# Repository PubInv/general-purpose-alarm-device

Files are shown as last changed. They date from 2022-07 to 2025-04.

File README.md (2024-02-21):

# General Purpose Alarm Device v2.0
We often acronymize this as  "GPAD" (prounced gee-pad).

DOI: [https://zenodo.org/records/10065096](https://zenodo.org/records/10065096)

## Abstract 
The General Purpose Alarm Device (GPAD) shines lights and makes loud noises to draw attention to a problem. It has a programmable 80 character display to provide textual info. A mute button toggles the sound on and off. Fundamentally, it is designed to act as a peripheral to a controlling computer or microcontroller. The controller may communicate over a USB (COM) connection or through a 5V SPI connection via an RJ12 cable. The GPAD is intended to be as general as possible, so that it can be used as an alarm for many engineering, scientific, and hobby machines or instruments. The device's original goal was to provide medical alarm capability to the PolyVent [5]open-source mechanical medical ventilator. The GPAD supports 5 alarm levels above “silent” of increasing urgency in terms of light, rhythm, and frequency. It is based on the Arduino Uno Atmega328 design and may similarly become extensible through headers and shields. It includes a printed wiring assembly, firmware for the GPAD peripheral, a simple documented API, and a 3D printable enclosure. The repo includes instructions for using a second GPAD as a controller.

The GPAD does not detect the conditions that need to be alarmed. It is a peripheral to a controlling host device, probably another microcontroller.
The controlling host will assert status through the GPAD to an end user.

## Demonstration Video
A demonstration of one use of the GPAD can be [seen here](https://youtu.be/F5cf5-Cmwu0).

# The Colaborative Open Development

Development of the GPAD is in collaboration with the [Sustainable Progress and Equality Collective
(SPEC)](https://www.specollective.org/#:~:text=The%20Sustainable%20Progress%20and%20Equality,be%20catalysts%20for%20positive%20change.) and other individual volunteers.

The GPAD is Certified Open Source Hardware by OSHWA. Our OSHWA UID is [US002352](https://certification.oshwa.org/us002352.html).

GPAD_OSHWA

GPAD in an Enclosure of Summer 2022
https://user-images.githubusercontent.com/5296671/203407648-e5b4894c-6909-4530-9af4-f5937bfeb0b8.JPG

KiCad Simulated GPAD Printed Circuit Assembly (Version 2)

**Top View**

**Bottom View.** 

The top view image shows some Artuino UNO connectors peeking out, but on the bottom view the connectors are not actually used.  The GPAD was designed so that it MIGHT become a shield to an UNO, but it can stand alone.

# Versions History
During the summer of 2022, Version 1 of the GPAD PCB was designed and several units were fabricated.
Some of these units were used as electrical engineering senior capstone projects of students at the
University of Oklahoma, located in Nornam Oklahoma, during the spring semester.
Two groups participated: one group developed a wireless interface and battery features, and
the other groups developed a voice playback feature.
These features are on the ESP32 branch, which as of August 2023, is not yet integrated.

## Version 2 PCB Features
As of March 2023, we have developed and built a version 2 PCB.  Fifteen printed wiring assemblies and five enclosures were fabricated largely by JLCPCB.
Some PCB components not available through JLCPCB were assembled by hand in Maryville, TN.
Details of the assembly and test procedure can be found through links in the README.md at:  [https://github.com/PubInv/general-purpose-alarm-device/tree/main/Hardware](https://github.com/PubInv/general-purpose-alarm-device/tree/main/Hardware)
**FIXES in Version 2**
Changes were made in version 2 to fix a few reworks to version 1 PCBs, which involved cutting traces and soldering wires.
The most noticable change was properly connecting the USB-UART chip to the micocontroller nRESET line
so that the devices can program themselves without the user having to press the reset button.
Another change was making the audio output a switch rather than a push-pull, which allows for an internally driven buzzer and greater volume.
We built buzzers with Digi-key part numbers 433-WST-1210T-ND and 102-CMI-1295-0585T-ND. Both are rated at 85 dB and 10cm.
The Rev2 can also drive the **VERY **loud Floyd Bell Inc buzzer 2339-TXC-86-515-Q-ND, rated at 103dB. However, we have not designed an enclosure for the "off board" mounting requirements of this device.
An additional Rev 2 feature is a silk screen on all of the "Arduino UNO" connectors, which look like pins for easy signal indentification.

## GPAD V2 Build Information
Below are files we used to build the V2 assemblies. The PCB with some SMT Assembly was from JCLPCB in China. Additional parts were ordered and hand soldered in the USA.

[Linkes to the schematic and PCB design found here](./Hardware/GeneralPurposeAlarmDevicePCB)
[Links to the exact Gerber files GerbersV120220804.zip](./Hardware/Manufacturing/GerbersV120220804.zip)
[Information on the V2 build of April 2023](/Hardware/Manufacturing)
[Manufacturing and Unit Test Documentation, PCB Version 2.0, 20230228](./Hardware/Documentation/ManufacturingUnitTestTroubleshootingRev2.md)
Details on how to assemble the Printed Wiring Assemblies as received from the JLCPCB version 2 PCBs of March 2023. Includes testing and troubleshooting notes.

## GPAD V1 Repository Tag
Tag to last commit before removing information of Version 1 PCB and PCBA
https://github.com/PubInv/general-purpose-alarm-device/releases/tag/BeforeRemovingV1Files

# Example Use Case, The Ventilator

The [Freespireco Project](https://github.com/PubInv/freespireco) is an attempt to build a
modular ecosystem of cooperating respiration devices.
Devices such as ventilators and oxygen concentrators need to have the ability to alert someone to dangerous conditions.
These alerts can be as simple and gentle as, "It is time for scheduled maintenance,"
to the far more agressive, "The hose connected to the patient is disconnected!"
The purpose of the alarm is to get the attention of nurses or doctors who can fix the problem.

See the PolyVent project on Gitlabs at: [https://gitlab.com/polyvent](https://gitlab.com/polyvent)
See the PolyVent controller at: [https://gitlab.com/polyvent/polyvent_control_module](https://gitlab.com/polyvent/polyvent_control_module)

# The Abstract Application Programmers Interface

GPAD offers a simple API for commanding the device to alarm.
We can imagine a system that supports five levels of alarm severity.
Additionally, an alarm condition normally has a short
message associated with it, such as "Hose disconnect", which
might be displayed on a small screen.

The initial version of this API is extraordinarily simple:
alarm at a level between zero and five, where zero means no alarm.
However, it is clear this API will have to evolve over time.
Issues such as when one alarm level supersedes another, when it is
acceptable to silence an alarm and for how long, etc., quickly complicate this function.

We hope that by clearly defining this version of API, we can make an evolving device of great
utility for a wide variety of purposes.

# Stand-alone or Sub-assembly

Our fully finished design includes a printed wiring assembly and an enclosure.
We freely provide all open source KiCad schematic printed circuit assembly files, so
that users can fabricate just the PCB while using an enclosure of their own design.
The enclosure is designed in the free open source program SCAD,
and we provide these files as well.
Users could fabricate this enclosure as is, or
develop a modified enclosure with their own features from the files provided.

# The Arduino UNO-Like Platform

The implementation is Arduino UNO-like.
We provide a USB interface to an ATmega328 controller for Arduino IDE compatibility, which supports a typical Arduino serial port interface for development and debugging.
Additionally, although the enclosure is not designed for them, we also provide an UNO footprint for shields. There are holes on the PCB where users can solder female Dupont headers and add UNO shields for feature enhancement and evaluation.
The enclosure design is open source so that interested persons
can add these applications according to their requirements.

# How is the alarm signal received?

The SPI Peripherial is a wired RJ12(6P6C) data connection from a host in an SPI controller, and the GPAD is an SPI Peripheral.  A data cable is wired pin 1 to pin 1 on the RJ12(6P6C) connectors. CAUTION: Telephone cables wire pin 1 to pin 6 and are not compatible.

# Summer 2023 Project Status

### Firmware
Demonstration of SPI controller and Peripheral for single byte transmission.

### Hardware
* PCB designed for a predominantly surface mount production. We used JLCPCB. Some had assembly parts not available through JLCPCB.
* An enclosure for the electronics which is designed for easy mounting (for example, with flanges for zip ties.)
* RJ12 Data Cable connection for signal (and optional power) between host and GPAD.
* Light alert by five, 5 mm white LEDs driven at about 20 mA.
* Acoustic alert by 5V buzzer, 85 dB at 10 cm. On board Piezo self-excited buzzer, or through a 0.1" two pin header for off board buzzer (103 dB).
* Text display with back lit, 20x4 character LCD.
* Single User Button labeled "MUTE" on enclosure.
* Recessed reset button.
* Power on status LED.
* USB port for Firmware development and low power operation.
* An I2C output for controller of devices TBD. Connection by locking JST connector: S04B-XASK-1(LF)(SN).
* Power from wall supply on barrel jack 2. 1mm at 9-12V <= 1000mA (or from host controlling device at 5V or 12V on the SPI interface).

### A Simulation with WokWi
Our project development benefited greatly from Wokwi.  Visit: [https://wokwi.com/](https://wokwi.com/)
In parallel with schematic capture, PCB design, and fabrication,
we have written both the diagram and two sketches that simulate our hardware in the "simulation" directory.
One of them,
which Rob wrote on Saturday, August 13th, implements [this rudimentary api](https://github.com/PubInv/general-alarm-device/tree/main/simulation/robSimulatinSat13), without supporting messages.
The other shows the use of the LCD.
These should be integrated together to create the initial firmware for the project.
Meanwhile, we can simulate the device successfully in WokWi.
While the Version 1 PCBs and PCAs were on order, Lee wrote and simulated factory test software on WokWi.
See project at: https://wokwi.com/projects/345960281987351124
Factory Test Simulation on Wokwi

Factory Test Simulation files can be found at: [./simulation/FactoryTest](./simulation/FactoryTest)
Although we eventually sent a Rev 1 GPAD to Oluseyi 'Seyi' Adeniyi (@NULLbodyHERE) made enhancements
to our factory test without even having hardware (we later sent him one), which he used to enhance
the sonic and light signalling.

# Possible Evolution Stages of the Project
Ideas from the cap stone projects:
1. Wifi interface and batter power
2. Audio voice playback for messages.

In each of these phases, we imagine extensions of the API.

# Volunteer Skills (and Skills Needed)

## Current Volunteers:

Project Lead, Product Definition:  Robert L. Read (@RobertLRead), founder of Public Invention.

Enclosure design, component procurement for rev1, project facilitator, initial board bring-up, board layout design contributor: Lawrence Kincheloe (@LokeMetaSmith) of Speccollective who is a computer scientist by training, and an electrical engineer as well as a hobby inventor by vocation.

Mentor and coach hardware, firmware: (Forrest) Lee Erickson @ForrestErickson, Physicist who pretends to be an electrical engineer, with experience in firmware development, Design for Manufacture, Design for Test and developer of Novel and Diverse Spelling.

Factory Test and API Firmware Contributor: Oluseyi 'Seyi' Adeniyi @NULLbodyHERE, Software Engineer, committed to pursuing diverse creative endeavors.

## Needed Volunteers

We need volunteer:
1. Arduino engineers who can both code and make very simple circuits.
2. Schematic capture and PCB layout designers.  We are using KICAD.
3. Mechanical engineers who can design sturdy enclosures that keep the system bright and loud.
4. Embedded firmware engineers who can design an effective, evolving API and the transport bindings that they require.
5. GUI experts who can address issues such as how to effectively alarm and silence device.
6. Marketers who can promote and evangelize the project.
7. A possible project manager who can organize volunteers and keep them enthused and motivated to move forward.

# The Potential for a Product

Like everything done by Public Invention, this is a fully open project that is
released under fully open hardware and software licenses.
However, unlike many of our projects, which are very "researchy", this project could
become a scalable product pretty easily.
One can imagine it being sold at Sparkfun, Adafruit, or DigiKey, if we do a good job.
Because it could be used for a wide variety of purposes by makers and could be sold with an enclosure at a price of perhaps <=$100USD
As an embedded sub assembly, the printed wiring assembly must be low cost with a material price of < $30USD

Potential uses as a product (by hobbyists) include:
1. Alarming a cat door, bird, or squirrel at feeder
2. Alarming when a visual signal, such as an animal moving in a game camera, is detected
3. Announcement of life-threatening conditions in medical devices
4. Overheating conditions in almost any device
...but the reader can probably imagine a great many more.

Public Invention does not wish to become a manufacturer; but we will impartially
support anyone who wants to take these designs and manufacture them, so long as they abide by the licenses.

# Modular Software Architecture

This is intended to be a long-term project that will evolve and potentially have many volunteers.
The basic software architecture is captured in this diagram:
GPAD Architecture (3)

# Our Simple API (Implemented!)

The simplest API is:
```
enum AlarmLevel { silent, informational, problem, warning, critical, panic };
int Alarm(AlarmLevel al);
```

The simplest binding for this, which could be used with SPI or a serial port, would simply be the character A followed by the character 0, 1, 2, 3, 4, or 5.
To test the alarm system of the serial port, you could simply type "A3" into the Arduino IDE serial monitor and send this to the GPAD, which you would expect to set off a moderate noise and flashing light.

A slight improvement on this is to specify a message. We have decided that messages should have 80 character, 32 character, and 16 character
versions, and the hardware device will do its best job rendering them in with available hardware:
```
enum AlarmLevel { silent, informational, problem, warning, critical, panic };
int Alarm(AlarmLevel al);
int Alarm80(AlarmLevel al,char* msg);
int Alarm32(AlarmLevel al,char* msg);
int Alarm16(AlarmLevel al,char* msg);
```
Additionally, it would be nice to have a way to interrogate the current alarm level:
```
AlarmLevel getAlarm(AlarmLevel al);
boolean isMuted();
```

## The Abstract API
The Abstract API is meant to work independent of specific hardware on
the GPAD. That is, it should be useful for hardware built by other teams
with significantly different decisions.

In this API, the message strings support only the most limited
sort of formatting: a linefeed character represents a line break.
Nonetheless, if linefeed characters are used, this will break lines
and of course limit the number of ACTUAL characters
that can be rendered, rather than the 60 that we can render if no
line breaks are used.

## The Hardware API

The Hardware API gives a caller complete access to all of the GPAD
hardware. For example, they could address each LED separately.
This is a lower priority. This API is not intended to be used by
medical devices because it is fragile with respect to improvements in
the hardware. Nonetheless, its availability makes the GPAD more useful
for a wider variety of purposes. For example, someone could program a
simple game with the GPAD.

## Separate transport protocols

In practice, the device needs three ways of invoking the API:
1. Through a human-typable string at the serial port,
1. Through a remote procedure call via the serial port, and
1. Through the SPI interface.

It is our intention to keep all of these mechanisms distinct from the
two APIs. There might even be additional transport protocols in the future,
such as a library that uses I2C ("I-squared C").

# Project Glossary
Some terms we use and how we have defined issues for Github.
[Glossary.md](Glossary.md)

# Building the Firmware

The firmware can be built with the standard Arduino IDE.  (Using 1.8.19 as of 20221208)
It requires libraries:
1. Wire.h
1. LiquidCrystal_I2C.h
1. DailyStruggleButton.h  (Installed with library manager and found at: https://github.com/cygig/DailyStruggleButton)

# Credits
The GPAD team was enabled by, and wishes to thank, the developers and maintainees of:
**GitHub** the project management features, issues, and project board were always useful when we used them.
**KiCAD** for the tools of schematic capture and PCB design
**OpenSCAD** for the tools in which the enclosure was designed.
**FreeCAD** for additional design of the hanging feature on the enclosure
**Wokwi** for the simulation tools for hardware and firmware.
Also, the inventors and developers of the **Arduino** ecology of tools and hardware, who have sparked so much good for so many.
**"The Ultimate Box Maker"** from http://heartygfx.blogspot.com/2016/01/the-ultimate-box-maker.html

# License

* [Firmware: Affero GPL 3.0](https://www.gnu.org/licenses/agpl-3.0.en.html#license-text)
* [CERN Open Hardware Licence Version 2 - Strongly Reciprocal](https://ohwr.org/cern_ohl_s_v2.txt)

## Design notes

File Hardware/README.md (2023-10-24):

# Hardware Folders
Folders for the hardware designed as GPAD (or related such as the PolyVent_SPI_Controler)

**Outline**
1. Documentation 
2. Enclosure
3. GeneralPurposeAlarmDevicePCB
4. Manufacturing
5. PolyVent_SPI_Controller

## Documentation

[Manufacturing Documentation for Version 2 PCB](./Documentation/ManufacturingUnitTestTroubleshootingRev2.md)
Details how to assemble the Printed Wiring Assemblies as received from JLCPCB version 2 PCBs of March 2023. Includes testing and troubleshooting notes.

## Enclosure
The Version 1 enclosure is mostly designed in OPEN SCAD  
Files to fabricate an enclosure are detailed in this document: [LINK](./Enclosure/README.md)

## GeneralPurposeAlarmDevicePCB
Kicanvas live view of current schematic and PCB is found at: [./GeneralPurposeAlarmDevicePCB](./GeneralPurposeAlarmDevicePCB)  

PDF, and therefore stale, schematic for Rev 2 PCB Assemblies is: [Schematic-GeneralPurposeAlarmDevicePCB-V2.2.pdf](/Hardware/GeneralPurposeAlarmDevicePCB/PDF/Schematic-GeneralPurposeAlarmDevicePCB-V2.2.pdf)

## Manufacturing
Includes the spread sheets for Bill of Materials (BOMs) to fabricate the GeneralPurposeAlarmDevicePCB.  
See the [Manufacturing README.md](./Manufacturing) for more information on the files there.

## PolyVent_SPI_Controller
Includes KiCad schematic and PCB files for an adapter PCB to fit into PolyVent Main Controller card cage and provide an SPI (and I2C) interface to other devices. The SPI interface is for the GPAD.
KiCad Schematic, PCB and bom documentation for ordering PCBs and PWAs in found in this folder.

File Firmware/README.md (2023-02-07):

# Firmware Folder

## These folders contain files as follows:

* __GPAD_API__ is the firmware which goes into the GPAD microcontroller.  The GPAD running this firmware is a Peripheral.  This firmware was developed in the Arduino IED.
* **GPAD_API_SPI_CONTROLLER** is the firmware which goes into an ESP32 or UNO to be a Controller to a GPAD. This firmware was developed in the Arduino IED.
* __GPAD_API_TEST__ is a test file and instructions for using RealTerm to be an endurance test of the GPAD serial port interface. It endlessly sends a simple set of commands to the GPAD which are in a simple text file.
* __GPAD_Factory_Test__ is .ino file to be loaded into the GPAD for factory testing and or troubleshooting. Was developed to test Version 1 PCBs and was developed on Wokwi. (Was fun to do!)
* __SPI_Controller_And_Peripherial__... is a ?link? to an external GitHub repository for some SPI communications proof of concept files 
* **Python_Serial**  is a program to facilitate testing from a command line.
* **pseudoSerialVent** is a simulated ventilator made in the Processing IDE with which to test the GPAD when loaded with firmware GPAD_API
* **toneSweep** a simple standalone program (Arduino sketch) developed for evaluation of piezo buzzers and speakers on the GPAD Peripherial. 

## Regression Test Documentation. 
* __GPAD_API_Regression_Test_Plan.md__ is an overall test plan, which describes how to use some of the folder and the files inside to regression test the GPAD_API https://github.com/PubInv/general-alarm-device/blob/main/Firmware/GPAD_API_Regression_Test_Plan.md
* The many test folder may contain specific instructions within their own README.md.

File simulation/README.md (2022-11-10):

# Simulation files for Wokwi simulations.

Folder FactoryTest has simulations approximating the factory test as of 20221019 but with added logic analyzer on the SPI bus and I2C bus.

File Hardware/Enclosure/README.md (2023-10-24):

# File Descriptions

## To build an enclosure print these six files.

1. [U_Box_V105_General_Alarm_Device_Backpanel.stl](U_Box_V105_General_Alarm_Device_Backpanel.stl)
2. [U_Box_V105_General_Alarm_Device_FrontPanel.stl](U_Box_V105_General_Alarm_Device_FrontPanel.stl)
3. [U_Box_V105_General_Alarm_Device_Top.stl](U_Box_V105_General_Alarm_Device_Top.stl)
4. [U_Box_V105_General_Alarm_Device_bottom.stl](U_Box_V105_General_Alarm_Device_bottom.stl)
5. [U_Box_V104_General_Alarm_Device_button.stl](U_Box_V104_General_Alarm_Device_button.stl)
6. [U_Box_V105_GPAD_LED_Standoff_single.stl](U_Box_V105_GPAD_LED_Standoff_single.stl)  Six of these for each assembly are required.
7. The file [BackPanel_Hanging-CompoundV2.stl](BackPanel_Hanging-CompoundV2.stl) is an alternate part with features to allow hanging the GPAD with tie wraps to a horizontal bar.

## Source files for generating STL files
[U_Box_V105_General_Alarm_Device.scad](U_Box_V105_General_Alarm_Device.scad)

To export the OpenSCAD, modify the scad file and toggle one of the STL elemnets on or off. 
```
/* [STL element to export] */
//Coque haut - Top shell
TShell          = 0;// [0:No, 1:Yes]
//Coque bas- Bottom shell
BShell          = 0;// [0:No, 1:Yes]
//Panneau avant - Front panel
FPanL           = 0;// [0:No, 1:Yes]
//Panneau arrière - Back panel  
BPanL           = 0;// [0:No, 1:Yes]
//Buttons
BButton         = 0;
//show pcb
PCB_View        = 0;
LED_Standoff    = 0;
LED_Standoff_Single    = 1; 
```

[BackPanel_Hanging.FCStd](Hardware/Enclosure/BackPanel_Hanging.FCStd)

### Folder(s)  
**Speaker2W**  
A tentative moving could speaker. About 1" diameter. This is a FreeCAD drawing made by measuring principle points of of a part with calipers.  Exported to PDF with mechanical dimensions. Exported to STEP and STL files.

### Credits
This OpenScad enclosure design based on "The Ultimate Box Maker" from http://heartygfx.blogspot.com/  
          -  FB Aka Heartman/Hearty 2016     -                   
          -   http://heartygfx.blogspot.com    -                  
          -       OpenScad Parametric Box      -                     
          -         CC BY-NC 3.0 License    
http://heartygfx.blogspot.com/2016/01/the-ultimate-box-maker.html
https://www.thingiverse.com/thing:1264391

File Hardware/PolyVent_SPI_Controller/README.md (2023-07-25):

# NOTES FOR THIS BRANCH ONLY

This is a branch with code changes useful for testing the with the PolyVent.

1. We discovered there is a BUILTIN LED load on the CLK line. This is a problem specific to the Arduino UNO
architecture which we (mostly) copied. It can be solved in rework be desoldering restor R103 on the GPAD (NOT the PolyVent SPI card.
2. The code TEST_POLYVENT_LINES is a very SIMPLE test script for transmitting a SINGLE BYTE. It can be loaded on to the PolyVent Architecture to remove all dependence on the (somewhat complicated) VentOS code and test the transmission of SPI through the PolyVent, back plane, PolyVent SPI card, and cable to the GPAD. It has a #define at line 41 for "USE_POLYVENT_ARCH". This code should be commented out if you are using the GPAD as the cotroller, and uncommented if you are using a PolyVent/ESP32 as a controller. 
3. I may have made other changes to the GPAD controller to send SPI bytes. This is messy and needs to be cleaned up and made selectable with a compile time switch or some other mechanism.
4. The GPAD_API code itself (the main code which drives the GPAD device) has been commented out so that it ONLY tests the SPI transmission.

# PolyVent SPI Controller Card
This project is a printed circuit assembly which fits in to the card rack of the Polyvent  
This assembly brings out an SPI (Serial Peripheral Interface) on an RJ12 connector compatible with the GPAD.  
This assembly brings also out an I2C (Inter Integrated Circuit interface) on a 4 pin JST connector similar to the GPAD.  

This is collaboration of Public Invention with the [Sustainable Progress and Equality Collective (SPEC)](https://www.specollective.org/#:~:text=The%20Sustainable%20Progress%20and%20Equality,be%20catalysts%20for%20positive%20change.)

## Schematic and PCB

<a href="SCH_PolyVent_SPI_Controller.pdf" >
Link to SCH
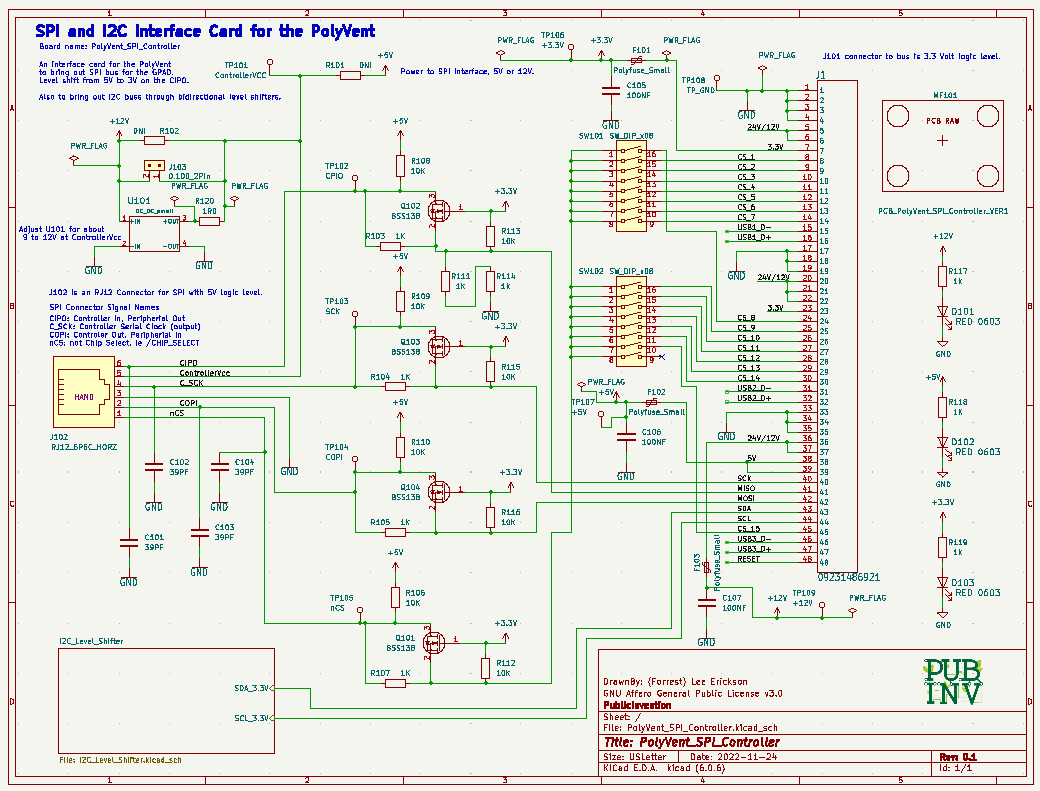
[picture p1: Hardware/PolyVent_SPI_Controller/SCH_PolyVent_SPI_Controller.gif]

</a>

<a href="PCB_PolyVent_SPI_Controller.pdf" >Link to PCB 
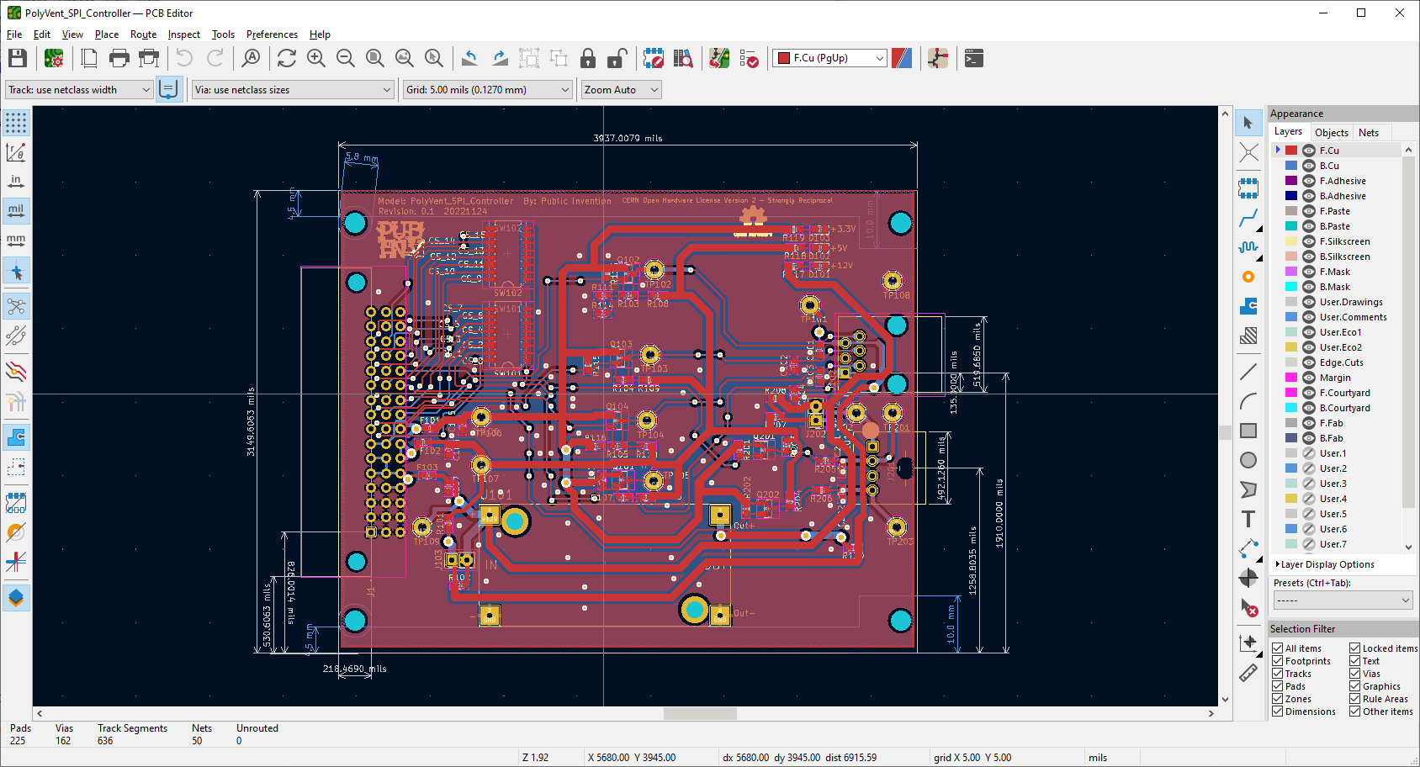
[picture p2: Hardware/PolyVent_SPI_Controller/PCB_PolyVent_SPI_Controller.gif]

</a>

<a href="PolyVent_SPI_Controller_PCBImage.png" >Link to 3D render screen capture  
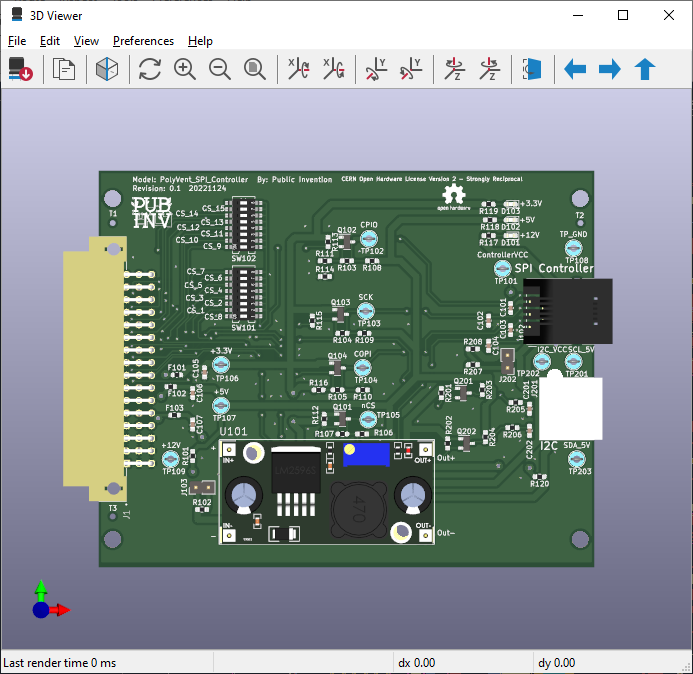
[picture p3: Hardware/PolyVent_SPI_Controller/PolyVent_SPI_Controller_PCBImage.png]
 </a>  

<a href="PolyVent_SPI_Controller.step" >Link to 3D step file.</a>

## Face Plate
The faceplate provides mechanical retention of the printed circuit assembly into the card cage and protection against ingress of dust and contaminations. 

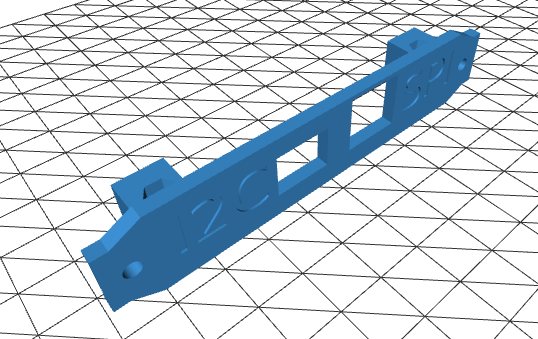
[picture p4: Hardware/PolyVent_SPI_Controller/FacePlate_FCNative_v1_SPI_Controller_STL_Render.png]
  
   
Render of the stl.  

<a href="FacePlate_FCNative_v1_SPI_Controller.pdf" >  

Link to Face Plate mechanical drawing PDF  
</a>  

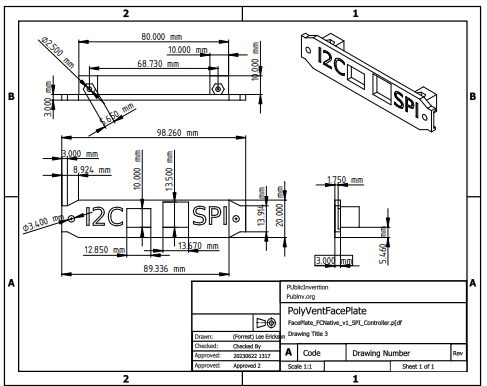
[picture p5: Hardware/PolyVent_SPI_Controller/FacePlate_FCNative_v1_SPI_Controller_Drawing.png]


## Theory of Operation
This PCB provides two interface methods for level shifting from the 3.3V ESP32 on the PolyVent to the 5V ATmega328 on the GPAD.
They are options achieved by populating different components in the schematic. As of 20221027 17:00 the schematic does not detail these stuffing options.

* One method of using FETs as described for example here: https://www.eeweb.com/level-shifting-techniques-in-i2c-bus-design/.  This may need some design work for selecting the pull up resistors as there are no pull ups on the GPAD interface.
* The second method is to simply connect the signals from the ESP32 output pins (SCL, COPI, nCS) directly to the ATmega328 inputs and rely on the 3.3 Volt logic high to be sufficient for the Atmega328 CMOS inputs. Full analyses is: The Atmega328 logic low input is specified at 0.3*Vcc and logic input hight is specified at 0.7*Vcc. So we have 1.5 and 3.5 per the specifications. 
  
So strictly by the specification the ESP output of even the full 3.3V does not guarentee logic high on the input of the ATmega328.  
The output from the ATmega328 is resistively divided through 1K into 2K to produce 5 * 2/3 = 3.3 Volts on the CIPO signal.

There are dip siwtches for choice of any of the nCS lines of the PolyVent brought out to become the nCS signal. **CAUTION:** Onle one switch should be in the closed position.

## Testing of Version 1 PWAs  
**Reference to Schematic here:**

 <a href = "SCH_PolyVent_SPI_Controller.pdf" >  Press to load PDF. </a>
 
**Reference the PCB layers here:**  

<a href = "PCB_PolyVent_SPI_Controller.pdf" >  Press to load PDF. </a>

1. Unboxing and Mechanical
First label each with a serial number.
The first test is mechanical fit. Even before solding any connector on, slide a board in to the card cage and look for problems. Make a photograph(s) please.
Then IIRC you have three connectors to solder on and test the fit again. Photo(s) again please.

2. Electrical test.
Prepare by identifying all of the currently used chip select lines in the PolyVent firmware or be refernce to the project documentation.
Identify an unused chip select line. Set the dip switches so that one and only one switch selecting chip select is closed. Confirm on and only one Chip Select is selected with a multi meter.

3. Light and play test.
Load some kind of file into the ESP which will use this chip select for an SPI interface.  Send out the SPI interface something that the GPAD is known to react to.

4. If you have the bandwidth to do so, put an oscilliscope on the SPI interface at the test points labled nCS, COPI, CIPO, SCK. Measure for signal high voltage, signal low voltage and time rise and time fall on each signal.  Trigger the oscilliscope on the falling edge of nCS. 

Report results here

## Volunteer Skills and Skills Needed
Project Lead, Product Definition, Robert L. Read, founder of Public Invention.  
Enclosure design, component procurement for rev1, project facilitator, initial board bring-up, board layout design contributor, Lawrence Kincheloe of Speccollective who is a computer scientist by training, and an electrical engineer as well as a hobby inventor by vocation. 
Mentor and coach hardware, firmware, (Forrest) Lee Erickson Physicist who pretends to be electrical engineer and firmware developer and provider of Novel and Diverse Spelling.
Volunteers needed and welcome for review of project documentation and project design.

# License

* Firmware: GLP 3
* Hardware CERN Open Hardware License Version 2 - Strongly Reciprocal

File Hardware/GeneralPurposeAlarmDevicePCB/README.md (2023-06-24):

#  View KiCad files with on line viewer 
View both cchematic and PCB files with Kicanvas
These are Rev 2 files.

##  View Schematics on Line

[Main Page GPAD Rev2](https://kicanvas.org/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)

[AlarmAudio.kicad_sch](https://kicanvas.org/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)  

[AlarmLights5.kicad_sch](https://kicanvas.org/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)  

[LCD And I2C Interface.kicad_sch](https://kicanvas.org/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)  

[SPI Peripherial.kicad_sch](https://kicanvas.org/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)  

[USB_UART.kicad_sch](https://kicanvas.org/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)  

##  View PCB on Line
[GPAD Rev 2 PCB](https://kicanvas.org/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)

##  SPI Peripherial Pins  
The connector is JR12 6P6C and pin 1 is on the left when the connector is held with the contact pins up and facing the observer.  
Note the GPAD is a 5V logic level peripheral device. Level shifters must be used when controlled by a 3.3V device.  
| **Pin#** 	| **Signal Name** 	| **Note** 	|
|---	|---	|---	|
| 1 	| nCS 	| Active low 	|
| 2 	| COPI 	| Input to GPAD 	|
| 3 	| GND 	| 	|
| 4 	| SCK 	| Input to GPAD 	|
| 5 	| ControllerVcc 	| 5 Volts, an optional way to put power into the GPAD 	|
| 6 	| CIPO 	| Output from GPAD, 5V. 	|

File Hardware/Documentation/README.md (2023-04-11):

[Manufacturing Documentation for Version 2 PCB](ManufacturingUnitTestTroubleshootingRev2.md)
Details how to assemble the Printed Wiring Assemblies as received from JLCPCB version 2 PCBs of March 2023. Includes testing and troubleshooting notes.

[Manufacturing Documentation for Version 1 PCB](ManufacturingUnitTestTroubleshooting.md)
Details how to assemble the Printed Wiring Assemblies as received from JLCPCB version 1 PCBs of August 2022. Includes details for PCB reworks to approximate Version 2 PCBs. Includes testing and troubleshooting notes.

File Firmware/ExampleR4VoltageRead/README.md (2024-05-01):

# Introduction: ExampleR4VoltageRead

This program exists to demonstrate using the GPAD from a simple
Arduino R4 via the SPI interface.

It reads a voltage from an analog input pin, and assumes that
as the voltage increases, the situation is becoming more dangerous
and requires more human attention. This is embodied by a simple
potentiometer, which can be turned by hand to demostrate the GPAD.

This code is very similar to the GPAD_API_SPI_CONTROLLER code.
That code, however, is used by this project to test a GPAD by
using a GPAD itself as a controller. Since most users are not
going to have two GPADs, showing how to use one from a simple,
cheap, widely avaialabe micrcontroller, such as an Arduino R4.

Note: This Arduion project copies some utility files into this
directory. These are:
1.   GPAD_ALARM_API_SPI.cpp
1.    GPAD_ALARM_API_SPI.h
1.    alarm_api.h
This is a code duplcation which is bad form; these should probably
be made into a separate repo so that these can included as a
separate libary. This is issue #263 in our repo,
[https://github.com/PubInv/general-purpose-alarm-device/issues/263](https://github.com/PubInv/general-purpose-alarm-device/issues/263)

# How it Works

This is roughly the simplest use of the GPAD that we can imagine.
This prgram is designed to work with a simple rotary potentiometer (10kohm)
(called a "pot").

Turning the pot with your hand changes the voltage.
The voltage is read on pin A0 of an Arduino R4.
We want to demonstrate running the GPAD through all of its alarm
levels, so we break the voltage range into levels.
We read the voltage level, and send an associated alarm level
to the GPAD. We add the voltage to the message sent as well,
to demonstrate the value of the built in LCD.

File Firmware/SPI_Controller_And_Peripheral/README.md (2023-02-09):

# SPI_Controller_And_Peripheral
A SPI Controller and Peripheral solution for Arduino UNO. Use two UNOs. One becomes the controller. One becomes the peripheral. 

SPI_CONTROLLER and SPI_PERIPHERAL
   From: https://circuitdigest.com/microcontroller-projects/arduino-spi-communication-tutorial
   Modified by Forrest Lee Erickson 20220523  
   Change to Controller/Peripheral terminology  
   Change variable names for start with lowercase. Constants to uper case.  
   Controller Arduino Code:     
   License: Dedicated to the Public Domain  
   Warranty: This program is designed to kill you and render the earth uninhabitable,
   however it is not guaranteed to do so.  
   20220524 Controller and Peripheral working.

## Hardware Notes, SPI Signal Names
>  SPI Line Pin in Arduino, IO type  
>  MOSI 11 or ICSP-4,  Output  
>  MISO 12 or ICSP-1, Input  
>  SCK 13 or ICSP-3, Output  
>  SS 10,  Output  

## Bus waveforms.  
### CH1 is SCK, CH2 is MISO, CH3 is MOSI, and CH4 is nCS
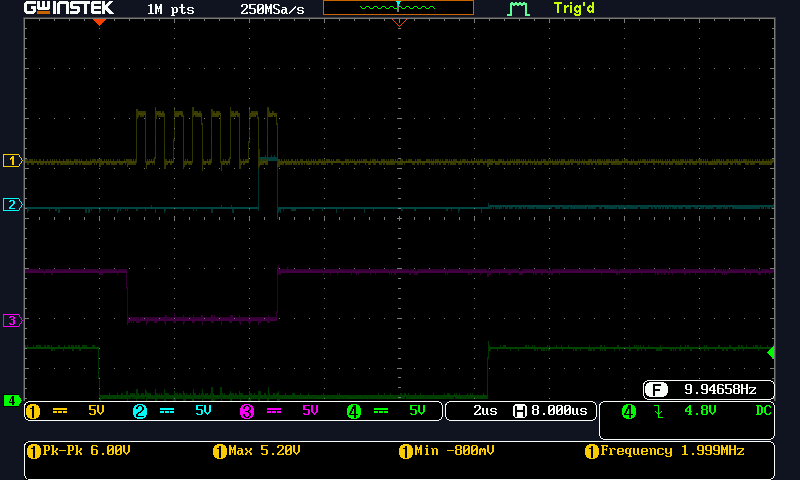
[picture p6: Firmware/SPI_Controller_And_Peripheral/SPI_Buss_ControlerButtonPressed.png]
SPI Bus ControlerButtonPressed
  
SPI Bus ControlerButtonPressed  
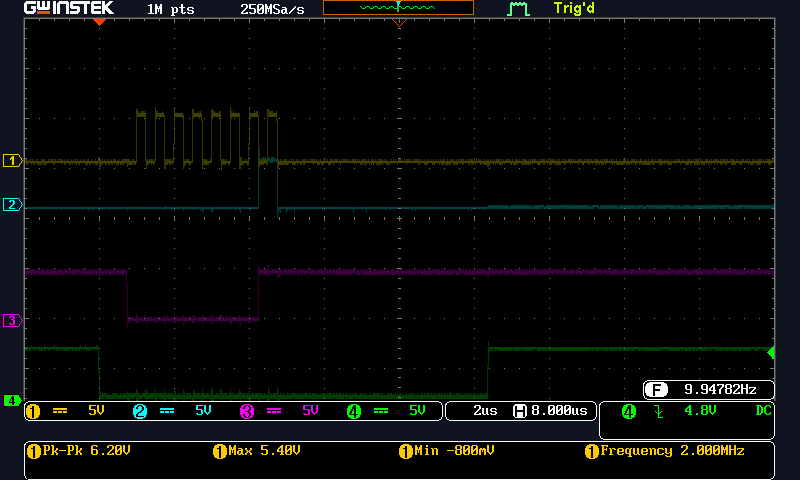
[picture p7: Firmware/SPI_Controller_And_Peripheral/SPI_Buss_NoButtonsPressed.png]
SPI_Buss_NoButtonsPressed
  
SPI_Bus_NoButtonsPressed  
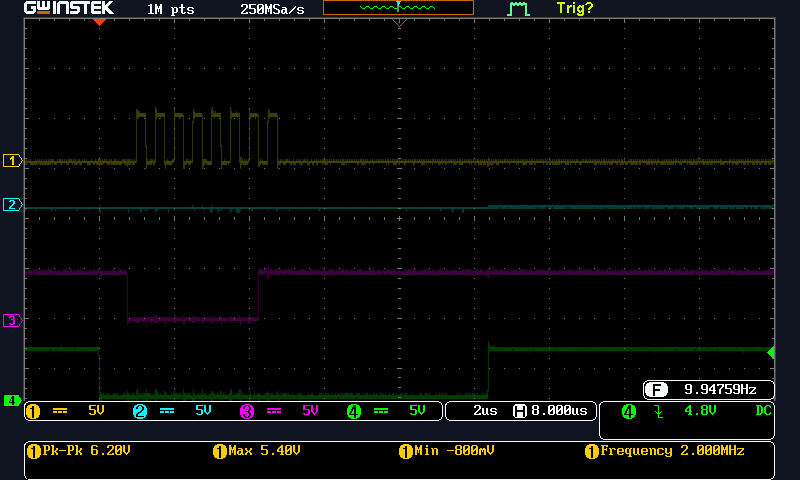
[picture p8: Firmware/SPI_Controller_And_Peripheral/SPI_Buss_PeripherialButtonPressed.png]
SPI_Buss_PeripherialButtonPressed
  
SPI_Bus_PeripherialButtonPressed

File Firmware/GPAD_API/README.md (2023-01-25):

# GPAD_API
Description of the GPAD API, the Application Programming Interface.
Version 0.07
Updated on Date: 20221104

This is the description of the API from the point of view of the firmware within the General Purpose Alarm Device, aka the GPAD.

As of Version 0.07, the interface is through the USB serial and SPI, both. 
The serial BAUD rate is fixed at 115200
Serial messages are terminated with a single **Line Feed**, here after LF character (aka '/n' or New Line, which is ASCII 0x0A or DEC 10).
The GPAD recognizes a limited set of commands.
Some commands are one character only.
Some commands are two characters followed by the LF.
Some commands take messages by concatenating a message of up to 80 additional ASCII characters.

## The SPI Interface

The SPI interface was added in version 0.07, and example code for it is available in the GPAD_API_SPI_CONTROLLER directory. Please see the [README](https://github.com/PubInv/general-alarm-device/tree/main/Firmware/GPAD_API_SPI_CONTROLLER) there for more information.

This SPI-implemented is implemented with two entrypoints, the single funcation ```alarm```, and the function ```alarm_vent``` which takes and event structure. These may contain a null-terminated message string of up to
80 characters.
```C++
enum AlarmLevel { silent, informational, problem, warning, critical, panic };
// const char *AlarmNames[] = { "OK   ","INFO.","PROB.","WARN ","CRIT.","PANIC" };
const int NUM_LEVELS = 6;

const int MAX_MSG_LEN = 80;
const int MAX_BUFFER_SIZE = MAX_MSG_LEN + 1;
typedef struct {
                uint8_t lvl;
                // we will use a null-terminated string!
                char msg[MAX_MSG_LEN+1];
               } AlarmEvent;

int alarm_event(AlarmEvent& event,Stream &serialport);
int alarm(AlarmLevel level,char *str,Stream &serialport);
```

It is our intention to create additional entry points in what we call the "robotic_api" which will eventually explose all of the GPAD hardware to control by SPI.

## Display Description
The LCD is organized as four rows of twenty characters.
The first row displays the alarm level by number and name { "OK   ","INFO.","PROB.","WARN ","CRIT.","PANIC" }
The remaining rows display the message sent by the controller with commands detailed below.

## Command List
Summary:
Commands fall into categories of **Alarm** and **Mute** and a **Help** message.
Optional arguments are in [].
Commands are case-insensitive. **A0** and **a0** are the same.

### Alarm Messages
These have the form of a letter "A" and a digit 0-5 inclusive followed optionally by text for the message.
* A0[message for alarm level 0]
* A1[message for alarm level 1]
* A2[message for alarm level 2]
* A3[message for alarm level 3]
* A4[message for alarm level 4]
* A5[message for alarm level 5]

In addition to Alarm messages writing text to the LCD, the illumination of the five LEDs is also managed.  A0 lights no LEDs, A1 through A5 light successively more LEDS vertically up the GPAD.
There are fixed buzzer tones associated with each alarm level, A0-A5
The "A0" alarm level turns off the LCD back light.  All other levels turn on the LCD back light.
Some example alarm messages:
> a0 pseudoSerialVent Testing.  All is OK.
> a0Uh, everything's under control. Situation normal.
> a5LUKE, WE'RE GONNA HAVE COMPANY!

### Mute Messages
The GPAD has a buzzer which can be silenced or Muted by the API. (The user can also press a button to manage the mute state).
Mute messages are single character messages terminated by LF.
* S
* U

The S command **Silences** or mutes the buzzer.
The U command **Unmutes** the buzzer.

### Help
* H

The **H** message is single character messages terminated by LF.
The device will return a message out the serial port with help instructions.
Screen shot of the help message.


## Command Response and Status
After the GPAD receives a command, it returns text string with a response indicating status.
Example of response to the command "a0 pseudoSerialVent Testing.  All is OK."


## GPAD MUTE BUTTON
The GPAD has a mute button. Pressing the button will toggle the buzzer on and off.
Text is returned out the serial port indicating the MUTE status as OFF or ON.


# Software Organization

The files in the directory are organized to create as much modularity as possible
to make future enhancement easy. At present these are:

> alarm_api.cpp
> alarm_api.h
> gpad_serial.cpp
> gpad_serial.h
> gpad_utility.cpp
> gpad_utility.h
> robot_api.cpp
> robot_api.h

The "alarm_api" module is main application programmers interface; it is a very
high-level abstract alarm module.
The "gpad_serial" module handles serial communication of the alarm commands.
The "gpad_utility" contains mostly debugging routines needed by all other modules.
The "robot_api" is a low-level api concerning the specific API. It is means to
change more rapidly as the hardware evolves than the "alarm_api".
At the time of this writing I will shortly add an "spi" module

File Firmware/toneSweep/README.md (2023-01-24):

# toneSweep  
An Arduino UNO sketch for GPAD to test the build in buzzer for response.
Measurements and Novel Spelling by Forrest Lee Erickson (Amused Scientist). 
Date: 20230110

**Analysis Summary**
The swept response of the piezo is easier to hear than the steady tones used in the GPAD API as of 202301 Version ?0.3?
The buzzer horn improves the response some what by perhaps 6 or more db when measuring SPL.
The buzzer horn may be improving Lee's hearing of the sweepTone by lowering the frequency of resonance some what and perhaps making more resonant.
The 4"x5.5" moving coil speaker is SIGNIFICANTLY LOUDER at over 80dB.  This is probably do to the significant response at lower frequency the speaker has.

## Setup and test description  
Firmware: toneSweep.ino 
Sweeps from a hard coded start frequency to a hard coded stop frequency in a set time.  
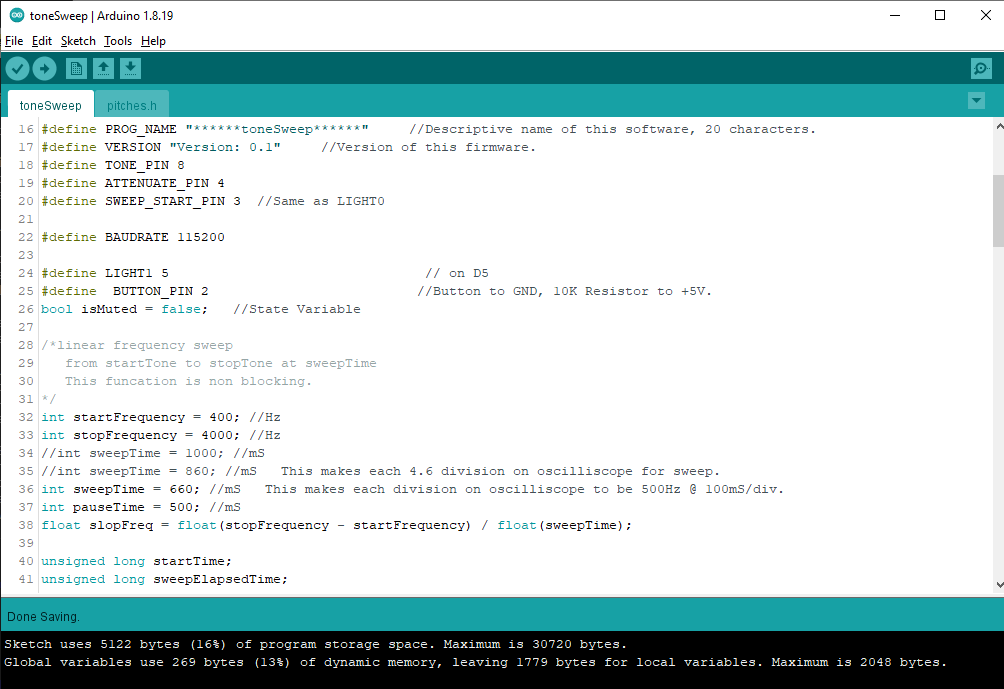
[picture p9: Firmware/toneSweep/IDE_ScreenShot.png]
 
The cell phone was hand held about one hand span (<9") above the piezo and about the same from the moving coil speaker. The moving coil speaker has no enclosure. It is a driver setting magnet down on the work bench.
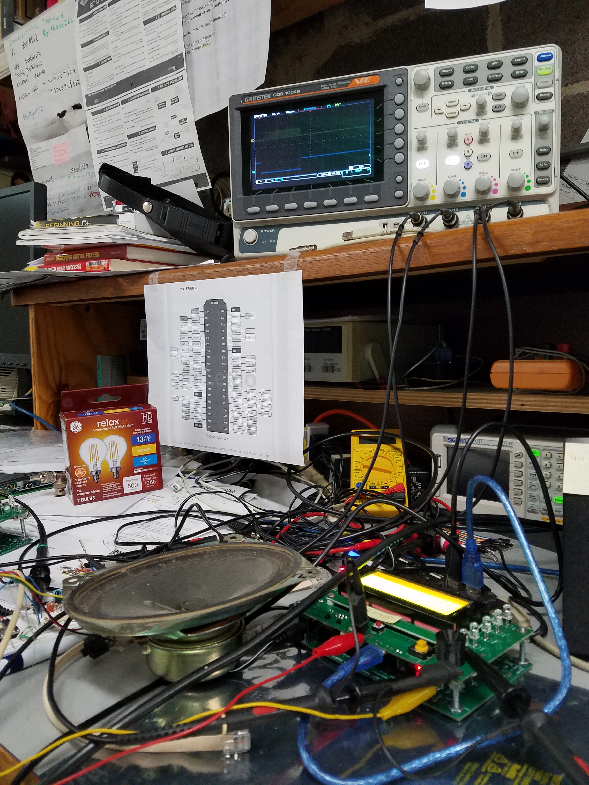
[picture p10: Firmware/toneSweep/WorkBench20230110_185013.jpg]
    
[Work bench big image LINK ](WorkBench20230110_185013.jpg)

## Oscilloscope Results 
Observe the response on an oscilloscope and notice there is a perturbation in the envelope of the drive voltage.
The blue signal goes low when sweep starts at 400 Hz and goes high at 4000Hz.
Test made without and with the buzzer horn.

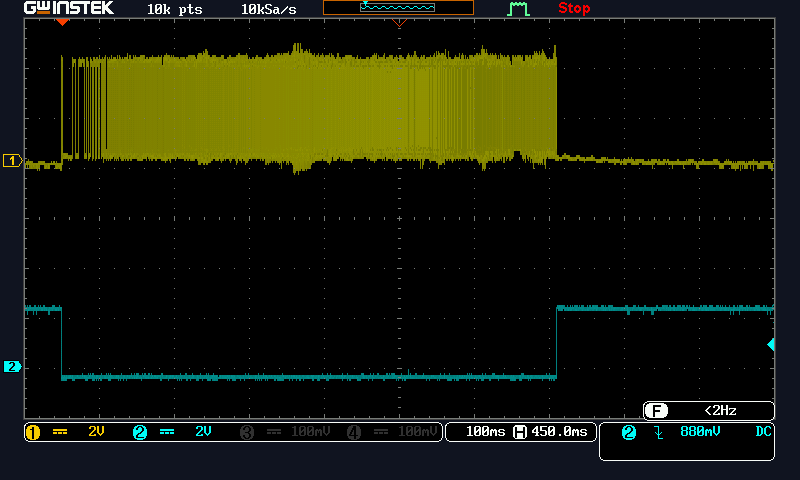
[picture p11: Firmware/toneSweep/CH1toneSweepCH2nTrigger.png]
    
  
*Without horn.*   

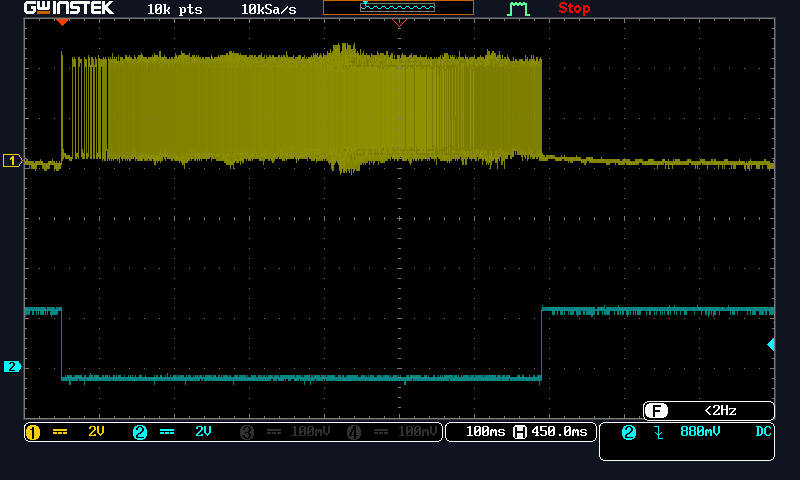
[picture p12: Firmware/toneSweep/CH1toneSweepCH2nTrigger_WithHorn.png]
     

*With horn.*  

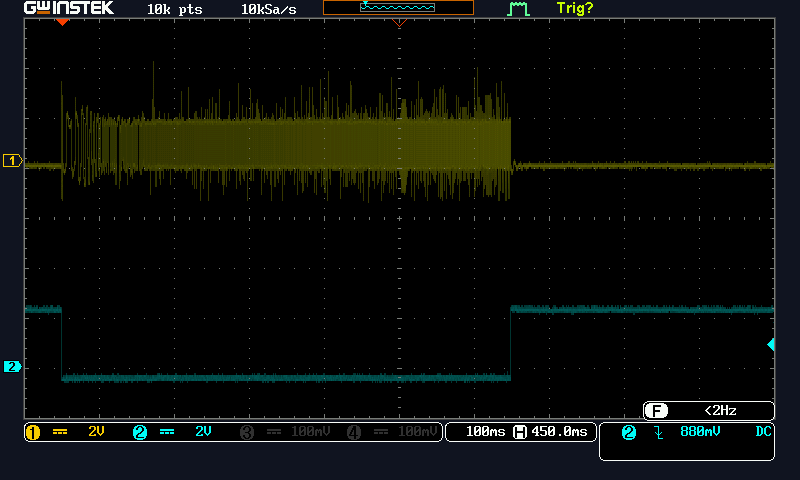
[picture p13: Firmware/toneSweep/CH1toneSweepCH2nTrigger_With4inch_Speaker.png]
     

*4x5.5 inch moving coil speaker.* 

**Speculative Analysis Oscilloscope Results** 
Resonance possible at about 2.6 to 2.75 KHz.  Another at 3.6 to 3.7 Hz.
This is just a guess at resonance. A better test might be to measure with a microphone but of course a microphone's response will then become a factor in the results.

## Cell Phone Sound Meter and Analyzer 
On each image the left "half" of the data is without buzzer horn and to the right is with buzzer horn. 
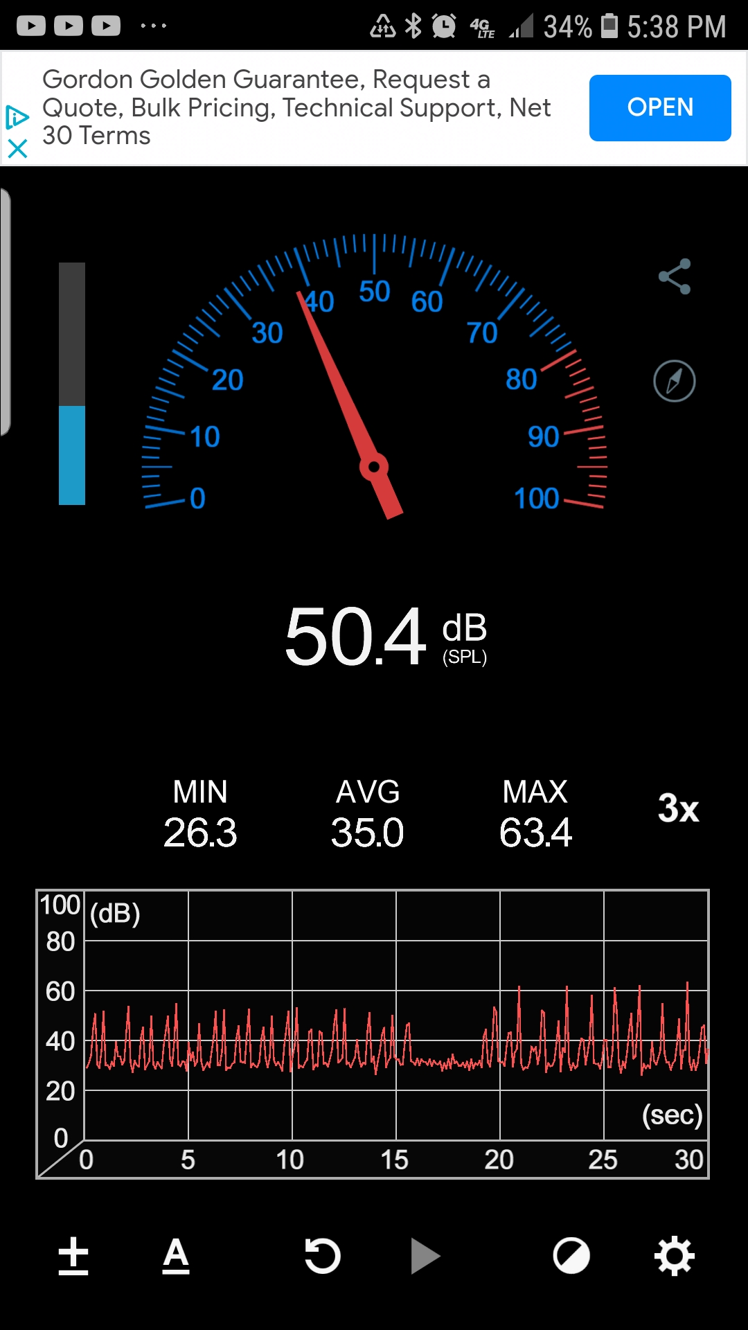
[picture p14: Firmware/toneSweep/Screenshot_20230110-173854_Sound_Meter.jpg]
 
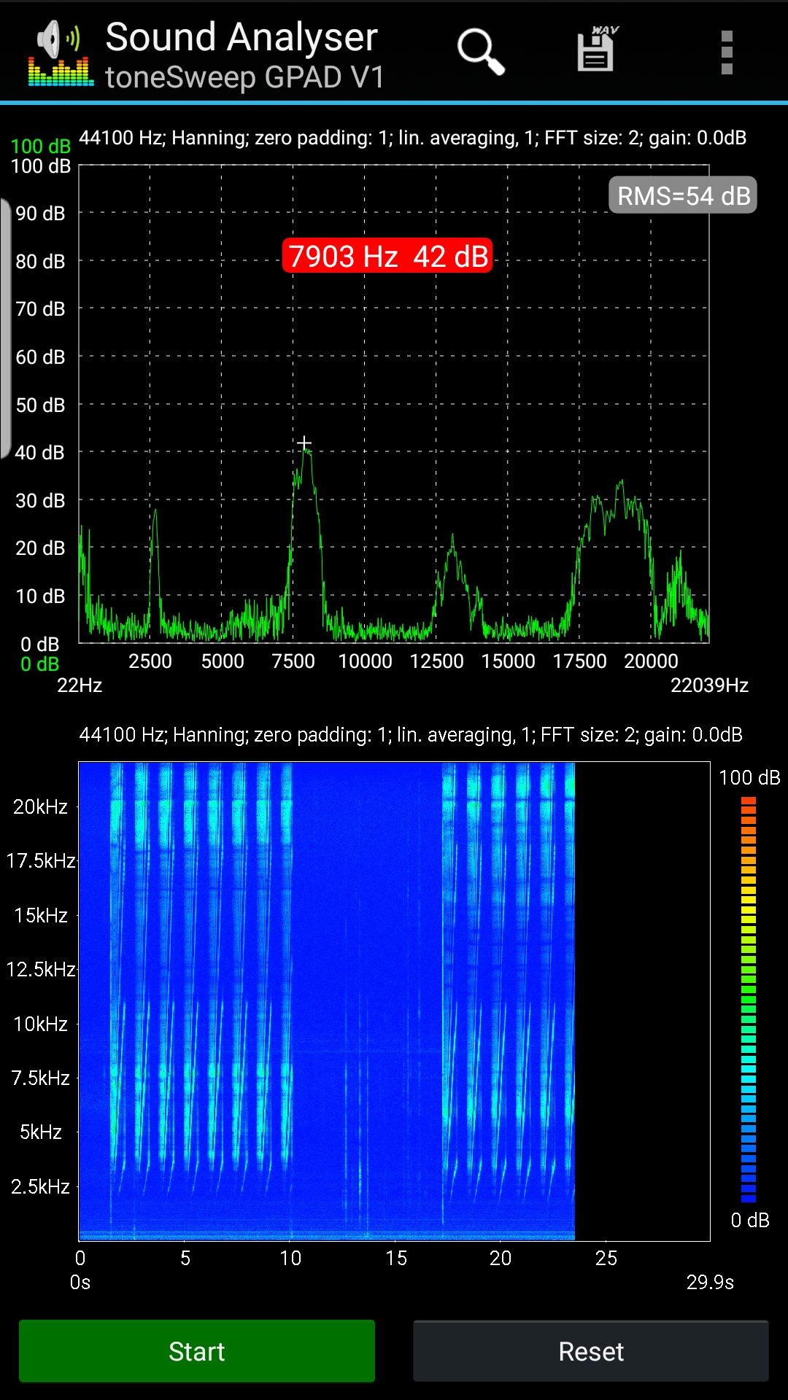
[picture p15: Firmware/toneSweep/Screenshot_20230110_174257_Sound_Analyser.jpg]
  

Additional and restarted tests with the 4x5.5 Inch moving coil speaker. 
The Sound Analyser right most ?25%? or so of the display is with the speaker.  

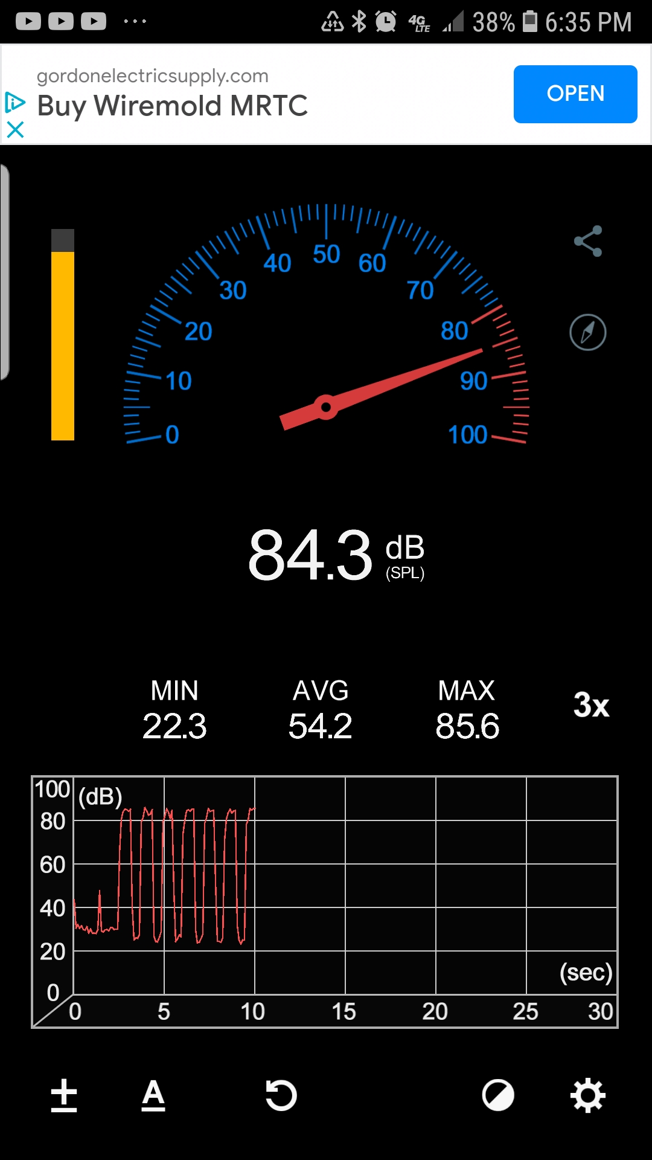
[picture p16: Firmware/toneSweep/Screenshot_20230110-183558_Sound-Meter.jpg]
  
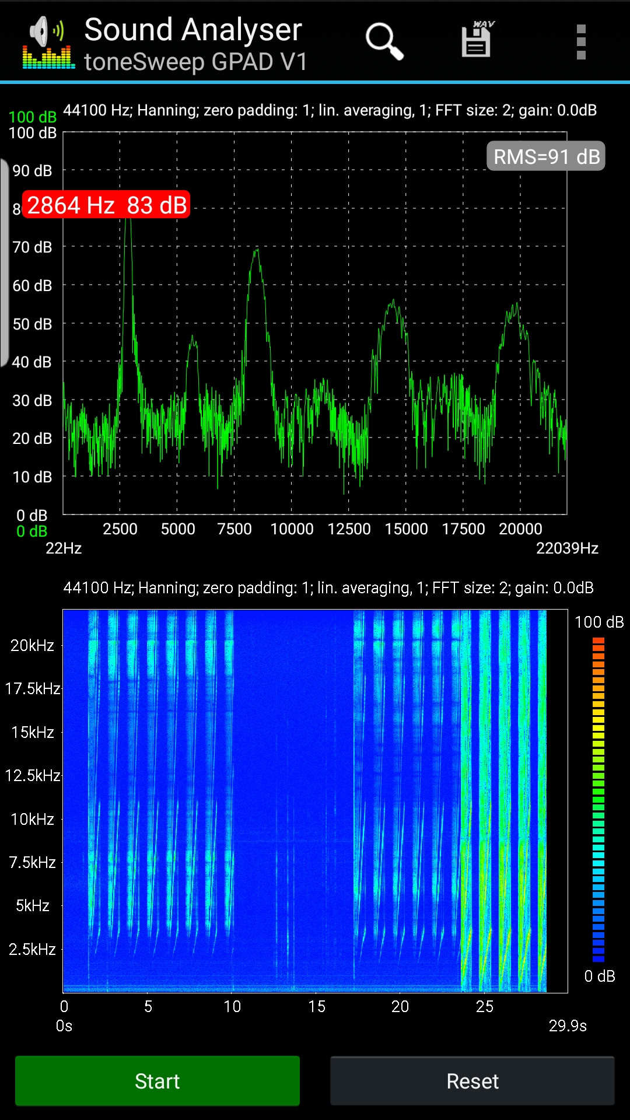
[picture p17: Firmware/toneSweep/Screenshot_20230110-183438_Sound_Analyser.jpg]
  

**Speculative Analysis Sound Meter & Analyser Results**  
There is somewhat higher peaks seen on the Sound Meter with the Horn.
The Sound Analyser shows the odd harmonics are present as to be expected with the square wave drive into the piezo transducer from the Arduino Tone function.

## Notes on Instruments.
1. Oscilloscope is GWInstek GDS-1054 using Open Wave software on Windows 10 PC for waveform capture.
2. Android application: SoundAnalyser V4.2 by Droid Dev February 2017
3. Android application: Sound Meter by Abc Apps.

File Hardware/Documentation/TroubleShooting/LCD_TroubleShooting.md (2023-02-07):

# LCD Troubleshooting
Ideas for troubleshooting the LCD on the GPAD. These notes were made when only version 1 PCB marked Prototype#1 20220726 existed.

## FIRST THING 
Maybe it is a user error. Check that the contrast potentiometer has not been changed. 
The "Vo" voltage at the LCD should be about 2.7 Volts with respect to ground.  

**Screen shot showing the net (PCB tracd) with the contrast voltage Vo.**
  
If that does not fix it, then it is time for more elaborate troubleshooting.

## Capture The Failure In An Issue
If you have a failed or suspected failed display of characters or back light on the GPAD LCD please make an issue describing the failure. See Issue #196 for an example of how to capture information about the LCD failure.

## Testing With **Factory Test** Firmware
Check for the factory test firmware (https://github.com/PubInv/general-alarm-device/blob/main/Firmware/GPAD_Factory_Test/GPAD_Factory_Test.ino

Load the firmware into the DUT (Device Under Test)
Open the Arduino IDE serial monitor at 115200 baud.

The factory test firmware should report success finding the LCD on the assigned address (For Version 1 assemblies that address is 0x38)
Screen show showing normal test for LCD on I2C address


Here is a screen show where the I2C communication was blocked by holding the SCL line to ground at J105 simulating a hardware failure on SCL.


Note the Factory test firmware (Version 1.30) does not return a message saying it found 0x38 and it does not go on to the rest of the test.
The same failure and behavior of the firmware occurs if SDA is shorted to ground.

If the short is cleared then the factory test firmware continues the normal bootup.

## Testing With Multimeter
The Version Prototype#1 20220726 PCB has an incorrect footprint on U301 making soldering difficult and perhaps prone to failure. 
Use a multimeter to test from the U301 pins right at the package out to traces so that you are measuring through the solder connections to each pin.
Note that many pins go to the 16 pins inline connecting to the LCD. Other pins go to the SCL and SDA lines which are easy to access on the Arduino UNO like shield connector at the pins near U301.  
Pins 1, 2 and 3 are set high or low with resistors and when power is applied these pins should still measure at ground or very close. This is for the GPAD set for LCD at address 0x38 all three should be low. 

**Schematic of the connections at U301.**


**Screen shot of U301 for traces for Version Prototype#1 20220726 PCB**


Version 2 PCB will fix the footprint to wider. Here are the traces on the proposed Version 2 PCB
**Screen shot of the U301 traces for Version 2 PCB.**


## Other Failures.
The back light should light by default. Remove all power (all connections) to the DUT.  Press and hold the reset button and apply power while continuing to hold the reset button.  The back light should come on.
If not trouble shoot the circuit around Q301.  If the uController is held in reset there is no command sent to U301 and so its pins are high impedance and R311 will pull the gate of Q301 high turnning it on. When on, Q301 drain will go to low voltage which will turn on the back light.



## Record Results
When you find and clear a problem make sure to document the problem found and the fix on the issue for the device serial number.

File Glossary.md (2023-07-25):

# Project Glossary and Organizational Overview

## Some Terms

API: Application Programing Interface. A programing library with a defined set of commands.  
Firmware: The code which is flashed into a microcontroller.  
GPAD: The General Purpouse Alarm Device  
SPI: Serial Peripherial Interface  
SPI Controller:  What was formerly called and SPI Master. A device to which the GPAD is a peripherial.  
SPI Peripherial: What was formerly called and SPI Slave. The GPAD device.  
Software:  Often, code running on a PC.  
Source Code: The files which when compilted become the Firmware for flahsing into a microcontroller.  
Version:  A configuration of the project, defined by a group of files for hardware and firmware.  

## Github Issue Labels used
| Label Name  | Short Description  | Detailed Description  |
|---|---|---|
| bug  | Something isn't working  | |
|  documentation | Improvements or additions to documentation | |
|  duplicate |  This issue or pull request already exists | |
|  enhancement |  New feature or request | |
| firmware  |  For issues related to software running on the microcontroller | |
| good first  | Good for newcomers | |
| Hardware | Schematic and PCB and Enclosure | |
| help wanted | Extra attention is needed | |
| question | Further information is requested | |
| research | Research products or ideas | |
| wontfix | This will not be worked on | |

# License

* [Firmware: Affero GPL 3.0](https://www.gnu.org/licenses/agpl-3.0.en.html#license-text)
* [CERN Open Hardware Licence Version 2 - Strongly Reciprocal](https://ohwr.org/cern_ohl_s_v2.txt)

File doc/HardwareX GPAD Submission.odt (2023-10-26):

Article title

A General Purpose Alarm Device (GPAD)

Authors

Robert L. Read*, Lawrence Kincheloe, Forrest Lee Erickson

Affiliations

Robert L. Read Lawrence R. Kincheloe III Forrest Lee Erickson

Public Invention SPEC & Public Invention Public Invention

1709 Norris Dr. 3217 Brush Creek Road 1709 Norris Dr.

Austin, TX, 78704 Oklahoma City, OK 73120 Austin, TX, 78704

Corresponding author’s email address and Twitter handle

read.robert@pubinv.org

twitter: @robertleeread

Abstract

The General Purpose Alarm Device (GPAD) shines lights and makes loud noises to draw the attention of a human being to a problem. It has a programmable 80 character display to provide textual info. A mute button toggles the sound on and off. Fundamentally it is designed to act as a peripheral to a controlling computer or microcontroller. The controller may communicate over a USB (COM) connection or through a 5V SPI connection via an RJ12 cable. The GPAD is intended to be as general as possible, so that it can be used to alarm many engineering, scientific, and hobby machines, instruments, and situations. The original driving use case is to provide medical alarm capability to the PolyVent [5]open-source mechanical medical ventilator. The GPAD supports 5 alarm levels above “silent” of increasing urgency in terms of light, rhythm, and frequency. It is based on the Arduino Uno Atmega328 design and potentially extensible the same way an Uno is, through headers and shields. It includes the printed wiring assembly, firmware for the GPAD peripheral, a simple documented API and a 3D printable enclosure. The repo includes instructions for using a second GPAD as a controller.

Keywords

alarms, arduino, UNO, SPI, medical alarms, monitoring

Specifications table

Hardware name | General Purpose Alarm Device (GPAD) v2.0
Subject area | General
Hardware type | Other: general alarms for digitally detectable alert conditions
Closest commercial analog | No known commercial analog is available.
Open source license | CERN Open Hardware Licence Version 2 - Strongly Reciprocal
Cost of hardware | $100.00
Source file repository | https://doi.org/10.5281/zenodo.10038777
OSHWA certification UID (OPTIONAL) | US002352

1. Hardware in context

We are not aware of any alarm device that has the programmable features of the GPAD. Electronic component firms such as Mouser and Digikey sell buzzers, sirens, and loudspeakers which can make noise; they sell lights that can represent an alarm condition; they sell proprietary alarm devices that are tired to special purposes (such as a smoke alarm), but we know of know digitally controllable system that combines these features. The Adafruit Towerlight [6], an example of a “stacklight”, but it does not seem to have a digital interface, and has no text output capability, and no abstract API. Mucco makes a complete line [5] of line of integrated warning horns and stack lights, but they appear to have no digital interface, no text, and no alarm levels; they are simply on or off. Although we believe a GPAD is a widely usable device, its use is of course confined to manufacturers, makers, or engineers who are capable of programming it, which may preclude the market volume associated with consumer devices.

The digital controllers for 3D printers can often make a beep, and have a digital display, which is sometimes backlit. This has some of the features of the GPAD, but is not as bright or as loud, nor programmed for this purpose as conveniently. A cheap example is the HiLetGo (https://www.amazon.com/HiLetgo-Printer-Controller-Display-Arduino/dp/B07X378P8X?hvadid=642177704150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)3-01-0889 (https://www.amazon.com/HiLetgo-Printer-Controller-Display-Arduino/dp/B07X378P8X?hvadid=642177704150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) [7].

2. Hardware description

We have designed a printed wiring assembly and an enclosure, derived from the parametric OpenSCAD project “The Ultimate box maker”[ 8]. The enclosure is approximately 160mm x 110mm x 50mm (6”x4.25”x1.75”) The assembly weighs 232 grams (exclusive of any power supply).

The device has a 20x4 character display (English characters), five bright white programmable LEDs, a programmable buzzer, a “Mute” button which silences the buzzer and a non programmable power indicator LED. The enclosure hangs by (for example) tie wraps from a rail for vertical display or can rest on a horizontal surface. Typical signal connection is by an RJ12 data cable. Power is by an external wall supply with a 2.1mm barrel jack power connector at 9-12V at <1000 mA.

The GPAD integrates several features hobbyists find useful in one device. Although you can purchase 20x4 displays with parallel or I2C interfaces it is the integration in one PCB and enclosure of all of the features which our device adds to make this tethered device integrate into a system easily.

The GPAD hardware features the following:

- Five bright LEDs to visually indicate alerts.
- A buzzer to indicate urgent attention is required.
- A button for minimum user feedback and to mute alerts.
- A 20x4 character display to provide detailed information to the user.
- An enclosure that can be vertically mounted by hanging, for example with wire ties.

Scientific experiments and laboratory equipment often monitor something over time whose condition can reach a state that requires human attention. The GPAD can thus be useful in the field or laboratory for:

- Alerting to conditions which may ruin the experiment if not corrected,
- Alerting to the very conditions sought by the experimenter and therefore demanding attention.
- Indicating potential failure of the equipment or the need for maintenance, such as low battery charge, over-temperature, over-pressure, etc.

The GPAD is designed to be loosely integrated with new devices. At the cost of modifying the enclosure, a researcher may integrate the GPAD into their own equipment.

3. Design files summary

Design file name | File type | Open source license | Location of the file
Firmware | A folder with source files. A README.md there describes the various source files | Firmware: Affero GPL 3.0 | https://github.com/PubInv/general-purpose-alarm-device/tree/main/Firmware
Simulation | Wokwi, simulations for Factory Test and other development efforts. | Firmware: Affero GPL 3.0 | https://github.com/PubInv/general-purpose-alarm-device/tree/main/simulation
Hardware | Folder holding a README describing the subfolders to follow. | CERN Open Hardware Licence Version 2 - Strongly Reciprocal | https://github.com/PubInv/general-purpose-alarm-device/tree/main/Hardware
GeneralPurposeAlarmDevicePCB | KiCad schematic and PCB files | CERN Open Hardware Licence Version 2 - Strongly Reciprocal | https://github.com/PubInv/general-purpose-alarm-device/tree/main/Hardware/GeneralPurposeAlarmDevicePCB
Enclosure | OpenSCAD and FreeCAD source files, STL and STEP files for the enclosure | CERN Open Hardware Licence Version 2 - Strongly Reciprocal | https://github.com/PubInv/general-purpose-alarm-device/tree/main/Hardware/Enclosure
Manufacturing | Bill of materials, Gerber files and description records of parts ordered for the builds. | CERN Open Hardware Licence Version 2 - Strongly Reciprocal | https://github.com/PubInv/general-purpose-alarm-device/tree/main/Hardware/Manufacturing
Manufacturing and Unit Test Documentation | Assembly instructions and notes | CERN Open Hardware Licence Version 2 - Strongly Reciprocal | https://github.com/PubInv/general-purpose-alarm-device/blob/main/Hardware/Documentation/ManufacturingUnitTestTroubleshootingRev2.md

4. Bill of materials summary

The spread sheet used to receive the KiCad generated BOM/PARTS LIST and to transform it into the files necessary for ordering PCB assemblies from JLCPCB is found at:

https://github.com/PubInv/general-purpose-alarm-device/blob/main/Hardware/GeneralPurposeAlarmDevicePCB/GPAD_V2_BOM.xls

Instructions are built into the spreadsheet for its use. JLCPCB built the raw PCB and did SMT assembly and some through hole assembly. The balance of the through hole assembly was done by Public Invention volunteers.

Designator | Component | Number | Cost per unit -currency | Total cost - currency | Source of materials | Material type
Enclosure LED Standoff | U_Box_V105_GPAD_LED_Standoff_single.stl | 6 | $1.01 | $1.01 | Fabricated by JLCPCB | 321PA-F NYLON
Enclosure Frontpanel | U_Box_V105_General_Alarm_Device_FrontPanel.stl | 1 | $3.05 | $3.05 | Fabricated by JLCPCB | 321PA-F NYLON
Enclosure Top | U_Box_V105_General_Alarm_Device_Top.stl | 1 | $12.4840 | $12.48 | Fabricated by JLCPCB | 321PA-F NYLON
Enclosure Bottom | U_Box_V105_General_Alarm_Device_bottom.stl | 1 | $13.00 | $13.00 | Fabricated by JLCPCB | 321PA-F NYLON
Enclosure Button | U_Box_V104_General_Alarm_Device_button.stl | 1 | $1.00 | $1.00 | Fabricated by JLCPCB | 321PA-F NYLON
Enclosure Backpanel | U_Box_V105_General_Alarm_Device_Backpanel.stl | 1 NOTE use of this is exclusive of the BackPanel Hanging Compound | $3.34 | $3.34 | Fabricated by JLCPCB | 321PA-F NYLON
Enclosure BackPanel_Hanging | BackPanel_Hanging-CompoundV2.stl | 1 NOTE use of this is exclusive of the BackPanel | $5.90 | $5.90 | Fabricated by JLCPCB | 321PA-F NYLON
Enclosure Screws PCB mounting | Choose to fit the enclosure as fabricated | 5 | $0.10 | $0.50 | Used #6 sheet metal screws 3/8” long | Steel
Enclosure Screws, | Choose to fit the enclosure as fabricated | 4 | $0.10 | $0.40 | | Steel
PCB Assembly exclusive of through hole components | BOM_JLCPCB_20230228Modified.xls | 1 | $13.86 | $13.86 | Fabricated by JLCPCB | GeneralPurposeAlarmDevicePCB-Placement20230228Modified.xls
U302 | LCD Display | 1 | $4.99 | $4.99 | https://www.aliexpress.com/item/3256803213374992.html | 3256 Display Assembly
Nylon spacers | Spacer_0.0182x0.125 inch | 4 | $0.13 | $0.52 | McMasterCarr | 94639a702
Screw | 4-40x 3/8” | 4 | $0.12 | $0.48 | Digikey | 36-9901-ND
Nut | Nut_4-40_3/16 | 4 | $0.10 | $0.40 | Digikey | 36-4694-ND
S101 | SWITCH_TACTILE_SPST-NO_0.05A_24V | 1 | $0.13 | $0.13 | Digikey | 450-1804-ND
S601 | SWITCH_TACTILE_12mmx12mm_SPST-NO_0.05A_24V | 1 | $0.55 | $0.55 | Digikey | SW414-ND
LED White | LED_T1.75_CLEAR_WHITE | 6 | $0.65 | $3.90 | Digikey | 160-1772-ND
LED Red | LED_T1.75_CLEAR_RED | 1 | $0.36 | $0.36 | Digikey | 160-1682-ND
RV301 | POT 0.375 10K | 1 | $1.61 | $1.61 | Digikey | 3386P-103LF-ND
9-12V wall power supply | Example Jameco.com 9V 200mA | 1 | $6.95 | $6.95 | Jameco.com | 100845

These parts sum to $74.43. The printed wiring assemblies were ordered from JLCPCB using two files:

- https://github.com/PubInv/general-purpose-alarm-device/blob/main/Hardware/Manufacturing/BOM_JLCPCB_20230228Modified.xls
- https://github.com/PubInv/general-purpose-alarm-device/blob/main/Hardware/Manufacturing/GeneralPurposeAlarmDevicePCB-Placement20230228Modified.xls
6. Build instructions

Detailed instructions for the balance of manufacturing on the assemblies received from JLCPCB is in a markdown document, “Manufacturing and Unit Test Documentation, PCB Version 2.0, 20230228” found at:

https://github.com/PubInv/general-purpose-alarm-device/blob/main/Hardware/Documentation/ManufacturingUnitTestTroubleshootingRev2.md

The time to build assemblies was capture in a Github Issue.

See Github Issue #229: The labor to assemble the printed circuit assembly is approximately 40 minutes per unit.

Manufacturing and Unit Test Documentation

PCB Version 2.0

February 28, 2023

This document provides instructions for manufacturing and unit testing of PCB Version 2.0.

1. Manufacturing Instructions

The following steps should be followed to manufacture PCB Version 2.0:

1. Order the required materials from a reputable supplier.
2. Prepare the PCB design for manufacturing.
3. Fabricate the PCB.
4. Assemble the components on the PCB.
5. Test the PCB.

2. Unit Test Instructions

The following steps should be followed to unit test PCB Version 2.0:

1. Connect the PCB to a power supply.
2. Verify that the power supply is providing the correct voltage and current.
3. Inspect the PCB for any visual defects.
4. Test each component on the PCB.
5. Verify that the PCB is functioning correctly.

3. References

1. PCB Design Specification
2. Component Datasheets
3. Test Plan

The following notes were made during the assembly of the JLCPCB order of approximately March 2023. These units will be assigned serial numbers 16 through 30.

Sections below

- Manufacturing test procedure for every unit -Assembly Notes and Tips - Unit (Design) verification tests on some units - Configuration Version 1 Assemblies
- Troubleshooting procedures

Manufacturing test procedure for every unit

Tools Required

- Solder station with appropriate ventilation
- 3/16 Nut Driver
- Number 1 philips screw driver
- Diagonal or other flush cutting hand tool for lead trimming.
- Assembly fixture, detailed below.

Procedure

1. Assemble the unit according to the assembly instructions.
2. Perform the manufacturing test procedure listed below.
3. If the unit passes all tests, it is ready to be shipped.

Manufacturing test procedure

1. Verify that all components are present and correct.
2. Verify that all connections are good.
3. Verify that the unit powers up and runs correctly.
4. Verify that the unit meets all specifications.

Assembly Notes and Tips

- Use a good quality solder and flux.
- Be careful not to overheat the components.
- Trim all leads flush after soldering.
- Use the assembly fixture to help keep the unit aligned during assembly.

Unit (Design) verification tests on some units

- Power-on test
- Functional test
- Performance test

Configuration Version 1 Assemblies

- Use the configuration file provided with the unit.
- Verify that the unit is configured correctly.

Troubleshooting procedures

- If the unit does not power up, check the power supply.
- If the unit does not run correctly, check the connections and the software.
- If the unit does not meet specifications, contact the manufacturer for assistance.

Reference Material

The most recent schematic is for Rev 2 PCB Assemblies is:

https://github.com/PubInv/general-purpose-alarm-device/Hardware/GeneralPurposeAlarmDevicePCB/PDF/Schematic-GeneralPurposeAlarmDevicePCB-V2.2.pdf (https://github.com/PubInv/general-purpose-alarm-device/blob/main/Hardware/Documentation/ManufacturingUnitTestTroubleshootingRev2.md)

Assembly Notes and Tips

- The board will be received from JLCPCB with SMT components placed and some but not all through-hole components.
- The serial number should be written on the PCB assembly at the location indicated. The management of serial numbers is beyond the scope of this document. Each manufacturer must figure something out.

An Assembly Fixture

- An assembly assistant/fixture can be made by using a raw PCB with some long #6 screws and nuts to hold at the PCB mounting points.

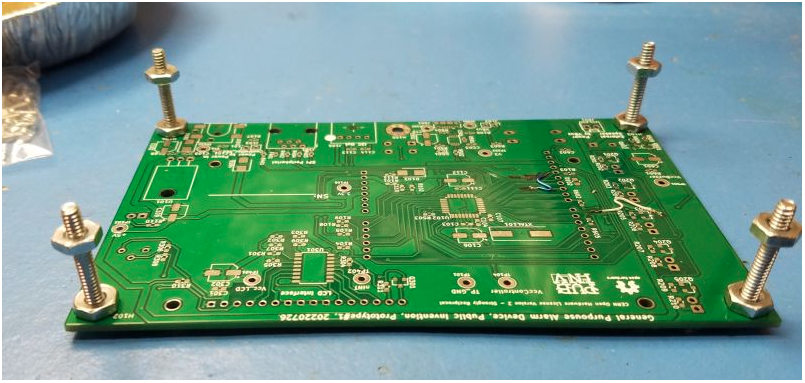
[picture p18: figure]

Please note that these are just some tips and suggestions. The specific assembly process may vary depending on the specific board and components.

In addition to the aforementioned items, four 4-40 screws with washers and 4-40 nuts are required to create a 1/8" spacer for holding the LCD and header for soldering.

Please note that the following changes have been made to the GPAD Rev 2.0 PCB per issue #213:

- Resistor R103 has been removed.
- Factory test for D601 has been updated.

The problem that was identified is that the assemblies built per the BOM_JLCPCB_20230228Modified.xls have R103 fitted with a 1K resistor. This resistor, together with LED D102, loads the SPI_CLK signal and is incompatible with proper operation of the GPAD as an SPI Peripheral from a 3.3V SPI Controller using the level shifting method using the common gate MOSFET.

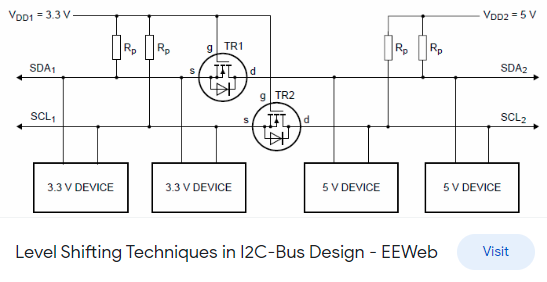
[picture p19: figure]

Please take these changes into account when assembling your GPAD Rev 2.0 PCB.

Solution:
The recommended solution is to remove R103.

Assembly Steps

1. LCD Bezel Grounding
  - Locate the J1 and J2 solder pads on the LCD module.
  - Solder them.
2. 16-pin Header
  - Fit the 16-pin header onto the LCD sub module.
  - Solder the header pins into the GPAD PCB.
  - Place four nylon 1/8" spacers at the four corners of the LCD sub module.
  - Place four 4-40 x 3/8" screws with 4-40 x 3/16" nuts through both boards and torque to 3.4 - 4.8 Inch-Pounds.
3. Buttons and Pot
  - Place the Reset button, S101, into the PCB from the display side.
  - Place the Mute button, S401, into the PCB from the display side.
  - Place the Buzzer, BZ601, into the PCB from the display side. Bending leads may help retain.
  - Place the Contrast pot, RV301, into the PCB from the display side. Bending leads may help retain.
4. LEDs
  - Thread the LED leads through the stand-offs.
  - The longer LED lead is the anode. The cathode has a flat side on the plastic case.
  - Place the LEDs in to the PCB so that the flat cathode side corresponds to the silk screen marking. Bend the leads to retain the LED into the PCB.
  - Placing the assembly on the fixture lets you have access to the top and the bottom of the assembly.
  - Life LED and reflow solder for a flush fit on the PCB.
  - For each LED, after soldering one lead, holding the LED from below up to the spacer and the PCB and reheat / reflow the solder for a flush fit.
  - Solder the second lead on the LED.
  - Trim the excess leads on RV301 and the LEDs.

Assembly Tip: Sharpie Oil-Based Paint Markers can be used to mark polarity on LED standoffs and mark PCB's version, serial number and programming status of the microprocessor.

Congratulations! Electrical assembly is complete.

LCD side components have been installed.

Electrical Tests

Electrical tests are divided into two parts:

1. Unprogrammed measurements made before flash programming the boot loader and other firmware.
2. Programmed measurements made after a boot loader and firmware have been placed into the microcontroller.

Electrical Measurements before programming bootloader and firmware

Measure and record the following electrical parameters by serial number.

Investigate and correct any abnormal measurements before applying power. Remove J102 and J103 and retain them if present. Note where they should be replaced. Start with no connections to the DUT (Device Under Test).

Power Jack Measure resistance to ground at J101 center pin as open or greater than 1Meg ohms.

SPI Interface Measure resistance to ground at J401 pin 5 as open or greater than 1Meg ohms..

Vin net Measure resistance to ground at TP102 as greater than 75K ohms. This net is capacitive and the resistance measured will climb as the multimeter charges the net.

+5V net Measure resistance to ground at TP103 +5 at 1K +/- 5% (950-1050 Ohms).

With a current limited supply set for 12V and maximum of 200 mA, apply power at J101 and note and record the unprogrammed current.

(FYI, when unprogrammed, the first time power up current is normally about 75-80 mA.)

Check that the power LED D105 is lit and is RED.

+5V net Measure the voltage of the +5V Net at TP103.

Please be advised that the current drawn by a programmed DUT that has been powered up and with display backlight on is approximately 61 mA when the reset switch is held down.

Vo Initial Set / LCD Contrast.

With a voltmeter, measure the voltage of the Vo pin of the LCD header to ground. Adjust RV103 for 1.3 V.

See records of measurements of some of the Rev 2 assemblies at this issue: https://github.com/PubInv/general-alarm-device/issues/217 #217

Electrical Test Results Table

- All resistance measured on 20Meg scale except R@5V net measured on 2K scale. Multimeter EMCO Model DMR-3800 unless noted.
- All current measured 200mA scale. Multimeter EMCO Model DMR-3800 unless noted.

Capture:

DUT Serial Number, R@PowerJack, R@SPI Interface, R@Vin net, R@5V net, UnProgramCurrent, Volt@+5 TP103, FullCurrent mA, Vo Volts, Notes

DUT Serial Number | R@PowerJack | R@SPI Interface | R@Vin net | R@5V net | UnProgramCurrent | Volt@+5 TP103 | FullCurrent mA | Vo Volts | Notes

Additional Measurements of current with in subcircuits Issue #230

See data from Rev2 build here: https://github.com/PubInv/general-alarm-device/issues/230

Load Firmware

Note: Loading firmware through the SPI interface is a manufacturing test of the SPI hardware components.

Load Bootloader

Use an Arduino UNO as an ISP (In Circuit Serial Programmer) which will load the boot loader into the DUT. Cable Connect the ISP UNO to the DUT as follows:

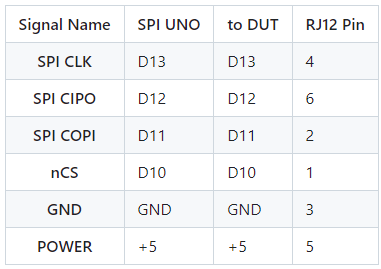
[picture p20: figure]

Wiring of the UNO to the DUT.

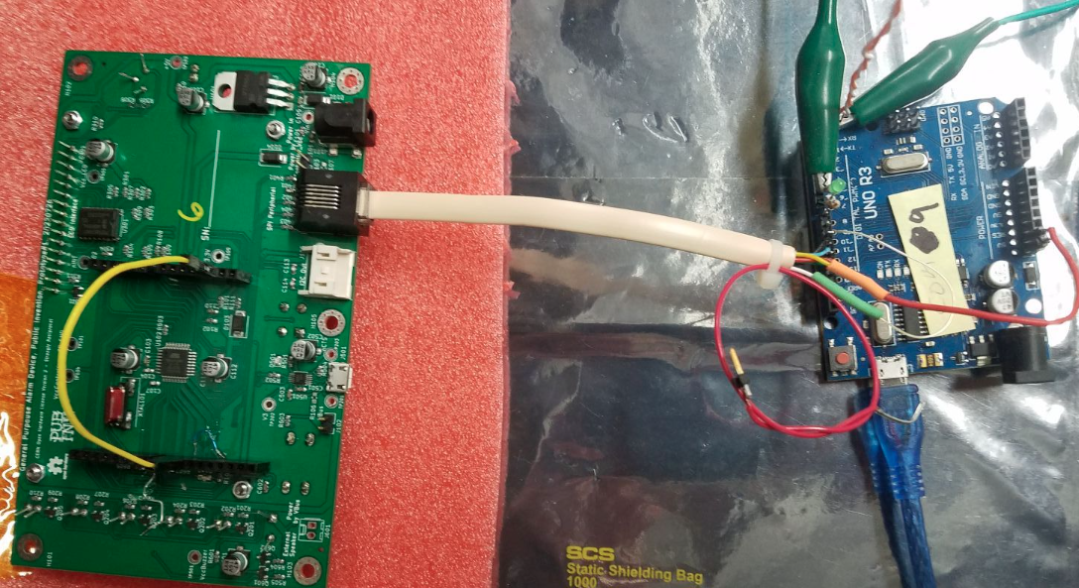
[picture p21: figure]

Place a Jumper on the DUT from D10 to Reset

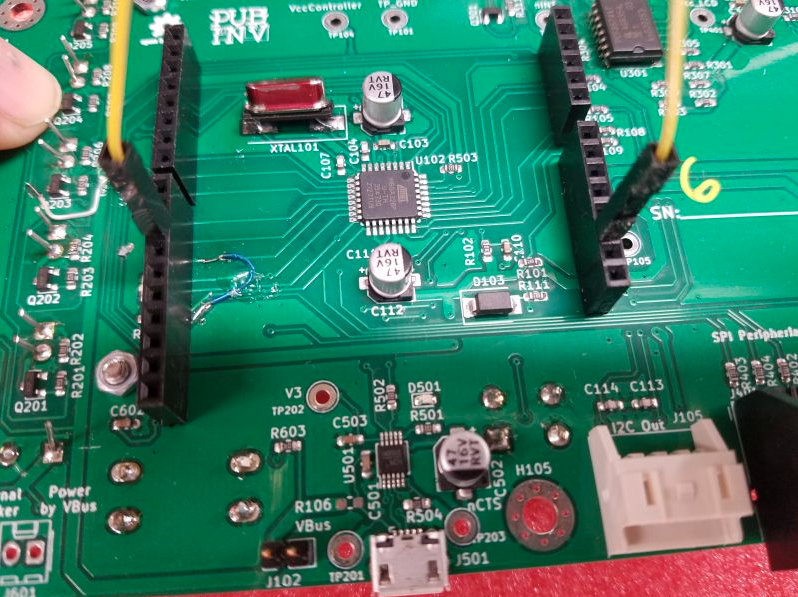
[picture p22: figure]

Missing Jumper to D10 When Load Bootloader

If you forget the above jumper the IDE will give an error something like this:

>Arduino: 1.8.19 (Windows 10), Board: "Arduino Duemilanove or Diecimila, ATmega328P"

>avrdude: Yikes! Invalid device signature.
> Double check connections and try again, or use -F to override
> this check.
>Error while attempting burning of bootloader with out the RJ12 connection.
>This report would have more information with "Show verbose output during compilation" option enabled in File -> Preferences.

Load into the IDE the sketch "ArduinoISP".

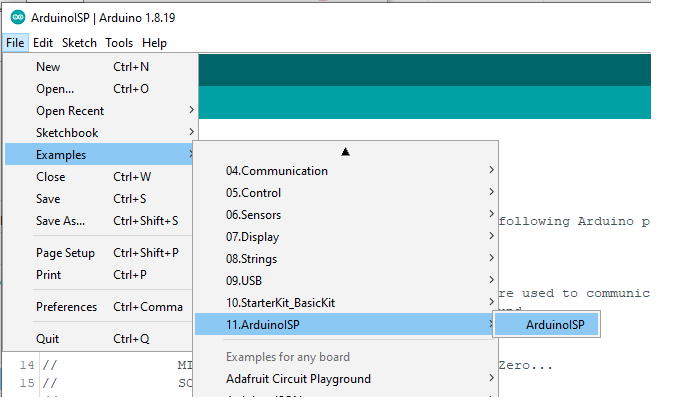
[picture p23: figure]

To load into the UNO, Select the serial port for the UNO and compile and upload with the "ArduinoISP" by pressing **<Ctrl>U**.

Setup the UNO to burn the boot loader into the GPAD target.

Select the board type (Boot loader type) to "Arduino Duemilanove..." .

Select the Processor type to "ATmega328P" .

Select the programmer type.

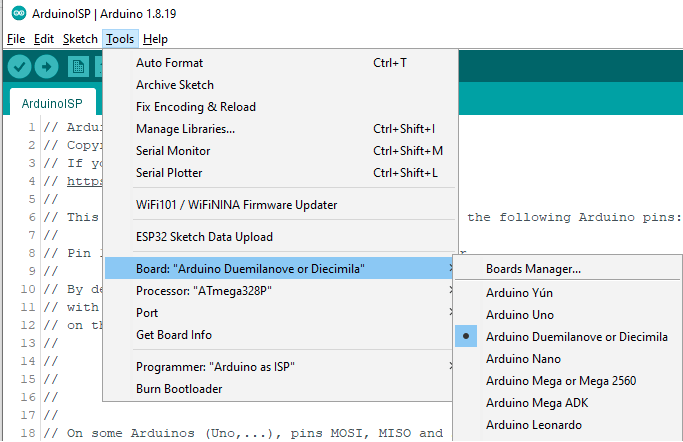
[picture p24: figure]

In the Arduino IDE, select TOOLS > Burn Bootloader .


Watch the progress bar in the IDE and look for success with the message "Done burning bootloader." in the blue status bar.


IF R103 has not been removed, check that LED D102 is winking with a short on time and longer off time indicating that the boot loader has been loaded. Until any other sketch is loaded this is the expected behaviour of the unit under test.

Load Factory Test Firmware.

Connect a USB cable to the DUT. Note the COM port enumerated in Device Manager Ports(COM&LPT) drop down


In the Arduino IDE, open the new file "GPAD_Factory_Test.ino".

Set the IDE for the COM port of the DUT.

Using the Arduino IDE, compile and upload to the DUT the "GPAD_Factory_Test.ino"


Watch the progress bar in the IDE and look for success with the message "Done uploading" in the blue status bar.

Open a terminal to the COM port of the DUT and set for appropriate BAUD rate.

Press the reset switch on the DUT and the LCD should display a message. The terminal should display a boot message too. This example is of a RealTerminal connected to the DUT.


Electrical Measurements After Programming Bootloader and Firmware

Measure and record the following electrical parameters by serial number:

- Observe the current on the DUT. Press the Mute Switch S601 and the white LEDs D201-D205 should light. The Buzzer will make a sound. Record this full current in the table above.

End of Rev2 Tests as of March 2023

7. Operation instructions

A video demonstrating (https://youtu.be/F5cf5-Cmwu0) [3] of one use of the GPAD (via the serial port) shows not only the usage but also shows the flashing lights and allows you to listen to the audio of escalating urgency.

The GPAD is activated by sending it digital commands over a cable from a different microcontroller. The basic use case is that a condition which needs human attention is detected in whatever manner possible by a sensing microcontroller or computer, called the controller. For example, the sensing device might detect that a temperature is too high, or that a the total flow through an airway in one minute is too low. It than calculates which of five alert levels (not counting the “no alert” condition, which could be considered a sixth) represents the severity of the condition, and a message of up to 80 characters that will inform a person how to remedy the problem. This message is displayed on the back-lit LCD on the GPAD itself. The LCD is dark when the alarm level is silent and back-lit in the other alarm levels.


Conceptually, the sensing device treats the GPAD as an API—an Application Programmers Interface. The six alarm levels are conceptually named:

1. Silent,
2. Informational,
3. Problem,
4. Warning,
5. Critical,
6. Panic.

The exact meaning of the six levels can be defined by the user for the application. Of course, not all six have to be used. However, the effect of the device should be clear: increasing severity leads to increasing sound and light levels produced by the device to obtain the attention of a human being. The GPAD has 5 LEDs, which are normally unlit in the Silent mode. Each increase in alarm level increases the number of LEDs lit. Our intention is that even from across a room a user may comprehend the alarm level at a glance.

Similarly, at increasing urgency levels, the GPAD plays a different rhythmic pattern of high-pitched sirens, which could be described as a “squeal” or a “scream”. This sound currently gets more urgent-sounding in terms of speed, rhythm, and frequency alternation as alarm level increases. Of course, the user is free to change or improve the coding of the GPAD itself, and a programmer will easily see where we implement the “songs''”.

In order to actually send the message, the programmer of the sensing device will likely use our software library. A C/C++ programmer will likely immediately understand the API from its actual declaration in the file alarm_api.h:

#ifndef ALARM_API

#define ALARM_API

#include <Stream.h>

enum AlarmLevel { silent, informational, problem, warning, critical, panic };

// const char *AlarmNames[] = { "OK ","INFO.","PROB.","WARN ","CRIT.","PANIC" };

const int NUM_LEVELS = 6;

const int MAX_MSG_LEN = 80;

const int MAX_BUFFER_SIZE = MAX_MSG_LEN + 1;

typedef struct {

uint8_t lvl;

// we will use a null-terminated string!

char msg[MAX_MSG_LEN+1];

} AlarmEvent;

int alarm_event(AlarmEvent& event,Stream &serialport);

int alarm(AlarmLevel level,char *str,Stream &serialport);

#endif

The API has two entry points: alarm and alarm_event. The function alarm is simply a convenience function for calling AlarmEvent which constructs an AlarmEvent for the programmer. An AlarmEvent, as stated above, consists of an AlarmLevel and an 80-character (null-terminated) character array holding the message to be displayed on the LCD.

    - Hardware Connection

Schematics in PDF form can be found in the folder at:

https://github.com/PubInv/general-purpose-alarm-device/tree/main/Hardware/GeneralPurposeAlarmDevicePCB/PDF

You can View Schematics on Line with the links at: https://github.com/PubInv/general-purpose-alarm-device/tree/main/Hardware/GeneralPurposeAlarmDevicePCB

The GPAD requires a 12V power supply via a standard 5.5mm OD 2.1mm pin. It draws less that 1000 mA, even at the highest alarm level.

The GPAD exposes an SPI interface through an RJ12 jack. The SPI pins are mapped the the RJ12 jack as:

SPI Peripheral Pins

The connector is JR12 6P6C and pin 1 is on the left then the connector is held with the contact pins up and facing the observer.

Note the GPAD is a 5V logic level peripheral device. Level shifters must be used when controlled by a 3.3V device.

Pin# | Signal Name | Note
1 | nCS | Active low
2 | COPI | Input to GPAD
3 | GND
4 | SCK | Input to GPAD
5 | ControllerVcc | 5 Volts, an optional way to put power into the GPAD
6 | CIPO | Output from GPAD, 5V.

Muting

The GPAD has a mute button. The button silences the sound but does not change the LED lighting. The GPAD stores an internal state as muted or not.

    - Example Controller Devices
      - General-purpose Computers

In order to develop and test the GPAD the functioning of the GPAD, it can be driven easily by a serial interface from a laptop computer by simply using a serial monitor. We have designed a trivial interface of commands that the GPAD listens for on the serial interface. Each command begins with one of 4 characters and is terminated by a newline. These are:

1. “a” is the most important command, and is used to set the alarm level. The “a” command is of the “aN”, where N is one of {0,1,2,3,4,5}, specifying increasing alarm levels respectively. These two characters are followed by up to 80 characters defining a message, terminated by an end-of-line (eoln) character.
2. “h” prints a helpful message.
3. “s” means “silence” – mute the GPAD.
4. “u” means “unsilence” or “unmute” – the GPAD is allowed to make noise.

The easiest way to send these serial commands is with a terminal program, or the “serial monitor” feature of the Arduino IDE, which is useful for testing. However, to actually program the GPAD to alert to a recondition, a library such as PySerial that allows a message to be transmitted over the serial port from general purpose programming language.

      - Microcontrollers

However, an important use case for the GPAD to be programmed by another microcontroller. The SPI interface is particularly useful for controlling a GPAD from another Arduino-class microcontroller. In fact, to make testing as easy as possible, we have software that allows a GPAD peripheral to be programmed by another GPAD acting as a controller. This can be found in the directory GPAD_API_SPI_CONTROLLER (https://github.com/PubInv/general-purpose-alarm-device/tree/main/Firmware/GPAD_API_SPI_CONTROLLER). This code is a useful starting point for anyone programming a GPAD for any given use case, because it exercises the SPI interface and in particular the GPAD Application Programmers Interface.

8. Validation and characterization

The GPAD is designed to be a part of the Freepsireco ecosystem (https://github.com/PubInv/freespireco) [2] and serve as the medical alarm in an ICU ward for the PolyVent open-source ventilator. Specifically, it is designed to alert clinicians to conditions which can be electronically computed by the PolyVent microccontroller. These include (but have not yet been coded):

1. A hose disconnect to the patient
2. A loss of pressure
3. Patient-ventilator asynchrony
4. In ability to achieve programmed Peak Inspiratory Pressure, etc.

The GPAD has been demoed in public quite a bit.

After some experimentation to obtain loudness, we built Revision 2 with two different buzzers (Digi-key part numbers 433-WST-1210T-ND and 102-CMI-1295-0585T-ND) which are both rated at 85 dB at 10cm. The LEDs are fairly bright. The basic electrical performance of this simple device seems clear.

However, the true value of an alarm device can only be measured its ability to draw human attention, and then to inform a human being how to take action, and then not to distract them further. There are both simple and complex human/machine interaction performance metrics which we have not begun to measure for the GPAD. A good introduction to the complexity of this field can found in Konkani, Oakley and Bauld (2012).[1]

In the language of the field, the GPAD is not yet a “smart alarm” or an “alarm management system”. It is rather, an annunciation device. (If we called it that, however, non-experts would not understand its intended use.) We hope researchers in this area will find the GPAD a useful programmable component for such such systems and tool for such investigations.

CRediT author statement

Robert L. Read: Conceptualization, Software, Funding Acquisition, Writing – Original Draft.

Lawrence Kincheloe: Supervision, Methodology, Hardware.

(Forrest) Lee Erickson: Software, Validation, Hardware.

Oluseyi 'Seyi' Adeniyi: Software

Lawrence Kincheloe designed the enclosure and mentored the OU capstone projects.

Lee Erickson performed schematic capture, designed the PCBs, wrote the assembly instructions and captured measurements on units during assembly and during some troubleshooting. Lee wrote initial factory test firmware and the factory test procedure which applies the firmware.

Oluseyi 'Seyi' Adeniyi expanded the factory test firmware to include “walking one” like tests for more thorough tests against shorts and bad LCD displays. Seyi also designed the alarm sounds.

Acknowledgments

We would like to thank two senior capstone engineering classes at the University of Oklahoma who made potential extensions to the GPAD. Although they have not yet been used in this project, they have clarified our thinking for future enhancements.

Funding: This work was supported by Public Invention, Austin, TX, a US 501c3 public charity.

References

[1] A. Konkani, B. Oakley, T. J. Bauld, Reducing hospital noise: a review of medical device alarm management. Biomedical Instrumentation & Technology, 46(6) (2012), 478-487. https://array.aami.org/doi/full/10.2345/0899-8205-46.6.478

[2] R. Read, The Freespireco Project: A complete, free-libre open-source, easily repairable, widely usable, safe and effective respiratory support medical device ecosystem. (2023) https://github.com/PubInv/freespireco.

[3] R. Read, Demo of GPAD Light and Sound. https://youtu.be/F5cf5-Cmwu0. Accessed July 10th, 2023.

[4] Mucco Test Horn literature. https://muccosignal.com/product/warning-horns-with-16-tons/ (accessed 12.08.23)

[5] S.Z. Abidi, V. Suturin, R.L. Read, N. Bechard, 2023, June. A democratized open-source platform for medical device troubleshooting. In 2023 ASEE Annual Conference & Exposition. https://peer.asee.org/a-democratized-open-source-platform-for-medical-device-troubleshooting.

[6] Adafruit Tower Light - Red Yellow Green Alert Light with Buzzer – 12VDC. https://www.adafruit.com/product/2993 (accessed 12.08.2023)

[7] HiLetgo 3D Printer Reprap Smart Controller (Model # 3-01-0889). https://www.amazon.com/HiLetgo-Printer-Controller-Display-Arduino/dp/B07X378P8X. (accessed 12.08.2023).

[8] The Ultimate box maker. https://www.thingiverse.com/thing:1264391. (accessed 24.10.2023).

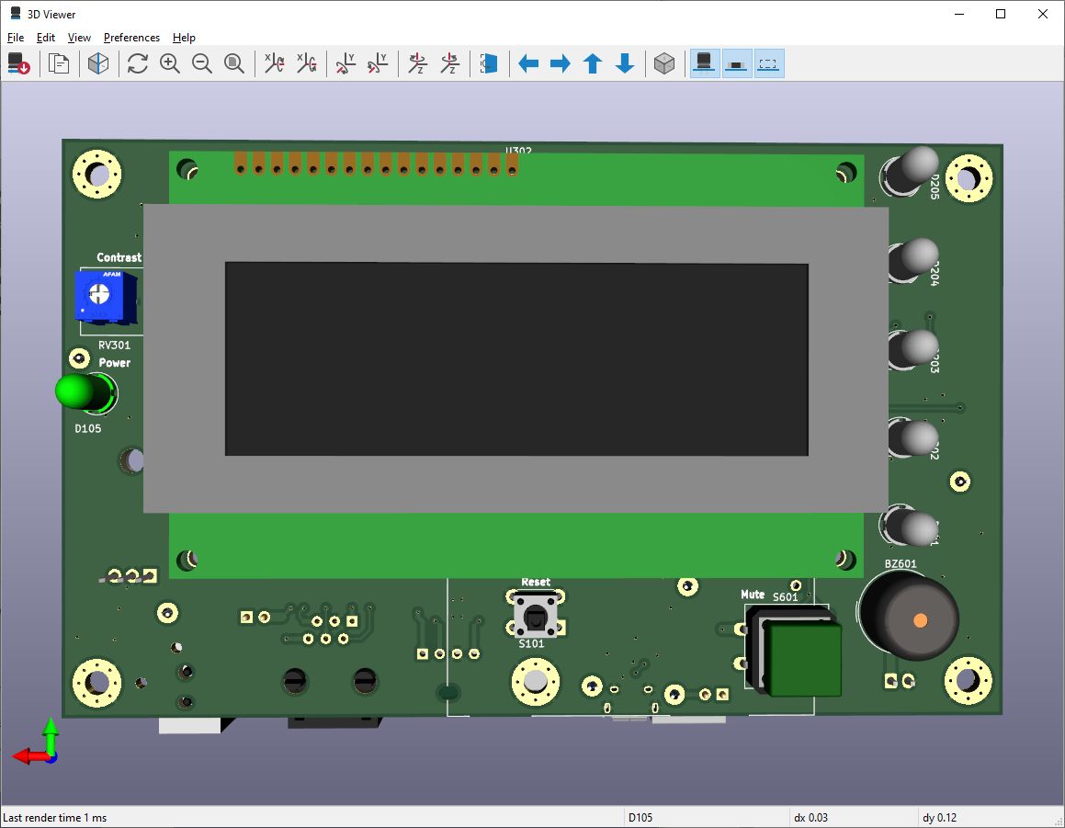
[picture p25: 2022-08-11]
Hardware/Documentation/PICS/PCB_Display_Side.jpg

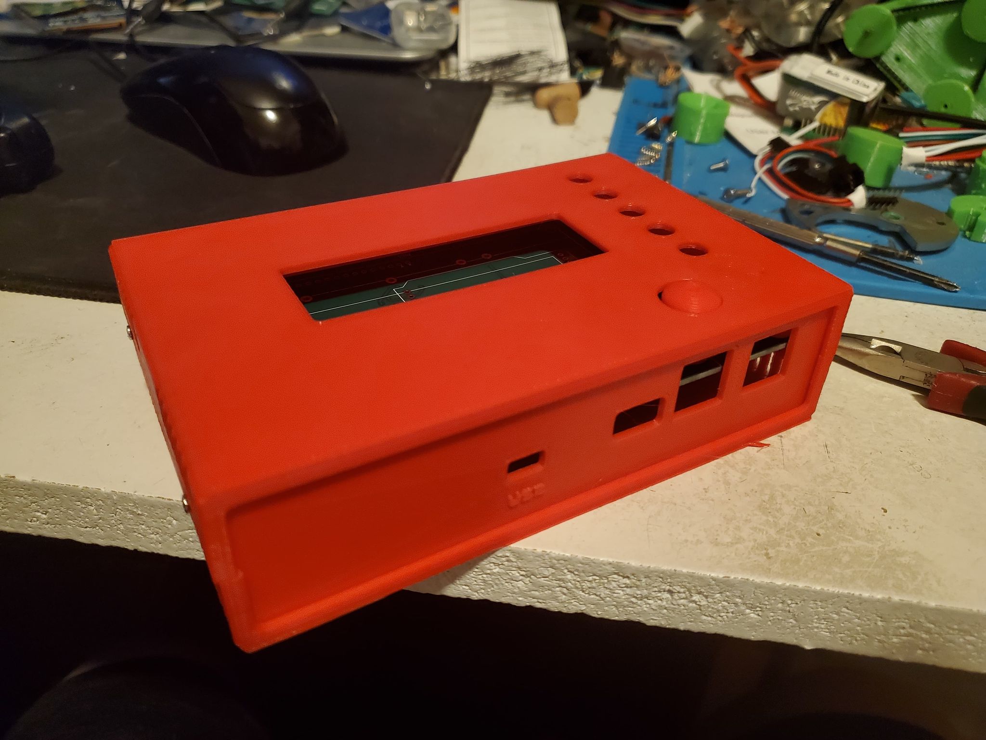
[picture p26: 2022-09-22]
Hardware/Documentation/PICS/302425135_647240966665689_7092729030162653141_n.jpg

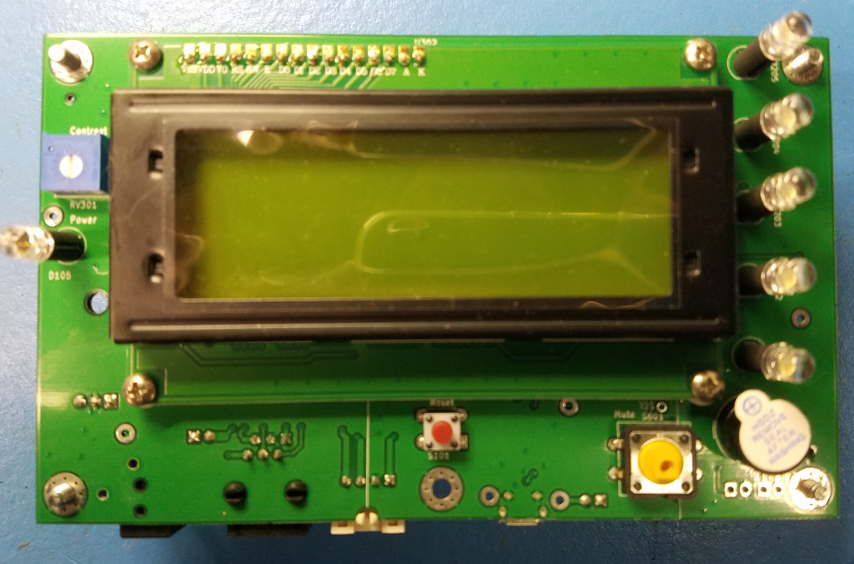
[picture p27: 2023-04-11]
Hardware/Documentation/PICS/Rev2/PWA_FrontView.png

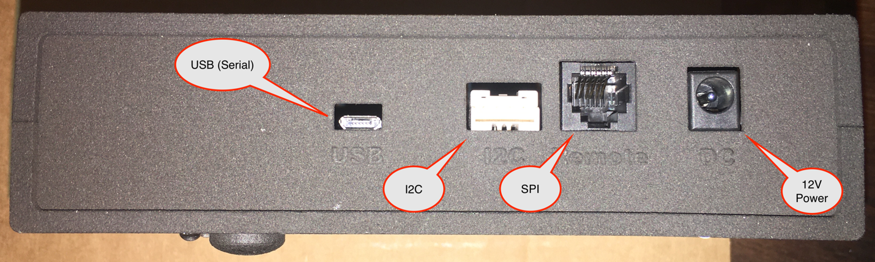
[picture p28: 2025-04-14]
images/Hardware.png

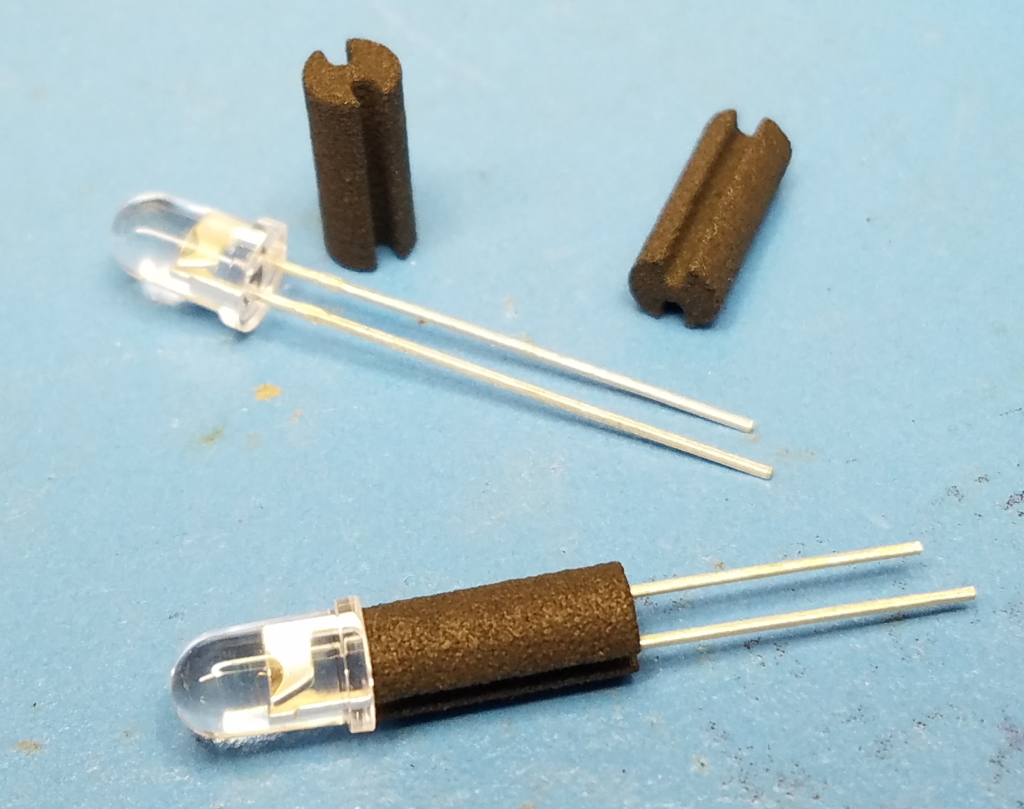
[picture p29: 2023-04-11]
Hardware/Documentation/PICS/Rev2/LED_and_Spacers.png

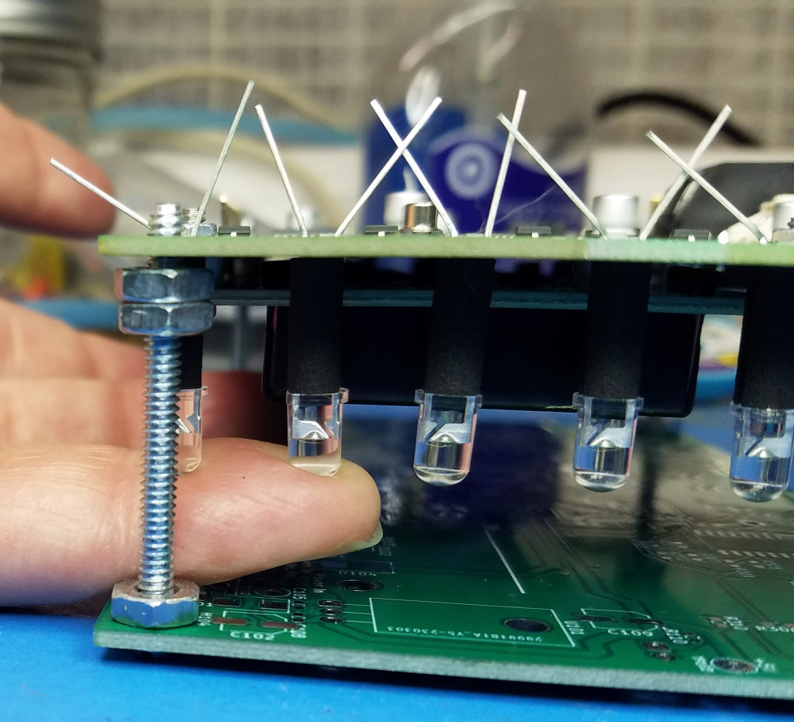
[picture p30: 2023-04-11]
Hardware/Documentation/PICS/Rev2/fingerlift_led.png

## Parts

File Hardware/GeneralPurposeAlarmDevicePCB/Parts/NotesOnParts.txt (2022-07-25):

Tactile button at: https://grabcad.com/library/tactile-switches-6mm-sq-knob-1/details?folder_id=8603698

Display: https://grabcad.com/library/lcd-2004a-1

LED: https://grabcad.com/library/led-t1-3-4

RJ12 3d Model from: https://grabcad.com/library/rj11-connectors-6p-1
Converted STP to STEP in KiCAD.

Arduino UNO from Grabcad at:
https://grabcad.com/library/arduino-uno-r3-1

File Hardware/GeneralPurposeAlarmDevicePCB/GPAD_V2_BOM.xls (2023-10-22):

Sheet: RAW
Source: | C:\Users\Public\Downloads\Arduino\PubInv\general-alarm-device\Hardware\GeneralPurposeAlarmDevicePCB\GeneralPurposeAlarmDevicePCB.kicad_sch
Date: | 3/1/2023 2:14:34 PM
Tool: | Eeschema (6.0.6)
Generator: | C:\Program Files\KiCad\6.0\bin\scripting\plugins/bom_csv_grouped_by_value.py
Component Count: | 143
Individual Components:
Item | Qty | Reference(s) | Value | LibPart | Footprint | Datasheet | Assembly Type | AssemblyType | Category | Cost | DK_Datasheet_Link | DK_Detail_Page | Description | Digi-Key_PN | Distributor 1 | Distributor 1 PN | Distributor 2 | Distributor 2 PN | Family | MPN | Manufacturer | Status
 |  | A101 | Arduino_UNO_R3_Shield | GPAD_SCH_LIB:Arduino_UNO_R3_Shield | GeneralPurposeAlarmDevicePCB:Arduino_UNO_R3_NoMountingHoles3D | https://www.arduino.cc/en/Main/arduinoBoardUno |  | HAND |  | 1000000
 |  | BZ601 | Buzzer_Adafruit_P1536A | GPAD_SCH_LIB:Buzzer_Adafruit_P1536A | GeneralPurposeAlarmDevicePCB:Buzzer_12.2mm_9.7mm_7.62mm | https://www.adafruit.com/product/1536 |  | HAND |  | 0.98 |  |  |  |  | Adafruit | P1536A |  |  |  | PS1240P02BT
 |  | C101 | 39pF | Device:C | Capacitor_SMD:C_0603_1608Metric_Pad1.08x0.95mm_HandSolder | ~ |  | SMT |  | 0.003 |  |  |  |  | JLCPCB | C107049 |  |  |  | CC0603JRNPO9BN390 | YAGEO
 |  | C102 | 47uF 16V | Device:C_Polarized | Capacitor_SMD:CP_Elec_5x5.4 | ~ |  | SMT |  | 0.038 |  |  |  |  | JLCPCB | C2895272 |  |  |  | RVT47UF16V67RV0019 | KNSCHA
 |  | C103 | 100nF | Device:C | Capacitor_SMD:C_0603_1608Metric_Pad1.08x0.95mm_HandSolder | ~ |  | SMT |  | 0.0021 |  |  | 50V 100nF X7R Â±10% 0603 Multilayer Ceramic Capacitors MLCC - SMD/SMT ROHS |  | JLCPCB | C14663 |  |  |  | CC0603KRX7R9BB104 | YAGEO
 |  | C104 | 39pF | Device:C | Capacitor_SMD:C_0603_1608Metric_Pad1.08x0.95mm_HandSolder | ~ |  | SMT |  | 0.003 |  |  |  |  | JLCPCB | C107049 |  |  |  | CC0603JRNPO9BN390 | YAGEO
 |  | C105 | 100nF | Device:C | Capacitor_SMD:C_0603_1608Metric_Pad1.08x0.95mm_HandSolder | ~ |  | SMT |  | 0.0021 |  |  | 50V 100nF X7R Â±10% 0603 Multilayer Ceramic Capacitors MLCC - SMD/SMT ROHS |  | JLCPCB | C14663 |  |  |  | CC0603KRX7R9BB104 | YAGEO
 |  | C106 | 47uF 16V | Device:C_Polarized | Capacitor_SMD:CP_Elec_5x5.4 | ~ |  | SMT |  | 0.038 |  |  |  |  | JLCPCB | C2895272 |  |  |  | RVT47UF16V67RV0019 | KNSCHA
 |  | C107 | 39pF | Device:C | Capacitor_SMD:C_0603_1608Metric_Pad1.08x0.95mm_HandSolder | ~ |  | SMT |  | 0.003 |  |  |  |  | JLCPCB | C107049 |  |  |  | CC0603JRNPO9BN390 | YAGEO
 |  | C108 | 100nF | Device:C | Capacitor_SMD:C_0603_1608Metric_Pad1.08x0.95mm_HandSolder | ~ |  | SMT |  | 0.0021 |  |  | 50V 100nF X7R Â±10% 0603 Multilayer Ceramic Capacitors MLCC - SMD/SMT ROHS |  | JLCPCB | C14663 |  |  |  | CC0603KRX7R9BB104 | YAGEO
 |  | C109 | 47uF 16V | Device:C_Polarized | Capacitor_SMD:CP_Elec_5x5.4 | ~ |  | SMT |  | 0.038 |  |  |  |  | JLCPCB | C2895272 |  |  |  | RVT47UF16V67RV0019 | KNSCHA
 |  | C110 | 100nF | Device:C | Capacitor_SMD:C_0603_1608Metric_Pad1.08x0.95mm_HandSolder | ~ |  | SMT |  | 0.0021 |  |  | 50V 100nF X7R Â±10% 0603 Multilayer Ceramic Capacitors MLCC - SMD/SMT ROHS |  | JLCPCB | C14663 |  |  |  | CC0603KRX7R9BB104 | YAGEO
 |  | C111 | 100nF | Device:C | Capacitor_SMD:C_0603_1608Metric_Pad1.08x0.95mm_HandSolder | ~ |  | SMT |  | 0.0021 |  |  | 50V 100nF X7R Â±10% 0603 Multilayer Ceramic Capacitors MLCC - SMD/SMT ROHS |  | JLCPCB | C14663 |  |  |  | CC0603KRX7R9BB104 | YAGEO
 |  | C112 | 47uF 16V | Device:C_Polarized | Capacitor_SMD:CP_Elec_5x5.4 | ~ |  | SMT |  | 0.038 |  |  |  |  | JLCPCB | C2895272 |  |  |  | RVT47UF16V67RV0019 | KNSCHA
 |  | C113 | 39pF | Device:C | Capacitor_SMD:C_0603_1608Metric_Pad1.08x0.95mm_HandSolder | ~ |  | SMT |  | 0.003 |  |  |  |  | JLCPCB | C107049 |  |  |  | CC0603JRNPO9BN390 | YAGEO
 |  | C114 | 39pF | Device:C | Capacitor_SMD:C_0603_1608Metric_Pad1.08x0.95mm_HandSolder | ~ |  | SMT |  | 0.003 |  |  |  |  | JLCPCB | C107049 |  |  |  | CC0603JRNPO9BN390 | YAGEO
 |  | C301 | 100nF | Device:C | Capacitor_SMD:C_0603_1608Metric_Pad1.08x0.95mm_HandSolder | ~ |  | SMT |  | 0.0021 |  |  | 50V 100nF X7R Â±10% 0603 Multilayer Ceramic Capacitors MLCC - SMD/SMT ROHS |  | JLCPCB | C14663 |  |  |  | CC0603KRX7R9BB104 | YAGEO
 |  | C302 | 47uF 16V | Device:C_Polarized | Capacitor_SMD:CP_Elec_5x5.4 | ~ |  | SMT |  | 0.038 |  |  |  |  | JLCPCB | C2895272 |  |  |  | RVT47UF16V67RV0019 | KNSCHA
 |  | C501 | 100nF | Device:C | Capacitor_SMD:C_0603_1608Metric_Pad1.08x0.95mm_HandSolder | ~ |  | SMT |  | 0.0021 |  |  | 50V 100nF X7R Â±10% 0603 Multilayer Ceramic Capacitors MLCC - SMD/SMT ROHS |  | JLCPCB | C14663 |  |  |  | CC0603KRX7R9BB104 | YAGEO
 |  | C502 | 47uF 16V | Device:C_Polarized | Capacitor_SMD:CP_Elec_5x5.4 | ~ |  | SMT |  | 0.038 |  |  |  |  | JLCPCB | C2895272 |  |  |  | RVT47UF16V67RV0019 | KNSCHA
 |  | C503 | 100nF | Device:C | Capacitor_SMD:C_0603_1608Metric_Pad1.08x0.95mm_HandSolder | ~ |  | SMT |  | 0.0021 |  |  | 50V 100nF X7R Â±10% 0603 Multilayer Ceramic Capacitors MLCC - SMD/SMT ROHS |  | JLCPCB | C14663 |  |  |  | CC0603KRX7R9BB104 | YAGEO
 |  | C601 | 47uF 16V | Device:C_Polarized | Capacitor_SMD:CP_Elec_5x5.4 | ~ |  | SMT |  | 0.038 |  |  | 16V 47uF SMD,5x5.4mm Aluminum Electrolytic Capacitors - SMD ROHS |  | JLCPCB | C2895272 |  |  |  | RVT47UF16V67RV0019 | KNSCHA
 |  | C602 | 100nF | Device:C | Capacitor_SMD:C_0603_1608Metric_Pad1.08x0.95mm_HandSolder | ~ |  | SMT |  | 0.0021 |  |  | 50V 100nF X7R Â±10% 0603 Multilayer Ceramic Capacitors MLCC - SMD/SMT ROHS |  | JLCPCB | C14663 |  |  |  | CC0603KRX7R9BB104 | YAGEO
 |  | D101 | Schottky 2A | Device:D_Schottky | Diode_SMD:D_SMB | ~ |  | SMT |  | 0.0343 |  |  |  |  | JLCPCB | C14996 |  |  |  | SS210 | MDDï¼ˆMicrodiode Electronicsï¼‰
 |  | D102 | RED 0603 | Device:LED | LED_SMD:LED_0603_1608Metric_Pad1.05x0.95mm_HandSolder | ~ |  | HAND | Optoelectronics | 0.0054 | http://optoelectronics.liteon.com/upload/download/DS22-2000-109/LTST-C171KRKT.pdf | /product-detail/en/lite-on-inc/LTST-C171KRKT/160-1427-1-ND/386800 | LED RED CLEAR SMD | 160-1427-1-ND | JLCPCB | C2286 |  |  | LED Indication - Discrete | LTST-C171KRKT | Lite-On Inc. | Active
 |  | D103 | Schottky 2A | Device:D_Schottky | Diode_SMD:D_SMB | ~ |  | SMT |  | 0.0343 |  |  |  |  | JLCPCB | C14996 |  |  |  | SS210 | MDDï¼ˆMicrodiode Electronicsï¼‰
 |  | D104 | Schottky 2A | Device:D_Schottky | Diode_SMD:D_SMB | ~ |  | SMT |  | 0.0343 |  |  |  |  | JLCPCB | C14996 |  |  |  | SS210 | MDDï¼ˆMicrodiode Electronicsï¼‰
 |  | D105 | LED_T1.75_CLEAR_RED | GPAD_SCH_LIB:LED_T1.75_CLEAR_WHITE | GeneralPurposeAlarmDevicePCB:LED_5mm_Radial | http://optoelectronics.liteon.com/upload/download/DS20-2005-253/LTW-2R3D7.pdf |  | HAND | Optoelectronics | 0.36 | http://optoelectronics.liteon.com/upload/download/DS20-2005-253/LTW-2R3D7.pdf | /product-detail/en/lite-on-inc/LTL2R3KEK/160-1682-ND/573572 | LED RED CLEAR T-1 3/4 T/H | 160-1682-ND | DigiKey | 160-1682-ND |  |  | LED Indication - Discrete | LTW-2R3D7 | Lite-On Inc. | Active
 |  | D106 | RED 0603 | Device:LED | LED_SMD:LED_0603_1608Metric_Pad1.05x0.95mm_HandSolder | ~ |  | HAND | Optoelectronics | 0.0054 | http://optoelectronics.liteon.com/upload/download/DS22-2000-109/LTST-C171KRKT.pdf | /product-detail/en/lite-on-inc/LTST-C171KRKT/160-1427-1-ND/386800 | LED RED CLEAR SMD | 160-1427-1-ND | JLCPCB | C2286 |  |  | LED Indication - Discrete | LTST-C171KRKT | Lite-On Inc. | Active
 |  | D201 | LED_T1.75_CLEAR_WHITE | GPAD_SCH_LIB:LED_T1.75_CLEAR_WHITE | GeneralPurposeAlarmDevicePCB:LED_5mm_Radial | http://optoelectronics.liteon.com/upload/download/DS20-2005-253/LTW-2R3D7.pdf |  | HAND | Optoelectronics | 0.65 | http://optoelectronics.liteon.com/upload/download/DS20-2005-253/LTW-2R3D7.pdf | /product-detail/en/lite-on-inc/LTW-2R3D7/160-1772-ND/1277121 | LED WHITE CLEAR T-1 3/4 T/H | 160-1772-ND | DigiKey | 160-1772-ND |  |  | LED Indication - Discrete | LTW-2R3D7 | Lite-On Inc. | Active
 |  | D202 | LED_T1.75_CLEAR_WHITE | GPAD_SCH_LIB:LED_T1.75_CLEAR_WHITE | GeneralPurposeAlarmDevicePCB:LED_5mm_Radial | http://optoelectronics.liteon.com/upload/download/DS20-2005-253/LTW-2R3D7.pdf |  | HAND | Optoelectronics | 0.65 | http://optoelectronics.liteon.com/upload/download/DS20-2005-253/LTW-2R3D7.pdf | /product-detail/en/lite-on-inc/LTW-2R3D7/160-1772-ND/1277121 | LED WHITE CLEAR T-1 3/4 T/H | 160-1772-ND | DigiKey | 160-1772-ND |  |  | LED Indication - Discrete | LTW-2R3D7 | Lite-On Inc. | Active
 |  | D203 | LED_T1.75_CLEAR_WHITE | GPAD_SCH_LIB:LED_T1.75_CLEAR_WHITE | GeneralPurposeAlarmDevicePCB:LED_5mm_Radial | http://optoelectronics.liteon.com/upload/download/DS20-2005-253/LTW-2R3D7.pdf |  | HAND | Optoelectronics | 0.65 | http://optoelectronics.liteon.com/upload/download/DS20-2005-253/LTW-2R3D7.pdf | /product-detail/en/lite-on-inc/LTW-2R3D7/160-1772-ND/1277121 | LED WHITE CLEAR T-1 3/4 T/H | 160-1772-ND | DigiKey | 160-1772-ND |  |  | LED Indication - Discrete | LTW-2R3D7 | Lite-On Inc. | Active
 |  | D204 | LED_T1.75_CLEAR_WHITE | GPAD_SCH_LIB:LED_T1.75_CLEAR_WHITE | GeneralPurposeAlarmDevicePCB:LED_5mm_Radial | http://optoelectronics.liteon.com/upload/download/DS20-2005-253/LTW-2R3D7.pdf |  | HAND | Optoelectronics | 0.65 | http://optoelectronics.liteon.com/upload/download/DS20-2005-253/LTW-2R3D7.pdf | /product-detail/en/lite-on-inc/LTW-2R3D7/160-1772-ND/1277121 | LED WHITE CLEAR T-1 3/4 T/H | 160-1772-ND | DigiKey | 160-1772-ND |  |  | LED Indication - Discrete | LTW-2R3D7 | Lite-On Inc. | Active
 |  | D205 | LED_T1.75_CLEAR_WHITE | GPAD_SCH_LIB:LED_T1.75_CLEAR_WHITE | GeneralPurposeAlarmDevicePCB:LED_5mm_Radial | http://optoelectronics.liteon.com/upload/download/DS20-2005-253/LTW-2R3D7.pdf |  | HAND | Optoelectronics | 0.65 | http://optoelectronics.liteon.com/upload/download/DS20-2005-253/LTW-2R3D7.pdf | /product-detail/en/lite-on-inc/LTW-2R3D7/160-1772-ND/1277121 | LED WHITE CLEAR T-1 3/4 T/H | 160-1772-ND | DigiKey | 160-1772-ND |  |  | LED Indication - Discrete | LTW-2R3D7 | Lite-On Inc. | Active
 |  | D501 | RED 0603 | Device:LED | LED_SMD:LED_0603_1608Metric | ~ |  | SMT | Optoelectronics | 0.0054 |  |  | LED RED CLEAR SMD |  | JLCPCB | C2286 |  |  | LED Indication - Discrete | KT-0603R | Hubei KENTO Elec | Active
 |  | F101 | Polyfuse_Small | Device:Polyfuse_Small | Fuse:Fuse_0603_1608Metric | ~ |  | SMT |  | 0.2448 |  |  | 6V 1A 50A -40â„ƒ~+85â„ƒ 1.8A 40mÎ© 300ms 120mÎ© 0603 Resettable Fuses ROHS |  | JLCPCB | C207017 |  |  |  | 0603L100SLYR | Littelfuse
 |  | F401 | Polyfuse_Small | Device:Polyfuse_Small | Fuse:Fuse_0603_1608Metric | ~ |  | SMT |  | 0.2448 |  |  | 6V 1A 50A -40â„ƒ~+85â„ƒ 1.8A 40mÎ© 300ms 120mÎ© 0603 Resettable Fuses ROHS |  | JLCPCB | C207017 |  |  |  | 0603L100SLYR | Littelfuse
 |  | H101 | MountingHole_Pad_3.5mm | GPAD_SCH_LIB:MountingHole_Pad_3.5mm | GeneralPurposeAlarmDevicePCB:MountingHole_3.5mm_Pad_Via | ~ |  | NA |  | 0 |  |  | MountingHole_Pad_3.5mm |  | NA | NA
 |  | H102 | MountingHole_Pad_3.5mm | GPAD_SCH_LIB:MountingHole_Pad_3.5mm | GeneralPurposeAlarmDevicePCB:MountingHole_3.5mm_Pad_Via | ~ |  | NA |  | 0 |  |  | MountingHole_Pad_3.5mm |  | NA | NA
 |  | H103 | MountingHole_Pad_3.5mm | GPAD_SCH_LIB:MountingHole_Pad_3.5mm | GeneralPurposeAlarmDevicePCB:MountingHole_3.5mm_Pad_Via | ~ |  | NA |  | 0 |  |  | MountingHole_Pad_3.5mm |  | NA | NA
 |  | H104 | MountingHole_Pad_3.5mm | GPAD_SCH_LIB:MountingHole_Pad_3.5mm | GeneralPurposeAlarmDevicePCB:MountingHole_3.5mm_Pad_Via | ~ |  | NA |  | 0 |  |  | MountingHole_Pad_3.5mm |  | NA | NA
 |  | H105 | MountingHole_Pad_3.5mm | GPAD_SCH_LIB:MountingHole_Pad_3.5mm | GeneralPurposeAlarmDevicePCB:MountingHole_3.5mm_Pad_Via | ~ |  | NA |  | 0 |  |  | MountingHole_Pad_3.5mm |  | NA | NA
 |  | J101 | Barrel_Jack_Switch_SMT | GPAD_SCH_LIB:Barrel_Jack_Switch_SMT | GeneralPurposeAlarmDevicePCB:BarrelJack_CLIFF_FC681465S_SMT_Horizontal | https://tensility.s3.amazonaws.com/uploads/pdffiles/54-00164.pdf |  | HAND |  | 0.205 |  |  | Power Barrel Connector Jack 2.10mm ID (0.083"), 5.50mm OD (0.217") Surface Mount, Right Angle |  | JLCPCB | C319134 | Digikey | 839-54-00164CT-ND |  | DC-005-5A-2.0-SMT / 54-00164 | XKB Connectivity / Tensility International Corp
 |  | J102 | 0.100_2Pin | GPAD_SCH_LIB:22-23-2021 | Connector_PinHeader_2.54mm:PinHeader_1x02_P2.54mm_Vertical | https://datasheet.lcsc.com/lcsc/1811011511_Amphenol-ICC-68000-102HLF_C168673.pdf | HAND | HAND | Connectors, Interconnects | 0.1458 | https://media.digikey.com/pdf/Data%20Sheets/Molex%20PDFs/A-6373-N_Series_Dwg_2010-12-03.pdf | /product-detail/en/molex/22-23-2021/WM4200-ND/26667 | HEADER VERT 2POS 2.54MM | WM4200-ND | JLCPCB | C168673 |  |  | Rectangular Connectors - Headers, Male Pins | 68000-102HLF | Amphenol ICC | Active
 |  | J103 | 0.100_2Pin | GPAD_SCH_LIB:22-23-2021 | Connector_PinHeader_2.54mm:PinHeader_1x02_P2.54mm_Vertical | https://datasheet.lcsc.com/lcsc/1811011511_Amphenol-ICC-68000-102HLF_C168673.pdf | HAND | HAND | Connectors, Interconnects | 0.1458 | https://media.digikey.com/pdf/Data%20Sheets/Molex%20PDFs/A-6373-N_Series_Dwg_2010-12-03.pdf | /product-detail/en/molex/22-23-2021/WM4200-ND/26667 | HEADER VERT 2POS 2.54MM | WM4200-ND | JLCPCB | C168673 |  |  | Rectangular Connectors - Headers, Male Pins | 68000-102HLF | Amphenol ICC | Active
 |  | J105 | S04B-XASK-1(LF)(SN)Rev2 | GPAD_SCH_LIB:S04B-XASK-1(LF)(SN)Rev2 | GeneralPurposeAlarmDevicePCB:S04B-XASK-1(LF)(SN)Rev2 | https://www.jst-mfg.com/product/pdf/eng/eXA1.pdf | HAND |  | Connectors, Interconnects | 0.15 |  |  | CONN HEADER R/A 4POS 2.5MM | 455-4090-ND | JLCPCB | C265097 | DigiKey | 455-4090-ND | Rectangular Connectors - Headers, Male Pins, Side Entery | S04B-XASK-1(LF)(SN) | JST | Active
 |  | J401 | RJ12_6P6C_HORZ | GPAD_SCH_LIB:RJ12_6P6C_HORZ | GeneralPurposeAlarmDevicePCB:RJ12_Amphenol_54601 | https://datasheet.lcsc.com/lcsc/1811141146_TE-Connectivity-5555165-1_C305981.pdf |  | HAND |  | 0.8901 |  |  | Jack Modular Connector 6p6c (RJ11, RJ12, RJ14, RJ25) 90Â° Angle (Right) Unshielded Cat3 |  | JLCPCB | C305981 | Digikey | A31422-ND |  | 5555165-1 | TE Connectivity
 |  | J501 | USB_B_Micro_Local | GPAD_SCH_LIB:USB_B_Micro_Local | GeneralPurposeAlarmDevicePCB:USB_Micro-B_Amphenol_10118194_Horizontal |  |  | HAND |  | 0.2042 |  |  | USB 2.0 1 5 Female Micro-B SMD USB Connectors ROHS |  | JLCPCB | C132563 |  |  |  | 10118194-0001LF ???Wuerth_629105150521 ??? Molex 1050170001 | Amphenol ICC ??? Wuerth ???Molex
 |  | J601 | 22-23-2021 | GPAD_SCH_LIB:22-23-2021 | Connector_Molex:Molex_KK-254_AE-6410-02A_1x02_P2.54mm_Vertical | https://media.digikey.com/pdf/Data%20Sheets/Molex%20PDFs/A-6373-N_Series_Dwg_2010-12-03.pdf | HAND | HAND | Connectors, Interconnects | 0.22 | https://media.digikey.com/pdf/Data%20Sheets/Molex%20PDFs/A-6373-N_Series_Dwg_2010-12-03.pdf | /product-detail/en/molex/22-23-2021/WM4200-ND/26667 | CONN HEADER VERT 2POS 2.54MM | WM4200-ND | DigiKey | 900-0022232021-ND |  |  | Rectangular Connectors - Headers, Male Pins | 22-23-2021 | Molex | Active
 |  | J602 | 22-23-2021 | GPAD_SCH_LIB:22-23-2021 | Connector_Molex:Molex_KK-254_AE-6410-02A_1x02_P2.54mm_Vertical | https://media.digikey.com/pdf/Data%20Sheets/Molex%20PDFs/A-6373-N_Series_Dwg_2010-12-03.pdf | HAND | HAND | Connectors, Interconnects | 0.22 | https://media.digikey.com/pdf/Data%20Sheets/Molex%20PDFs/A-6373-N_Series_Dwg_2010-12-03.pdf | /product-detail/en/molex/22-23-2021/WM4200-ND/26667 | CONN HEADER VERT 2POS 2.54MM | WM4200-ND | DigiKey | 900-0022232021-ND |  |  | Rectangular Connectors - Headers, Male Pins | 22-23-2021 | Molex | Active
 |  | MF101 | PCB_GPAD_VER2 | GPAD_SCH_LIB:PCB_GPAD_VER1 | NA | https://www.mcmaster.com/catalog/128/3306 |  | HAND |  | 1000000 |  |  | PCB for GPAD Version 1 |  | PublicInvention | PCB_GPAD_V1 |  |  |  | PCB_GPAD_V1
 |  | MF102 | ENCLOSURE_GPAD_VER1 | GPAD_SCH_LIB:ENCLOSURE_GPAD_VER1 |  | https://www.mcmaster.com/catalog/128/3306 |  |  |  | 1000000 |  |  |  |  | PublicInvention | ENCLOSURE_GPAD_VER1
 |  | MF401 | Screw_4-40_0.375_Phillips | GPAD_SCH_LIB:Screw_4-40_0.375_Phillips | NA | https://www.mcmaster.com/catalog/128/3306 |  | HAND |  | 0.0182 |  |  |  |  | McMaster-Carr | 90272A108
 |  | MF402 | Spacer_0.0182x0.125 inch | GPAD_SCH_LIB:Spacer_0.0182x0.125 inch | NA | https://www.mcmaster.com/catalog/128/3306 |  | HAND |  | 0.1145 |  |  |  |  | McMaster-Carr | 94639A702
 |  | MF403 | Nut_4-40_Lock,_External-Tooth | GPAD_SCH_LIB:Nut_4-40_Lock,_External-Tooth | NA | https://www.mcmaster.com/catalog/128/3306 |  | HAND |  | 0.0392 |  |  |  |  | McMaster-Carr | 93590A107
 |  | MF404 | Screw_4-40_0.375_Phillips | GPAD_SCH_LIB:Screw_4-40_0.375_Phillips | NA | https://www.mcmaster.com/catalog/128/3306 |  | HAND |  | 0.0182 |  |  |  |  | McMaster-Carr | 90272A108
 |  | MF405 | Spacer_0.0182x0.125 inch | GPAD_SCH_LIB:Spacer_0.0182x0.125 inch | NA | https://www.mcmaster.com/catalog/128/3306 |  | HAND |  | 0.1145 |  |  |  |  | McMaster-Carr | 94639A702
 |  | MF406 | Nut_4-40_Lock,_External-Tooth | GPAD_SCH_LIB:Nut_4-40_Lock,_External-Tooth | NA | https://www.mcmaster.com/catalog/128/3306 |  | HAND |  | 0.0392 |  |  |  |  | McMaster-Carr | 93590A107
 |  | MF407 | Screw_4-40_0.375_Phillips | GPAD_SCH_LIB:Screw_4-40_0.375_Phillips | NA | https://www.mcmaster.com/catalog/128/3306 |  | HAND |  | 0.0182 |  |  |  |  | McMaster-Carr | 90272A108
 |  | MF408 | Spacer_0.0182x0.125 inch | GPAD_SCH_LIB:Spacer_0.0182x0.125 inch | NA | https://www.mcmaster.com/catalog/128/3306 |  | HAND |  | 0.1145 |  |  |  |  | McMaster-Carr | 94639A702
 |  | MF409 | Nut_4-40_Lock,_External-Tooth | GPAD_SCH_LIB:Nut_4-40_Lock,_External-Tooth | NA | https://www.mcmaster.com/catalog/128/3306 |  | HAND |  | 0.0392 |  |  |  |  | McMaster-Carr | 93590A107
 |  | MF410 | Screw_4-40_0.375_Phillips | GPAD_SCH_LIB:Screw_4-40_0.375_Phillips | NA | https://www.mcmaster.com/catalog/128/3306 |  | HAND |  | 0.0182 |  |  |  |  | McMaster-Carr | 90272A108
 |  | MF411 | Spacer_0.0182x0.125 inch | GPAD_SCH_LIB:Spacer_0.0182x0.125 inch | NA | https://www.mcmaster.com/catalog/128/3306 |  | HAND |  | 0.1145 |  |  |  |  | McMaster-Carr | 94639A702
 |  | MF412 | Nut_4-40_Lock,_External-Tooth | GPAD_SCH_LIB:Nut_4-40_Lock,_External-Tooth | NA | https://www.mcmaster.com/catalog/128/3306 |  | HAND |  | 0.0392 |  |  |  |  | McMaster-Carr | 93590A107
 |  | Q201 | MMBT2222A-7-F | GPAD_SCH_LIB:MMBT2222A-7-F | Package_TO_SOT_SMD:SOT-23 | https://www.diodes.com/assets/Datasheets/ds30041.pdf |  | SMT | Discrete Semiconductor Products | 0.0475 | https://www.diodes.com/assets/Datasheets/ds30041.pdf | /product-detail/en/diodes-incorporated/MMBT2222A-7-F/MMBT2222A-FDICT-ND/815723 | TRANS NPN 40V 0.6A SMD SOT23-3 | MMBT2222A-FDICT-ND | JLCPCB | C94515 |  |  | Transistors - Bipolar (BJT) - Single | MMBT2222A-7-F | Diodes Incorporated | Active
 |  | Q202 | MMBT2222A-7-F | GPAD_SCH_LIB:MMBT2222A-7-F | Package_TO_SOT_SMD:SOT-23 | https://www.diodes.com/assets/Datasheets/ds30041.pdf |  | SMT | Discrete Semiconductor Products | 0.0475 | https://www.diodes.com/assets/Datasheets/ds30041.pdf | /product-detail/en/diodes-incorporated/MMBT2222A-7-F/MMBT2222A-FDICT-ND/815723 | TRANS NPN 40V 0.6A SMD SOT23-3 | MMBT2222A-FDICT-ND | JLCPCB | C94515 |  |  | Transistors - Bipolar (BJT) - Single | MMBT2222A-7-F | Diodes Incorporated | Active
 |  | Q203 | MMBT2222A-7-F | GPAD_SCH_LIB:MMBT2222A-7-F | Package_TO_SOT_SMD:SOT-23 | https://www.diodes.com/assets/Datasheets/ds30041.pdf |  | SMT | Discrete Semiconductor Products | 0.0475 | https://www.diodes.com/assets/Datasheets/ds30041.pdf | /product-detail/en/diodes-incorporated/MMBT2222A-7-F/MMBT2222A-FDICT-ND/815723 | TRANS NPN 40V 0.6A SMD SOT23-3 | MMBT2222A-FDICT-ND | JLCPCB | C94515 |  |  | Transistors - Bipolar (BJT) - Single | MMBT2222A-7-F | Diodes Incorporated | Active
 |  | Q204 | MMBT2222A-7-F | GPAD_SCH_LIB:MMBT2222A-7-F | Package_TO_SOT_SMD:SOT-23 | https://www.diodes.com/assets/Datasheets/ds30041.pdf |  | SMT | Discrete Semiconductor Products | 0.0475 | https://www.diodes.com/assets/Datasheets/ds30041.pdf | /product-detail/en/diodes-incorporated/MMBT2222A-7-F/MMBT2222A-FDICT-ND/815723 | TRANS NPN 40V 0.6A SMD SOT23-3 | MMBT2222A-FDICT-ND | JLCPCB | C94515 |  |  | Transistors - Bipolar (BJT) - Single | MMBT2222A-7-F | Diodes Incorporated | Active
 |  | Q205 | MMBT2222A-7-F | GPAD_SCH_LIB:MMBT2222A-7-F | Package_TO_SOT_SMD:SOT-23 | https://www.diodes.com/assets/Datasheets/ds30041.pdf |  | SMT | Discrete Semiconductor Products | 0.0475 | https://www.diodes.com/assets/Datasheets/ds30041.pdf | /product-detail/en/diodes-incorporated/MMBT2222A-7-F/MMBT2222A-FDICT-ND/815723 | TRANS NPN 40V 0.6A SMD SOT23-3 | MMBT2222A-FDICT-ND | JLCPCB | C94515 |  |  | Transistors - Bipolar (BJT) - Single | MMBT2222A-7-F | Diodes Incorporated | Active
 |  | Q301 | BSS138 | Transistor_FET:BSS138 | Package_TO_SOT_SMD:SOT-23 | https://www.onsemi.com/pub/Collateral/BSS138-D.PDF |  | SMT |  | 0.0196 |  |  | N-Channel Enhancement Mode Field Effect Transistor |  | JLCPCB | C400505 |  |  |  | BSS138 | Yangzhou Yangjie Electronic Technology Co., Ltd
 |  | Q601 | BSS138 | Transistor_FET:BSS138 | Package_TO_SOT_SMD:SOT-23 | https://www.onsemi.com/pub/Collateral/BSS138-D.PDF |  | SMT |  | 0.0196 |  |  | N-Channel Enhancement Mode Field Effect Transistor |  | JLCPCB | C400505 |  |  |  | BSS138 | Yangzhou Yangjie Electronic Technology Co., Ltd
 |  | Q602 | DNI | Device:Q_PNP_BEC | digikey-footprints:SOT-23-3 | ~ |  | SMT | Discrete Semiconductor Products | 0.0374 | http://www.onsemi.com/pub/Collateral/MMBT2907ALT1-D.PDF | /product-detail/en/on-semiconductor/MMBT2907ALT1G/MMBT2907ALT1GOSCT-ND/1139812 | TRANS PNP 60V 0.6A SOT23 | MMBT2907ALT1GOSCT-ND | DNI | DNI | JCLPCB | C40752 | Transistors - Bipolar (BJT) - Single | MMBT2907ALT1G | ON Semiconductor | Active
 |  | R101 | 1R0 | Device:R | Resistor_SMD:R_0603_1608Metric_Pad0.98x0.95mm_HandSolder | ~ |  | SMT |  | 0.0015 |  |  | 0.1W Â±5% 1Î© 0603 Chip Resistor - Surface Mount ROHS |  | JLCPCB | C269434 |  |  |  | RMC060315%N | TyoHM
 |  | R102 | 10K | Device:R | Resistor_SMD:R_0603_1608Metric_Pad0.98x0.95mm_HandSolder | ~ |  | SMT |  | 0.0015 |  |  | 0.1W Â±1% 10kÎ© 0603 Chip Resistor - Surface Mount ROHS |  | JLCPCB | C269701 |  |  |  | RMC 0603 10K F N | TyoHM
 |  | R103 | 1K | Device:R | Resistor_SMD:R_0603_1608Metric_Pad0.98x0.95mm_HandSolder | ~ |  | SMT |  | 0.0015 |  |  | 0.1W Â±1% 1kÎ© 0603 Chip Resistor - Surface Mount ROHS |  | JLCPCB | C269704 |  |  |  | RMC06031K1%N | TyoHM
 |  | R104 | 39R | Device:R | Resistor_SMD:R_0603_1608Metric_Pad0.98x0.95mm_HandSolder | ~ |  | SMT |  | 0.0015 |  |  | 0.1W Â±1% 39Î© 0603 Chip Resistor - Surface Mount ROHS |  | JLCPCB | C325713 |  |  |  | RMC0603391%N | TyoHM
 |  | R105 | 39R | Device:R | Resistor_SMD:R_0603_1608Metric_Pad0.98x0.95mm_HandSolder | ~ |  | SMT |  | 0.0015 |  |  | 0.1W Â±1% 39Î© 0603 Chip Resistor - Surface Mount ROHS |  | JLCPCB | C325713 |  |  |  | RMC0603391%N | TyoHM
 |  | R106 | DNI | Device:R | Resistor_SMD:R_0603_1608Metric_Pad0.98x0.95mm_HandSolder | ~ |  | SMT |  | 0.0015 |  |  | DNI |  | DNI | DNI |  |  |  | DNI | TyoHM
 |  | R107 | DNI | Device:R | Resistor_SMD:R_0603_1608Metric_Pad0.98x0.95mm_HandSolder | ~ |  | SMT |  | 0.0015 |  |  | DNI |  | DNI | DNI |  |  |  | DNI | TyoHM
 |  | R108 | 1K | Device:R | Resistor_SMD:R_0603_1608Metric_Pad0.98x0.95mm_HandSolder | ~ |  | SMT |  | 0.0015 |  |  | 0.1W Â±1% 1kÎ© 0603 Chip Resistor - Surface Mount ROHS |  | JLCPCB | C269704 |  |  |  | RMC06031K1%N | TyoHM
 |  | R109 | 1K | Device:R | Resistor_SMD:R_0603_1608Metric_Pad0.98x0.95mm_HandSolder | ~ |  | SMT |  | 0.0015 |  |  | 0.1W Â±1% 1kÎ© 0603 Chip Resistor - Surface Mount ROHS |  | JLCPCB | C269704 |  |  |  | RMC06031K1%N | TyoHM
 |  | R110 | 330R | Device:R | Resistor_SMD:R_0603_1608Metric_Pad0.98x0.95mm_HandSolder | ~ |  | SMT |  | 0.0015 |  |  | 0.1W Â±1% 330Î© 0603 Chip Resistor - Surface Mount ROHS |  | JLCPCB | C269711 |  |  |  | RMC06033301%N | TyoHM
 |  | R111 | 330R | Device:R | Resistor_SMD:R_0603_1608Metric_Pad0.98x0.95mm_HandSolder | ~ |  | SMT |  | 0.0015 |  |  | 0.1W Â±1% 330Î© 0603 Chip Resistor - Surface Mount ROHS |  | JLCPCB | C269711 |  |  |  | RMC06033301%N | TyoHM
 |  | R112 | 330R | Device:R | Resistor_SMD:R_0603_1608Metric_Pad0.98x0.95mm_HandSolder | ~ |  | SMT |  | 0.0015 |  |  | 0.1W Â±1% 330Î© 0603 Chip Resistor - Surface Mount ROHS |  | JLCPCB | C269711 |  |  |  | RMC06033301%N | TyoHM
 |  | R201 | 4K7 | Device:R | Resistor_SMD:R_0603_1608Metric_Pad0.98x0.95mm_HandSolder | ~ |  | SMT |  | 0.0015 |  |  | 1W Â±1% 4.7kÎ© 0603 Chip Resistor - Surface Mount ROHS |  | JLCPCB | C269713 |  |  |  | RMC 0603 4K7 F N | TyoHM
 |  | R202 | 330R | Device:R | Resistor_SMD:R_0603_1608Metric_Pad0.98x0.95mm_HandSolder | ~ |  | SMT |  | 0.0015 |  |  | 0.1W Â±1% 330Î© 0603 Chip Resistor - Surface Mount ROHS |  | JLCPCB | C269711 |  |  |  | RMC06033301%N | TyoHM
 |  | R203 | 4K7 | Device:R | Resistor_SMD:R_0603_1608Metric_Pad0.98x0.95mm_HandSolder | ~ |  | SMT |  | 0.0015 |  |  | 1W Â±1% 4.7kÎ© 0603 Chip Resistor - Surface Mount ROHS |  | JLCPCB | C269713 |  |  |  | RMC 0603 4K7 F N | TyoHM
 |  | R204 | 330R | Device:R | Resistor_SMD:R_0603_1608Metric_Pad0.98x0.95mm_HandSolder | ~ |  | SMT |  | 0.0015 |  |  | 0.1W Â±1% 330Î© 0603 Chip Resistor - Surface Mount ROHS |  | JLCPCB | C269711 |  |  |  | RMC06033301%N | TyoHM
 |  | R205 | 4K7 | Device:R | Resistor_SMD:R_0603_1608Metric_Pad0.98x0.95mm_HandSolder | ~ |  | SMT |  | 0.0015 |  |  | 1W Â±1% 4.7kÎ© 0603 Chip Resistor - Surface Mount ROHS |  | JLCPCB | C269713 |  |  |  | RMC 0603 4K7 F N | TyoHM
 |  | R206 | 330R | Device:R | Resistor_SMD:R_0603_1608Metric_Pad0.98x0.95mm_HandSolder | ~ |  | SMT |  | 0.0015 |  |  | 0.1W Â±1% 330Î© 0603 Chip Resistor - Surface Mount ROHS |  | JLCPCB | C269711 |  |  |  | RMC06033301%N | TyoHM
 |  | R207 | 4K7 | Device:R | Resistor_SMD:R_0603_1608Metric_Pad0.98x0.95mm_HandSolder | ~ |  | SMT |  | 0.0015 |  |  | 1W Â±1% 4.7kÎ© 0603 Chip Resistor - Surface Mount ROHS |  | JLCPCB | C269713 |  |  |  | RMC 0603 4K7 F N | TyoHM
 |  | R208 | 330R | Device:R | Resistor_SMD:R_0603_1608Metric_Pad0.98x0.95mm_HandSolder | ~ |  | SMT |  | 0.0015 |  |  | 0.1W Â±1% 330Î© 0603 Chip Resistor - Surface Mount ROHS |  | JLCPCB | C269711 |  |  |  | RMC06033301%N | TyoHM
 |  | R209 | 4K7 | Device:R | Resistor_SMD:R_0603_1608Metric_Pad0.98x0.95mm_HandSolder | ~ |  | SMT |  | 0.0015 |  |  | 1W Â±1% 4.7kÎ© 0603 Chip Resistor - Surface Mount ROHS |  | JLCPCB | C269713 |  |  |  | RMC 0603 4K7 F N | TyoHM
 |  | R210 | 330R | Device:R | Resistor_SMD:R_0603_1608Metric_Pad0.98x0.95mm_HandSolder | ~ |  | SMT |  | 0.0015 |  |  | 0.1W Â±1% 330Î© 0603 Chip Resistor - Surface Mount ROHS |  | JLCPCB | C269711 |  |  |  | RMC06033301%N | TyoHM
 |  | R301 | 4K7 | Device:R | Resistor_SMD:R_0603_1608Metric_Pad0.98x0.95mm_HandSolder | ~ |  | SMT |  | 0.0015 |  |  | 1W Â±1% 4.7kÎ© 0603 Chip Resistor - Surface Mount ROHS |  | JLCPCB | C269713 |  |  |  | RMC 0603 4K7 F N | TyoHM
 |  | R302 | 4K7 | Device:R | Resistor_SMD:R_0603_1608Metric_Pad0.98x0.95mm_HandSolder | ~ |  | SMT |  | 0.0015 |  |  | 1W Â±1% 4.7kÎ© 0603 Chip Resistor - Surface Mount ROHS |  | JLCPCB | C269713 |  |  |  | RMC 0603 4K7 F N | TyoHM
 |  | R303 | 4K7 | Device:R | Resistor_SMD:R_0603_1608Metric_Pad0.98x0.95mm_HandSolder | ~ |  | SMT |  | 0.0015 |  |  | 1W Â±1% 4.7kÎ© 0603 Chip Resistor - Surface Mount ROHS |  | JLCPCB | C269713 |  |  |  | RMC 0603 4K7 F N | TyoHM
 |  | R304 | 1K | Device:R | Resistor_SMD:R_0603_1608Metric_Pad0.98x0.95mm_HandSolder | ~ |  | SMT |  | 0.0015 |  |  | 0.1W Â±1% 1kÎ© 0603 Chip Resistor - Surface Mount ROHS |  | JLCPCB | C269704 |  |  |  | RMC06031K1%N | TyoHM
 |  | R305 | 1R0 | Device:R | Resistor_SMD:R_0603_1608Metric_Pad0.98x0.95mm_HandSolder | ~ |  | SMT |  | 0.0015 |  |  | 0.1W Â±5% 1Î© 0603 Chip Resistor - Surface Mount ROHS |  | JLCPCB | C269434 |  |  |  | RMC060315%N | TyoHM
 |  | R306 | DNI | Device:R | Resistor_SMD:R_0603_1608Metric_Pad0.98x0.95mm_HandSolder | ~ |  | SMT |  | 0.0015 |  |  | DNI |  | DNI | DNI |  |  |  | DNI | TyoHM
 |  | R307 | 1R0 | Device:R | Resistor_SMD:R_0603_1608Metric_Pad0.98x0.95mm_HandSolder | ~ |  | SMT |  | 0.0015 |  |  | 0.1W Â±5% 1Î© 0603 Chip Resistor - Surface Mount ROHS |  | JLCPCB | C269434 |  |  |  | RMC060315%N | TyoHM
 |  | R308 | DNI | Device:R | Resistor_SMD:R_0603_1608Metric_Pad0.98x0.95mm_HandSolder | ~ |  | SMT |  | 0.0015 |  |  | DNI |  | DNI | DNI |  |  |  | DNI | TyoHM
 |  | R309 | 1R0 | Device:R | Resistor_SMD:R_0603_1608Metric_Pad0.98x0.95mm_HandSolder | ~ |  | SMT |  | 0.0015 |  |  | 0.1W Â±5% 1Î© 0603 Chip Resistor - Surface Mount ROHS |  | JLCPCB | C269434 |  |  |  | RMC060315%N | TyoHM
 |  | R310 | 1R0 | Device:R | Resistor_SMD:R_0603_1608Metric_Pad0.98x0.95mm_HandSolder | ~ |  | SMT |  | 0.0015 |  |  | 0.1W Â±5% 1Î© 0603 Chip Resistor - Surface Mount ROHS |  | JLCPCB | C269434 |  |  |  | RMC060315%N | TyoHM
 |  | R311 | 4K7 | Device:R | Resistor_SMD:R_0603_1608Metric_Pad0.98x0.95mm_HandSolder | ~ |  | SMT |  | 0.0015 |  |  | 1W Â±1% 4.7kÎ© 0603 Chip Resistor - Surface Mount ROHS |  | JLCPCB | C269713 |  |  |  | RMC 0603 4K7 F N | TyoHM
 |  | R312 | 4K7 | Device:R | Resistor_SMD:R_0603_1608Metric_Pad0.98x0.95mm_HandSolder | ~ |  | SMT |  | 0.0015 |  |  | 1W Â±1% 4.7kÎ© 0603 Chip Resistor - Surface Mount ROHS |  | JLCPCB | C269713 |  |  |  | RMC 0603 4K7 F N | TyoHM
 |  | R401 | 330R | Device:R | Resistor_SMD:R_0603_1608Metric_Pad0.98x0.95mm_HandSolder | ~ |  | SMT |  | 0.0015 |  |  | 0.1W Â±1% 330Î© 0603 Chip Resistor - Surface Mount ROHS |  | JLCPCB | C269711 |  |  |  | RMC06033301%N | TyoHM
 |  | R402 | 330R | Device:R | Resistor_SMD:R_0603_1608Metric_Pad0.98x0.95mm_HandSolder | ~ |  | SMT |  | 0.0015 |  |  | 0.1W Â±1% 330Î© 0603 Chip Resistor - Surface Mount ROHS |  | JLCPCB | C269711 |  |  |  | RMC06033301%N | TyoHM
 |  | R403 | 330R | Device:R | Resistor_SMD:R_0603_1608Metric_Pad0.98x0.95mm_HandSolder | ~ |  | SMT |  | 0.0015 |  |  | 0.1W Â±1% 330Î© 0603 Chip Resistor - Surface Mount ROHS |  | JLCPCB | C269711 |  |  |  | RMC06033301%N | TyoHM
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

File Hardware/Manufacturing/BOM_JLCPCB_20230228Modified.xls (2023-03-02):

Comment | Designator | Footprint | JLCPCB Part #
39pF | C101, C104, C107, C113, C114 | Capacitor_SMD:C_0603_1608Metric_Pad1.08x0.95mm_HandSolder | C107049
47uF 16V | C102, C106, C109, C112, C302, C502, C601 | Capacitor_SMD:CP_Elec_5x5.4 | C2895272
100nF | C103, C105, C108, C110, C111, C301, C501, C503, C602 | Capacitor_SMD:C_0603_1608Metric_Pad1.08x0.95mm_HandSolder | C14663
Schottky 2A | D101, D103, D104 | Diode_SMD:D_SMB | C14996
RED 0603 | D102, D106 | LED_SMD:LED_0603_1608Metric_Pad1.05x0.95mm_HandSolder | C2286
RED 0603 | D501 | LED_SMD:LED_0603_1608Metric | C2286
Polyfuse_Small | F101, F401 | Fuse:Fuse_0603_1608Metric | C207017
Barrel_Jack_Switch_SMT | J101 | GeneralPurposeAlarmDevicePCB:BarrelJack_CLIFF_FC681465S_SMT_Horizontal | C319134
0.100_2Pin | J102, J103 | Connector_PinHeader_2.54mm:PinHeader_1x02_P2.54mm_Vertical | C168673
S04B-XASK-1(LF)(SN)Rev2 | J105 | GeneralPurposeAlarmDevicePCB:S04B-XASK-1(LF)(SN)Rev2 | C265097
RJ12_6P6C_HORZ | J401 | GeneralPurposeAlarmDevicePCB:RJ12_Amphenol_54601 | C305981
USB_B_Micro_Local | J501 | GeneralPurposeAlarmDevicePCB:USB_Micro-B_Amphenol_10118194_Horizontal | C132563
MMBT2222A-7-F | Q201, Q202, Q203, Q204, Q205 | Package_TO_SOT_SMD:SOT-23 | C94515
BSS138 | Q301, Q601 | Package_TO_SOT_SMD:SOT-23 | C400505
1R0 | R101, R305, R307, R309, R310 | Resistor_SMD:R_0603_1608Metric_Pad0.98x0.95mm_HandSolder | C269434
10K | R102, R505, R603 | Resistor_SMD:R_0603_1608Metric_Pad0.98x0.95mm_HandSolder | C269701
1K | R103, R108, R109, R304, R602 | Resistor_SMD:R_0603_1608Metric_Pad0.98x0.95mm_HandSolder | C269704
39R | R104, R105 | Resistor_SMD:R_0603_1608Metric_Pad0.98x0.95mm_HandSolder | C325713
330R | R110, R111, R112, R202, R204, R206, R208, R210, R401, R402, R403, R404, R501, R502, R503, R605 | Resistor_SMD:R_0603_1608Metric_Pad0.98x0.95mm_HandSolder | C269711
4K7 | R201, R203, R205, R207, R209, R301, R302, R303, R311, R312, R504 | Resistor_SMD:R_0603_1608Metric_Pad0.98x0.95mm_HandSolder | C269713
1R | R507, R508, R601 | Resistor_SMD:R_0603_1608Metric_Pad0.98x0.95mm_HandSolder | C269434
POT 0.375 10K | RV301 | GeneralPurposeAlarmDevicePCB:Potentiometer_Bourns_3386P_Vertical | C116281
SWITCH_TACTILE_SPST-NO_0.05A_24V | S101 | GeneralPurposeAlarmDevicePCB:Switch_Tactile_THT_6x6mm | C13828
SWITCH_TACTILE_12mmx12mm_SPST-NO_0.05A_24V | S601 | GeneralPurposeAlarmDevicePCB:SW_PUSH-12mm_WithCap_Green | C84931
LM7805_TO220 | U101 | Package_TO_SOT_THT:TO-220-3_Horizontal_TabDown | C2977083
PI_ATMEGA328P-AU-InOrder | U102 | Package_QFP:TQFP-32_7x7mm_P0.8mm | C14877
PCF8574AT_3_518 | U301 | Package_SO:SOIC-16W_7.5x10.3mm_P1.27mm | C86832
CH340E | U501 | Package_SO:MSOP-10_3x3mm_P0.5mm | C99652
16MHZ 20PF HC-49S/SMD | XTAL101 | Crystal:Crystal_SMD_HC49-SD | C111377

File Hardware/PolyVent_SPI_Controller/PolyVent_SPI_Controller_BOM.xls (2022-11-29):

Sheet: RAW
Source: | C:\Users\Public\Downloads\Arduino\PubInv\general-alarm-device\Hardware\PolyVent_SPI_Controller\PolyVent_SPI_Controller.kicad_sch
Date: | 11/29/2022 10:47:45 AM
Tool: | Eeschema (6.0.6)
Generator: | C:\Program Files\KiCad\6.0\bin\scripting\plugins/bom_csv_grouped_by_value.py
Component Count: | 70
Individual Components:
Item | Qty | Reference(s) | Value | LibPart | Footprint | Datasheet | Assembly Type | AssemblyType | Category | Cost | DK_Datasheet_Link | DK_Detail_Page | Description | Digi-Key_PN | Distributor 1 | Distributor 1 PN | Distributor 2 | Distributor 2 PN | Family | LongLead | MPN | Manufacturer | Status
 |  | C101 | 39PF | Device:C | Capacitor_SMD:C_0603_1608Metric_Pad1.08x0.95mm_HandSolder | https://datasheet.lcsc.com/lcsc/1811082118_YAGEO-CC0603JRNPO9BN390_C107049.pdf |  | SMT |  | 0.0025 |  |  | 50V 39pF NP0 Â±5% 0603 Multilayer Ceramic Ca |  | JLCPCB | C107049 |  |  |  | NO | CC0603JRNPO9BN390 | YAGEO
 |  | C102 | 39PF | Device:C | Capacitor_SMD:C_0603_1608Metric_Pad1.08x0.95mm_HandSolder | https://datasheet.lcsc.com/lcsc/1811082118_YAGEO-CC0603JRNPO9BN390_C107049.pdf |  | SMT |  | 0.0025 |  |  | 50V 39pF NP0 Â±5% 0603 Multilayer Ceramic Ca |  | JLCPCB | C107049 |  |  |  | NO | CC0603JRNPO9BN390 | YAGEO
 |  | C103 | 39PF | Device:C | Capacitor_SMD:C_0603_1608Metric_Pad1.08x0.95mm_HandSolder | https://datasheet.lcsc.com/lcsc/1811082118_YAGEO-CC0603JRNPO9BN390_C107049.pdf |  | SMT |  | 0.0025 |  |  | 50V 39pF NP0 Â±5% 0603 Multilayer Ceramic Ca |  | JLCPCB | C107049 |  |  |  | NO | CC0603JRNPO9BN390 | YAGEO
 |  | C104 | 39PF | Device:C | Capacitor_SMD:C_0603_1608Metric_Pad1.08x0.95mm_HandSolder | https://datasheet.lcsc.com/lcsc/1811082118_YAGEO-CC0603JRNPO9BN390_C107049.pdf |  | SMT |  | 0.0025 |  |  | 50V 39pF NP0 Â±5% 0603 Multilayer Ceramic Ca |  | JLCPCB | C107049 |  |  |  | NO | CC0603JRNPO9BN390 | YAGEO
 |  | C105 | 100NF | Device:C | Capacitor_SMD:C_0603_1608Metric_Pad1.08x0.95mm_HandSolder | https://datasheet.lcsc.com/lcsc/1809301912_YAGEO-CC0603KRX7R9BB104_C14663.pdf |  | SMT |  | 0.0021 |  |  | 50V 100nF X7R Â±10% 0603 Multilayer Ceramic C |  | JLCPCB | C14663 |  |  |  | NO | CC0603KRX7R9BB104 | YAGEO
 |  | C106 | 100NF | Device:C | Capacitor_SMD:C_0603_1608Metric_Pad1.08x0.95mm_HandSolder | https://datasheet.lcsc.com/lcsc/1809301912_YAGEO-CC0603KRX7R9BB104_C14663.pdf |  | SMT |  | 0.0021 |  |  | 50V 100nF X7R Â±10% 0603 Multilayer Ceramic C |  | JLCPCB | C14663 |  |  |  | NO | CC0603KRX7R9BB104 | YAGEO
 |  | C107 | 100NF | Device:C | Capacitor_SMD:C_0603_1608Metric_Pad1.08x0.95mm_HandSolder | https://datasheet.lcsc.com/lcsc/1809301912_YAGEO-CC0603KRX7R9BB104_C14663.pdf |  | SMT |  | 0.0021 |  |  | 50V 100nF X7R Â±10% 0603 Multilayer Ceramic C |  | JLCPCB | C14663 |  |  |  | NO | CC0603KRX7R9BB104 | YAGEO
 |  | C201 | 39PF | Device:C | Capacitor_SMD:C_0603_1608Metric_Pad1.08x0.95mm_HandSolder | https://datasheet.lcsc.com/lcsc/1811082118_YAGEO-CC0603JRNPO9BN390_C107049.pdf |  | SMT |  | 0.0025 |  |  | 50V 39pF NP0 Â±5% 0603 Multilayer Ceramic Ca |  | JLCPCB | C107049 |  |  |  | NO | CC0603JRNPO9BN390 | YAGEO
 |  | C202 | 39PF | Device:C | Capacitor_SMD:C_0603_1608Metric_Pad1.08x0.95mm_HandSolder | https://datasheet.lcsc.com/lcsc/1811082118_YAGEO-CC0603JRNPO9BN390_C107049.pdf |  | SMT |  | 0.0025 |  |  | 50V 39pF NP0 Â±5% 0603 Multilayer Ceramic Ca |  | JLCPCB | C107049 |  |  |  | NO | CC0603JRNPO9BN390 | YAGEO
 |  | D101 | RED 0603 | Device:LED | LED_SMD:LED_0603_1608Metric_Pad1.05x0.95mm_HandSolder | http://optoelectronics.liteon.com/upload/download/DS22-2000-109/LTST-C171KRKT.pdf |  | HAND | Optoelectronics | 0.0054 |  | /product-detail/en/lite-on-inc/LTST-C171KRKT/160-1427-1-ND/386800 | LED RED CLEAR SMD | 160-1427-1-ND | JLCPCB | C2286 |  |  | LED Indication - Discrete | NO | LTST-C171KRKT | Lite-On Inc. | Active
 |  | D102 | RED 0603 | Device:LED | LED_SMD:LED_0603_1608Metric_Pad1.05x0.95mm_HandSolder | http://optoelectronics.liteon.com/upload/download/DS22-2000-109/LTST-C171KRKT.pdf |  | HAND | Optoelectronics | 0.0054 |  | /product-detail/en/lite-on-inc/LTST-C171KRKT/160-1427-1-ND/386800 | LED RED CLEAR SMD | 160-1427-1-ND | JLCPCB | C2286 |  |  | LED Indication - Discrete | NO | LTST-C171KRKT | Lite-On Inc. | Active
 |  | D103 | RED 0603 | Device:LED | LED_SMD:LED_0603_1608Metric_Pad1.05x0.95mm_HandSolder | http://optoelectronics.liteon.com/upload/download/DS22-2000-109/LTST-C171KRKT.pdf |  | HAND | Optoelectronics | 0.0054 |  | /product-detail/en/lite-on-inc/LTST-C171KRKT/160-1427-1-ND/386800 | LED RED CLEAR SMD | 160-1427-1-ND | JLCPCB | C2286 |  |  | LED Indication - Discrete | NO | LTST-C171KRKT | Lite-On Inc. | Active
 |  | F101 | Polyfuse_Small | Device:Polyfuse_Small | Fuse:Fuse_0603_1608Metric | https://datasheet.lcsc.com/lcsc/1808072326_Littelfuse-0603L100SLYR_C207017.pdf |  | SMT |  | 0.2448 |  |  | 6V 1A 50A -40â„ƒ~+85â„ƒ 1.8A 40mÎ© 300ms 120mÎ© 0603 Resettable Fuses ROHS |  | JLCPCB | C207017 |  |  |  | NO | 0603L100SLYR | Littelfuse
 |  | F102 | Polyfuse_Small | Device:Polyfuse_Small | Fuse:Fuse_0603_1608Metric | https://datasheet.lcsc.com/lcsc/1808072326_Littelfuse-0603L100SLYR_C207017.pdf |  | SMT |  | 0.2448 |  |  | 6V 1A 50A -40â„ƒ~+85â„ƒ 1.8A 40mÎ© 300ms 120mÎ© 0603 Resettable Fuses ROHS |  | JLCPCB | C207017 |  |  |  | NO | 0603L100SLYR | Littelfuse
 |  | F103 | Polyfuse_Small | Device:Polyfuse_Small | Fuse:Fuse_0603_1608Metric | https://datasheet.lcsc.com/lcsc/1808072326_Littelfuse-0603L100SLYR_C207017.pdf |  | SMT |  | 0.2448 |  |  | 6V 1A 50A -40â„ƒ~+85â„ƒ 1.8A 40mÎ© 300ms 120mÎ© 0603 Resettable Fuses ROHS |  | JLCPCB | C207017 |  |  |  | NO | 0603L100SLYR | Littelfuse
 |  | J1 | Plug 48 Way | blank_card-eagle-import:09231486921 | PubInv_PCB:HARTING_09231486921 | https://www.mouser.com/datasheet/2/179/PDF_DS_09031200201_-2475060.pdf |  | HAND |  | 4.05 |  |  | Din 41612 PCB Connector, Plug, 48 Way |  | MOUSER | 617-09-23-148-6921 |  |  |  | YES | 9231486921 | HARTING
 |  | J102 | RJ12_6P6C_HORZ | GPAD_SCH_LIB:RJ12_6P6C_HORZ | PubInv_PCB:RJ12_Amphenol_54601 | https://datasheet.lcsc.com/lcsc/1811141146_TE-Connectivity-5555165-1_C305981.pdf |  | HAND |  | 0.8901 |  |  | Jack Modular Connector 6p6c (RJ11, RJ12, RJ14, RJ25) 90Â° Angle (Right) Unshielded Cat3 |  | JLCPCB | C305981 | Digikey | A31422-ND |  | YES | 5555165-1 | TE Connectivity
 |  | J103 | 0.100_2Pin | GPAD_SCH_LIB:22-23-2021 | Connector_PinHeader_2.54mm:PinHeader_1x02_P2.54mm_Vertical | https://datasheet.lcsc.com/lcsc/1811011511_Amphenol-ICC-68000-102HLF_C168673.pdf | HAND | HAND | Connectors, Interconnects | 0.1458 | https://media.digikey.com/pdf/Data%20Sheets/Molex%20PDFs/A-6373-N_Series_Dwg_2010-12-03.pdf | /product-detail/en/molex/22-23-2021/WM4200-ND/26667 | HEADER VERT 2POS 2.54MM | WM4200-ND | JLCPCB | C168673 |  |  | Rectangular Connectors - Headers, Male Pins | YES | 68000-102HLF | Amphenol ICC | Active
 |  | J201 | S04B-XASK-1(LF)(SN) | GPAD_SCH_LIB:S04B-XASK-1(LF)(SN) | PubInv_PCB:S04B-XASK-1(LF)(SN) | https://www.jst-mfg.com/product/pdf/eng/eXA1.pdf | HAND | HAND | Connectors, Interconnects | 0.1517 |  |  | CONN HEADER R/A 4POS 2.5MM | 455-4090-ND | JLCPCB | C265097 | DigiKey | 455-4090-ND | Rectangular Connectors - Headers, Male Pins, Side Entery | YES | S04B-XASK-1(LF)(SN) | JST Sales America | Active
 |  | J202 | 0.100_2Pin | GPAD_SCH_LIB:22-23-2021 | Connector_PinHeader_2.54mm:PinHeader_1x02_P2.54mm_Vertical | https://datasheet.lcsc.com/lcsc/1811011511_Amphenol-ICC-68000-102HLF_C168673.pdf | HAND | HAND | Connectors, Interconnects | 0.1458 | https://media.digikey.com/pdf/Data%20Sheets/Molex%20PDFs/A-6373-N_Series_Dwg_2010-12-03.pdf | /product-detail/en/molex/22-23-2021/WM4200-ND/26667 | HEADER VERT 2POS 2.54MM | WM4200-ND | JLCPCB | C168673 |  |  | Rectangular Connectors - Headers, Male Pins | YES | 68000-102HLF | Amphenol ICC | Active
 |  | MF101 | PCB_PolyVent_SPI_Controller_VER1 | GPAD_SCH_LIB:PCB_GPAD_VER1 | NA | https://github.com/PubInv/general-alarm-device/tree/main/Hardware/PolyVent_SPI_Controller |  | HAND |  | 1000000 |  |  | PCB for PolyVent_SPI_Controller Version 1 |  | JLCPCB | PCB_PolyVent_SPI_Controller_VER1 |  |  |  | YES | PCB_PolyVent_SPI_Controller_VER1 | PublicInvention
 |  | Q101 | BSS138 | :BSS138_1 | Package_TO_SOT_SMD:SOT-23 | https://www.onsemi.com/pub/Collateral/BSS138-D.PDF |  | SMT |  | 0.0196 |  |  | 50V 220mA 3.5Î©@10V,220mA 360mW 1.5V@1mA N Channel SOT-23 MOSFETs ROHS |  | JLCPCB | C400505 |  |  |  | NO | BSS138 | Yangzhou Yangjie Elec Tech
 |  | Q102 | BSS138 | :BSS138_1 | Package_TO_SOT_SMD:SOT-23 | https://www.onsemi.com/pub/Collateral/BSS138-D.PDF |  | SMT |  | 0.0196 |  |  | 50V 220mA 3.5Î©@10V,220mA 360mW 1.5V@1mA N Channel SOT-23 MOSFETs ROHS |  | JLCPCB | C400505 |  |  |  | NO | BSS138 | Yangzhou Yangjie Elec Tech
 |  | Q103 | BSS138 | :BSS138_1 | Package_TO_SOT_SMD:SOT-23 | https://www.onsemi.com/pub/Collateral/BSS138-D.PDF |  | SMT |  | 0.0196 |  |  | 50V 220mA 3.5Î©@10V,220mA 360mW 1.5V@1mA N Channel SOT-23 MOSFETs ROHS |  | JLCPCB | C400505 |  |  |  | NO | BSS138 | Yangzhou Yangjie Elec Tech
 |  | Q104 | BSS138 | :BSS138_1 | Package_TO_SOT_SMD:SOT-23 | https://www.onsemi.com/pub/Collateral/BSS138-D.PDF |  | SMT |  | 0.0196 |  |  | 50V 220mA 3.5Î©@10V,220mA 360mW 1.5V@1mA N Channel SOT-23 MOSFETs ROHS |  | JLCPCB | C400505 |  |  |  | NO | BSS138 | Yangzhou Yangjie Elec Tech
 |  | Q201 | BSS138 | :BSS138_1 | Package_TO_SOT_SMD:SOT-23 | https://www.onsemi.com/pub/Collateral/BSS138-D.PDF |  | SMT |  | 0.0196 |  |  | 50V 220mA 3.5Î©@10V,220mA 360mW 1.5V@1mA N Channel SOT-23 MOSFETs ROHS |  | JLCPCB | C400505 |  |  |  | NO | BSS138 | Yangzhou Yangjie Elec Tech
 |  | Q202 | BSS138 | :BSS138_1 | Package_TO_SOT_SMD:SOT-23 | https://www.onsemi.com/pub/Collateral/BSS138-D.PDF |  | SMT |  | 0.0196 |  |  | 50V 220mA 3.5Î©@10V,220mA 360mW 1.5V@1mA N Channel SOT-23 MOSFETs ROHS |  | JLCPCB | C400505 |  |  |  | NO | BSS138 | Yangzhou Yangjie Elec Tech
 |  | R101 | DNI | Device:R | Resistor_SMD:R_0603_1608Metric_Pad0.98x0.95mm_HandSolder | ~ |  | SMT |  | 0.0015 |  |  | Do Not Insert |  | NA | NA |  |  |  | NO
 |  | R102 | DNI | Device:R | Resistor_SMD:R_0603_1608Metric_Pad0.98x0.95mm_HandSolder | ~ |  | SMT |  | 0.0015 |  |  | Do Not Insert |  | NA | NA |  |  |  | NO
 |  | R103 | DNI | Device:R | Resistor_SMD:R_0603_1608Metric_Pad0.98x0.95mm_HandSolder | https://datasheet.lcsc.com/lcsc/1811101310_TyoHM-RMC06031K1-N_C269704.pdf |  | SMT |  | 0.0015 |  |  | 100mW Â±1% 1kÎ© 0603 Chip Resistor |  | JLCPCB | C269704 |  |  |  | NO | RMC06031K1%N | TyoHM
 |  | R104 | DNI | Device:R | Resistor_SMD:R_0603_1608Metric_Pad0.98x0.95mm_HandSolder | https://datasheet.lcsc.com/lcsc/1811101310_TyoHM-RMC06031K1-N_C269704.pdf |  | SMT |  | 0.0015 |  |  | 100mW Â±1% 1kÎ© 0603 Chip Resistor |  | JLCPCB | C269704 |  |  |  | NO | RMC06031K1%N | TyoHM
 |  | R105 | DNI | Device:R | Resistor_SMD:R_0603_1608Metric_Pad0.98x0.95mm_HandSolder | https://datasheet.lcsc.com/lcsc/1811101310_TyoHM-RMC06031K1-N_C269704.pdf |  | SMT |  | 0.0015 |  |  | 100mW Â±1% 1kÎ© 0603 Chip Resistor |  | JLCPCB | C269704 |  |  |  | NO | RMC06031K1%N | TyoHM
 |  | R106 | 1K | Device:R | Resistor_SMD:R_0603_1608Metric_Pad0.98x0.95mm_HandSolder | https://datasheet.lcsc.com/lcsc/1811101310_TyoHM-RMC06031K1-N_C269704.pdf |  | SMT |  | 0.0015 |  |  | 100mW Â±1% 1kÎ© 0603 Chip Resistor |  | JLCPCB | C269704 |  |  |  | NO | RMC06031K1%N | TyoHM
 |  | R107 | DNI | Device:R | Resistor_SMD:R_0603_1608Metric_Pad0.98x0.95mm_HandSolder | https://datasheet.lcsc.com/lcsc/1811101310_TyoHM-RMC06031K1-N_C269704.pdf |  | SMT |  | 0.0015 |  |  | 100mW Â±1% 1kÎ© 0603 Chip Resistor |  | JLCPCB | C269704 |  |  |  | NO | RMC06031K1%N | TyoHM
 |  | R108 | 10K | Device:R | Resistor_SMD:R_0603_1608Metric_Pad0.98x0.95mm_HandSolder | ~ |  | SMT |  | 0.0015 |  |  | 100mW Â±1% 10kÎ© 0603 Chip Resistor - Surface Mount ROHS |  | JLCPCB | C269701 |  |  |  | NO | RMC 0603 10K F N | TyoHM
 |  | R109 | 1K | Device:R | Resistor_SMD:R_0603_1608Metric_Pad0.98x0.95mm_HandSolder | https://datasheet.lcsc.com/lcsc/1811101310_TyoHM-RMC06031K1-N_C269704.pdf |  | SMT |  | 0.0015 |  |  | 100mW Â±1% 1kÎ© 0603 Chip Resistor |  | JLCPCB | C269704 |  |  |  | NO | RMC06031K1%N | TyoHM
 |  | R110 | 1K | Device:R | Resistor_SMD:R_0603_1608Metric_Pad0.98x0.95mm_HandSolder | https://datasheet.lcsc.com/lcsc/1811101310_TyoHM-RMC06031K1-N_C269704.pdf |  | SMT |  | 0.0015 |  |  | 100mW Â±1% 1kÎ© 0603 Chip Resistor |  | JLCPCB | C269704 |  |  |  | NO | RMC06031K1%N | TyoHM
 |  | R111 | DNI | Device:R | Resistor_SMD:R_0603_1608Metric_Pad0.98x0.95mm_HandSolder | https://datasheet.lcsc.com/lcsc/1811101310_TyoHM-RMC06031K1-N_C269704.pdf |  | SMT |  | 0.0015 |  |  | 100mW Â±1% 1kÎ© 0603 Chip Resistor |  | JLCPCB | C269704 |  |  |  | NO | RMC06031K1%N | TyoHM
 |  | R112 | 10K | Device:R | Resistor_SMD:R_0603_1608Metric_Pad0.98x0.95mm_HandSolder | ~ |  | SMT |  | 0.0015 |  |  | 100mW Â±1% 10kÎ© 0603 Chip Resistor - Surface Mount ROHS |  | JLCPCB | C269701 |  |  |  | NO | RMC 0603 10K F N | TyoHM
 |  | R113 | 1K | Device:R | Resistor_SMD:R_0603_1608Metric_Pad0.98x0.95mm_HandSolder | https://datasheet.lcsc.com/lcsc/1811101310_TyoHM-RMC06031K1-N_C269704.pdf |  | SMT |  | 0.0015 |  |  | 100mW Â±1% 1kÎ© 0603 Chip Resistor |  | JLCPCB | C269704 |  |  |  | NO | RMC06031K1%N | TyoHM
 |  | R114 | DNI | Device:R | Resistor_SMD:R_0603_1608Metric_Pad0.98x0.95mm_HandSolder | https://datasheet.lcsc.com/lcsc/1811101310_TyoHM-RMC06031K1-N_C269704.pdf |  | SMT |  | 0.0015 |  |  | 100mW Â±1% 1kÎ© 0603 Chip Resistor |  | JLCPCB | C269704 |  |  |  | NO | RMC06031K1%N | TyoHM
 |  | R115 | 10K | Device:R | Resistor_SMD:R_0603_1608Metric_Pad0.98x0.95mm_HandSolder | ~ |  | SMT |  | 0.0015 |  |  | 100mW Â±1% 10kÎ© 0603 Chip Resistor - Surface Mount ROHS |  | JLCPCB | C269701 |  |  |  | NO | RMC 0603 10K F N | TyoHM
 |  | R116 | 10K | Device:R | Resistor_SMD:R_0603_1608Metric_Pad0.98x0.95mm_HandSolder | ~ |  | SMT |  | 0.0015 |  |  | 100mW Â±1% 10kÎ© 0603 Chip Resistor - Surface Mount ROHS |  | JLCPCB | C269701 |  |  |  | NO | RMC 0603 10K F N | TyoHM
 |  | R117 | 1K | Device:R | Resistor_SMD:R_0603_1608Metric_Pad0.98x0.95mm_HandSolder | https://datasheet.lcsc.com/lcsc/1811101310_TyoHM-RMC06031K1-N_C269704.pdf |  | SMT |  | 0.0015 |  |  | 100mW Â±1% 1kÎ© 0603 Chip Resistor |  | JLCPCB | C269704 |  |  |  | NO | RMC06031K1%N | TyoHM
 |  | R118 | 1K | Device:R | Resistor_SMD:R_0603_1608Metric_Pad0.98x0.95mm_HandSolder | https://datasheet.lcsc.com/lcsc/1811101310_TyoHM-RMC06031K1-N_C269704.pdf |  | SMT |  | 0.0015 |  |  | 100mW Â±1% 1kÎ© 0603 Chip Resistor |  | JLCPCB | C269704 |  |  |  | NO | RMC06031K1%N | TyoHM
 |  | R119 | 1K | Device:R | Resistor_SMD:R_0603_1608Metric_Pad0.98x0.95mm_HandSolder | https://datasheet.lcsc.com/lcsc/1811101310_TyoHM-RMC06031K1-N_C269704.pdf |  | SMT |  | 0.0015 |  |  | 100mW Â±1% 1kÎ© 0603 Chip Resistor |  | JLCPCB | C269704 |  |  |  | NO | RMC06031K1%N | TyoHM
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

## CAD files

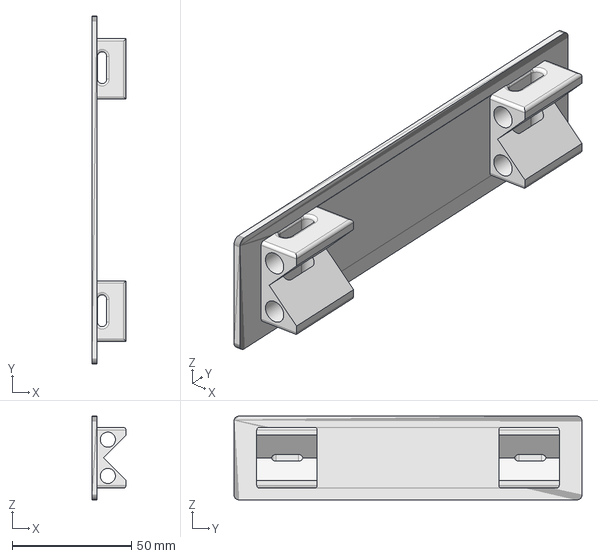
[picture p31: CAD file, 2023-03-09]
Hardware/Enclosure/BackPanel_Hanging.FCStd
14.3 x 146.1 x 35.1 mm

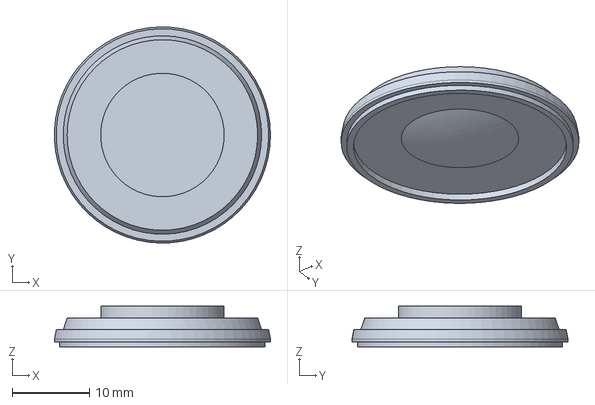
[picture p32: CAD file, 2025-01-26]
Hardware/Enclosure/Speaker2W/Speaker2W.FCStd
28.0 x 28.0 x 5.25 mm

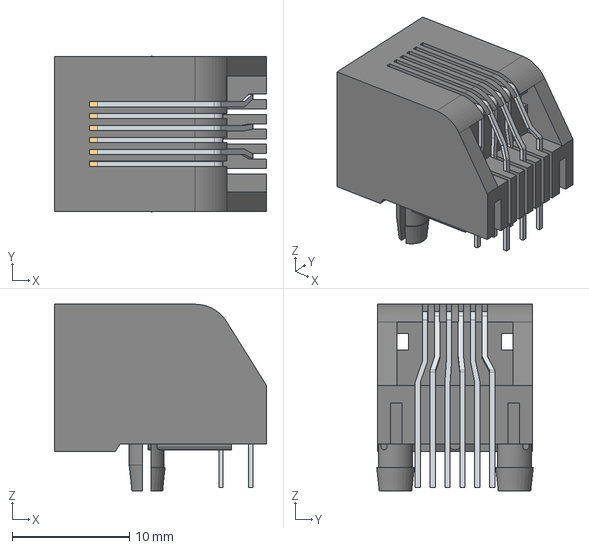
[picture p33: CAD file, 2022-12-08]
Hardware/GeneralPurposeAlarmDevicePCB/Parts/rj11-connectors-6p-1.snapshot.1/rj-6--horiz-tabdown-615006143621 (rev1).stp
18.1 x 13.4 x 15.9 mm

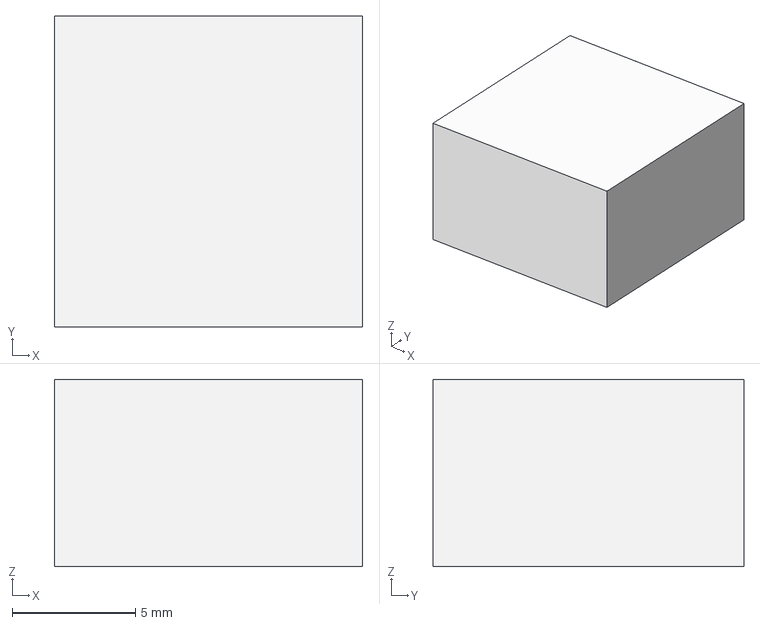
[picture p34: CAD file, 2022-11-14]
Hardware/GeneralPurposeAlarmDevicePCB/Parts/S04B-XASK-1/first/Cube.step
12.5 x 12.6 x 7.59 mm

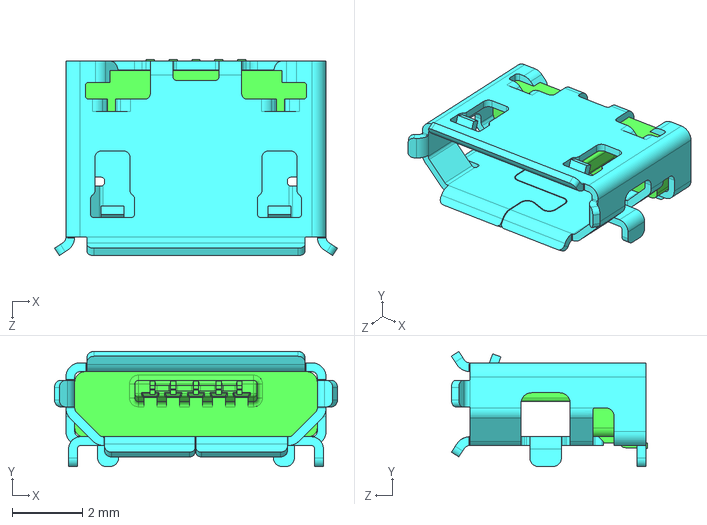
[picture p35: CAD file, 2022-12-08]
Hardware/GeneralPurposeAlarmDevicePCB/Parts/USB User Library-10118194.STEP
8.05 x 3.28 x 5.58 mm

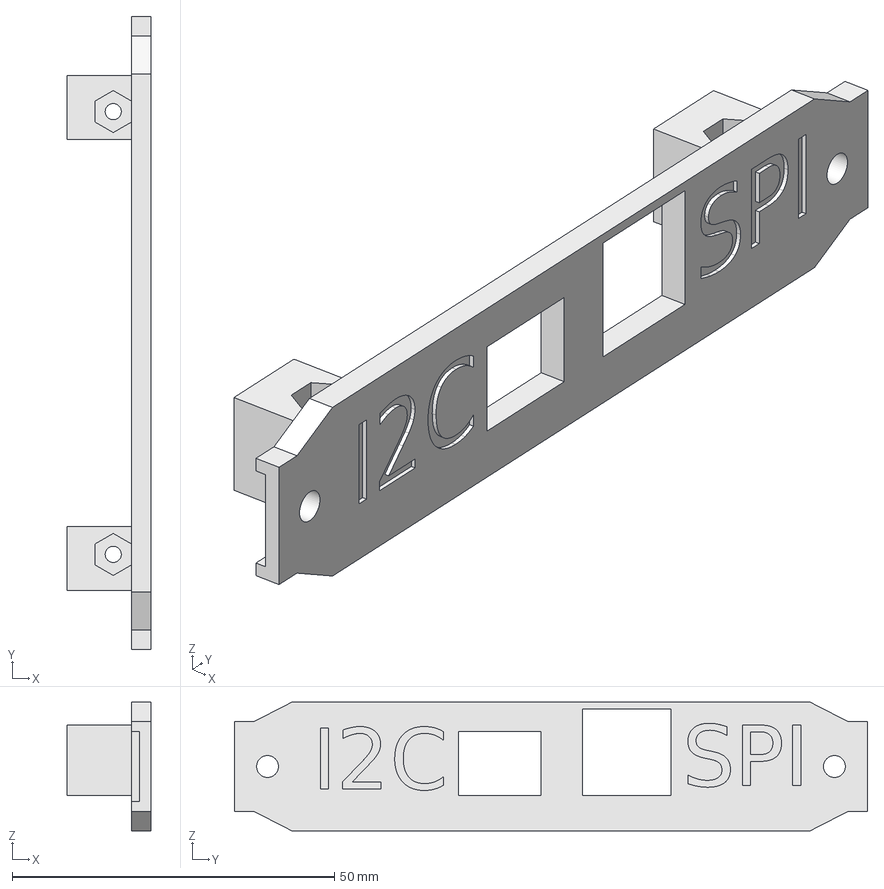
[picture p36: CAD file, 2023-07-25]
Hardware/PolyVent_SPI_Controller/CAD_model/FacePlate_FCNative_v1.FCStd
13.0 x 98.3 x 20.0 mm

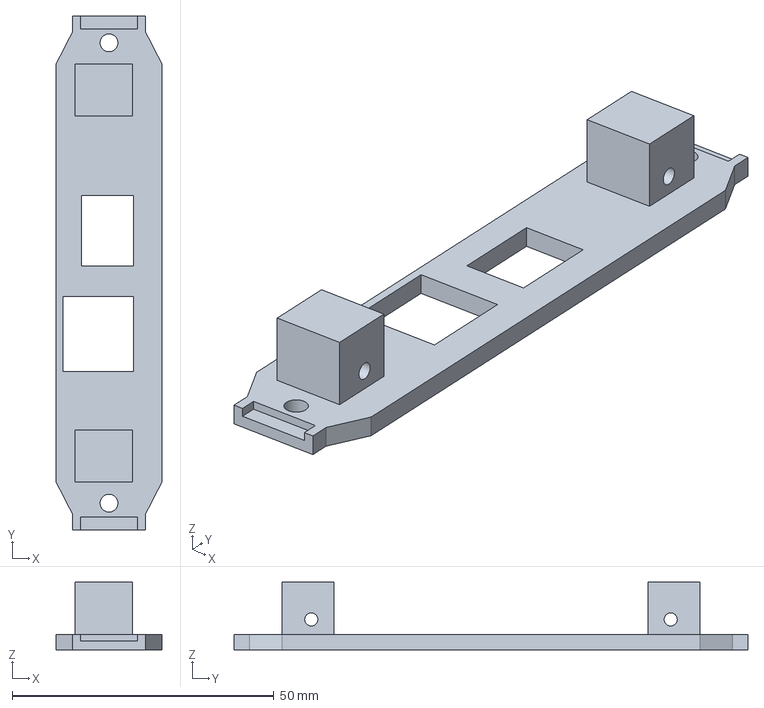
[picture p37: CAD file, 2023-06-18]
Hardware/PolyVent_SPI_Controller/CAD_model/Prusaslicer/DefaultSlicing.3mf
20.2 x 98.3 x 13.0 mm

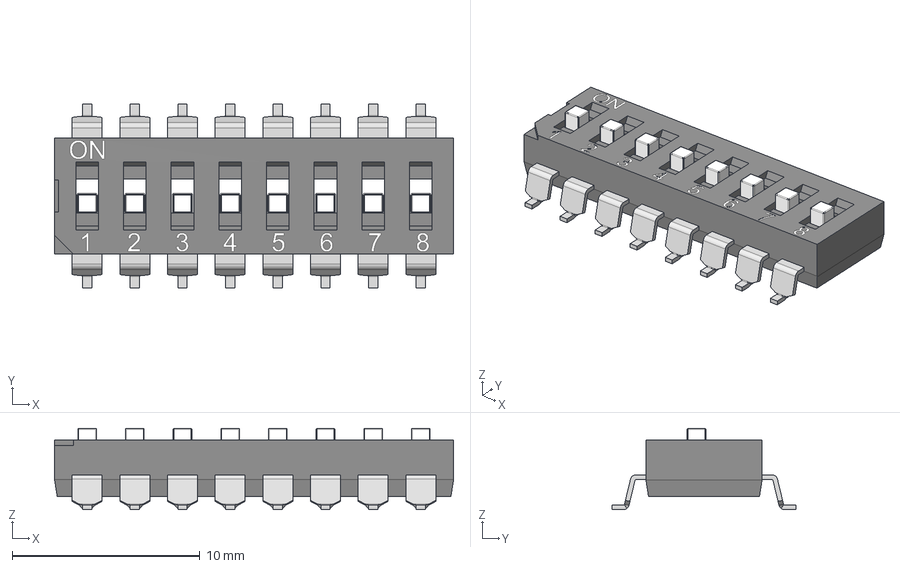
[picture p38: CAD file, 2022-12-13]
Hardware/PolyVent_SPI_Controller/Parts/3DModels/SMD DIP SWITCH 8P.step
21.3 x 9.80 x 4.32 mm

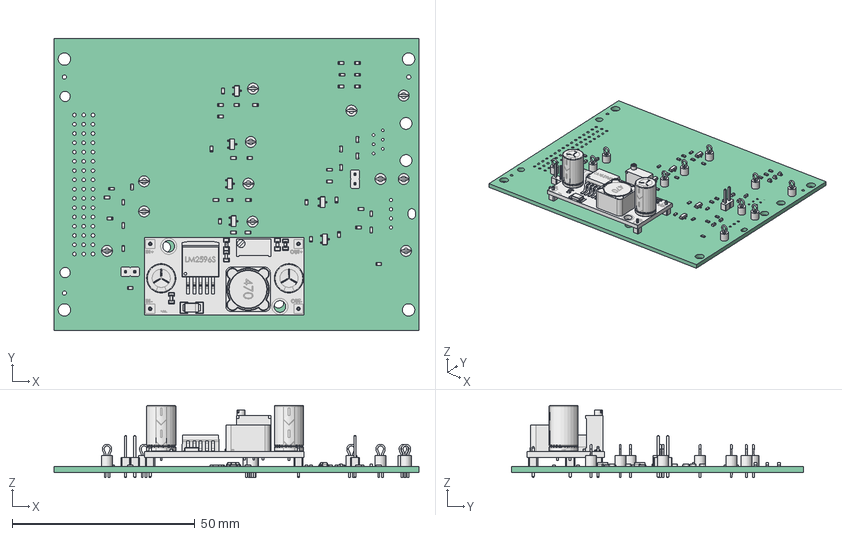
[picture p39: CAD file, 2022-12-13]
Hardware/PolyVent_SPI_Controller/PolyVent_SPI_Controller_FreeCAD.FCStd
100.0 x 80.0 x 19.8 mm
Pcb_b92b
R113_R_0603_1608Metric_375481a100d2 x 28
F103_Fuse_0603_1608Metric_acc948c9a6c3 x 3
TestPoint_Loop_D2_54mm_Drill1_5mm_Beaded_cp x 12
TestPoint_Loop_D2_54mm_Drill1_5mm_Beaded_cp001 x 12
D101_LED_0603_1608Metric_bc9d04248380 x 3
C202_C_0603_1608Metric_93a6a18d32bc x 9
Q102_SOT_23_961175d790bb x 6
J103_PinHeader_1x02_P254mm_Vertical_fd8e6863d4cd x 2
YAAJ_DCDC_StepDown_LM2596_PinHeaders_cp
YAAJ_DCDC_StepDown_LM2596_PinHeaders_cp001
YAAJ_DCDC_StepDown_LM2596_PinHeaders_cp002
YAAJ_DCDC_StepDown_LM2596_PinHeaders_cp003
YAAJ_DCDC_StepDown_LM2596_PinHeaders_cp004
YAAJ_DCDC_StepDown_LM2596_PinHeaders_cp005
YAAJ_DCDC_StepDown_LM2596_PinHeaders_cp006
YAAJ_DCDC_StepDown_LM2596_PinHeaders_cp007
YAAJ_DCDC_StepDown_LM2596_PinHeaders_cp008
YAAJ_DCDC_StepDown_LM2596_PinHeaders_cp009
YAAJ_DCDC_StepDown_LM2596_PinHeaders_cp010
YAAJ_DCDC_StepDown_LM2596_PinHeaders_cp011
YAAJ_DCDC_StepDown_LM2596_PinHeaders_cp012
YAAJ_DCDC_StepDown_LM2596_PinHeaders_cp013
YAAJ_DCDC_StepDown_LM2596_PinHeaders_cp014
YAAJ_DCDC_StepDown_LM2596_PinHeaders_cp015
YAAJ_DCDC_StepDown_LM2596_PinHeaders_cp016
YAAJ_DCDC_StepDown_LM2596_PinHeaders_cp017
YAAJ_DCDC_StepDown_LM2596_PinHeaders_cp018
YAAJ_DCDC_StepDown_LM2596_PinHeaders_cp019
YAAJ_DCDC_StepDown_LM2596_PinHeaders_cp020
YAAJ_DCDC_StepDown_LM2596_PinHeaders_cp021
YAAJ_DCDC_StepDown_LM2596_PinHeaders_cp022
YAAJ_DCDC_StepDown_LM2596_PinHeaders_cp023
YAAJ_DCDC_StepDown_LM2596_PinHeaders_cp024
YAAJ_DCDC_StepDown_LM2596_PinHeaders_cp025
YAAJ_DCDC_StepDown_LM2596_PinHeaders_cp026
YAAJ_DCDC_StepDown_LM2596_PinHeaders_cp027
YAAJ_DCDC_StepDown_LM2596_PinHeaders_cp028
YAAJ_DCDC_StepDown_LM2596_PinHeaders_cp029
YAAJ_DCDC_StepDown_LM2596_PinHeaders_cp030
YAAJ_DCDC_StepDown_LM2596_PinHeaders_cp031
YAAJ_DCDC_StepDown_LM2596_PinHeaders_cp032
YAAJ_DCDC_StepDown_LM2596_PinHeaders_cp033
YAAJ_DCDC_StepDown_LM2596_PinHeaders_cp034
YAAJ_DCDC_StepDown_LM2596_PinHeaders_cp035
YAAJ_DCDC_StepDown_LM2596_PinHeaders_cp036
YAAJ_DCDC_StepDown_LM2596_PinHeaders_cp037
YAAJ_DCDC_StepDown_LM2596_PinHeaders_cp038
YAAJ_DCDC_StepDown_LM2596_PinHeaders_cp039
YAAJ_DCDC_StepDown_LM2596_PinHeaders_cp040
YAAJ_DCDC_StepDown_LM2596_PinHeaders_cp041
YAAJ_DCDC_StepDown_LM2596_PinHeaders_cp042
YAAJ_DCDC_StepDown_LM2596_PinHeaders_cp043
YAAJ_DCDC_StepDown_LM2596_PinHeaders_cp044
YAAJ_DCDC_StepDown_LM2596_PinHeaders_cp045
YAAJ_DCDC_StepDown_LM2596_PinHeaders_cp046
YAAJ_DCDC_StepDown_LM2596_PinHeaders_cp047
YAAJ_DCDC_StepDown_LM2596_PinHeaders_cp048
YAAJ_DCDC_StepDown_LM2596_PinHeaders_cp049
YAAJ_DCDC_StepDown_LM2596_PinHeaders_cp050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

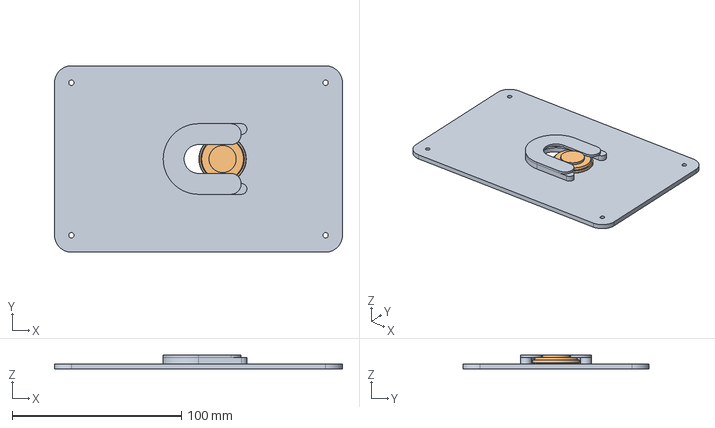
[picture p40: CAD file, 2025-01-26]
Hardware/Enclosure/Speaker2W/SpeakerBaffel150x90.FCStd
170.0 x 110.0 x 8.43 mm
BodySpeakerBaffel150x90
SpeakerOutline

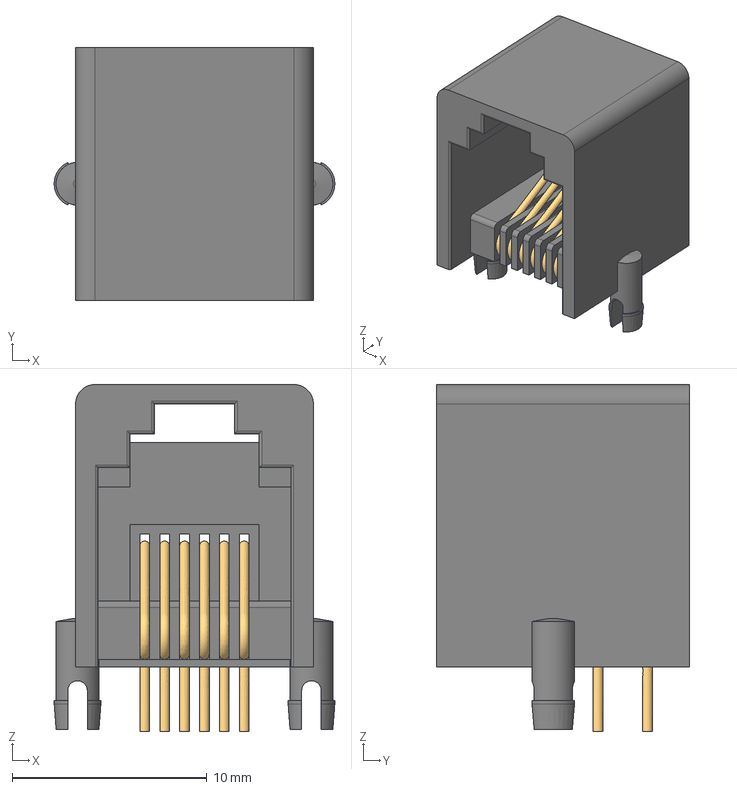
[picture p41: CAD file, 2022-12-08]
Hardware/GeneralPurposeAlarmDevicePCB/Parts/rj11-connectors-6p-1.snapshot.1/rj-69-horiz-615006138421 (rev1).stp
14.4 x 13.0 x 17.8 mm
615006138421_PIN x 3
615006138421_PIN_LONGUE x 3
6150xx138421

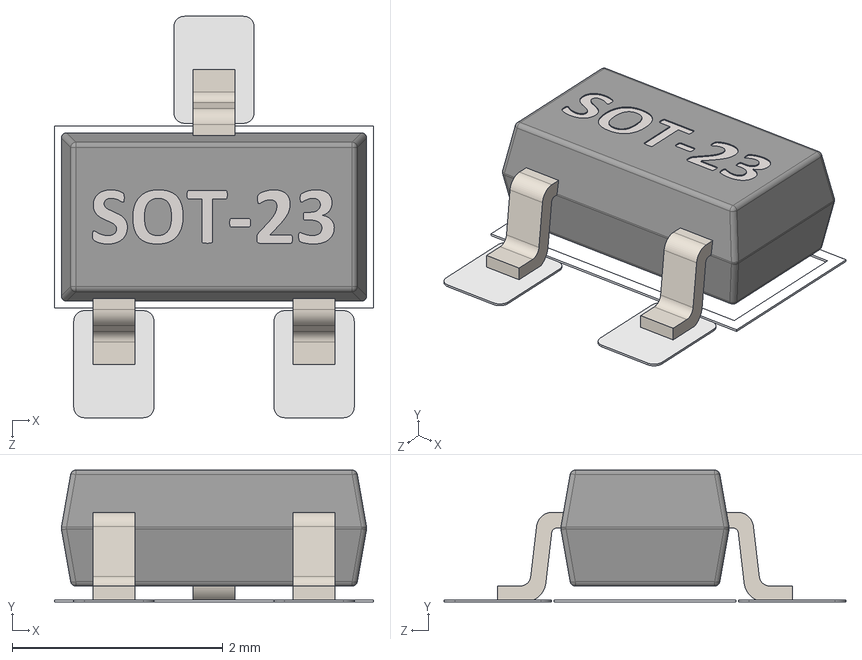
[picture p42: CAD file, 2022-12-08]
Hardware/GeneralPurposeAlarmDevicePCB/Parts/SOT23.STEP
3.03 x 1.25 x 3.81 mm

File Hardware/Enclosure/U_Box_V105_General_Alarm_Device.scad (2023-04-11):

/*//////////////////////////////////////////////////////////////////
              -    FB Aka Heartman/Hearty 2016     -                   
              -   http://heartygfx.blogspot.com    -                  
              -       OpenScad Parametric Box      -                     
              -         CC BY-NC 3.0 License       -                      
////////////////////////////////////////////////////////////////////                                                                                                             
12/02/2016 - Fixed minor bug 
28/02/2016 - Added holes ventilation option                    
09/03/2016 - Added PCB feet support, fixed the shell artefact on export mode. 

*/////////////////////////// - Info - //////////////////////////////

// All coordinates are starting as integrated circuit pins.
// From the top view :

//   CoordD           <---       CoordC
//                                 ^
//                                 ^
//                                 ^
//   CoordA           --->       CoordB


////////////////////////////////////////////////////////////////////


////////// - Paramètres de la boite - Box parameters - /////////////

/* [Box dimensions] */
// - Longueur - Length  
  Length        = 83.82+13;       
// - Largeur - Width
  Width         = 138+13;                     
// - Hauteur - Height  
  Height        = 40;  
// - Epaisseur - Wall thickness  
  Thick         = 2;//[2:5]  
  
/* [Box options] */
// - Diamètre Coin arrondi - Filet diameter  
  Filet         = 2;//[0.1:12] 
// - lissage de l'arrondi - Filet smoothness  
  Resolution    = 50;//[1:100] 
// - Tolérance - Tolerance (Panel/rails gap)
  m             = 0.9;
// Pieds PCB - PCB feet (x4) 
  PCBFeet       = 1;// [0:No, 1:Yes]
// - Decorations to ventilation holes
  Vent          = 1;// [0:No, 1:Yes]
// - Decoration-Holes width (in mm)
  Vent_width    = 1.5;   


  
/* [PCB_Feet] */
//All dimensions are from the center foot axis

// - Coin bas gauche - Low left corner X position
PCBPosX         = 0;
// - Coin bas gauche - Low left corner Y position
PCBPosY         = 0;
// - Longueur PCB - PCB Length
PCBLength       = 83.82;
// - Largeur PCB - PCB Width
PCBWidth        = 137.16;
// - Heuteur pied - Feet height
PCBThick        = 1.6;
// - Heuteur pied - Feet height
FootHeight      = 15;
// - Diamètre pied - Foot diameter
FootDia         = 7;
// - Diamètre trou - Hole diameter
FootHole        = 3.0;  
// - Coin bas gauche - Low left corner X position
FootPosX         = 5.08;
// - Coin bas gauche - Low left corner Y position
FootPosY         = 5.08;
  

/* [STL element to export] */
//Coque haut - Top shell
TShell          = 0;// [0:No, 1:Yes]
//Coque bas- Bottom shell
BShell          = 0;// [0:No, 1:Yes]
//Panneau avant - Front panel
FPanL           = 0;// [0:No, 1:Yes]
//Panneau arrière - Back panel  
BPanL           = 0;// [0:No, 1:Yes]
//Buttons
BButton         = 0;
//show pcb
PCB_View        = 0;
LED_Standoff    = 0;
LED_Standoff_Single    = 1; 
/* [Hidden] */
// - Couleur coque - Shell color  
Couleur1        = "Orange";       
// - Couleur panneaux - Panels color    
Couleur2        = "OrangeRed";    
// Thick X 2 - making decorations thicker if it is a vent to make sure they go through shell
Dec_Thick       = Vent ? Thick*2 : Thick; 
// - Depth decoration
Dec_size        = Vent ? Thick*2 : 0.8;





/////////// - Boitier générique bord arrondis - Generic rounded box - //////////

module RoundBox($a=Length, $b=Width, $c=Height){// Cube bords arrondis
                    $fn=Resolution;            
                    translate([0,Filet,Filet]){  
                    minkowski (){                                              
                        cube ([$a-(Length/2),$b-(2*Filet),$c-(2*Filet)], center = false);
                        rotate([0,90,0]){    
                        cylinder(r=Filet,h=Length/2, center = false);
                            } 
                        }
                    }
                }// End of RoundBox Module

      
////////////////////////////////// - Module Coque/Shell - //////////////////////////////////         

module Coque(){//Coque - Shell  
    Thick = Thick*2;  
    difference(){    
        difference(){//sides decoration
            union(){    
                     difference() {//soustraction de la forme centrale - Substraction Fileted box
                      
                        difference(){//soustraction cube median - Median cube slicer
                            union() {//union               
                            difference(){//Coque    
                                RoundBox();
                                translate([Thick/2,Thick/2,Thick/2]){     
                                        RoundBox($a=Length-Thick, $b=Width-Thick, $c=Height-Thick);
                                        }
                                        }//Fin diff Coque                            
                                difference(){//largeur Rails        
                                     translate([Thick+m,Thick/2,Thick/2]){// Rails
                                          RoundBox($a=Length-((2*Thick)+(2*m)), $b=Width-Thick, $c=Height-(Thick*2));
                                                          }//fin Rails
                                     translate([((Thick+m/2)*1.55),Thick/2,Thick/2+0.1]){ // +0.1 added to avoid the artefact
                                          RoundBox($a=Length-((Thick*3)+2*m), $b=Width-Thick, $c=Height-Thick);
                                                    }           
                                                }//Fin largeur Rails
                                    }//Fin union                                   
                               translate([-Thick,-Thick,Height/2]){// Cube à soustraire
                                    cube ([Length+100, Width+100, Height], center=false);
                                            }                                            
                                      }//fin soustraction cube median - End Median cube slicer
                               translate([-Thick/2,Thick,Thick]){// Forme de soustraction centrale 
                                    RoundBox($a=Length+Thick, $b=Width-Thick*2, $c=Height-Thick);       
                                    }                          
                                }                                          


                difference(){// wall fixation box legs
                    union(){
                        translate([3*Thick +5,Thick,Height/2]){
                            rotate([90,0,0]){
                                    $fn=6;
                                    cylinder(d=16,Thick/2);
                                    }   
                            }
                            
                       translate([Length-((3*Thick)+5),Thick,Height/2]){
                            rotate([90,0,0]){
                                    $fn=6;
                                    cylinder(d=16,Thick/2);
                                    }   
                            }

                        }
                            translate([4,Thick+Filet,Height/2-57]){   
                             rotate([45,0,0]){
                                   cube([Length,40,40]);    
                                  }
                           }
                           translate([0,-(Thick*1.46),Height/2]){
                                cube([Length,Thick*2,10]);
                           }
                    } //Fin fixation box legs
            }

        union(){// outbox sides decorations
            
            for(i=[0:Thick:Length/4]){

                // Ventilation holes part code submitted by Ettie - Thanks ;) 
                    translate([10+i,-Dec_Thick+Dec_size,1]){
                    cube([Vent_width,Dec_Thick,Height/4]);
                    }
                    translate([(Length-10) - i,-Dec_Thick+Dec_size,1]){
                    cube([Vent_width,Dec_Thick,Height/4]);
                    }
                    translate([(Length-10) - i,Width-Dec_size,1]){
                    cube([Vent_width,Dec_Thick,Height/4]);
                    }
                    translate([10+i,Width-Dec_size,1]){
                    cube([Vent_width,Dec_Thick,Height/4]);
                    }
  
                
                    }// fin de for
               // }
                }//fin union decoration
            }//fin difference decoration
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

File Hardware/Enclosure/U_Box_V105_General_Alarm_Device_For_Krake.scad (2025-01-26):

/*//////////////////////////////////////////////////////////////////
              -    FB Aka Heartman/Hearty 2016     -                   
              -   http://heartygfx.blogspot.com    -                  
              -       OpenScad Parametric Box      -                     
              -         CC BY-NC 3.0 License       -                      
////////////////////////////////////////////////////////////////////                                                                                                             
12/02/2016 - Fixed minor bug 
28/02/2016 - Added holes ventilation option                    
09/03/2016 - Added PCB feet support, fixed the shell artefact on export mode. 

*/////////////////////////// - Info - //////////////////////////////

// All coordinates are starting as integrated circuit pins.
// From the top view :

//   CoordD           <---       CoordC
//                                 ^
//                                 ^
//                                 ^
//   CoordA           --->       CoordB


////////////////////////////////////////////////////////////////////


////////// - Paramètres de la boite - Box parameters - /////////////

/* [Box dimensions] */
// - Longueur - Length  
  Length        = 83.82+13;       
// - Largeur - Width
  Width         = 138+13;                     
// - Hauteur - Height  
  Height        = 40;  
// - Epaisseur - Wall thickness  
  Thick         = 2;//[2:5]  
  
/* [Box options] */
// - Diamètre Coin arrondi - Filet diameter  
  Filet         = 2;//[0.1:12] 
// - lissage de l'arrondi - Filet smoothness  
  Resolution    = 50;//[1:100] 
// - Tolérance - Tolerance (Panel/rails gap)
  m             = 0.9;
// Pieds PCB - PCB feet (x4) 
  PCBFeet       = 1;// [0:No, 1:Yes]
// - Decorations to ventilation holes
  Vent          = 1;// [0:No, 1:Yes]
// - Decoration-Holes width (in mm)
  Vent_width    = 1.5;   


  
/* [PCB_Feet] */
//All dimensions are from the center foot axis

// - Coin bas gauche - Low left corner X position
PCBPosX         = 0;
// - Coin bas gauche - Low left corner Y position
PCBPosY         = 0;
// - Longueur PCB - PCB Length
PCBLength       = 83.82;
// - Largeur PCB - PCB Width
PCBWidth        = 137.16;
// - Heuteur pied - Feet height
PCBThick        = 1.6;
// - Heuteur pied - Feet height
FootHeight      = 15;
// - Diamètre pied - Foot diameter
FootDia         = 7;
// - Diamètre trou - Hole diameter
FootHole        = 3.0;  
// - Coin bas gauche - Low left corner X position
FootPosX         = 5.08;
// - Coin bas gauche - Low left corner Y position
FootPosY         = 5.08;
  

/* [STL element to export] */
//Coque haut - Top shell
TShell          = 0;// [0:No, 1:Yes]
//Coque bas- Bottom shell
BShell          = 0;// [0:No, 1:Yes]
//Panneau avant - Front panel
FPanL           = 0;// [0:No, 1:Yes]
//Panneau arrière - Back panel  
BPanL           = 0;// [0:No, 1:Yes]
//Buttons
BButton         = 0;
//show pcb
PCB_View        = 0;
LED_Standoff    = 0;
LED_Standoff_Single    = 1; 
/* [Hidden] */
// - Couleur coque - Shell color  
Couleur1        = "Orange";       
// - Couleur panneaux - Panels color    
Couleur2        = "OrangeRed";    
// Thick X 2 - making decorations thicker if it is a vent to make sure they go through shell
Dec_Thick       = Vent ? Thick*2 : Thick; 
// - Depth decoration
Dec_size        = Vent ? Thick*2 : 0.8;





/////////// - Boitier générique bord arrondis - Generic rounded box - //////////

module RoundBox($a=Length, $b=Width, $c=Height){// Cube bords arrondis
                    $fn=Resolution;            
                    translate([0,Filet,Filet]){  
                    minkowski (){                                              
                        cube ([$a-(Length/2),$b-(2*Filet),$c-(2*Filet)], center = false);
                        rotate([0,90,0]){    
                        cylinder(r=Filet,h=Length/2, center = false);
                            } 
                        }
                    }
                }// End of RoundBox Module

      
////////////////////////////////// - Module Coque/Shell - //////////////////////////////////         

module Coque(){//Coque - Shell  
    Thick = Thick*2;  
    difference(){    
        difference(){//sides decoration
            union(){    
                     difference() {//soustraction de la forme centrale - Substraction Fileted box
                      
                        difference(){//soustraction cube median - Median cube slicer
                            union() {//union               
                            difference(){//Coque    
                                RoundBox();
                                translate([Thick/2,Thick/2,Thick/2]){     
                                        RoundBox($a=Length-Thick, $b=Width-Thick, $c=Height-Thick);
                                        }
                                        }//Fin diff Coque                            
                                difference(){//largeur Rails        
                                     translate([Thick+m,Thick/2,Thick/2]){// Rails
                                          RoundBox($a=Length-((2*Thick)+(2*m)), $b=Width-Thick, $c=Height-(Thick*2));
                                                          }//fin Rails
                                     translate([((Thick+m/2)*1.55),Thick/2,Thick/2+0.1]){ // +0.1 added to avoid the artefact
                                          RoundBox($a=Length-((Thick*3)+2*m), $b=Width-Thick, $c=Height-Thick);
                                                    }           
                                                }//Fin largeur Rails
                                    }//Fin union                                   
                               translate([-Thick,-Thick,Height/2]){// Cube à soustraire
                                    cube ([Length+100, Width+100, Height], center=false);
                                            }                                            
                                      }//fin soustraction cube median - End Median cube slicer
                               translate([-Thick/2,Thick,Thick]){// Forme de soustraction centrale 
                                    RoundBox($a=Length+Thick, $b=Width-Thick*2, $c=Height-Thick);       
                                    }                          
                                }                                          


                difference(){// wall fixation box legs
                    union(){
                        translate([3*Thick +5,Thick,Height/2]){
                            rotate([90,0,0]){
                                    $fn=6;
                                    cylinder(d=16,Thick/2);
                                    }   
                            }
                            
                       translate([Length-((3*Thick)+5),Thick,Height/2]){
                            rotate([90,0,0]){
                                    $fn=6;
                                    cylinder(d=16,Thick/2);
                                    }   
                            }

                        }
                            translate([4,Thick+Filet,Height/2-57]){   
                             rotate([45,0,0]){
                                   cube([Length,40,40]);    
                                  }
                           }
                           translate([0,-(Thick*1.46),Height/2]){
                                cube([Length,Thick*2,10]);
                           }
                    } //Fin fixation box legs
            }

        union(){// outbox sides decorations
            
            for(i=[0:Thick:Length/4]){

                // Ventilation holes part code submitted by Ettie - Thanks ;) 
                    translate([10+i,-Dec_Thick+Dec_size,1]){
                    cube([Vent_width,Dec_Thick,Height/4]);
                    }
                    translate([(Length-10) - i,-Dec_Thick+Dec_size,1]){
                    cube([Vent_width,Dec_Thick,Height/4]);
                    }
                    translate([(Length-10) - i,Width-Dec_size,1]){
                    cube([Vent_width,Dec_Thick,Height/4]);
                    }
                    translate([10+i,Width-Dec_size,1]){
                    cube([Vent_width,Dec_Thick,Height/4]);
                    }
  
                
                    }// fin de for
               // }
                }//fin union decoration
            }//fin difference decoration
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

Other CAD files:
Hardware/GeneralPurposeAlarmDevicePCB/Parts/LogoPI/LogoFreeCAD.FCStd
Hardware/GeneralPurposeAlarmDevicePCB/Parts/S04B-XASK-1/S04B-XASK-1.FCStd
Hardware/Enclosure/BackPanel_Hanging-CompoundV2.stl
Hardware/GeneralPurposeAlarmDevicePCB/Parts/S04B-XASK-1/Cube.step
Hardware/PolyVent_SPI_Controller/CAD_model/PolyVent_SPI_Controller-blank faceplate v9.step
Hardware/Enclosure/BackPanel_Hanging-Compound.step
Hardware/Enclosure/BackPanel_Hanging-Compound.stl
Hardware/Enclosure/BackPanel_Hanging-U_Box_V104_General_Alarm_Device_Backpanel.stl
Hardware/Enclosure/General Alarm Device Enclosure-U_Box_V104_General_Alarm_Device001.stl
Hardware/Enclosure/General Alarm Device Enclosure.FCStd
Hardware/Enclosure/GeneralPurposeAlarmDevicePCB.step
Hardware/Enclosure/LED_Standoff_V104.FCStd
Hardware/Enclosure/Speaker2W/Speaker2W-SpeakerOutline.step
Hardware/Enclosure/Speaker2W/Speaker2W-SpeakerOutline.stl
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

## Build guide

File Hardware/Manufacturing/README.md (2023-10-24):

## File descriprions  
These files used for the GPAD Version 2 PCB and PCBA build in spring of 2023.
They were derived from the KiCad BOM report in the schematic.
The file GPAD_V2_BOM.xls at ..\GeneralPurposeAlarmDevicePCB is the root from which the BOMs were made.

### Files used for the JLCPCB Assembly Order 
Files generate from KiCAD wre modified by JLCPCB to fit their formating requirements.
BOM_JLCPCB_20230228Modified.xls
GeneralPurposeAlarmDevicePCB-Placement20230228Modified.xls

### Files Used For The Order of Additional Parts  
Some LCDs were left over from the V1 build and were ordered from Amazon and from Digikey.  

### Other
See ..\Enclosure for information the enclosure files.

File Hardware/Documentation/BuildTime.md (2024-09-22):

 As Built in Maryville TN by Lee

Unless noted, this time does not include setup

## Soldering LCD Display Headers
**Nine displays took 26 minuets** 

Assemble LCD to PCBs.
**Nine units took 65 minuets.**

## Assemble Components to PCB
Put Reset button, S101 into PCB from display side.
Put Mute button, S401 into PCB from display side.
Put Contrast pot, RV301 into PCB from display side. Bending leads may help retain.
**Nine units took 33 minuets.**

Put Buzzer, BZ601 into PCB from display side. Bending leads may help retain.
Solder on Assembly test fixture. Solder one lead and hole buzzer to the PCB while solder cools. Solder second lead.
**Nine units took 23 minuets.**

Put Red and white LEDs with spacers. 
**Nine units took 66 minuets.**

## Electrical Test, Bootloader and Firmware loading

Partional progress
All electrical tests and bootloader burn.  Haveing to stop to reboot computer to try to regain control of COM port.
**Nine units took 100 minuets.**  

Finish electrical test and firmware loading except for failure on DUT SN24.
**Nine units took 41 minuets.**

## Total Built time:
**Nine units took 354 minuets.**
This is just about 40 minuets per device.

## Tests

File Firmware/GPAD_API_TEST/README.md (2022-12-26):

# GPAD API TEST 1

## Summary
This is folder contains files to test the GPAD_API through the serial port using a terminal program.
Example, the text file, GPAD_API_TEST_1.txt is sent by RealTerm to the device under test, DUT.

## Test Files
File names and descriptions.
* GPAD_API_TEST_1.CRLF.txt  This file has CR and LF end terminations.
* GPAD_API_TEST_2.CRLF.txt Similar to GPAD_API_TEST_1 but with messages added. This file has CR and LF end terminations.
* GPAD_API_TEST_2LFOnly.LF.txt Similar to GPAD_API_TEST_1 but with messages added. This file has LF end terminations.
* GPAD_API_TEST_3LF_Only.LF.txt This file has help command and only Alarms with messages and only LF end terminations.
* GPAD_API_TEST_ALPHANUM1.LF.txt This file has upper case, lower case and numeric test characters `~!@#$%^&*()-_=+.[]{}\|;:'",<.>/?
* GPAD_API_TEST_LONGLINE.LF.txt This file has very long line of alphanumeric text.

## Cases of Using RealTerm and XVII32
RealTerm is set up for a 4000 mSecond end of line delay.
RealTerm is set up for to repeat endlessly by setting the number of repeats to zero.  

**Note:** in the RealTerm, Port setup tab you must select with the Open button and press Change button after changes. Using RealTerm on a DUT will conflict with the Arduino IDE on the same DUT. To program with the Arduino IDE, you must un Open the port and press Change to release the port for the Arduino IDE.

Screen shot showing the RealTerm setup and typical serial traffic.
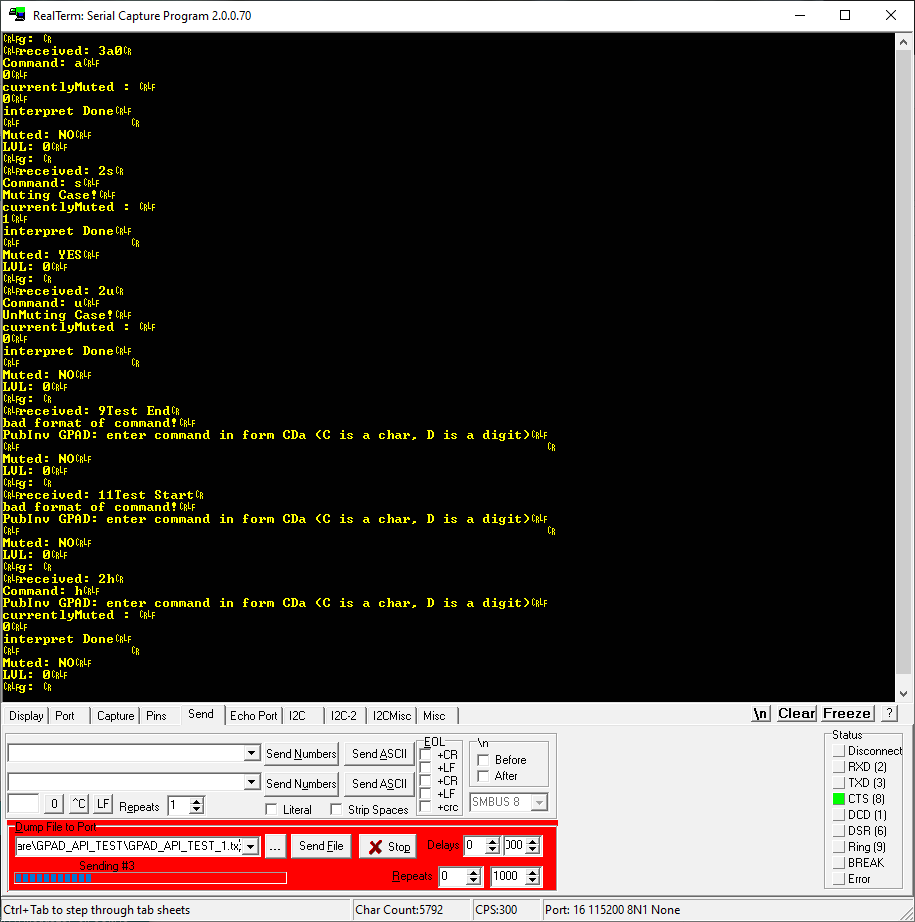
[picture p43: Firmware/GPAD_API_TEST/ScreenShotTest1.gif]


Lee used the very helpful program **XVI32** to review and edit the files with the desired line terminations.  
Example of file in **XVI32** in action.
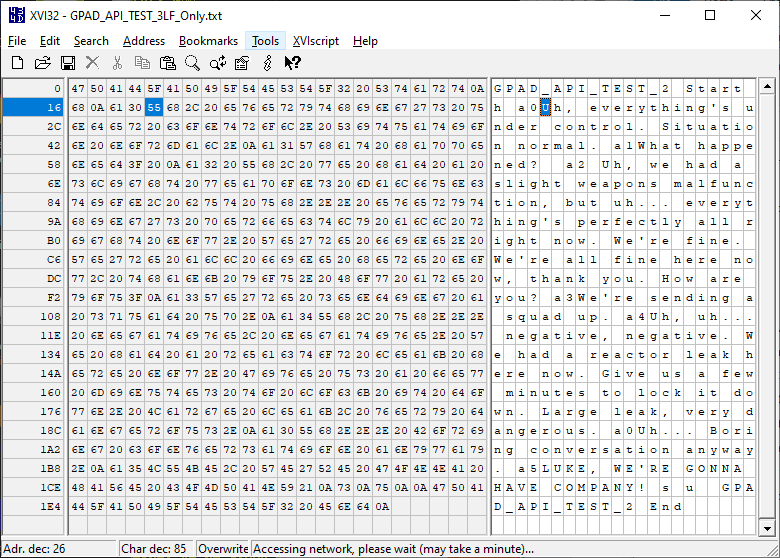
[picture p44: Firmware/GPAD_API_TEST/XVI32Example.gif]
  
Screen shot showing the XVI32 find and replace to replace CRLF with LF only.  
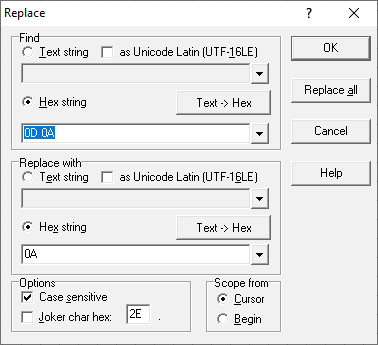
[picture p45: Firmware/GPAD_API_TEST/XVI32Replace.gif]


## References

XVI32 can be downloaded from what appears to be the author here: http://www.chmaas.handshake.de/delphi/freeware/xvi32/xvi32.htm#download

The program **RealTerm** can be downloaded from: https://sourceforge.net/projects/realterm/

## License

* Firmware: GLP 3
* Hardware CERN Open Hardware License Version 2 - Strongly Reciprocal

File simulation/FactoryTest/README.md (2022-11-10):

# Files of Wokwi Simulations

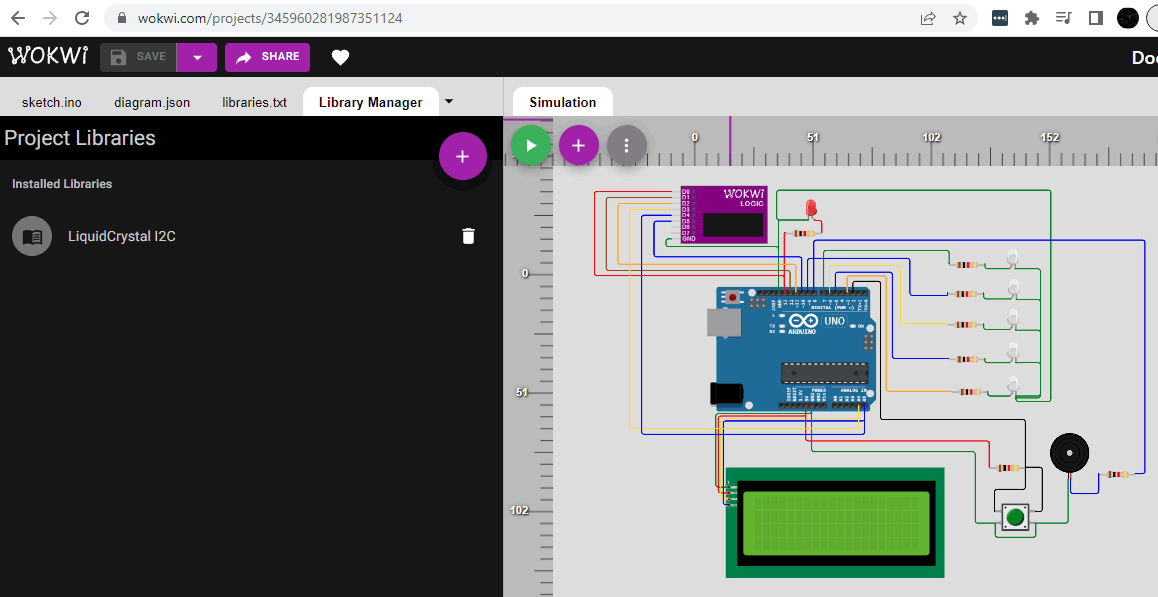
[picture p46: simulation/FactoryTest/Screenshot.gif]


## Wokwi Library List
## See https://docs.wokwi.com/guides/libraries
LiquidCrystal I2C

Note: logic analyzer added but not yet working.

Direct link to Lee's Wokwi for the simulation of 20221019
https://wokwi.com/projects/345960281987351124

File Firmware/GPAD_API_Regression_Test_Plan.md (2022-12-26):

# GPAD API Regression Test Plan

## Scope of this document:
Test plan for the GPAD_API.ino firmware used in the GPAD.
Testing input should be on both the serial interface, the SPI interface and the push button.
Confirmation of correct behavior may require a human to examine the DUT. Where tests can be automated even better.

## Black Box Testing
Design Black Box Testing use the product features documentation.
* Group 1, Display typical messages to the LCD
* Display all characters to the LCD
* Test all conditions of the Lights (LEDs) 
* Check speed of DUT reponse to input. Try to over run the capability both serial and SPI.
* Look for pathological situations like long strings or mal formed commands. Try every non printible character.
* Other, further test as...

Tests implimented as of 20221102
Tests using a terminal program on serial port input. Using RealTerminal both with direct user input and by sending files. RealTerm allows for setting intercharacter delay, end of line delay and repeate file delay. 
Endurance testing with RealTerminal. Capture of the bidirectiontal serial traffice may be possible, and if ont try TeraTerm.

### Black Box Test Results 
#### Group 1 with RealTerminal Testing  
Tests labeled "RT" are with RealTerminal.  
DUT Firmware Version: **0.1**
Version of test tools: NA
| Test ID | RT Test 1  | RT Test 2  | RT Test 3  |RT Test 4  | RT Test 5  |
| --- | --- | --- | --- |--- | --- |
| Test Name--> | **GPAD_API_TEST_1**  | **With LF_Only**  |  **Display all alarms** |**All alpha numeric** |**Long Line Test** |
| Test notes--> | Use file GPAD_API_TEST_1.CRLF.txt  | Use file GPAD_API_TEST_3LF_Only.LF.txt | Use file GPAD_API_TEST_3LF_Only.LF.txt |Use file GPAD_API_TEST_ALPHANUM1.LF.txt  | Use file GPAD_API_TEST_LONGLINE.LF.txt  |
| Description and Expected Results-->|This file has CR and LF end terminations. | Test file has help command and only Alarms with messages and only LF end terminations. | Display all alarm messages sequentially.  | All alphanumeric, most punctuation|Alarm message with greater than 60 characters|
| Actual Results LCD-->  | The CR character produced a goofy graphic symbol | This displays with no goffy characters. | A2, A4 message missing, DUT resets | As good as the LCD can do. | Improper display. No status. Text all over line 1, 3 and 4. Line 2 blank.|
| Actual Results LEDs-->  | The LEDs lite sequentially.  | The LEDs lite sequentially. | The LEDs lite sequentially. | The LEDs lite sequentially. | Light 1 lite. Pass|
| Actual Results Buzzer-->  | The buzzer sounded.  | The buzzer sounded. | The buzzer sounded. | The buzzer sounded. |No sound.|
| Pass/ Fail / Other | Fail. Goofy character should not display | Pass | Fail. DUT Reset |Pass  | Fail|
| Bug Report | GPAD With Bad Character #107 | Pass | GPAD_API ?Reset? During Endurance Testing With Messages #109 |  See video: https://www.youtube.com/watch?v=uIGDPubeWpw There are notes about a few character substitutions at this issue: https://github.com/PubInv/general-alarm-device/issues/120 | Issue at: https://github.com/PubInv/general-alarm-device/issues/125|  

<sub>(copy this table above in full for future versions and ammend as appropiate)</sub>

#### Proccessing Testing, pseduPolyVent
Tests labeled "sPV" are with the Processing program pseudoPolyVent.  
DUT Firmware Version: **0.1**
Version of test tools: TBD
| Test ID | sPV Test 1  | sPV Test 2  | sPV Test 3  |
| --- | --- | --- | --- |
| Test Name--> | **???**  | **???**  | foo |
| Test notes--> | **???**  | **???**  | bar |
| Expected Results-->|The DUT will... | The DUT will... | ??? |
| Actual Results-->  | The cow jumped over the moon. | The dish ran away with the spoon | ??? |
| Pass/ Fail / Other | Fail. Cows are not space rated | PASS they were a natural match | ??? |

<sub>(copy this table above in full for future versions and ammend as appropriate)</sub>

## White Box Testing
Design White Box Testing with the additional insight of the source code and help from the designer / coder (s).
* Exercises every state variable in every order
* With the Processing pseudoPolyVent control more representative of how a hardware device might work with capture and logging of device response on the serial and eventually SPI interface is possible.
* Other TBD

## Other
Reports from users.

## Version
This test plan is version 20221102

## License

* Firmware: GLP 3
* Hardware CERN Open Hardware License Version 2 - Strongly Reciprocal

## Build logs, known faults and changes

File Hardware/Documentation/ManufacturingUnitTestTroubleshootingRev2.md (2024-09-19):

# Manufacturing and Unit Test Documentation, PCB Version 2.0, 20230228
These notes were made during the assembly of the JLCPCB order of about March 2023.  
These units will be assigned serial numbers 16 through 30.  

#### Sections below
* Manufacturing test procedure for every unit 
**Assembly Notes and Tips 
* GPAD Theory of Operation 
* Troubleshooting procedures 

## Manufacturing test procedure for every unit

### Tools Required

Solder station with appropriate ventilation
3/16 Nut Driver 
Number 1 philips screw driver
Diagonal or other flush cutting hand tool for lead trimming.
Assembly fixture, detailed below.

### Reference Material

The most recent schematic is for Rev 2 PCB Assemblies is: [Schematic-GeneralPurposeAlarmDevicePCB-V2.2.pdf](/Hardware/GeneralPurposeAlarmDevicePCB/PDF/Schematic-GeneralPurposeAlarmDevicePCB-V2.2.pdf)

### Assembly Notes and Tips

As received from JLCPCB.
Note the assembly has the SMT components placed by the board manufacturer and some but not all through hole components. 

Write serial number on the PCB assembly at the location provided. 

Example of serial number written on number 26.  
_Further Management of serial numbers is beyond the scope of this document. Each manufacturer must figure something out._

### An Assembly Fixture
We made an assembly assistant / fixture by using a raw PCB with some long #6 screws and nuts to hold at the PCB mounting points. 
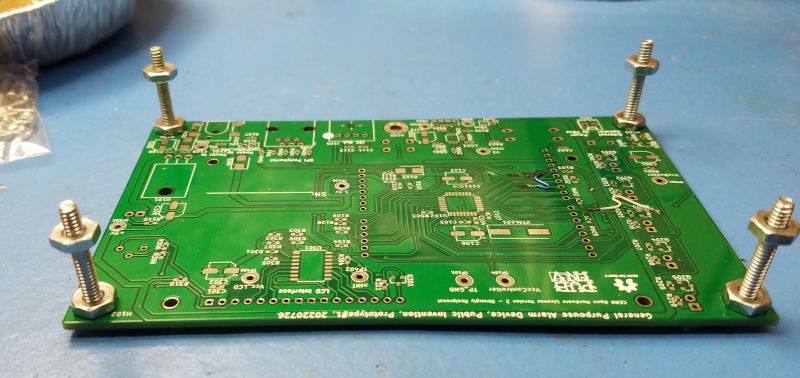
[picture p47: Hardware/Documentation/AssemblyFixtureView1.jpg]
Assembly Fixture View 1, no LCD
  

In addition four 4.40 screws with washers and 4-40 nuts to make a 1/8" spacer for holding the LCD and header for soldering.
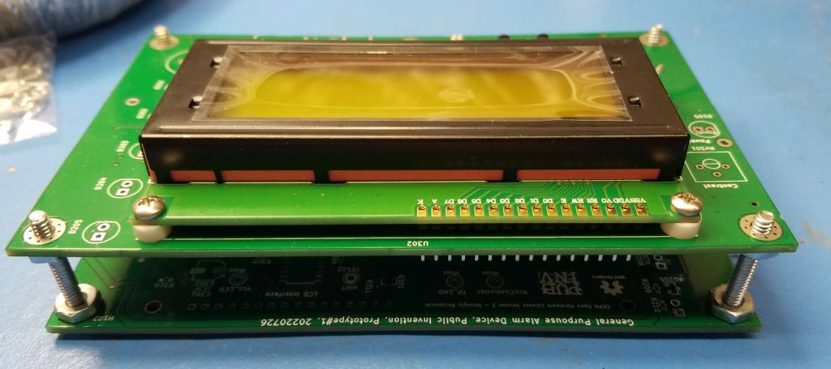
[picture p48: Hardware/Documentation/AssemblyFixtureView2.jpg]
Assembly Fixture View 2, With LCD
  

### Rework per issue #213, Remove R103
GPAD Rev 2.0 PCB, Remove the Resistor R103 (Loads the Peripheral Select), Update Factory Test for D601. #213 
**Problem:** 
The assemblies built per the BOM_JLCPCB_20230228Modified.xls have R103 fitted with a 1K resistor. This resistor with the LED D102 loads the SPI_CLK signal and is incompatible with proper operation of the GPAD as an SPI Peripheral from a 3.3V SPI Controller using the level shifting method using the common gate MOSFET.  
   
**Solution:** 
Remove R103.

### Assembly Steps 
 
1. LCD Bezel Grounding.
On the LCD module locate the J1 and J2 solder pads which if soldered ground the bezel.  
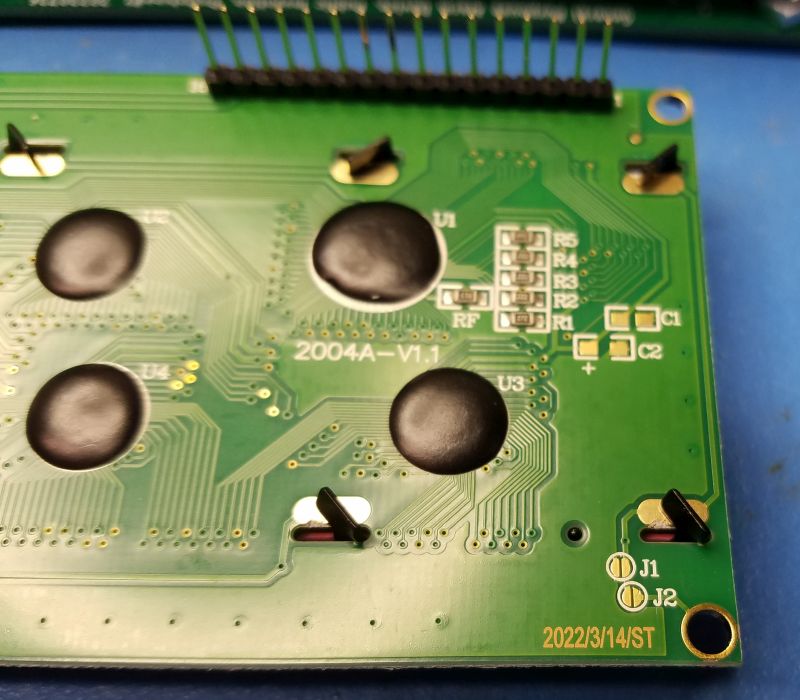
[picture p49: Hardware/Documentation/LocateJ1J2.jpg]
View of J1 and J2.
   
Solder them.  
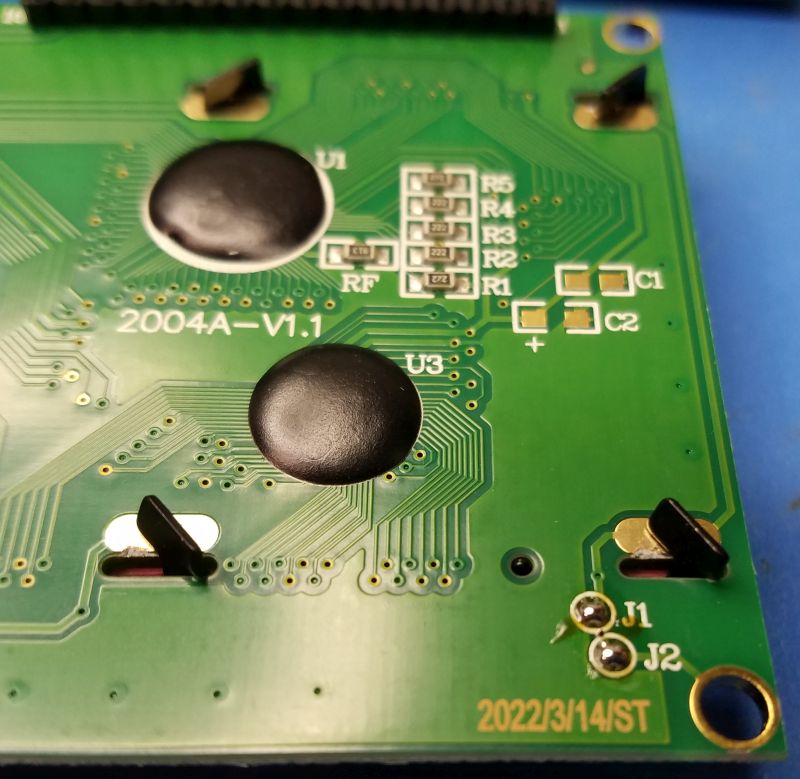
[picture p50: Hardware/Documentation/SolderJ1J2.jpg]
Solder on of J1 and J2.
   
As soldered.  
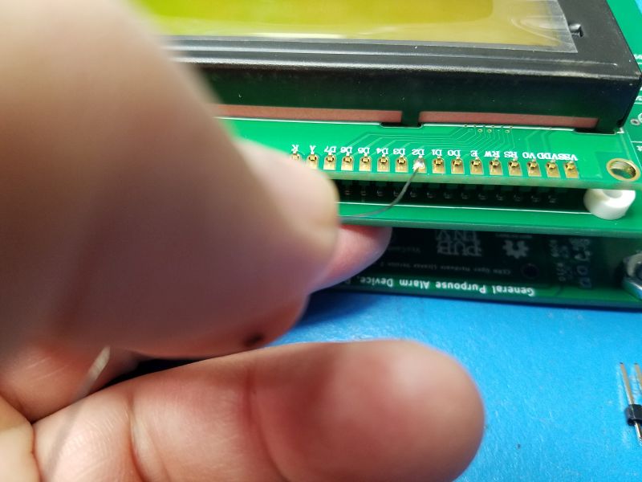
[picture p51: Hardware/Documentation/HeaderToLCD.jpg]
2. The 16 pin header is fit and soldered on to the LCD sub module. Then the pins are placed through the GPAD PCB. Four, nylon 1/8" spacers are placed at the four corners of the LCD sub module. Four 4-40 x 3/8" screws with 4-40 x 3/16" nuts go through both boards and are torqued to 3.4 - 4.8 Inch-Pounds. Solder the LCD header pins into the GPAD PCB.    
TIP: Using the assembly fixture the 16 pin header can be held flush to the LCD module to solder a center pin to start the process.  
 Assembly Fixture View 2 
 View of holding header to LCD.  
3. Put Reset button, S101 into PCB from display side.
4. Put Mute button, S401 into PCB from display side.
5. Put Buzzer, BZ601 into PCB from display side.  Bending leads may help retain.
6. Put Contrast pot, RV301 into PCB from display side.  Bending leads may help retain.   

 
7. Through hole LEDs at locations D201-D205 and D105 with a stand-off spacer.  
 LEDs with spacers.  
Thread the LED leads through the stand-offs.  The longer LED lead is the anode. The cathode has a flat side on the plastic case.  
Place the LEDs in to the PCB so that the flat cathode side corresponds to the silk screen marking. Bend the leads to retain the LED into the PCB.  Placing the assembly on the fixture lets you have access to the top and the bottom of the assembly.  
  
Assembly Fixture View with LEDs ready for soldering.
Lift LED and reflow solder for a flush fit on the PCB.  
For each LED, after soldering one lead, holding the LED from below up to the spacer and the PCB and reheat / reflow the solder for a flush fit.  
Solder the second lead on the LED.  
Trim the excess leads on RV301 and the LEDs.
> *Assembly Tip:* [Sharpie Oil-Based Paint Markers](https://www.sharpie.com/markers/chalk-paint-markers/sharpie-oil-based-paint-markers-fine-point/SAP_37371PP.html) can be used to mark polarity on LED standoffs and mark PCB's version, serial number and programming status of the microprocessor.
LCD side components installed.

**Rejoice! Electrical assembly is done.** 

### Electrical Tests
Electrical tests are in two parts. 
1. Unprogrammed measurements made before flash programming the boot loader and other firmware and...
2. Programmed measurements made after a boot loader and firmware have been placed into the microcontroler.

#### Electrical Measurements before programming boot loader and firmware
Measure and record by serial number the following electrical parameters.
Investigate and correct abnormal measurements before applying power.  Remove J102 and J103 and retain if present. Note where they should be replaced.
Start with no connections to the DUT (Device Under Test).

**Power Jack** Measure resistance to ground at J101 center pin as open or greater than 100K ohms.

**SPI Interface** Measure resistance to ground at J401 pin 5 as open or greater than 1Meg ohms.

**Vin net** Measure resistance to ground at TP102 as open or greater than 75K.  This net is capacitive and the resistance measured will climb as the meter charges the net.

**+5V net** Measure resistance to ground at 1K +/- 5% (950-1050 Ohms).

With a current limited supply set for 12V and maximum of 200 mA, apply power at J101 and note and record the unprogrammed current.
(FYI, when unprogrammed, the first time power up current is normally about 75-80 mA.)

Check that the power LED D105 is lit and is RED.

**+5V net** Measure the voltage of the +5V Net at TP103.

(FYI, a programmed DUT that has been powered up, and with display back light on, Hold the reset switch and measure current as about **61** mA)

**Vo Initial Set / LCD Contrast.** 
With a volt meter, measure the voltage of the Vo pin of the LCD header to ground. Adjust RV103 for 1.3 V.
This is an initial guess. Later in the process will be the actual setting of the contrast.
See records of measurements of some of the Rev 2 assemblies at this issue: https://github.com/PubInv/general-alarm-device/issues/217 #217

**Electrical Test Results Table**

In Tennessee:
* All resistance measured on 20Meg scale except R@5V net measured on 2K scale. Multi meter EMCO Model DMR-3800 unless noted.   
* All current measured 200mA scale. Multi meter EMCO Model DMR-3800 unless noted.  

Capture:
DUT Serial Number, R@PowerJack, R@SPI Interface, R@Vin net, R@5V net, UnProgramCurrent, Volt@+5 TP103, FullCurrent mA, Vo Volts, Notes

<table style="background-color:#DDDDEE">
  <tr><th>DUT Serial Number</th> <th>R@PowerJack</th> <th>R@SPI Interface</th> <th>R@Vin net</th> <th>R@5V net</th> <th>UnProgramCurrent</th> <th>Volt@+5 TP103</th><th>FullCurrent mA</th> <th>Vo Volts</th> <th>Notes</th></tr>
  <tr><td>01</td> <td>___</td> <td>___</td> <td>___</td> <td>___</td> <td>___</td> <td>___</td> <td>___</td> </tr>
  <tr><td>02</td> <td> >2Meg</td> <td>>2Meg</td> <td>>2Meg</td> <td>>2Meg</td> <td> 61 mA with LCD back light on</td> <td>5.04V</td> <td>119 mA</td> <td>1.29</td> <td>Not measure un programed.</td> </tr>
  <tr><td>03</td> <td>1.5Meg</td> <td>Open</td> <td>490K</td> <td>1.052K</td> <td>68.4 LCD ON</td> <td>5.03</td> <td>118</td> <td>1.29</td> <td> </td> </tr>
  <tr><td>04</td> <td>1.5Meg</td> <td>Open</td> <td>320K</td> <td>1.052K</td> <td>68.5 LCD ON</td> <td>5.02</td> <td>118</td> <td>1.30</td> <td> </td> </tr>
  <tr><td>05</td> <td>980K</td>   <td>Open</td> <td>500K</td> <td>1.052K</td> <td>68.8 LCD ON</td> <td>5.03</td> <td>118</td> <td>1.33</td> <td> </td> </tr>
  <tr><td>06</td> <td>1.3Meg</td> <td>Open</td> <td>250K</td> <td>1.052K</td> <td>68.7 LCD ON</td> <td>5.03</td> <td>118</td> <td>Vo=1.29</td> <td> </td> </tr>
  <tr><td>07</td> <td>___</td> <td>___</td> <td>___</td> <td>___</td> <td>___</td> <td>___</td> <td>___</td> <td>___</td> </tr>
  <tr><td>08</td> <td>___</td> <td>___</td> <td>___</td> <td>___</td> <td>___</td> <td>___</td> <td>___</td> <td>___</td> </tr>
  <tr><td>09</td> <td>___</td> <td>___</td> <td>___</td> <td>___</td> <td>___</td> <td>___</td> <td>___</td> <td>___</td> </tr>
  <tr><td>10</td> <td>___</td> <td>___</td> <td>___</td> <td>___</td> <td>___</td> <td>___</td> <td>___</td> <td>___</td> </tr>
  <tr><td>11</td> <td>___</td> <td>___</td> <td>___</td> <td>___</td> <td>___</td> <td>___</td> <td>___</td> <td>___</td> </tr>
  <tr><td>12</td> <td>___</td> <td>___</td> <td>___</td> <td>___</td> <td>___</td> <td>___</td> <td>___</td> <td>___</td> </tr>
  <tr><td>13</td> <td>___</td> <td>___</td> <td>___</td> <td>___</td> <td>___</td> <td>___</td> <td>___</td> <td>___</td> </tr>
  <tr><td>14</td> <td>___</td> <td>___</td> <td>___</td> <td>___</td> <td>___</td> <td>___</td> <td>___</td> <td>___</td> </tr>
  <tr><td>15</td> <td>___</td> <td>___</td> <td>___</td> <td>___</td> <td>___</td> <td>___</td> <td>___</td> <td>___</td> </tr>  
  <tr><td>16</td> <td>___</td> <td>___</td> <td>___</td> <td>___</td> <td>___</td> <td>___</td> <td>___</td> <td>Vo=1.??</td><td> </td>  </tr>  
  <tr><td>17</td> <td>0.47</td> <td>Open</td> <td>3.5 Meg</td> <td>1.059K</td> <td>68.5 mA LCD ON </td> <td>5.02</td> <td>136 mA</td> <td>Vo=1.35</td><td> </td> </tr>  
  <tr><td>18</td> <td>open</td> <td>Open</td> <td>Open</td> <td>1.059K</td> <td>62.6 mA LCD ON </td> <td>5.03</td> <td>134 mA</td> <td>Vo=1.34</td><td> </td> </tr>  
  <tr><td>19</td> <td>___</td> <td>___</td> <td>___</td> <td>___</td> <td>___</td> <td>___</td> <td>___</td> <td>Vo=1.??</td><td> </td>  </tr>  
  <tr><td>20</td> <td>___</td> <td>___</td> <td>___</td> <td>___</td> <td>___</td> <td>___</td> <td>___</td> <td>Vo=1.??</td><td> </td>  </tr>  
  <tr><td>21td> <td>___</td> <td>___</td> <td>___</td> <td>___</td> <td>___</td> <td>___</td> <td>___</td> <td>Vo=1.??</td><td> </td>  </tr>  
  <tr><td>22</td> <td>___</td> <td>___</td> <td>___</td> <td>___</td> <td>___</td> <td>___</td> <td>___</td> <td>Vo=1.??</td><td> </td>  </tr>  
  <tr><td>23</td> <td>___</td> <td>___</td> <td>___</td> <td>___</td> <td>___</td> <td>___</td> <td>___</td> <td>Vo=1.??</td><td> </td>  </tr>  
  <tr><td>24</td> <td>___</td> <td>___</td> <td>___</td> <td>___</td> <td>___</td> <td>___</td> <td>___</td> <td>Vo=1.??</td><td> </td>  </tr>  
  <tr><td>25</td> <td>___</td> <td>___</td> <td>___</td> <td>___</td> <td>___</td> <td>___</td> <td>___</td> <td>Vo=1.??</td><td> </td>  </tr>  
  <tr><td>26</td> <td>___</td> <td>___</td> <td>___</td> <td>___</td> <td>___</td> <td>___</td> <td>___</td> <td>Vo=1.??</td><td> </td>  </tr>  
  <tr><td>27</td> <td>___</td> <td>___</td> <td>___</td> <td>___</td> <td>___</td> <td>___</td> <td>___</td> <td>Vo=1.??</td><td> </td>  </tr>  
  <tr><td>28</td> <td>___</td> <td>___</td> <td>___</td> <td>___</td> <td>___</td> <td>___</td> <td>___</td> <td>Vo=1.??</td><td> </td>  </tr>  
  <tr><td>29</td> <td>___</td> <td>___</td> <td>___</td> <td>___</td> <td>___</td> <td>___</td> <td>___</td> <td>Vo=1.??</td><td> </td>  </tr>  
  <tr><td>30</td> <td>___</td> <td>___</td> <td>___</td> <td>___</td> <td>___</td> <td>___</td> <td>___</td> <td>Vo=1.??</td><td> </td>  </tr>  
  </table>

### Measurements of current with in subcircuits (Issue #230)
See data from Rev2 build here:  https://github.com/PubInv/general-alarm-device/issues/230
Test condition. Measure before firmware is loaded into device
Capture current on circuit blocks.
These measurements made before the DUT was programmed with any firmware. NO BOOTLOADER even.  Measure the current by measuring the voltage across the 1 Ohm decoupleing resistor from the raw power to the test points indicated. Raw power is at TP103 +5 test point. Volts in mV will be a measurement of mA.
|  			 DUT S# 		 	|  			 VR101 (Current U102) mA 		 	|  			 VR310 (Current LCD) mA 		 	|  			 VR601 (Current Buzzer) mA 		 	|  			 Notes 		 	|
|---	|---	|---	|---	|---	|
|  			 29 		 	|  			 2.1 		 	|  			 49.1 		 	|  			  			 		 	|  			  			 		 	|
|  			 30 		 	|  			 2.5 		 	|  			 48.8 		 	|  			  			 		 	|  			  			 		 	|

### Load Firmware
** Note: Loading firmware through the SPI interface is a manufacturing test of the SPI hardware components. **

#### Load Bootloader
Use an Arduino UNO as an ISP (Incircuit Serial Programmer) which will load the boot loader into the DUT.
Cable Connect the ISP UNO to the DUT as follows:
<table style="background-color:#DDDDEE">
  <tr>    <th>Signal Name </th> <th>SPI UNO</th> <th>to DUT</th> <th>RJ12 Pin</th>  </tr>
  <tr>    <th>SPI CLK  </th> <td>D13</td>    <td>D13</td>    <td>4</td> </tr>
  <tr>    <th>SPI CIPO </th> <td>D12</td>    <td>D12</td>    <td>6</td>  </tr>
  <tr>    <th>SPI COPI </th> <td>D11</td>    <td>D11</td>    <td>2</td>  </tr>
  <tr>    <th>nCS      </th> <td>D10</td>    <td>D10</td>    <td>1</td>  </tr>
  <tr>    <th>GND      </th> <td>GND</td>    <td>GND</td>    <td>3</td>  </tr>
  <tr>    <th>POWER    </th> <td>+5</td>     <td>+5</td>     <td>5</td>  </tr>
</table>

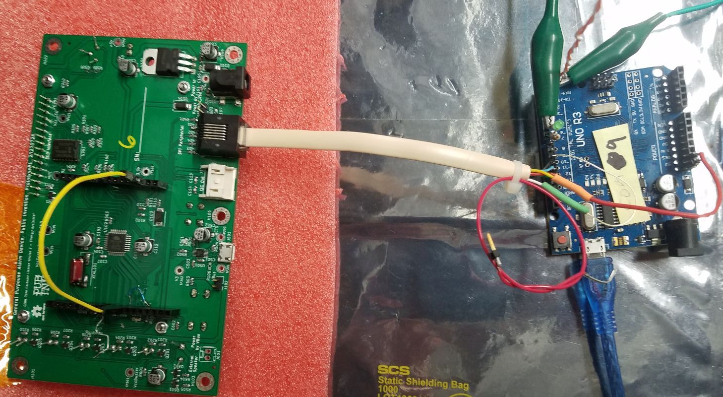
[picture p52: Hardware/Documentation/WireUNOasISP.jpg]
  Wiring of the UNO to the DUT.
Place a Jumper on the DUT from D10 to Reset
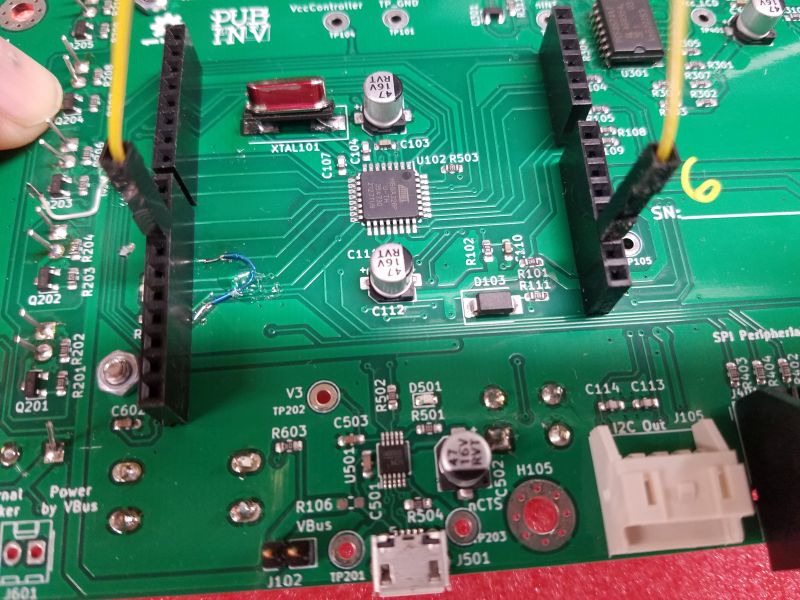
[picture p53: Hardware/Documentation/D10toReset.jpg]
  Jumper for D10 to Reset.

##### Missing Jumper to D10 When Load Bootloader
If you forget the above jumper the IDE will give an error something like this:  
>Arduino: 1.8.19 (Windows 10), Board: "Arduino Duemilanove or Diecimila, ATmega328P"
>avrdude: Yikes!  Invalid device signature.  
>         Double check connections and try again, or use -F to override  
>         this check.  
>Error while attempting burning of bootloader with out the RJ12 connection.  
>This report would have more information with "Show verbose output during compilation" option enabled in File -> Preferences.

#### Load into the IDE the sketch "ArduinoISP".  
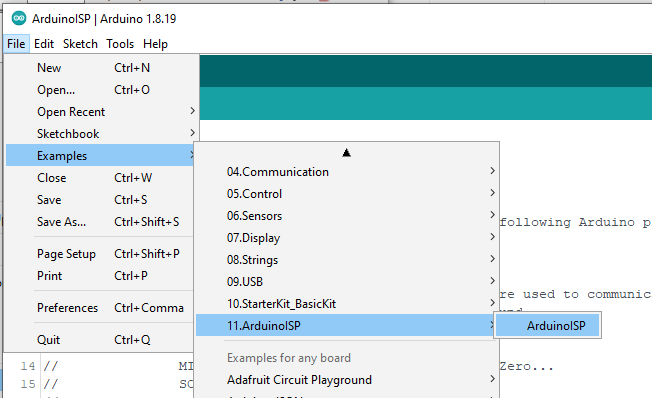
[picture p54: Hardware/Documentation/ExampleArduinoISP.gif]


To load into the UNO, Select the serial port for the UNO and compile and upload with the "ArduinoISP" by pressing **<Ctrl>U**. 

Setup the UNO to burn the boot loader into the GPAD target.
Select the board type (Boot loader type) to "Arduino Duemilanove..." .  
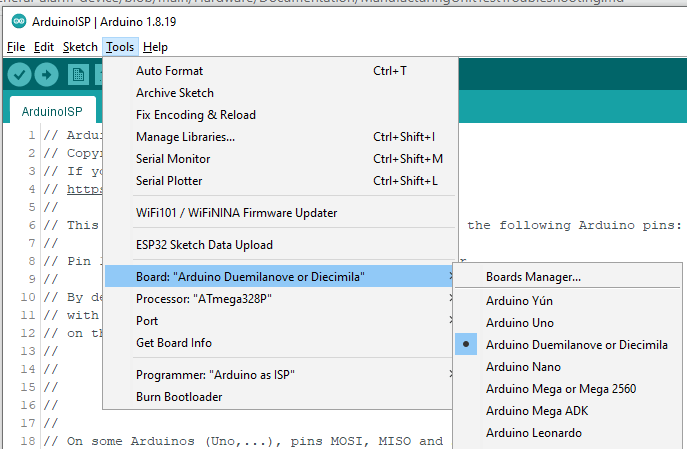
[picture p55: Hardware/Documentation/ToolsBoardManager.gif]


Select the Processor type to "ATmega328P" .  

Select the programmer type.  
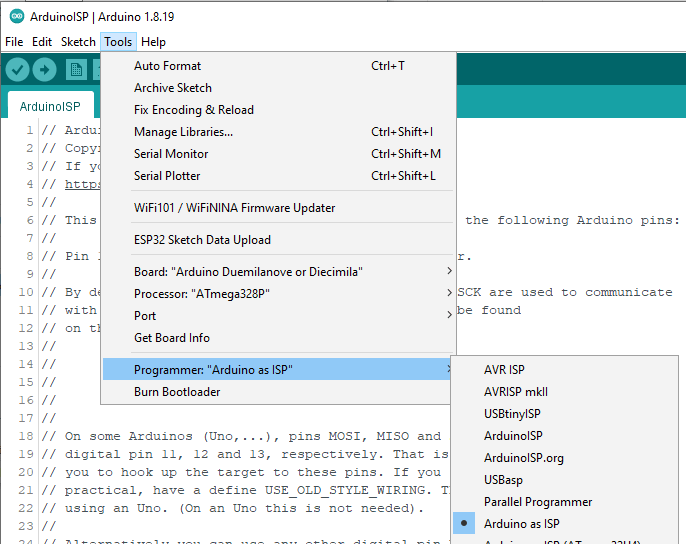
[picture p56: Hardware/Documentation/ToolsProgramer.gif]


In the Arduino IDE, select TOOLS > Burn Bootloader .  

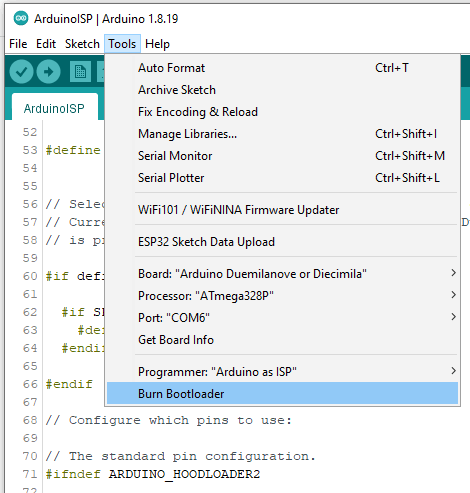
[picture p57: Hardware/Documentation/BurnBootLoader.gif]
  
Watch the progress bar in the IDE and look for success with the message "Done burning bootloader." in the blue status bar.
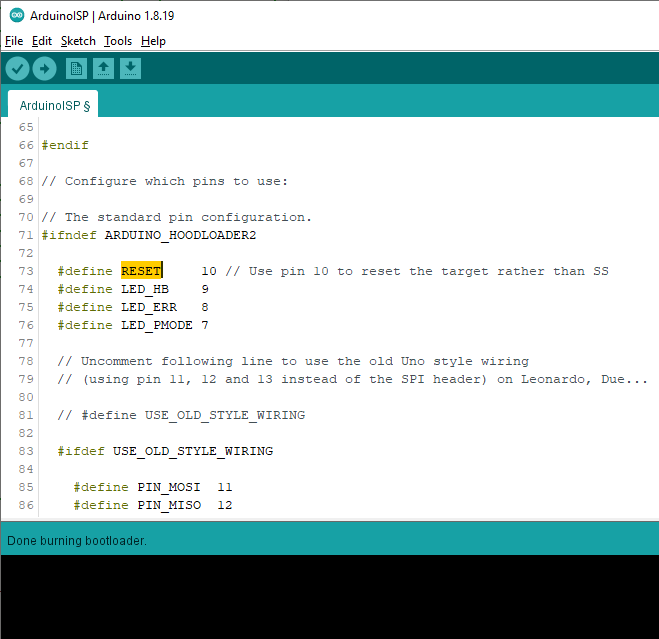
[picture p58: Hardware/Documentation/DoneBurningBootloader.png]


If R103 has not been removed, check that LED D102 is winking with a short on time and longer off time indicating that the boot loader has been loaded.  Until any other sketch is loaded, this is the expected behaviour of the unit under test.

#### Load Factory Test Firmware.
Connect a USB cable to the DUT. Note the COM port enumerated in Device Manager Ports(COM&LPT) drop down
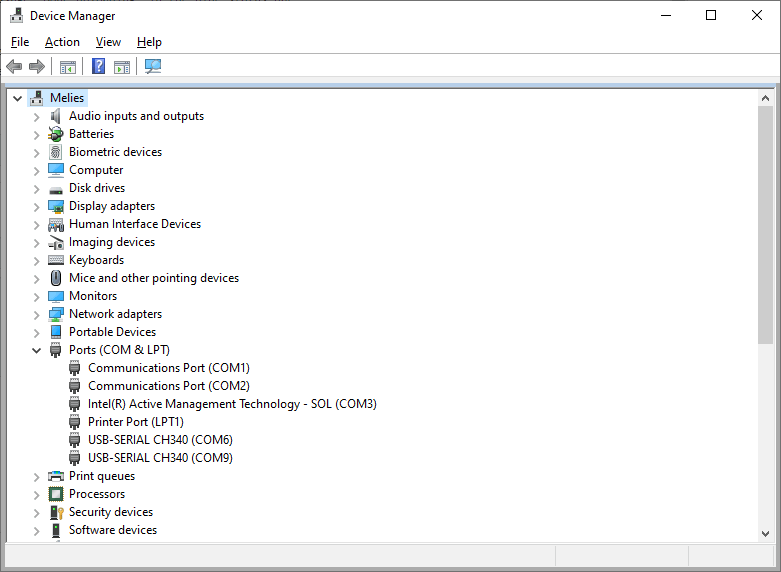
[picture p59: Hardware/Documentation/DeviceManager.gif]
  

In the Arduino IDE, open the new file "GPAD_Factory_Test.ino".  
Set the IDE for the COM port of the DUT.
  Using the Arduino IDE, compile and upload to the DUT the "GPAD_Factory_Test.ino"
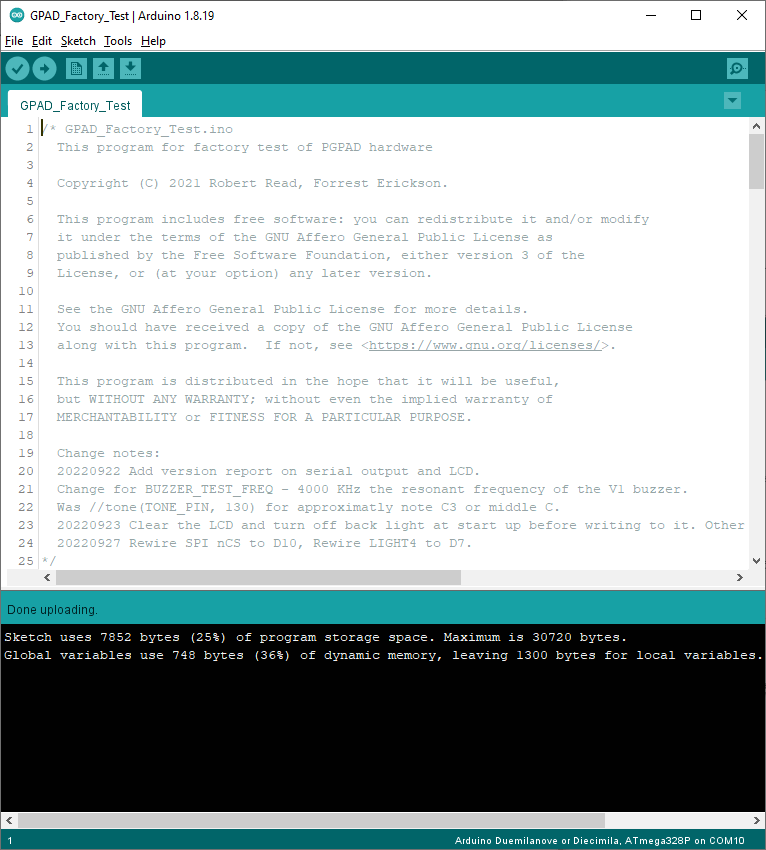
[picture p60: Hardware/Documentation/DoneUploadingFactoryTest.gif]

Watch the progress bar in the IDE and look for success with the message "Done uploading" in the blue status bar. 
  
Open a terminal to the COM port of the DUT and set for appropriate BAUD rate. 
Press the reset switch on the DUT and the LCD should display a message. The terminal should display a boot message too. This example is of a RealTerminal connected to the DUT.
  
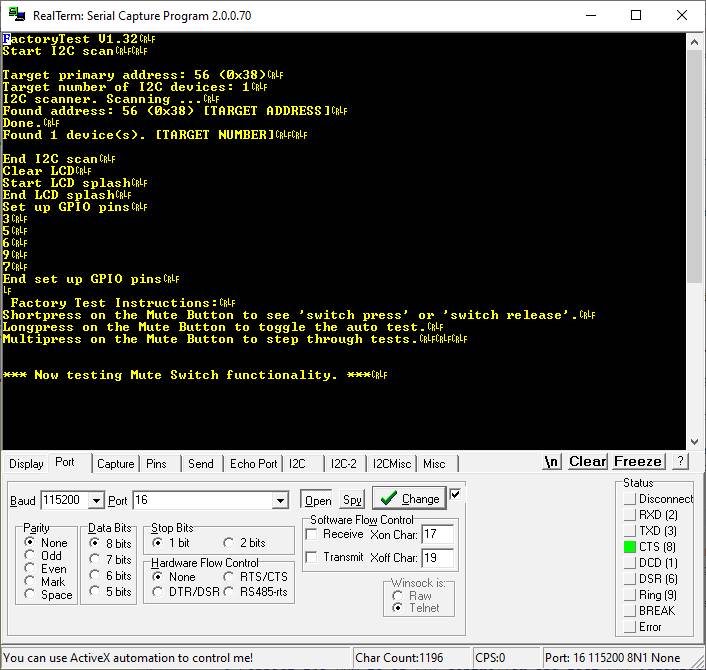
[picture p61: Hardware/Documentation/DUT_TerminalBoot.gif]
  
 
#### Electrical Measurements After programing bootloader and firmware
Measure and record by serial number the following electrical parameters.
 
  Observe the current on the DUT. Press the Mute Switch S601 and the white LEDs D201-D205 should light. The Buzzer will make a sound. Record this full current in the table above.
   
That's it. End of Rev2 Tests as of March 2023

## Enclosure Assembly



Use five screws to hold the printed wiring assembly (Green) to the yellow part.  
The screws must be selected to fit to the enclosure as 3D printed. The enclosures printed of nylon worked with a sheet metal screw of thread diameter 0.14” 

Use four screws to fix the tan part to the yellow part, two on each side. 
The screws must be selected to fit to the enclosure as 3D printed. The enclosures printed of nylon worked with a sheet metal screw of thread diameter 0.087” 
  
# TO DO Future Tests Enhancments:  
 * Connect the DUT to an SPI controller and test SPI interface.  
 * Connect the DUT to an I2C peripheral device and test the I2C daisy chain output.  
 * Walking One test of LEDs D201-D205.   
 * Test for Amplitude Modulation of Buzzer.  
  
## GPAD Theory of Operation  
The GPAD is based on an Arduino UNO design with a CH340 USB to Serial adapter which enumerates on a USB port as a CDC aka Windows COM port (In linux systems a port /dev/ttyUSBn where "n" is a number).
  
The GPAD is a SPI Peripheral device and will be controlled by another computer which will be a Controller.  

The GPAD Can be configured to get power from three ways. One is a barrel jack (2.1mm center positive) at 7-12Vdc, A second through the RJ12 connector from the Controller at 7-12Vdc is with a jumper on J103 or resistor at R107, and the third for low current applications only is the USB bus by adding Jumper J102 or zero ohm resistor at R106.  

The GPAD generally is controlled by an SPI Controller but through the USB port debug information can be watched and some TBD control is also possible.

## Troubleshooting procedures  
Compare and contrast operation with a normal device when ever possible.
Check the project issue list for history of other units with faults and their fixes.

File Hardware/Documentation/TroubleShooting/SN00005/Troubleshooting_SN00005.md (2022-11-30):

# Notes on Troubshooting SN00005 GPAD

* Board type is Prototype#1 
* DUT is powered by an external supply.

## Board SN5 gives error verifying upload, even though upload works.... #127
This issue is found at: #127

On Lee's Window's 10 machine to get avrdude to run I had to navigate to the folder path with the exicutible in it it:
C:\Program Files (x86)\Arduino\hardware\tools\avr\bin>
Then I could run "avrdude" and get help and begin to experiment.

The AVRdude command from the error report.
avrdude -CC:\Program Files (x86)\Arduino\hardware\tools\avr/etc/avrdude.conf -v -patmega328p -carduino -PCOM15 -b57600 -D -Uflash:w:C:\Users\Admin\AppData\Local\Temp\arduino_build_502233/GPAD_API.ino.hex:i

This command with the "-U" options of "w" means to write a file.

Lets try to change to verify only.
avrdude -CC:\Program Files (x86)\Arduino\hardware\tools\avr/etc/avrdude.conf -v -patmega328p -carduino -PCOM15 -b57600 -D -Uflash:v:C:\Users\Admin\AppData\Local\Temp\arduino_build_502233/GPAD_API.ino.hex:i
This syntax produced an error.

This syntax worked. 
"avrdude -C../etc/avrdude.conf -v -patmega328p -carduino -PCOM15 -b57600 -D -Uflash:v:C:\Users\Admin\AppData\Local\Temp\arduino_build_502233/GPAD_API.ino.hex:i"

"avrdude -C../etc/avrdude.conf -v -patmega328p -carduino -PCOM16 -b57600 -D -Uflash:v:C:\Users\Admin\AppData\Local\Temp\arduino_build_502233/GPAD_API.ino.hex:i"

This produced the following output:

> avrdude: Version 6.3-20190619
         Copyright (c) 2000-2005 Brian Dean, http://www.bdmicro.com/
         Copyright (c) 2007-2014 Joerg Wunsch

         System wide configuration file is "../etc/avrdude.conf"

         Using Port                    : COM16
         Using Programmer              : arduino
         Overriding Baud Rate          : 57600
         AVR Part                      : ATmega328P
         Chip Erase delay              : 9000 us
         PAGEL                         : PD7
         BS2                           : PC2
         RESET disposition             : dedicated
         RETRY pulse                   : SCK
         serial program mode           : yes
         parallel program mode         : yes
         Timeout                       : 200
         StabDelay                     : 100
         CmdexeDelay                   : 25
         SyncLoops                     : 32
         ByteDelay                     : 0
         PollIndex                     : 3
         PollValue                     : 0x53
         Memory Detail                 :

                                  Block Poll               Page                       Polled
           Memory Type Mode Delay Size  Indx Paged  Size   Size #Pages MinW  MaxW   ReadBack
           ----------- ---- ----- ----- ---- ------ ------ ---- ------ ----- ----- ---------
           eeprom        65    20     4    0 no       1024    4      0  3600  3600 0xff 0xff
           flash         65     6   128    0 yes     32768  128    256  4500  4500 0xff 0xff
           lfuse          0     0     0    0 no          1    0      0  4500  4500 0x00 0x00
           hfuse          0     0     0    0 no          1    0      0  4500  4500 0x00 0x00
           efuse          0     0     0    0 no          1    0      0  4500  4500 0x00 0x00
           lock           0     0     0    0 no          1    0      0  4500  4500 0x00 0x00
           calibration    0     0     0    0 no          1    0      0     0     0 0x00 0x00
           signature      0     0     0    0 no          3    0      0     0     0 0x00 0x00

         Programmer Type : Arduino
         Description     : Arduino
         Hardware Version: 2
         Firmware Version: 1.16
         Vtarget         : 0.0 V
         Varef           : 0.0 V
         Oscillator      : Off
         SCK period      : 0.1 us
         
         avrdude: AVR device initialized and ready to accept instructions
         Reading | ################################################## | 100% 0.01s
         avrdude: Device signature = 0x1e950f (probably m328p)
         avrdude: safemode: lfuse reads as 0
         avrdude: safemode: hfuse reads as 0
         avrdude: safemode: efuse reads as 0
         avrdude: verifying flash memory against C:\Users\Admin\AppData\Local\Temp\arduino_build_502233/GPAD_API.ino.hex:
         avrdude: load data flash data from input file C:\Users\Admin\AppData\Local\Temp\arduino_build_502233/GPAD_API.ino.hex:
         avrdude: input file C:\Users\Admin\AppData\Local\Temp\arduino_build_502233/GPAD_API.ino.hex contains 9500 bytes
         avrdude: reading on-chip flash data:
         
         Reading | ################################################## | 100% 2.49s
         
         avrdude: verifying ...
         avrdude: 9500 bytes of flash verified
         avrdude: safemode: lfuse reads as 0
         avrdude: safemode: hfuse reads as 0
         avrdude: safemode: efuse reads as 0
         avrdude: safemode: Fuses OK (E:00, H:00, L:00)
         
         avrdude done.  Thank you.
         
         C:\Program Files (x86)\Arduino\hardware\tools\avr\bin>

So testing SN5 with the command: avrdude -C../etc/avrdude.conf -v -patmega328p -carduino -PCOM15 -b57600 -D -Uflash:v:C:\Users\Admin\AppData\Local\Temp\arduino_build_502233/GPAD_API.ino.hex:i from the approprate folder might be of interest.

## Reference
https://www.ladyada.net/learn/avr/avrdude.html

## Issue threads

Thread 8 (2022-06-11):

Wired and Wireless Interface and Consequences.

ForrestErickson, 2022-06-11:
Many tangled issues In the section:

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

Regarding, "and SPI-based protocol is probably most valuable for integration with a medical devices, such as... " comes assumptions that in addition the the four SPI signal wires is power and ground and if there is a button on the **general-alarm-device** the question arises of signaling back to the medical device the user's interaction (the button was pressed).  With this set of assumptions comes mounting hole pattern, with safe space left around mounting holes for hardware and providing end users drawings for mounting hole location versus the opening for display , lights, audio, and perhaps a reference design for a bezel.

For a NON integrated application where the  **general-alarm-device** is tethered on a cable, This SPI interface path will require the identification of a connector and pinout of the same. I know of no commercial products which put an SPI interface, power and ground on a cable (with the sole exception of a point of sale display, now obsolete, by Verifone, on an JR45 connector).

With WiFi, and Bluetooth interface and the assumption of a complete enclosure comes the issue of identifying a power supply.  Is a WiFi / Bluetooth connection appropriate for a medical device (what happens with the RF connection is interrupted)?

If we really want a WiFi and Bluetooth interface the Arduino UNO is not the way to start development. The ARDUINO UNO WiFi REV2 may be the more appropriate device for proof of concept development (or an ESP32).  The use case for paring by Bluetooth will involve some button on the **general-alarm-device** .
The connection by WiFi probably involves a WiFi manager to be set up by for example a smart phone to get the **general-alarm-device** on the hospital network and then the respirator to find the particular **general-alarm-device** to which to send the data and network security to prevent all the bad things bad players try to do to networks.

I (Lee Erickson) believe the decision on the requirement or lack there of for wireless interface needs to be made very soon and should reflect the very first proof of concept developed.

ForrestErickson, 2022-06-11:
For I2C interface in the maker community  there is the STEMMA interface. See: https://www.adafruit.com/category/1005

RobertLRead, 2022-06-11:
Good questions.

I assume that the GPAD should have a 12V jack.

There is not standard way to do SPI cabling, but we have used a shielded USB 4-wire cable up to 30cm to do I2C cabling. That is an acceptable solution, but the GPAD probably should just have a female 4-wire connector. I would just choose a JST connector that has a nice "snap" fit; this is always involves some tradeoffs, and I don't know a cookie-cutter way to do it.

A WiFi or Bluetooth connection is good for hobbyist; bad for medical devices. Although there is some debate about wireless in ICUs, I want to avoid it; that is why I prefer SPI.  I would rather have an SPI connection on an UNO ahead of any other solution; however, if people want to start with a WiFi enabled microcontroller board I have no objection to that; but we need an SPI solution as a high priority.

The main need for a button on the alarm is to silence it. This is similar to the HUSH feature on kitchen smoke alarms; you push the button and the alarm is silenced for set time (let's say 2 minutes.) There is an academically recognized research area of Computer-Human Interaction as to how to do alarm management to prevent alarm fatigue for doctors. Basically, we can't solve this problem, but an MVP approach is just a button that silences for a fixed time. After the fixed time, if the alarm has not been sent to the lowest alarm level electronically, it starts to alarm again.  The beauty of this solution is that does NOT require anything to be communicated back to whatever device is generating the alarms; it does NOT need to know that the user silenced the alarm. However, adding that to the API could be a nice feature.

WRT to setting up WiFi, Public Invention makes the VentMon device which is WiFi enabled. We implement a serial port protcol that lets you specify the SSID and password, which is stored in the EEPROM. This is done with the Arduino IDE serial monitor, typically.  This is completely adequate for engineers. However, you are correct, non-engineers probably need a phone app-based solution. However, since the WiFi use case is for hobbyist, I think we can go a long way with a similar "set the SSID and password with the serial port solution."

RobertLRead, 2022-06-11:
In case that is not perfectly clear: Rob thinks the MVP should not have WiFi.

ForrestErickson, 2022-06-12:
Regarding, "I assume that the GPAD should have a 12V jack."  We should begin to collect these requirements in probably more specialized documents and folders.   For example a surface mount 2.1mm barrel jack is: https://www.digikey.com/en/products/detail/tensility-international-corp/54-00164/10459298

I have been reluctant to mess with or add to the structure for fear not knowing enough of assumptions of how things have been organized in the past. Other than looking at for example MoonRat, is their a standard or template for organizing the project information?

RobertLRead, 2022-06-12:
I'm not aware of any such standard; certainly Public Invention does not
have one.

I personally would make the barrel jack size a story added to the project.

I consider the evolution of these "requirements" something that will happen
as we go along; for example, I personally don't know what the best (most
standard) specific format for a 12V barrel jack is off the top of my head.

On Sat, Jun 11, 2022 at 7:26 PM Forrest Lee Erickson <
***@***.***> wrote:

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

--
Robert L. Read, PhD
Twitter: @RobertLeeRead @pubinvention
Public Invention: https://www.pubinv.org
Join Our Mailing list: ***@***.***
YouTube: https://www.youtube.com/channel/UCJQg_dkDY3KTP1ybugYwReg
Medium: ***@***.***

LokiMetaSmith, 2022-06-22:
For wireless, I would use a System on a Chip, such as the ESP32 series. It's got good compatibility with existing arduino libraries, so the WiFi/Bluetooth feature would be a processor swap. Most of the peripherals should be compatible, as long as they accept 3.3v logic levels.

LokiMetaSmith, 2022-06-28:
Left as an option for another revision

Closed 2022-06-28.

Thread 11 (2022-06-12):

Evaulate Serial Transfer library for unifying SPI and Serial

ForrestErickson, 2022-06-12:
**A very useful looking library for Serial Transfer.**

https://github.com/PowerBroker2/SerialTransfer

SerialTransfer is an easy to use Arduino library for transferring packetized data fast and reliably via Serial, I2C, and SPI interfaces. Interconnect your Arduinos today minus the headache with SerialTransfer!

LokiMetaSmith, 2022-06-28:
Closing for now, the library mentioned looks like it will work.

ForrestErickson, 2022-10-18:
Robert This is the  library I though might be worth looking at for sending serial data through the SPI interface.

ForrestErickson, 2022-11-22:
@RobertLRead
@LokiMetaSmith

Before closing I thought we should have some mutual review of the utility this library provides which I summarize in a quotation below.

Will the utility of this library be of use to PolyVent and GPAD?
What is the utility needed for our PolyVent and GPAD requirements?
Can the library help with the transfer of json files as I remember Robert was promoting?

> SerialTransfer is an easy to use Arduino library for transferring packetized data fast and reliably via Serial, I2C, and SPI interfaces. Interconnect your Arduinos today minus the headache with SerialTransfer!

[A mirror library is also available for Python!](https://github.com/PowerBroker2/pySerialTransfer)This library:
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

ForrestErickson, 2022-11-22:
This library could be evaluated by using two GPADs.
As a start
For a "Controller" load the file:
https://github.com/PowerBroker2/SerialTransfer/blob/master/examples/spi_tx_file/spi_tx_file.ino

For a "Peripheral" load the file:
https://github.com/PowerBroker2/SerialTransfer/blob/master/examples/spi_rx_file/spi_rx_file.ino

There are other examples that may be of value.

RobertLRead, 2022-11-23:
I have looked at this, and I realized, we really don't want to use this for the serial port. The whole point of the serial port is to use a "plain text" message (which may be parsable in some, such as JSON.)

However, I think all of the packet construction (which is really what this library does) is VERY useful of SPI and I2C. So I still intend to use this.

Note I have (in a branch), create a python program that allows you to post things from the command line. This is sort of a useful point for some people who want to use Python. It needs to be done.

ForrestErickson, 2022-11-23:
@RobertLRead
Regarding, "Note I have (in a branch), create a python program that allows you to post things from the command line. This is sort of a useful point for some people who want to use Python. It needs to be done."

It is possible from the Windows command window to send commands such as:
echo a4TEST > \\.\COM15

I have tried this and the GPAD is receiving something but not parcing it correctly. The COM terminal is sending a CR LF termination.

ForrestErickson, 2022-11-23:
This is closer. The GPAD_API V0.10 responded to this command.
I also displayed the COM port setup for a reference.

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

ForrestErickson, 2022-12-03:
@RobertLRead reports the following in an email of 20221202:

>I have used the "Serial Transfer" library to transfer strings via SPI over our cable between the two boards with good connectors; this is good progress.
Sadly, however, the owner of that repo communicated to me (via an issue) that he no longer supports SPI, and I had to modify the files by hand to make them work. This produces a strategic quandary: use a library that has to be modified by hand, or write our own, largely duplicating the functionality that is in that library?
I will think about this.

ForrestErickson, 2022-12-03:
@RobertLRead
Could you copy or link to the correspondence with the author of the library here in this issue please?

LokiMetaSmith, 2023-01-03:
Robert had issues compiling on the ESP32 with the library and so we will not be using this library.

Closed 2023-01-03.

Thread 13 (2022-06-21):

Cable Connection for I2C Device, COTS

ForrestErickson, 2022-06-21:
A commercial off the shelf cable for I2C is the one from Adafruit.

STEMMA QT / Qwiic JST SH 4-pin Cable - 100mm Long
Candidate cable: https://www.adafruit.com/product/4210

To Do for PCB:
Add a jack compatible with this on the GPAD PCB so that we can daisy chain to other devices.

RobertLRead, 2022-06-21:
This is good but that connector doesn't snap in as much as I would like it
to. It is quite small and can come out with pressure or vibration. However,
the same cable with a more solid connector should be acceptable.

On Tue, Jun 21, 2022 at 11:50 AM Forrest Lee Erickson <
***@***.***> wrote:

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

--
Robert L. Read, PhD
Twitter: @RobertLeeRead @pubinvention
Public Invention: https://www.pubinv.org
Join Our Mailing list: ***@***.***
YouTube: https://www.youtube.com/channel/UCJQg_dkDY3KTP1ybugYwReg
Medium: ***@***.***

ForrestErickson, 2022-06-22:
An RJ12 is 6P6C and would have conductors enough for signals and redundant power and ground.

We would need PROMINENT labeling for its purpose so that it would not be misused.
We would need to PROMINENT identify that a data cable (Wired pin 1 to pin 1) must be used and not a telephone cable (Wired pin 1 to pin 6).
Examples from amazon: https://www.amazon.com/s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

LokiMetaSmith, 2022-06-22:
RJ-12 have connector stability issues and drastically increase bulk.

JST-SM have options for arm locking mechanisms which would make them resistant to pulling out.

http://www.jst.co.uk/productSeries.php?pid=94&cat=117

LokiMetaSmith, 2022-06-28:
Decided to keep with a JST style connector, but the JST-SM is a wire to wire only connector

Alternatives are.
JST-VH
JST-XA
JST-PA

https://en.wikipedia.org/wiki/JST_connector

ForrestErickson, 2022-06-30:
The JST-PA series is 2mm which will be compact similar to the 2.54 (0.100 KK series)
at JLCPCB a for conductor part is quite expensive and not in stock..

For Vertical pins:
JLCPCB has B04B-XASK-1(LF)(SN) in stock. JLCPCB part number:  C264994  Price: $0.0735
At Digi-key is a 2.54mm part 455-1994-ND
In stock and price at QT 1 = $0.30
https://www.jst-mfg.com/product/pdf/eng/eXA1.pdf

Mating plug appears to be XARP-04V, Digi-Key Part Number: 455-4152-ND at $0.19000,
JLCPCB had no stock on the plug.

ForrestErickson, 2022-08-02:
Should we be identifying some cable assemblies with the mating connector to order or order the materials necessary to build same?

Having a cable would allow us to check mechanical fit with the enclosure.
Is their a clearance requirement impacting the enclosure?

Order cables in quantity of 15.
Ship to Lawrence.
Lee to identify something to order.

ForrestErickson, 2022-08-02:
For the header S04B-XASK-1(LF)(SN), the mating part shell is: https://www.digikey.com/en/products/detail/jst-sales-america-inc/XARP-04V/9951661  455-4152-ND

The 	Socket Contact Tin 22-26 AWG Crimp is: 455-2050-1-ND

LokiMetaSmith, 2022-08-04:
This looks resolved,

JST-XS and JST-XH share the same crimp shape and the crimp tools are interchangeable.

https://www.amazon.com/XH2-54mm-XH3-96mm-Terminals-SN-01BM-%EF%BC%880-08-0-5mm2%EF%BC%89/dp/B00YGLKBSK/

ForrestErickson, 2022-08-04:
I must admit to fatigue back on 20220802.  The part for which the board is designed is in stock.
IIRC, I am frustrated that I cannot find the mating connector parts or prebuild cables.
This feature (The I2C output) is a wish not a must for V1 and I think we should build V1 assemblies with the design as is and keep trying to find the mating part as time allows.

This issue is NOT ready to close.

LokiMetaSmith, 2022-08-09:
Agreed, we will leave this open until we've tested the connectors out on V1 when those are ordered.

LokiMetaSmith, 2022-08-16:
The digikey order will include compatible plug and male pin connectors to test this out. The purpose of this cable is to jumper between GPAD devices and to allow for cutting in half to provide pig tail connectors for future expansion.
plug shell, with crimpped pins will be ordered and applied to at minimum two cable assemblies.

LokiMetaSmith, 2022-10-04:
Plan on testing mechanical fit by October 5th

ForrestErickson, 2022-10-25:
We have built Version 1 with the JST-XS and JST-XH share the same crimp shape and the crimp tools are interchangeable.

Closed 2022-10-25.

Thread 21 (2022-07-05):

Add some example strings for alarms coming from the PolyVent Ventilator

RobertLRead, 2022-07-05:

RobertLRead, 2022-07-05:
Here are some example calls:

`
int Alarm80(PANIC,"Hose Disconnect. No pressure in the airway.");
int Alarm80(PROBLEM,"PVA: asynchrony at 50% for 5 minutes.");
int Alarm32(WARNING,"FiO2 levels out of spec.");
int Alarm80(WARNING,"FiO2 levels out of spec. FiO2 low by more than 5% for 37% of last 5 minutes.");
int Alarm32(CRITICAL,"Backup battery indicates low battery life.");
`

RobertLRead, 2022-07-05:
@ForrestErickson I did this is quickly, does this answer your question?

ForrestErickson, 2022-07-08:
Regarding, " I did this is quickly, does this answer your question?"
Not at all what I expected. Which is why we ask these questions.

I was expecting something documenting the data that when through the byte interface so more like

`LCD 0,0 Hello World<CR>`
Where "LCD" indicated the destination. "0x0" was the cursor location, "Hello World" was data and "<CR>" was a line termination such as a Carriage Return or a Line Feed for both.

Perhaps also some special functions such as:
`LCD RESET<CR>`
to clear the display.

`LCD CLEAR_ROW 1<CR>`
to clear the second line.

And
`LCD 1,0 Second Line Text `
to put text on the second line.

And
`LCD CLEAR_ROW 1<CR>`
`LCD 1,0 ## <CR>`
to put two hash marks in the center of the second line.

For lights 0 through 4 each of which can have 1-255 levels, something like
`LIGHT 255 255 128 0 0<CR>`
to have lights 0 and 1 fill lit and 2 half lit and 3 and 4 off.

For the audio alert something like
`TONE 440 <CR>`   for a steady tone at 440 Hz
`TONE 440 1000 200<CR>`   for a tone at 440 Hz on for one second and off for 200 mS.
`TONE 0<CR>`   for a tone off.

RobertLRead, 2022-07-08:
Well, the user of the C Library for the GPAD will not be making calls specifically to set TONE, LIGHT, and LCD as you have suggested. I believe the user will call

Alarm80(PANIC,"Hose Disconnect. No pressure in the airway.");

That will then get translated into some byte-level communication which will be sent by SPI. Then, on the GPAD side, there will be code very much as you have written. That is, it is the job of the GPAD's resident code to determine how the get the LCD to display "Hose Disconnect. No pressure in the airway.". Likewise, it will be that code's job to figure how how to turn on the light, and how brightly, or flashing at what rate, to represent PANIC. Similarly, it must determine what the sound for PANIC will be.

This allows different devices implmenting the GPAD interface, or evolving versions over time, to change how they treat the very abstract command: Alarm80(PANIC,"Hose Disconnect. No pressure in the airway."); in different way.

Is that clear?

ForrestErickson, 2022-08-14:
Regarding, "Well, the user of the C Library for the GPAD will not be making calls specifically to set TONE, LIGHT, and LCD as you have suggested. I believe the user will call"

I think this is hat I was calling the GPAD_LIB in the email I wrote  a bit after midnight, morning of 20220814 email.

I would think we instantiate a GPAD device with /CS pin as per the Controller wiring.
The device would get a name such as myGPAD or firstGPAD.
Their would be a method to set the /CS pin number.
Their might be a firstGPAD.begin() which is called in setup. It might return success or failure of the connection.
Their would be a method to ?print? to the GPAD such as firstGPAD.alarm(PANIC, "Hose Disconnect. No Pressure in the airway.");
Other commands
firstGPAD(NORMAL, "Normal.");
firstGPAD(WARNING, "Check battery life");

If a second GPAD is in the system it might be
secondGPAD(CRITICAL, ""FiO2 levels out of spec.");

RobertLRead, 2022-08-16:
I think this will be handled by creating two different objects.

For example, gpad1 and gapd2.
Then we just exeucte:
gpad1.alarm(NORMAL,"Normal").

So I suggest this issue can now be closed.

ForrestErickson, 2022-10-25:
This has served the purpose of promoting discussion and efforts are now around the actual GPAD_API code.

Closed 2022-10-25.

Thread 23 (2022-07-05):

Update schematic per Review of 20220705

ForrestErickson, 2022-07-05:
1. Limit current from / to VBus
2. Limit current from / to ControllerVcc
3. Limit current at barrel input
4. Move C101 to cathode D101 (Will not fix, C101 is to limit rise time on differential mode on power cable for EMC)
5. Add resistive divider to set a fixed contrast on LCD at U302 V0 pin.
6. Add fuse near J501 (USB connector) on power.  (Will not fix, current from USB supplies are limited already to 100mA)
7. Add schottky diode foot print across J102, J103.
8. Should ControllerVcc connect to Input pin 3 of U101?  This is the same as asking do we want the poly vent to supply 12V to the GPAD?
9. Add a full Arduino UNO footprint so that rather than populating U101 and U501 we use the GPAD as a bottom mounted shield for an UNO.  NOTE: Allow for holding on board U101 and U501 in separate reset? if using and UNO?
10. Move I2C pull up resistors to top schematic out of LCD sub page.
11. Add cap to "debounce" S601.
12. Add series resistor to BZ601 to limit current.
13. Add parallel connector to BQ601 for an off board transductor.
14. Check and change schematic symbol for D105, for schottky.

ForrestErickson, 2022-07-09:
20220709.  While adding the UNO schematic symbol and PCB footprint Lee realized that the 3.3V pin has nothing in our design with which to connect.

In the UNO Rev 3 schematic there is a 3.3 V LDO and an op amp circuit switching from Vin to USBVCC through a FET to generate this 3.3V supply.
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

I am going to leave these components out and make the 3.3V pin a No Connect in the GPAD unless someone wants to make a compelling use case.  Adding the UNO foot print is already mission creep.

A NANO foot print might actually be a better idea.

ForrestErickson, 2022-07-09:
20220709 11:50 or so. Lee has pushed the changes into the repository.

Several files in the local folders not yet under control. Many are just vendor diagrams for which Lee may want to add some sub folders and rename. However there are some such as, "GeneralPurposeAlarmDevicePCB.pretty/BarrelJack_CLIFF_FC681465S_SMT_Horizontal.kicad_mod"
that perhaps are needed but Lee does not fully understand.
See:
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

ForrestErickson, 2022-07-09:
Schematic main page screen shot showing with in the sheet the UNO symbol and to the right the NANO symbol:
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

PCB with foot prints pulled in:
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
And the 3D render such as it is:
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

ForrestErickson, 2022-07-09:
All schematic components have foot prints. It might be a good idea for a review of them with fresh eyes.
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

RobertLRead, 2022-07-09:
>

I think people do generally use the Nano if they are integrating it onto a board; but I don't have a lot of experience with this.

ForrestErickson, 2022-07-09:
End of day 20220709 and I still need to get a micro USB part for which I can find, stock, a schematic symbol, a PCB footprint and 3D model.
Currently working towards: https://jlcpcb.com/parts/componentSearch?isSearch=true&searchTxt=C14996 or https://jlcpcb.com/parts/componentSearch?isSearch=true&searchTxt=C132563 which are NOT foot print compatible (At least this late in the day I do not think they are.)

Same for a buzzer of some sort.  Currently working towards: https://jlcpcb.com/parts/componentSearch?isSearch=true&searchTxt=C96256

ForrestErickson, 2022-07-10:
From the KiCAD Facebook group, Lee learned about componentsearchengine.com
Found a schematic symbol and PCB symbol for QMB-09B-03.  https://componentsearchengine.com/part-preview/QMB-09B-03/Jiangsu%20Huaneng%20Elec?type=3d

However there was still no 3D model even though one was pictured.

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

My parts management and library management is become chaotic.

ForrestErickson, 2022-07-10:
Reading the license for the part I down loaded makes me not sure we can incorporate them and "redistribute" them.  NOT SURE.

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

LokiMetaSmith, 2022-07-11:
With regard to the part license, I would include it as we are not distributing it as part of a separate library component and it's tied directly to the General Alarm Device.

RobertLRead, 2022-07-12:
NOTE: We have decided to move all the cable connections to the "bottom edged" of the case. At present, Lee needs to move the USB connector there.

ForrestErickson, 2022-07-12:
After review of 20220712,
Lee removed the Nano foot print.  Fix resulting DRC errors.
Added Test point to UNO foot print for 3v3 pin.  With this change, the GPAD will not supply 3v3 to a shield but we could wire in a 3.3V supply if we really need to.
Changed Test Point names to reflect function two locations.
Minor schematic clean up for readability.

12:22 or so Lee pushed changes to github.

ForrestErickson, 2022-07-12:
While messing with a practice project migrating from KiCad 5 to 6 I added several of the USB parts from the KiCad 6 library to a schematic and a PCB. None of them had 3D models.  Four of them had through hole pins to give them mechanical strength against cable forces.  Two Amphenol, one Molex and One Wuerth

Also found a buzzer with schematic, PCB and 3D model.  TDK : PS1240P02BT and in stock at Digi-key
https://www.digikey.com/en/products/detail/tdk-corporation/PS1240P02BT/935924

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

Found 3D model for Worth: 629105150521
In stock at Digi-Key. https://www.digikey.com/en/products/detail/w%C3%BCrth-elektronik/629105150521/5047751

Here is the 3D view:
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

ForrestErickson, 2022-08-02:
We reviewed on 19 and 26 July and no further required changes identified.
The Version 1 PCB design proposed week ending 20220729 has footprints and 3D models for most parts except the JST connector which has it's own issue.

Let's close this today 20220802.

Closed 2022-08-02.

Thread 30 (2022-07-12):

"HandSoldered" SMT Footprints versus Standard SMT Footprings

ForrestErickson, 2022-07-12:
I left the following question at the KiCad Facebook group

_While learning my way into KiCad I found there are footprints for "HandSoldered" SMT parts like this 0603 resistor.
I assume the down side to using the "HandSoldered" footprint in an SMT production is greater chance of tombstoning.
I have often hand soldered first samples of an assembly and it is tough work and I seldom get the parts well centered.
So any experience out there?_
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

ForrestErickson, 2022-07-12:
Got some responses like this

- Hand solder footprints are great for production. They’re ideal and allow for substituting a 0805 part as needed.
- I used these for my first hand built SMD board. But on my second there was no room, so I used the standard ones. However, I had no issues hand soldering on any of them, so I don't use the hand solder ones any more.
- Same, I normally hand solder the first prototype. Using a standard footprint, it doesn't make it too difficult to solder as I use 0603 as my standard.
- Recommended use a standard footprint for space efficiently and maybe order the Stencil to make your hand solder easier.
- I usually use handsoldered size pads. They work great with hot air gun, oven, iron, whatever. The surface tension of the solder pulls the part to the center of the footprint with hot air and it doesn’t tombstone if you heat it correctly.

Finally this tip seams worth remembering:
Tombstoning typically occurs when one side is heated up quicker (or only) than the other, and if the component isn't secured down, so it just depends on your SMT soldering method.

Lee thinks he may use the "HandSoldered" SMT Footprints.

LokiMetaSmith, 2022-07-15:
This board isn't a tight design, and it's not a high volume production design, so hand placed resistors are fine.

ForrestErickson, 2022-07-29:
I have edited the foot prints for the resistors and capacitors for hand surface mount.
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

Closed 2022-07-29.

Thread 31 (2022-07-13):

Tact Switch Cap, Choice / Design

ForrestErickson, 2022-07-13:
For the GPAD there is a user button next to the buzzer.
Manufacturers with stock at Digi-Key  include TE Connectivity and Omeron
These switches are designed for a Cap or Button which snaps onto the moving part of the switch.
We must find a cap with a compatible height or design one.

For Omeron
For button see:  https://omronfs.omron.com/en_US/ecb/products/pdf/en-b32.pdf
Buttons up to 6x6mm. are available for 6x6 mm tact switches. (for larger button, use 12x12mm switch.)
https://www.digikey.com/en/products/detail/omron-electronics-inc-emc-div/B32-2010/1811718
Manufacturer Product Number: B32-2010
For switch see: https://www.digikey.com/en/products/detail/omron-electronics-inc-emc-div/B3F-1152/368364
Manufacturer Product Number: B3F-1152

For TE Connectivity
Example button will be a 6x6mm tactile switch (tact switch) such as  450-1655-ND
The drawing for which is: https://www.te.com/commerce/DocumentDelivery/DDEController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
I can not find a drawing for the key caps at this time.  I have sent an email to Digi-Key asking for help finding cap drawing and PN.

As of 20220713 the part in the Schematic does not have a cap retention geometry and has only short button:
- Distributor 1	JLCPCB	0	Center	Center	0	0	1.27 mm
- Distributor 1 PN	C13828	0	Center	Center	0	0	1.27 mm
- Distributor 2	Digikey	0	Center	Center	0	0	1.27 mm
- Distributor 2 PN	450-1804-ND	0	Left	Center	0	0	1.524 mm
- Manufacturer	TE Connectivity ALCOSWITCH Switches	0	Left	Center	0	0	1.524 mm
- MPN	TE Connectivity 1825910-7,   Dongguan Guangzhu Industrial C13828	0	Left	Center	0	0	1.524 mm

The length of the switch and the length and size of the cap will be required for design of the enclosure. Must be compatible with the height of the LCD module too.

LokiMetaSmith, 2022-07-19:
Migrate to 12x12mm for the mute switch

ForrestErickson, 2022-07-25:
The Enclosure Design issue:
https://github.com/PubInv/general-alarm-device/issues/29 [Hardware](https://github.com/PubInv/general-alarm-device/issues?q=is%3Aissue+is%3Aopen+label%3AHardware)
#29 should be made dependent on this.

ForrestErickson, 2022-07-25:
The switch in the schematic / PCB for the alarm mute is Omron Electronics B3F-4055.
https://www.digikey.com/en/products/detail/omron-electronics-inc-emc-div/B3F-4055/31799

This switch takes key caps such as:   B32-1310
https://omronfs.omron.com/en_US/ecb/products/pdf/en-b32.pdf
See drawing for full mechanical.
Example:
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

This detail shows a 10mm dimension from the PCB surface to the top of the button. and suggestes the enclosure be designed for 1-2 mm of key rise above the enclosure surface.  So that leaves 8mm for the GPAD pcb to outside surface of the enclosure.

The header which will connect the LCD to the GPAD PCB has a thickness of 0.1" so we will want a 0.125 ?nylon? spacer at the four mounting holes of the LCD to PCB.

Excluding the opening for the LCD the board that mounts the LCD will have a top surface high point of the header pins which measures 0.128 + the 0.125 spacer of about 0.25" or about 6.35mm.
This would allow for something like 8-6.35 = 1.65 mm (or about 0.065") enclosure thickness.

Added https://grabcad.com/library/tactile-switch-thru-12mmx12mm-with-cap-1  to Schematic symbol and PCB footprint .
Pushed to repository at about 13:00 EDT.

ForrestErickson, 2022-07-25:
I have inserted the switch with button model into the PCB.
Top view.
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

Bottom view.
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

**CAUTION the LCD needs yet to be spaced away from the PCB by 0.125.**

LokiMetaSmith, 2022-07-27:
This feature is acceptable, We may create an issue for the enclosure that references this issue for a custom key cap

Closed 2022-07-27.

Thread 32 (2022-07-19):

Board and Enclosure mockup for Prototype #1

LokiMetaSmith, 2022-07-19:

LokiMetaSmith, 2022-07-19:
Move the uno by rotating it 90 degrees such that the connectors come from the bottom.

Move the interfering LEDs vertically such that they are to the side of the LCD display.

Move the reset button and LCD contrast potentiometer to the side of the board with the LCD

ForrestErickson, 2022-07-24:
20220724 0724 push changes to main.
Note I am not sure of the centering on adjustment screw on the silk screen of the contrast control pot.
Should the POWER LED move up and perhaps the contrast control pot move down?
PCB screen shot:
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

3D render Front aka component side:
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

3D render Back aka Display side:
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

ForrestErickson, 2022-07-24:
Oops, J105 is not on grid. Will need to fix once the schematic loads again.
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

ForrestErickson, 2022-07-24:
Fixed the library and schematic error and tweeked the location of J105.

At 16:09 EDT I have pushed the change to github.
Ready for review.

ForrestErickson, 2022-07-24:
The centering on the contrast POT is hard to understand.
The relation between axis where the tool turns the pot and pins and the component outline is more than I can understand this late in my day.

Here is a drawing for the 3/8" part: https://www.bourns.com/docs/Product-Datasheets/3386.pdf

ForrestErickson, 2022-07-25:
20220725 Morning of, I found a 3D model for Arduino UNO on grabcad and made a footprint for it and pulled it in. Good thing too because it made me realized **I have to flip the UNO footprint** from PCB top to bottom to be correct.

Will need to allow for about 0.350 of female connector height and 0.100 of pin header height.
These settings get the PCB flush.
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

For an offset of -.575 which looks like this.
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

Here it is after putting the footprint on back.
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
and
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

I rotated the uController and near buy circuits too.
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

ForrestErickson, 2022-07-25:
New push as of 20220725 10:11 EDT.

ForrestErickson, 2022-07-25:
Possible Spacer for LCD from PCB
https://www.mcmaster.com/94639A702/
Shape	Round
Material	Nylon 6/6 Plastic
OD	3/16"
OD Tolerance	-0.015" to 0.015"
Length	1/8"
Length Tolerance	-0.015" to 0.015"
For Screw Size	No. 4

We will need a screw long enough to go through 2x 0.0625 + 0.125 + thread engagement of 0.125 = 0.375
This part looks good:
https://www.mcmaster.com/90272A108/
Zinc-Plated Steel Pan Head Phillips Screw
4-40 Thread, 3/8" Long
Threading	Fully Threaded
Head Diameter	0.219"
Head Height	0.080"
Drive Style	Phillips

We will need nuts.
Steel Locknuts with External-Tooth Lock Washer
https://www.mcmaster.com/90675A005/
Material	Zinc-Plated Steel
Thread Size
4-40
Thread Type	UNC
Thread Spacing
Thread Fit	Class 2B
Thread Direction	Right Hand
Width	1/4"
Height	7/64"

Shopping cart totals less than $18 exclusive of shipping.
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

ForrestErickson, 2022-07-25:
All parts affecting enclosure on PCB locked with commit pushed at 20220725 about 16:55 EDT.

LokiMetaSmith, 2022-10-04:
Closing this as the V1 boards have been built up.

Closed 2022-10-04.

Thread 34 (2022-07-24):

Schematic Load Error

ForrestErickson, 2022-07-24:
After the push of the schematic and PCB for issue 32, Board and Enclosure mockup for Prototype #1 when I went to reopen the schematic I got this error:

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

ForrestErickson, 2022-07-24:
I cleared the error dialogs and found the LCD... schematic is empty.
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

ForrestErickson, 2022-07-24:
I have two commits as part of my placement work. IIRC I made changes on the LCD page to fix a library error related to the LCD schematic symbol. I had to choose the footprint for the 2004A LCD.

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

ForrestErickson, 2022-07-24:
Here is the line with the error:
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

This is a symbol I was editing this morning.

ForrestErickson, 2022-07-24:
Error when trying to open symbol library:
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

I wonder if it could be the "/" I put in the symbol name?
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

ForrestErickson, 2022-07-24:
And now I am breaking things.
I am working on a branch. I used Notepad++ to find and replace "POT 3/8 10K" with "POT 0.375 10K" in both files.

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

Closed and reopened the schematic with same failure. However I can now open the schematic symbol editor with out the error.

It is at this point I noticed that the GPAD_SCH_LIB.kicad_sym file is not under version control. I assume it is new file type since the converstion to KiCad 6 and I did not add it.
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

So now I have made changes to this un tracked file which seams to have fixed it but I have fixed the schematic but appear to have moved the error.
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

ForrestErickson, 2022-07-24:
It also appears the LCD schematic file name is incompatible with git restore.

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

ForrestErickson, 2022-07-24:
After more scary changes I have success. I put the symbol library under version control. I used Notpade++ and removed the potentiometer from the schematic.
I then placed the renamed symbol into the schematic and updated the PCB. It all loads now.

At 16:09 EDT I have pushed the change to github.

Ready for review.

ForrestErickson, 2022-07-25:
It is a known bug.

See: https://forum.kicad.info/t/invalid-library-identifier-schematic-page-not-load-fixed/36824

Closed 2022-07-24.

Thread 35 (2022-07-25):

Identify and Order Long Lead Parts for Prototype #1 Build, Build Quantity = 15

ForrestErickson, 2022-07-25:
Soon we should identify and order parts for a Prototype#1 GPAD build.
I suggest we order for a quantity of 15 with intent to build 5 and have both spare parts and if all goes well we build up the additional units.  Some exceptions. Order so that we get 5 raw PCBs for mechanical or test and troubleshooting aids.

The orders should be driven by the KiCad BOM and Parts list and the same may need some "maturing" especially with respect to what might be assembled by JLCPCB versus what cannot.

We will need a Digi-key order for some parts we can not get from JLCPCB and the LCD modules from ?Amazon? or ???

Some Digi-key parts in a shopping cart.
https://www.digikey.com/short/wdb03rb9

RobertLRead, 2022-07-26:
Okay, this sounds good. I'm happy to do this with you "pull the trigger". I
leave for the Linux Expo on Wednesday, which may make me a little slower to
communicate.

On Mon, Jul 25, 2022 at 3:44 PM Forrest Lee Erickson <
***@***.***> wrote:

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

--
Robert L. Read, PhD
Twitter: @RobertLeeRead @pubinvention
Public Invention: https://www.pubinv.org
Join Our Mailing list: ***@***.***
YouTube: https://www.youtube.com/channel/UCJQg_dkDY3KTP1ybugYwReg
Medium: ***@***.***

RobertLRead, 2022-07-26:
The deliverable here is 15, and we will order some spares.

ForrestErickson, 2022-08-08:
Robert,
Lawrence,

In addition to the parts for the assemblies the RJ12 break out modules need to be ordered in sufficient quantities for all users. So all users need to be identified too.

RJ12 6 Ft (2M) Data cables:  https://www.amazon.com/NECABLES-Short-Cable-Straight-Wiring/dp/B08BHVF6XS?th=1
RJ12 break out module.   See: https://www.amazon.com/SchmalzTech-Screw-Terminal-Breakout-ST-RJ11-R-MIN/dp/B09KQZG58C
12V @ 1000mA power supply with 2.1mm barrel jack.  See: https://www.amazon.com/ZOSI-1000mA-Adapter-Security-Surveillance/dp/B072PZBT8G/ref=asc_df_B072PZBT8G

RobertLRead, 2022-08-08:
I can order from this, though I think on Tuesday (I know you will miss that
meeting Lee), we are going to do this.

In the future it might be useful to put URLs in a spreadsheet for ordering.

I'm a little unsure how to tell a "long lead" part from any other.

Do you mean that these parts are ready to be ordered right now?

On Fri, Jul 29, 2022 at 11:06 AM Forrest Lee Erickson <
***@***.***> wrote:

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

--
Robert L. Read, PhD
Twitter: @RobertLeeRead @pubinvention
Public Invention: https://www.pubinv.org
Join Our Mailing list: ***@***.***
YouTube: https://www.youtube.com/channel/UCJQg_dkDY3KTP1ybugYwReg
Medium: ***@***.***

ForrestErickson, 2022-08-08:
RE: a long lead is often synonymous with principle components and that is often found by sorting by price.At this point all parts should be ordered and try to capture expected delivery dates becomes the useful way to project when assembly steps can happen.The wrinkle you have is that most parts, but not all, JLCPCB can assemble and that must be tracked so you do not double order or fail to order parts.There is some  stress in managing it.Forrest Lee EricksonCell: 865-518-1040Sent from cell.
-------- Original message --------From: "Robert L. Read" ***@***.***> Date: 8/8/22  10:36 AM  (GMT-05:00) To: PubInv/general-alarm-device ***@***.***> Cc: Forrest Lee Erickson ***@***.***>, Assign ***@***.***> Subject: Re: [PubInv/general-alarm-device] Identify and Order Long Lead Parts
  for Prototype #1 Build, Build Quantity = 15 (Issue #35)

I can order from this, though I think on Tuesday (I know you will miss that

meeting Lee), we are going to do this.

In the future it might be useful to put URLs in a spreadsheet for ordering.

I'm a little unsure how to tell a "long lead" part from any other.

Do you mean that these parts are ready to be ordered right now?

On Fri, Jul 29, 2022 at 11:06 AM Forrest Lee Erickson <

***@***.***> wrote:

> I updated the BOM spread sheet generated from the schematic. The sheet is

> at: GeneralPurposeAlarmDevicePCB.xls

> <https://github.com/PubInv/general-alarm-device/blob/main/Hardware/GeneralPurposeAlarmDevicePCB/GeneralPurposeAlarmDevicePCB/GeneralPurposeAlarmDevicePCB.xls>

>

> I updated the current cost from the distributors.

> Note I have parts into the schematic for the enclosure and the PCB(and SMT

> assembly cost) for which I have no cost.

> I have added no cost for an Aruino either.

> So there are three parts with no price which I have entered as $1,000,000

> just to call attention to them.

>

> Exclusive of these three parts the cost is $21.28.

>

> Robert,

> Please look at the sheet. Can you order long lead parts from this or do

> you want help generating other formats or catagorizing parts?

>

> —

> Reply to this email directly, view it on GitHub

> <https://github.com/PubInv/general-alarm-device/issues/35#issuecomment-1199628026>,

> or unsubscribe

> <https://github.com/notifications/unsubscribe-auth/ABINEH43UBHLSVSZBHOIVQDVWP6PXANCNFSM54TSY6DQ>

> .

> You are receiving this because you commented.Message ID:

> ***@***.***>

>

--

Robert L. Read, PhD

Twitter: @RobertLeeRead @pubinvention

Public Invention: https://www.pubinv.org

Join Our Mailing list: ***@***.***

YouTube: https://www.youtube.com/channel/UCJQg_dkDY3KTP1ybugYwReg

Medium: ***@***.***

—Reply to this email directly, view it on GitHub, or unsubscribe.You are receiving this because you were assigned.Message ID: ***@***.***>

LokiMetaSmith, 2022-08-16:
Moving this to the orderable milestone

ForrestErickson, 2022-09-06:
In hind sight Lee sees that "long lead" was not specific enough for others to work with. Perhaps a field in the parts master (parts list, BOM) would help manage this in the future.

Closed 2022-09-06.

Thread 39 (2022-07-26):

Design for Manufacturing Test / Troubleshooting

ForrestErickson, 2022-07-26:
**DFM DFT,**
Review the GPAD.
Design for Manufacture, Design for Test

- Add test point to all power supplies with labels.
- Decouple all loads so current can be measured.
- Check for access and clearance around all mounting holes.
- Check for instructions for manufacturing and user text on PCB.

**Items when we Write Manufacturing Test / Troubleshooting Procedure**
Place and attach printed wiring assembly into enclosure display side leaving cover off.

For factory test and for trouble shooting.
Record DUT Serial number (assign serial number if first test.)
Begin with no firmware. Measure and record the following.  Compare against limits and troubleshoot as required.
1. Begin with no power supplied.
2. Apply power at USB connector J501 . Measure Supply at all power Test Points at normal loads. Measure current through each decoupling resistor. Disconnect at J501.
3. Apply power at J101. Measure Supply at all power Test Points at normal loads. Measure current through each decoupling resistor. Disconnect at J101.
4. Apply power at J101. Measure Supply at all power Test Points at normal loads. Measure current through each decoupling resistor. Disconnect at J101.
5. Load firmware into DUT and remeasure voltage at all TP and current through all decoupling and capture.
6. Save measurements.  To where?
7. Verify all features fully functional.   How?
8.

Finish assembly.
Apply serial number label.
Final light and play after last screw driven aka, test for IWT (Intermittent with tap) and RWT (Rattle with tap).

LokiMetaSmith, 2022-08-04:
Apply power to J101 first with a current limited power supply. Set the current limit to measured standard  no load current draw up to max current draw. This allows the board to power on safely but catches an over current event without causing long lasting damage to the board in most cases.

LokiMetaSmith, 2022-08-16:
This issue has been agreed to be closed.

Closed 2022-08-16.

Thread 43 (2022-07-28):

Q602 Emitter and Collector Wired Backwards. ERROR.

ForrestErickson, 2022-07-28:
ERROR.  Must change for proper operation.
Unlimited current will flow through Q601 and Q602 if not fixed.

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

ForrestErickson, 2022-07-28:
Fixed.
Admin@Melies MINGW64 /c/Users/Public/Downloads/Arduino/PubInv/general-alarm-device/Hardware/GeneralPurposeAlarmDevicePCB/GeneralPurposeAlarmDevicePCB (main)
$ git merge Q602EmitterandCollectorWiredBackwards.ERROR.#43
Updating e01caf9..5061c3f
Fast-forward
 .../AlarmAudio.kicad_sch                           | 26 +++++++++++-----------
 1 file changed, 13 insertions(+), 13 deletions(-)

Admin@Melies MINGW64 /c/Users/Public/Downloads/Arduino/PubInv/general-alarm-device/Hardware/GeneralPurposeAlarmDevicePCB/GeneralPurposeAlarmDevicePCB (main)
$ git push
Enumerating objects: 10, done.
Counting objects: 100% (10/10), done.
Delta compression using up to 4 threads
Compressing objects: 100% (6/6), done.
Writing objects: 100% (6/6), 1.47 KiB | 1.47 MiB/s, done.
Total 6 (delta 3), reused 0 (delta 0), pack-reused 0
remote: Resolving deltas: 100% (3/3), completed with 3 local objects.
To https://github.com/PubInv/general-alarm-device
   e01caf9..5061c3f  main -> main

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

Closed 2022-07-28.

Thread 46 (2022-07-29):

20x4 LCD Footprint Error (Warning)

ForrestErickson, 2022-07-29:
While it should be a warning, KiCad is set up to return an error it has found in the LCD footprint .

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

This is a detail of the court yard was was inherited from the PCB footprint (which I got I know not where any more).
Perhaps I made it from a 20x2 LCD. I did not draw this feature.

While I can and will short term, set to ignore this error I will try to find time to understand the root cause and modify the foot print to clear it in the future.

LokiMetaSmith, 2022-08-04:
This issue isn't showing up when I run DRC.

ForrestErickson, 2022-08-04:
Regarding, "This issue isn't showing up when I run DRC."

I have probably added it to the exclusion list.

The delete all markers check box may bring up a dialog for finer grain clearing of DRC exclusions.  I do remember once being confused about it all and unable to get back to errors I know I had excluded. I attributed it to my old brain not remembering how to find the dialog but perhaps there is a bug.

ForrestErickson, 2022-11-13:
Notes on clearing this error.
I made a new simple project. I selected an UNO shield template and called the project KiCadLibrary.
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
Using the Symbol and Footprint library managers, I then connected the new project to the libraries in the GPAD folder.

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

I added the LCD to the schematic and annotated it.
I imported new parts into the PCB.
I ran the DRC and reproduced the errors related to the LCD. Courtyard not closed and self intersecting.
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

I right clicked to edit the footprint and turned off all but the front courtyard layer.
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

I selected the suspect lines and moved to the front silk screen layer.
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
Saved the change and reran DRC.

This cleared the errors.
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

ForrestErickson, 2022-11-13:
The work above was only on the local PCB copy of the foot print. So reopened the footprint editor and used Saved As to save into the GPAD library.

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

And selected to overwrite.
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

I added a second LCD to the schematic and updated the PCB to bring it it. I reran DRC and there were no errors for the second LCD.

ForrestErickson, 2022-11-13:
I think this clears this issue with the LCD module.
The interfering mounting holes remain to fix.

ForrestErickson, 2022-11-13:
Note on LCD mounting holes. The LCD measures 0.133 inch diameter or 3.37 mm.
The pad property on the Version 1 PCB footprint is only 2.5mm
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

Change to:
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

Make holes through hole plated and ground. Add to PCB.
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

Closed 2022-11-22.

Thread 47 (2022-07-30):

Route GPAD PCB Prototype Version 1

ForrestErickson, 2022-07-30:
Amusing that no issue was made for this.
Lee has committed a routed PCB as of about 20220729 20:30

While Lee can see improvements, it is ready for review as is.
(If we re ordered the pins driving the LEDs we could reduce the signals crossing over each other.)

Would like other eyes on it.

ForrestErickson, 2022-07-30:
On 20220730 Lee is reviewing the silk screen placement.

ForrestErickson, 2022-07-30:
20220730 9:00 Lee pushed silk screen changes. Done with silk screen review.

LokiMetaSmith, 2022-08-04:
Reviewed PCB layout,

- Footprint, orientation, and arrangment of J105 looks ok.
- Q602 is missing 3D model
- XTAL101 tracing isn't a tuned differential pair and trace length differs
- only one via size used, even with different trace path widths
- no via stitching and ground islands, while all connected, in many cases only have one via
- Several areas where ground pours could be eliminated
- All design rules passed
- F101 is sufficiently sized for it's use case, 1A nominal/8A max below 0.5 ohm in line resistance
- Trace width changes drastically in some areas, some of it looks intentional, and it's assumed it's to improve reliability in areas.
- Part placement and alignment is sufficient for hand assembly, silkscreen designators are easy to read.

Recommend closing this issue, as board seems sufficient for stated goals of v1

ForrestErickson, 2022-08-04:
This is just FYI:   Regarding, "XTAL101 tracing isn't a tuned differential pair and trace length differs"

Traces to pins on a crystal create parallel capacitance. For a crystal in a Voltage Controlled Oscillator (VCOs) such as in a PLL application such parallel capacitance reduces the pull range of a crystal and may need to be taken into account when setting the capacitors which are part of the tuned circuit. For VCOs it is common to remove ground under the crystal and under the traces.  Traces are made thin to reduce capacitance and placed "far" apart from each other.

For our fixed frequency application none of these design constraints apply.

Times have changed and even with googeling for "vcxo design notes" I found nothing helpful to reference.

ForrestErickson, 2022-08-04:
Regarding, "only one via size used, even with different trace path widths"

Dang. It had been my intent to use large vias on the power traces (set to 0.05') and I think I did on the version zero PCB. But forgot about it on this layout. I think there are net class settings for vias in to which I should look and see if I can change my settings so that future PCBs will follow this intent automatically.

For the GPAD there are no high currents where the small vias are going to cause an important voltage drop and so we can use as is.

Thanks to Lawrence for pointing this out.  Lee will make an issue to try to set up KiCad for enlarged Vias on power nets.

ForrestErickson, 2022-08-04:
Regarding, "Several areas where ground pours could be eliminated"

FYI, I have always practiced adding ground pours where they can be with out causing problems because I was told it causes less copper sulfate handling (and waste opportunity) at the PCB fabrication process.

ForrestErickson, 2022-08-04:
Lee recommends closing this V1 issue too.

ForrestErickson, 2022-08-04:
Regarding, "Times have changed and even with googeling for "vcxo design notes" I found nothing helpful to reference."

While not as well explained, this is close to the application notes that helped me years ago better understand VCXO design and shows specifically how the Shunt capacitance (what I was calling parallel capacitance) harms pull range.  It is a very useful thing to know should you ever be in the position to be designing a VCXO.  It is also _very interesting_.

https://www.crystek.com/documents/appnotes/VCXOarticle.pdf

ForrestErickson, 2022-08-04:
Gerbers and drill files generated and zipped. File name: GerbersV120220804.zip

Checked at both JLCPCB and PCBway Gerber viewers and look OK.

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

Check at PCBWAY for holes on UNO footpring.

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

LokiMetaSmith, 2022-08-16:
This has been completed to all parties satisfaction.

Closed 2022-08-16.

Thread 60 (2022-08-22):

PCB doesn't include a way to upload the Arduino Bootloader through the ISP

LokiMetaSmith, 2022-08-22:
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

In a standard Arduino Uno, there is an ISP header which is used to push the initial bootloader onto the device, so subsequent uploads can be pushed through the USB serial interface.

This wasn't done with the GPAD.

A work around is to use the pins brought out on the Arduino Uno header/hat.

ForrestErickson, 2022-08-23:
Re programing the boot loader.
Programing the first one will require some flying wires to a solder less bread board from an already programed UNO.
To the target GPAD connections can  be made for all but the /RESET signal on the RJ12 connector.  One more connection is required, a wire from the programing UNO at D10 to the target at the /RESET pin.

In hind sight a test point on the /RESET net would have been helpful for this operation.

Once we have one GPAD loaded with a boot loader it can program the others with much simpler connection.
To load the boot loader we need connections to the programing RJ12 to target RJ12 with the RJ12 DATA cable.  Connect from the programing GPAD pin D10 to the target GPAD at /RESET.
The RJ12 connection provides power, ground and the SPI interface.
We should document this in the Github repository so that persons building GPAD will not have to figure it out.  If you can make photographs of your setup that would be useful for such documentation.

A helpful note on programing the boot loader here: https://sparkfuneducation.com/how-to/installing-an-arduino-bootloader.html
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

Hope this helps.
Lee

ForrestErickson, 2022-08-30:
Re programing the boot loader.
Programing the first one will require some flying wires to a solder less bread board from an already programed UNO.
To the target GPAD connections can  be made for all but the /RESET signal on the RJ12 connector.  One more connection is required, a wire from the programing UNO at D10 to the target at the /RESET pin.

In hind sight a test point on the /RESET net would have been helpful for this operation.

Once we have one GPAD loaded with a boot loader it can program the others with much simpler connection.
To load the boot loader we need connections to the programing RJ12 to target RJ12 with the RJ12 DATA cable.  Connect from the programing GPAD pin D10 to the target GPAD at /RESET.
The RJ12 connection provides power, ground and the SPI interface.
We should document this in the Github repository so that persons building GPAD will not have to figure it out.  If you can make photographs of your setup that would be useful for such documentation.

A helpful note on programing the boot loader here: https://sparkfuneducation.com/how-to/installing-an-arduino-bootloader.html
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

Hope this helps.
Lee

LokiMetaSmith, 2022-08-30:
This worked, and will be applied to ver1 boards.

we need either a picture or SVG render of the GPAD plus a SVG render of an arduino with the wiring drawings shown to finish documenting this.

ForrestErickson, 2022-12-14:
Closing this because we have uploaded the ?dumoluvo? bootloader with success as documented in the manufacturing notes.

Closed 2022-12-14.

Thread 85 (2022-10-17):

Can't upload firmware

LokiMetaSmith, 2022-10-17:
After initially loading the firmware, it is trivial to upload firmware over the serial interface, but later firmware uploads seem to have issue with communicating with the board.

It appears that even without  the DTR line, we can use the RTS line as it is toggled at the same time. https://forum.arduino.cc/t/does-avrdude-toggle-rts-and-dtr-for-ftdi-reset/635894/2

The suggested wire mod is a 100nF capacitor from pin 4 of U501 to  the nRESET net If that is insufficient, a 100 ohm resistor may also be used.

In the reference Uno schematic, there is no filter capacitor on the reset line, one potential mod is to tombstone C110 such that it is connected to nRESET and pin 4 of U501.

ForrestErickson, 2022-10-17:
Here I document the problem. I change the version in the sketch to something I can distinguish such as 88 and try to upload the sketch WITH OUT pressing the reset button.

 The target was stuck in the "Uploading..." mode
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

After about 60 seconds I gave up and pressed the reset button and the IDE displayed the error message like this.
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

ForrestErickson, 2022-10-17:
Regarding the timing on pressing the reset button when the "Uploading..." message status displays.

I find that If I press as soon as I see the message I get success every time.
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

However, if I count to about two seconds I usually get a failure.
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

LokiMetaSmith, 2022-10-18:
confirmed the workaround, still needs a hardware fix.

LokiMetaSmith, 2022-10-25:
Attempted to rework the U501 but the pitch on the device is too small to reliably fix.

Moving this to HW change to V2 of the pcb

ForrestErickson, 2022-11-12:
# 20221112 Lee tried the rework.
First confirm the DUT was working normaly. It enumerated as COM 16.

## Make modification step by step
Only shorted U501 pin 4 to pin 5. Connected the DUT to the PC. The DUT did not enumerate as a COM device.
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

Note that TP 203 is high.

### Remove the short from U501 pin 4 to pin 5.
The DUT now enumerates.
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
Note that TP 203 is low.
Therefor we cannot simply short from U501 pin 4 to pin 5 to get easy mechanical access to the nRTS pin.

### Move C601 and Wire to U501 Pin 4 Only
Second rework attempt
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

Apply power.
The DUT enumerates as normally.
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
The DUT resets when the USB is attached.

The DUT resets when the Arduino IDE opens the serial monitor as a normal UNO would.
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

## Conclusion
Though very difficult, this rework works so that the GPAD programs like an UNO.  Pressing Reset button is not required.

@RobertLRead
@LokiMetaSmith
Please see the above notes.

ForrestErickson, 2022-11-12:
@RobertLRead
@LokiMetaSmith
Will either of you be able to attempt this rework?

I used ?30 AWG? wire wrap wire and lots of magnification to see what I was doing.
I am not excited about it but am willing to rework any and all units especially units that firmware developers will have.
Once practiced, I am guessing the rework will take me all of about ten minuets each.

Please advise.

LokiMetaSmith, 2022-11-22:
Confirmed resolved, the units can be programmed as described above

Closed 2022-11-22.

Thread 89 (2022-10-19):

Improve the code if the I2C scan for the Liquid Crystal is not found

RobertLRead, 2022-10-19:
This is part of this issue:
[Issue #58 ](https://github.com/PubInv/general-alarm-device/issues/58)

We believe a good first issue would be to improve the output of on the Serial Port if the I2C Liquid Crystal Display is not found, which would probably be a hardware error.

This can be tested by using the WokWi simulator and temporarily changing the schematic to intentional break the hardware circuit.  This would be good practice in WokWi and the coding.

ForrestErickson, 2023-01-03:
@NULLbodyHERE
Hello and happy new year!

Have you seen this issue?
Will you have interest and time to work on this?

NULLbodyHERE, 2023-01-04:
@ForrestErickson
Happy New Year to you too!

Yes, absolutely! :) It was on my to-do list since my last PR and I thought I'd wait to receive the GPAD prototype to make (hopefully) better contributions. I shall get properly stuck into it soon after I recover from this lovely, perfectly timed chest infection. I will shortly get back to you on this matter. Thanks.

RobertLRead, 2023-01-31:
Dear @NULLbodyHERE ,

I hope you are recovered now.  If you have time, we would like you to undertake this issue. Can you get back to us on whether you can undertake this or not?

Lee would be glad to find a convenient time via video chat to confer with you on this.

NULLbodyHERE, 2023-02-02:
Hello @RobertLRead,

Thanks. I should be able to get around to it this weekend. I had hoped that maybe we could sort out my GPAD screen issue so I could use the physical prototype to write better code. I'm happy to proceed nonetheless, using the simulator. I will discuss more with @ForrestErickson as to when we can arrange a video call. Thanks for your patience thus far.

ForrestErickson, 2023-02-03:
Hello Seyi  @NULLbodyHERE ,
I live in the Eastern Time zone which is currently UTC-5.
My Monday and Wednesday mornings and early afternoon's are tied up with a class for some months. But with some advanced notice other days and times are available.

@RobertLRead
Is there a way for us to use the video conferenceing system at:
https://publicinvention.frameable.com/workspace-3983651163842326/1176682421602418?t=957195986196474
I assume that it is available 24-7. and that Seyi may have access.  **Can you confirm this is how we might work?**

NULLbodyHERE, 2023-02-11:
Hello @RobertLRead,

I have made significant improvements on the I2C scan such that the program now stably handles timeout errors. In the I2C scanning mode, the scan is in a continuous looping state, where the terminal is updated once every second so as to indicate that:

1. The scan is still in process and;
2. There are found addresses.

Upon pulling SCL or SDA to ground, the scan is paused and an immediate error message is thrown. The program then attempts to request data and read from the address in question, printing to the terminal the results. Then there is a breakdown message of total errors showing the number of addresses attached to a specific error type. For now, this is only applicable to the target address since every other address is unconfigured and would clog the terminal unnecessarily.

Since we know that we are looking for a specific address and a specific number of devices, the terminal will also notify you whether:

1. The target number of addresses have been found, and;
2. The number of addresses found (including none) despite not reaching the target.

A prompt message will then require the pushing of the mute button to resume the scan. The program should no longer freeze (hopefully), and selection of other test groups can continue. However, there is probably still room for improvement to make it completely robust.

@ForrestErickson please let me know the results of your tests so I can improve on the code. I have tested it several times on my GPAD (SN 1) prototype (just using the terminal with external devices) and made careful adjustments to the I2C timeout variable through experimentation. Feel free to modify the macro `WIRE_TIMEOUT` if you discover a consistent failure to find any address. Also, the Wokwi simulator doesn't seem to take kindly to the 'improvements'. When you break a wire and play the simulation, no messages are printed to the terminal except `--- BEGIN I2C SCAN ---` and `--- TERMINATE I2C SCAN ---`. It is quite limited after all.

Next, to refactor the other sections from the #144 improvement.

Cheers!

RobertLRead, 2023-02-11:
Dear Seyi,

This sound pretty cool. I'm a little hazy on what the original problem was,
but it sound like you're doing a great job addressing it.

On Sat, Feb 11, 2023 at 9:21 AM NULLbodyHERE ***@***.***>
wrote:

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

--
Robert L. Read, PhD
Twitter: @RobertLeeRead @pubinvention
Public Invention: https://www.pubinv.org
Join Our Mailing list: ***@***.***
YouTube: https://www.youtube.com/channel/UCJQg_dkDY3KTP1ybugYwReg
Medium: ***@***.***

ForrestErickson, 2023-02-12:
@NULLbodyHERE

SWEET!

I will add to my growing back log to test this too.

Regarding, " When you break a wire and play the simulation, no messages are printed to the terminal except --- BEGIN I2C SCAN --- and --- TERMINATE I2C SCAN ---. It is quite limited after all."

Could you try a switch to ground as a way to impair the I2C bus during run time?

NULLbodyHERE, 2023-02-14:
@ForrestErickson

As far as I'm aware, you can't dynamically change the state of the simulation. You must stop it, make amendments, and then play it. Even when I do stop it and change either the SDA or SCL to ground or just break the line, It still produces only the messages "BEGIN" and "TERMINATE" for some reason.  Please correct me if I'm wrong about the simulation. In any case, it will require further investigation.
Cheers.

ForrestErickson, 2023-02-14:
Send me a link to your simulation please.Forrest Lee EricksonCell: 865-518-1040Sent from cell.
-------- Original message --------From: NULLbodyHERE ***@***.***> Date: 2/14/23  8:42 AM  (GMT-05:00) To: PubInv/general-alarm-device ***@***.***> Cc: Forrest Lee Erickson ***@***.***>, Mention ***@***.***> Subject: Re: [PubInv/general-alarm-device] Improve the code if the I2C scan
  for the Liquid Crystal is not found (Issue #89)
@ForrestErickson
As far as I'm aware, you can't dynamically change the state of the simulation. You must stop it, make amendments, and then play it. Even when I do stop it and change either the SDA or SCL to ground or just break the line, It still produces only the messages "BEGIN" and "TERMINATE" for some reason.  Please correct me if I'm wrong about the simulation. In any case, it will require further investigation.
Cheers.

—Reply to this email directly, view it on GitHub, or unsubscribe.You are receiving this because you were mentioned.Message ID: ***@***.***>

NULLbodyHERE, 2023-02-16:
@ForrestErickson
It's this link: https://wokwi.com/projects/345960281987351124 except that you need to manually copy and paste the updated code, since the page hasn't been updated to the latest firmware version.

ForrestErickson, 2023-02-16:
@NULLbodyHERE ,
Oh I inferred that you had set up your own Wokwi simulation. This is a link to mine. Also I had assumed you had experimented with additional code changes not yet committed.

Please clarify.

I have made a Wokiwi copy with the V1.32 code and added buttons to short the SCL and SDA lines during run time.
Try it : https://wokwi.com/projects/356858915742940161

_I sure am having fun!_

ForrestErickson, 2023-02-16:
@NULLbodyHERE

Here I made a run time error by pressing the Yellow button during the LCD test.
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

NULLbodyHERE, 2023-02-18:
@ForrestErickson
In future, I'll make sure to set up my own link to reference.

> Also I had assumed you had experimented with additional code changes not yet committed.
No, this was with code that had been committed in v1.31.

In any case, it looks like you have creatively come up with a workaround to test that part of the code virtually. Great idea!
Cheers.

ForrestErickson, 2023-02-18:
@NULLbodyHERE
Regarding, "In any case, it looks like you have creatively come up with a workaround to test that part of the code virtually."
Yup it was a delight to do and wanted to share with you.

I am about to start my day which will be to take a telescope to our local library with a solar filter so I am about to be unavailable. Hope your day was a good one.

RobertLRead, 2023-06-20:
fixed.

Closed 2023-06-20.

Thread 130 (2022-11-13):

Lee's KiCad 3D View Missing Models Once There

ForrestErickson, 2022-11-13:
## Left something like this request for help on the KiCad Facebook group.

Not sure when it happened.
I have lost a bunch of 3D foot prints from my design that were there at one time.
For example this RJ12 connector.
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
You can see the red circle with the "x" . When I cursor over it a pop up says "File not found".
So I am guessing some how I have mucked up paths to where the file was to be found.

Can anyone give insight regarding "KIPRJMOD" in that path?

Also attached (and which I do not understand but would like to) is the "Configure Paths" dialog.

Also attached is my project view showing project libraries

My project is in a path with name: C:\Users\Public\Downloads\Arduino\PubInv\general-alarm-device\Hardware\GeneralPurposeAlarmDevicePCB

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

ForrestErickson, 2022-11-13:
When opening the Footprint Editor this error message comes up too.

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

ForrestErickson, 2022-12-08:
I found the models in a confusingly named sub folder. I have copied the models into the folder where they apparently were at one time.  There are a bunch of other part files I am not sure I want to commit in that folder of confusion.

Front copper view:
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

Bottom copper view:
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

ForrestErickson, 2022-12-21:
I think that all of the missing 3D are back.

I think the root cause was I was trying to clean out folders of files I did not want to commit by moving them and these 3D models were in the folder to which  KiCAD still required access.  It could be I even thought that some how the 3D files were added to the library which in my current understanding is not the case.

Closing as fixed 20221221

ForrestErickson, 2023-02-21:
This is closed.

Closed 2023-02-21.

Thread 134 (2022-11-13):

Add UNO Like Pin Names to Headers, Version 2 PCB

ForrestErickson, 2022-11-13:
Will make testing and development easier.

LokiMetaSmith, 2022-11-21:
This was in the sheet as a note, I would add them to the silk screen, and add an extra net name with them.

ForrestErickson, 2022-12-08:
20221208 Added text to footprint for UNO3 with and with out mounting holes in General Purpose Alarm Device library.

Closed 2023-01-31.

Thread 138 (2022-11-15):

Make Photo of Rev2 Enclosure with GPAD Light up and Playing for our Home Page

ForrestErickson, 2022-11-15:

RobertLRead, 2022-11-15:
Here is the photo I took:

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

ForrestErickson, 2022-11-15:
@RobertLRead ,
@LokiMetaSmith

I note how the LEDs are resessed below the enclosure.

I left some additional lead length Perhaps they could be moved up another 3/16 or more.

We need assembly instructions on setting the LED height at solder time.

RobertLRead, 2022-11-15:
Yes, this is an issue---in fact, I had to adjust them a bit by hand
(bending them to line up.)

The simplest thing is to just make the leads a little longer and possibly
make the holes for them slightly larger to be sure that the lens of the LED
can fit inside them

On Tue, Nov 15, 2022 at 3:34 PM Forrest Lee Erickson <
***@***.***> wrote:

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

--
Robert L. Read, PhD
Twitter: @RobertLeeRead @pubinvention
Public Invention: https://www.pubinv.org
Join Our Mailing list: ***@***.***
YouTube: https://www.youtube.com/channel/UCJQg_dkDY3KTP1ybugYwReg
Medium: ***@***.***

LokiMetaSmith, 2022-11-21:
The screen is the tallest part of the device, and I can increase the size of the holes pretty easily so the LED's protrude. I think we should fix that as a feature, and I can print out a quick slotted block that holds the led's in place. Technically, they make such things, but when you have a 3D printer, everything looks like a solution looking for another 3D print.

can we get a side profile view of the connectors, a top view of the screen?

What I see working is the speaker holes, the button height could come down a little bit (question for @RobertLRead ), and it's hard to tell, but is the screen perfectly aligned? it looks like it's offset and needs to come down a bit.

RobertLRead, 2022-11-23:
It appears to me that the screen is about 1mm hither than the orifice (that is, the orifice could come down a bit.) @LokiMetaSmith

For the photos you requested, please see: [](https://github.com/PubInv/general-alarm-device/issues/146)

ForrestErickson, 2022-11-23:
Lee added GPAD in Prototype Enclosure image to the main README.md at the GPAD root.

Closed 2022-11-23.

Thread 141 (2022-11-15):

Need Assembly Instructions on Setting the LED Height at Solder Time.  Version ?2? Enclosure

ForrestErickson, 2022-11-15:
The Version ?2? enclosure at @RobertLRead  location when assembled with the Version 1 PCB with LEDs set for the same height as the LCD has zero LED protrusion.

Perhaps could be set higher.
Perhaps a spacer of some sort to set height.
Perhaps a fixture to holed at the correct height while soldering.
Perhaps some gauge for go-nogo on the height would help the operator.

@LokiMetaSmith did you have further ideas / intentions on making a spacer for the LEDs?

LokiMetaSmith, 2022-11-22:
It'll need a plastic spacer to hold the LED's in place. Without the spacer, the risk of misalignment on long leaded LED's is too high.

LokiMetaSmith, 2023-06-20:
Spacers
https://github.com/PubInv/general-purpose-alarm-device/blob/main/Hardware/Enclosure/U_Box_V105_GPAD_LED_Standoff_single.stl

Closed 2023-06-20.

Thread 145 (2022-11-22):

Determine values for R306 and R308

LokiMetaSmith, 2022-11-22:
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

We have enough boards in hand that we can measure the resistor value needed to populate R306 and R308, which would make the potentiometer RV301 redundant.

This should be done to remove a hand assembly element to the board, with the assumption that the displays used are consistent in their contrast ratio

ForrestErickson, 2022-11-22:
RV301 sets the voltage into the LCD called V0
Regarding setting V0 with fixed resistors.
During the assembly of five units in Maryville I captured the voltage to which I set the DUTs by serial number into a table in the document: https://github.com/PubInv/general-alarm-device/blob/main/Hardware/Documentation/ManufacturingUnitTestTroubleshooting.md
See table below.
I did not evaluate the rage of voltages to which I could set the display for "acceptable contrast" nor have I explored defining "acceptable contrast" which I know must include off axis viewing angle on a cone (A quick sample size one check shows that the characters become invisible at what I am guessing is greater than 60 degrees off axis but less than 80 degrees..  Nor have I explored temperature variation.

We should note which vendor we are testing. IIRC we have displays from two different distributors but we do not know the ultimate manufacturer.

If I had willing technical help. I would suggest characterizing these unknowns and only then making a decision on fixed resistors.

Other factors.
The reoccurring part cost of the Bourns potentiometer is listed as 0.6963.
The reoccurring cost to adjust in the factory test is TBD but it takes turning a screw driver and I always did it with a multi meter so that I could watch the multimeter and aim for a target voltage similar to previous displays.  Let's assume 3 minuets.
Last time I worked for compensation it was at about 0.64 per minuet so my labor cost would be $1.92
Total material and labor cost might be about $2.62.  The cost for fixed resistors will be negligible.

So how many units would we have to build to break even to recover the engineering cost to determine if we can choose fixed resistors and testing our assumption.
If it takes one day the engineering cost might be something like 8 * 100,000/2080 = $384.  So less than 100 units for break even.
If it takes one week the engineering cost might be something like 40 * 100,000/2080 = $1923.  So about 733 units for break even

That was a fun "what if?"

Table screen shot:
> 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

ForrestErickson, 2022-12-14:
@LokiMetaSmith  I just assigned you and me to this issue.
As you can see from my notes above I am hoping you capture the V0 voltage which produces good contrast on the remaining units and for each vendor of LCD so that we can learn as much as we can about device to device variation and vendor to vendor variation for insight into this decision.

If we use 5% resistors then we need to verify that with a 5% variation from the nominal Vo that all units have good contrast. And of course I have not put much thought into defining "good" contrast such that it is a measurement. (We physicists like measurements.)

If we had a priority ranking on Issues I would lobby for this to be of the lowest priority.

Closed 2023-01-31.

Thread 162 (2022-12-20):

PCB Version 1, R103 and D102 (BUILTIN_LED) Incompatible With Level Shift on PolyVent_SPI_Controller Version 1

ForrestErickson, 2022-12-20:
# As built PolyVent_SPI_Controller Version 1 Not Driving GPAD Version 1 as built.
The PolyVent_SPI_Controller Version 1 as built in December 2022 was tested and not able to drive the SPI clock signal SCK to the full expected 5 volts when connected to the GPAD.

## Problem Details
Screen shot at nCS (chip select), yellow, and SCK in blue. The SCK is measured at the interface to the GPAD and was expected to be 5V when high
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

## Problem Analysis
Review of the design showed that the resistor and LED equivalent to the BUILTIN_LED of Arduino UNO was loading the level shifter. The level shifter circuit is a resistive pull up (not a totem pole logic output) adapted from an I2C level shifter. This resistive pull up scheme was too current limited to drive the signal to the required high logic level.

## Solution for GPAD Version 1.
Remove R103.
20221220 Rob removed R103 and then the PolyVent was able to communicate to the GPAD.

ForrestErickson, 2022-12-20:
To do
Lee to change schematic for Version 2 PCB to make R103 DNI.
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

ForrestErickson, 2022-12-20:
Lee updated the rework notes at:
https://github.com/PubInv/general-alarm-device/blob/main/Hardware/Documentation/ManufacturingUnitTestTroubleshooting.md

to reflect "Remove and Relocate R103 and D102"  as per Version 2 PCB screen shot below.

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

RobertLRead, 2022-12-20:
This screen shot appears to highlight R112, not R102...can you clarify?

On Tue, Dec 20, 2022 at 3:36 PM Forrest Lee Erickson <
***@***.***> wrote:

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

--
Robert L. Read, PhD
Twitter: @RobertLeeRead @pubinvention
Public Invention: https://www.pubinv.org
Join Our Mailing list: ***@***.***
YouTube: https://www.youtube.com/channel/UCJQg_dkDY3KTP1ybugYwReg
Medium: ***@***.***

ForrestErickson, 2022-12-20:
Regarding " R112, not R102"

The rework is to  Relocate R103 and D102.
They become R112 and D106.

I have created some what (I hope) better documentation in the document at:
https://github.com/PubInv/general-alarm-device/blob/main/Hardware/Documentation/ManufacturingUnitTestTroubleshooting.md

Which reminds me that firm ware should be changed to put the Wink LED onto A3 pin.
Which could be a Wokwi test too.

I will make a separate issue if there is not already one.

ForrestErickson, 2022-12-22:
Note direct drive of the GPAD with ESP32 3.3V signals is found to work (The GPAD received data and wrote date back to the ESP32). (It was found once the R103 is removed. but had Lee not put a 1K series termination in line with the ESP32 SCL line would probably have worked first try.

Signals using direct drive from ESP32 for nCS, SCK, COPI, CIPO for traces 1, 2, 3, 4.
For CIPO there is a 1K into 2K resistive divider providing 5V to 3V level shift and this measurement is at the divider.
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

LokiMetaSmith, 2022-12-27:
For version 2, relocate D106 such that it is visible with a shield mounted to the pcb.

Closed 2023-01-31.

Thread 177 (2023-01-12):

Firmware Testing, Branch: Rob-Create-Serial-Transfer-SPI-Pair, GPAD_API_SPI_CONTROLLER.ino and GPAD_API.ino

ForrestErickson, 2023-01-12:
# Testing Summary
On 20230111 Lee used **git pull** and updated his local clone of the PubInv repository.

* The Controller side has no LCD display but shows serial port reporting of data being sent to the SPI interface.
* I do not get any alarm results on the Peripheral GPAD side on the serial port nor LCD nor LIGHTS nor Buzzer.
* I think I have found corruption of the GPAD such that loading even the I2C scanner does not work
**I recommend no other GPAD devices be loaded with the Firmware in the, Branch: Rob-Create-Serial-Transfer-SPI-Pair**

# Testing Notes
## Journal of "Out Of The Box" testing
Switched to the Rob-Create-Serial-Transfer-SPI-Pair branch.
Loaded firm ware GPAD_API_SPI_CONTROLLER.ino into GPAD SN#6(COM16) and and GPAD_API.ino into GPAD SN#2(COM15).

Neither device has LCD display.
On the controller GPAD_API_SPI_CONTROLLER.ino into GPAD S#6(COM16) we see the following serial port activity.
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

On the GPAD S#2(COM15) the serial port does not show program name but only what I assume is a version number " 0.07"
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
There is no further activity.

## Other testing
I am concerned that the LCD is not displaying.

On the Controller
On GPAD S#6(COM16)  loaded the I2C scanner program and the expected message of "I2C Scanner" only appears as " I2C"
The address for the I2C interface for the LCD does NOT appear.
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

On the Perihperial
On GPAD S#2(COM15) loaded the I2C scanner program.  The expected message of "I2C Scanner" appears as well as "Scanning..."
The address for the I2C interface for the LCD does NOT appear.
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

# Caution
This is very concerning.  The "\nI2C Scanner" message is part of the setup() function of the I2C scan and the message "Scanning..." is in the loop().  The two GPADs are not operating normally and not even operating the same.

**I recommend no other GPAD devices be loaded with the Firmware in the, Branch: Rob-Create-Serial-Transfer-SPI-Pair**

ForrestErickson, 2023-01-13:
20230113 Resume testing.
Tried to reboot the Arduino IDE.  It failed to close. Reboot PC.
Starting fresh. Lets load the "i2c_scanner" into each DUT.

* GPAD S#6(COM16)
This Device had the GPAD Controller firmware once loaded. THen I loaded the Factory Test V1.30 to try to rest it.
This screen capture shows the Factory test version 1.30 failing to find the I2C LCD interface and is followed by the I2C scan which does not find the LCD interface nor does it terminate as it should.
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

* GPAD S#2(COM15)
This screen capture shows the version 0.07 of the Peripheral device GPAD_API followed by the I2C scan which does not find the LCD interface nor does it terminate as it should.
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

Note that the two GPADs fail the I2C test differently.

Here is oscilliscope captures on both I2C busses.
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

* CH1 is GPAD S#2(COM15) SCL
* CH2 is GPAD S#2(COM15) SDA
* CH3 is GPAD S#6(COM16) SCL
* CH3 is GPAD S#6(COM16) SDA

Note that the SCL is not 5Vp-p as it should be.

RobertLRead, 2023-01-13:
This is very confusing; do we believe that SOFTWARE caused this error?  It
seems to have occurred upon loading my new software, but it is hard to
understand how it could permanently damage the LCD even when other software
is reloaded. Is that what we are observing?

On Fri, Jan 13, 2023 at 11:26 AM Forrest Lee Erickson <
***@***.***> wrote:

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

--
Robert L. Read, PhD
Twitter: @RobertLeeRead @pubinvention
Public Invention: https://www.pubinv.org
Join Our Mailing list: ***@***.***
YouTube: https://www.youtube.com/channel/UCJQg_dkDY3KTP1ybugYwReg
Medium: ***@***.***

ForrestErickson, 2023-01-13:
Measure SDA at the I2C expander chip U301 and there it is also of reduced amplitude. The pull up resistor on SDA R108 is going to +5V (same as the pull up for SCL).  So either the I2C expander chip U301 or the ATmega328 U102 is loading the signal.

Here CH1 is SCL at the header pin and CH2 is SDA right on U102 Pin 27.
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

Next I hold U102 in reset.
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
SCL goes to +5 but SDA only goes to 2V.

Need to find what is clamping SDA to no higher than 2Volts.

ForrestErickson, 2023-01-13:
Regarding, "do we believe that SOFTWARE caused this error?  "
It is hard to image a way that it could.  That would be some mighty powerful voodoo to do that.
The I2C line is supposed to be a "wired or" connection where a resistor pulls the line high (5V) and either the controller or peripheral can sink current to pull low.  The only way their might be a chance to make something bad happen would be if the Peripheral tried to pull the SDA low while an incorrectly configured Controller SDA had an active pull up to high. Then their would be high currents in both parts.  A failure on IO pins would usualy be to GND or to VCC. It is hard to imagine to 2V.

Back to pondering.
On the SDA line there are four connections.
1. U102 the uController,
2. U301 the I2C expander,
3. the pull up resistor R108 and
4. the series resistor R105 which brings the signal out to J105.

If  it were easy to unsolder either or both integrated circuits that would leave only the pull up resistor to +5 and I would bet a shinny copper penny the line would go high to +5. But it is not easy to unsolder either part.

Next I try a second 1K pull up in parallel to R108 to see if the SDA goes higher.  I connect at the header pin for A4.
Measure the voltage and only goes from 1.85 to 3.14 as measured by multimeter.  ALSO the SCL and SDA waveforms stop having square waves and go to high. SCL to 4.8 and SDA to 2.2 as measured by oscilloscope.
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

Pulling SDA to GND through the 1K and the voltage goes to 1.65.
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

Next Get Insight Into Where Current on SDA is To and From.
Measure the current into the uC U102 by measuring the voltage across R101. This is done by measuring the voltage at +5V test point minus VccController test point.  When the system under test is in reset the voltage is 6.8 mV (current draw is 6.8 mA) and when I load SDA line with additional 1K the voltage becomes 7.2mV (current draw is 7.2mA) so there is a difference of 0.4 mA.
For a 1K resistor on about 2.2V to GND the current is about 2.2 mA.
The VccController net is supplying the pull up for R108 so the change of 0.4 mV at VccController is in part do to the change in voltage as SDA has 2.2 mA pulled from through R108.

Measure the current into the uC U301 by measuring the voltage across R310. This is done by measuring the voltage at +5V test point minus VccLCD test point.  When the system under test is in reset the voltage is 59.5 mV (current draw is 59.5 mA) and is the same when the additional 1K to SDA is added to GND. Therefor it appears that the current is NOT going through U301 the I2C expander.
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
ForrestErickson, 2023-01-13:
How I switched to the Tag with the Factory Test V1.24
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

ForrestErickson, 2023-01-13:
The 1K resistor plugged into A4 socket and clip lead to +5V.
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

ForrestErickson, 2023-01-13:
@RobertLRead
@LokiMetaSmith

Regarding the trail of trouble shooting notes above, I conclude that something is sinking current from the SDA line on both of my GPAD units S#2 and S#6. It was noticed when I tried to evaluate Rob's branch "Rob-Create-Serial-Transfer-SPI-Pair"
I think it happened when I loaded and ran this firmware for the Controller and the Peripheral.

**HOWEVER**, I can also say that it has been some time since I was running any firmware which addressed the LCD because I had been working with the buzzer for quite some time and none of that firmware had LCD code in it.

So far as I can figure out, with out cutting a trace, I cannot further isolate U201 from U301 as the path for the current sink.
I am going to let this stew in my brain for a bit before I cut traces. Regarding cutting traces I will not be very hard but I want to stew a bit before I cut.

I have a clear access to the trace where I could cut as highlighted in this screen shot.
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
It would be easy to repair after the cut.

Once cut and power applied to the DUT the SDA will either:
1.  go up to 5V which would indicate that the uController U201 is at fault,
2. Or SDA will go up to about 2V indicating the I2C expander is at fault
3. or something else indicating I have not figured out all the contingencies.

Regardless I am going to stew.

In order

RobertLRead, 2023-01-13:
I can endeavor to do this tonight when I have instructions. My rework
ability may not be as developed as yours is.

On Fri, Jan 13, 2023 at 2:13 PM Forrest Lee Erickson <
***@***.***> wrote:

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

--
Robert L. Read, PhD
Twitter: @RobertLeeRead @pubinvention
Public Invention: https://www.pubinv.org
Join Our Mailing list: ***@***.***
YouTube: https://www.youtube.com/channel/UCJQg_dkDY3KTP1ybugYwReg
Medium: ***@***.***

ForrestErickson, 2023-01-14:
I used at 1K pull up resistor and that is a sample size of one.   Assuming the same problem, the leakage may still be different from assembly to assembly.

On both S#2 and S#6 I have SDA at 2.64 Volts. Holding the uController in reset by holding S101 closed should make the measurement independent of any firmware.

ForrestErickson, 2023-01-14:
Simpler test would be to straddle a leaded resistor to the very next pin for +5V at this indicated spot.
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

Soldering a resistor on top of R108 would also work.
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

RobertLRead, 2023-01-14:
Dear Lee,

I have attempted to perfrom this experiment on board #5. I have clipped a 5V signal off the left of the card with an aligator clip to a 1168 Ohm resistor (measured with my multimeter.) This measures a steady 5.035 V against a ground measured from one of 4 mount holes on the board. Board number 5 does not have a header soldered in, but I place it in the whole and bend it so that I am pretty sure it is making contact. When I reset the card, the LCD still does not activate. I have followed your instructions have reverted to code GPAD_Factory_Test v1.24. The output of the serial port at reboot is shown below:
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

ForrestErickson, 2023-01-14:
@RobertLRead
That looks like it should work.
With a multi meter set for DC voltage measure at the resistor lead connecting to the PCB as indicated here.
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

RobertLRead, 2023-01-14:
5.27 Volts

On Sat, Jan 14, 2023 at 5:21 PM Forrest Lee Erickson <
***@***.***> wrote:

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

--
Robert L. Read, PhD
Twitter: @RobertLeeRead @pubinvention
Public Invention: https://www.pubinv.org
Join Our Mailing list: ***@***.***
YouTube: https://www.youtube.com/channel/UCJQg_dkDY3KTP1ybugYwReg
Medium: ***@***.***

ForrestErickson, 2023-01-16:
20230116 7AM
Because Robert found a different voltage I suspected some difference and found it.
I introduced an error on my two assemblies when I relocated the BUILTIN_LED off of D13 to A3 to become a WINK_LED (and resistor).
I mistakenly moved the relocated LED to the SDA trace not A3.  Once I moved the LED and resistor the SDA had normal amplitude and the static measurement of SDA is 5.02 VDC.
I will load an updated photo of the rework.

ForrestErickson, 2023-01-16:
Rework

ForrestErickson, 2023-01-16:
The problem @RobertLRead  is having with LCD on a unit remains unresolved.

ForrestErickson, 2023-01-16:
I have annotated the SCL and SDA pins on Roberts photo.
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

Here are hilighted traces for SCL up to the pin on U301 Pin 14 too.
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

Same for SDA  U301 Pin 15
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

And the power into U301 Pin 16
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

Ground is on pin 8, the diagonal corner from power.

Closed 2023-01-16.

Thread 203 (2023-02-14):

Finalize order and purchase new PCB (Rev 2)

RobertLRead, 2023-02-14:
Review the Rev 2 PCB, then order 15 new populated boards.

Also, order 5 3d printed cases.

Our goal here is to have at least 3 fully functional devices to have at the OSHWA table in April 28th in New York.

LokiMetaSmith, 2023-02-14:
- [ ] Make modifications for louder Piezo
- [ ] Review GPAD schematic
- [ ] Review 3D printed STL files
- [ ] Review Design for Manufacturing JLCPCB
- [ ] Review gerber files
- [ ] Export gerber files
- [ ] Export STL files
- [ ] Order

ForrestErickson, 2023-02-21:
On 20230221 Lee has fixed the pin numbering problem on the I2C connector J105 and moved J105 closer to the edge of the PCB.
As of 10 AM still reviewing issues for more actionable items.

ForrestErickson, 2023-02-21:
Updating some silk screen locations. Run DRC and get only the expected warnings.
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

ForrestErickson, 2023-02-21:
Generated step file of the PCB produced  a large report with a lot of parts not converting.  Not a blocker but something for information only.

RobertLRead, 2023-06-20:
Done.

Closed 2023-06-20.

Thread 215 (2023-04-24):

The GPAD_API should be updated to reflect the change of the buzzer in Rev 2.0 PCB

ForrestErickson, 2023-04-24:
Similar to Factory Test for Rev 2.0, Change the Buzzer Test from Tone to Simply High #214

The GPAD_API should be updated to reflect the change of the buzzer in Rev 2.0 PCB

ForrestErickson, 2023-07-08:
Adding @RobertLRead , @NULLbodyHERE  and @ForrestErickson  to this issue.

Capturing some recent email traffic here:

An email from Robert to NULLBodyHERE

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

ForrestErickson, 2023-07-08:
@RobertLRead , @NULLbodyHERE

Caution two GPAD hardware versions.

Please note there GPAD with PCB version 1, serial numbers 1-15 have a piezo transducer which can be driven by the tone() command at any frequency the tone() command supports but is not very loud.  If a moving coil speaker is attached to the connector (?J601 IIRC) then there is much move volume.

The GPAD Version 2 are serial number 16-30 and have a "buzzer" which makes a continuous tone which cannot be changed when the GPIO line to which the tone() command in our previous firmware (Version TBD???)  When you write at tone() to the buzzer the result is an intermodulation of the tone() frequency you set with the (again IIRC ) 2.4 KHz of the buzzer.  The result is not harmonically pleasant sound. The result is not as loud as simply setting the GPIO high and turning on the buzzer.

So as you work with new firmware keep in  mind the target hardware for which you are developing and on which you are evaluating.

ForrestErickson, 2023-07-08:
An email from Robert Reed,

Objet : Significantly improved audio system....

Dear Team,
I just committed new GPAD main code which allows you to program "songs" corresponding to each of the 6 alarm levels. The number in the below is the "index" into the:

 const int BUZZER_LVL_FREQ_HZ[]= {0,128,256,512,1024,2048};

array to play at each 500-ms "tone" in the song. I don't use index 5 because at 2KHz it is (to my ear) to high pitched to be loud (though I have a high-frequency hearing loss.

You will notice I programmed some alternating "songs". I have attempted to do "urgency matching" --- that means as the alarm level increases, it should sound increasingly urgent, although that may be to some extent culturally dependent.

Seyi, I have sort of stepped on what I asked you to do, but there is still room for experimentation and improvement here (if you have a GPAD with our latest, louder buzzer.)  So hopefully I have not "jerked you around", but made it easier for you to experiment with, if you want to and have time.

I did this mostly so that in the paper I could say we have good audio cues. In fact, we had been simply using a steady tone of increasing frequency. That is arguably not very good at all.

const unsigned int NUM_NOTES = 20;
const int SONGS[][NUM_NOTES] = { { 0,0,0,0,0,0,0,0,0,0,0,0,0,0,0,0,0,0,0,0},
 { 1,1,1,1,1,0,0,0,0,0,1,1,1,1,1,0,0,0,0,0},
 { 2,2,0,2,2,0,0,0,0,0,2,2,2,0,2,2,0,0,0,0},
 { 3,3,3,0,3,3,3,3,0,3,3,3,0,3,3,3,0,0,0,0},
 { 4,0,4,0,4,0,4,0,0,0,4,0,4,0,4,0,4,0,0,0},
 { 4,4,2,0,4,4,2,0,4,4,2,0,4,4,2,0,4,4,2,0}};

const unsigned LEN_OF_NOTE_MS = 500;

unsigned long start_of_song = 0;

ForrestErickson, 2023-07-08:
An email from NULLbodyHERE

Dear Robert,

Thank you for the additions you have made to this task. I should have communicated earlier that my plan was to finish it this weekend, after having recently retrieved my GPAD prototype (from my items currently sitting at my uncle’s place). I mistakenly forgot the power cable, so I resorted to the Wokwi simulated version. In any case, I’m grateful for your implementation!

I have made slight modification to the songs such that they are (in my opinion) more distinguishable from each other. Each level, except level 5, will include the level number in each phrase. For example, level 2 will issue a 2-note phrase, and level 4 will issue a 4-note phrase (nee-naw-nee-naw -break-). But also, the frequency of the phrase increases (to a certain extent) as the rest between each phrase decreases with rising alarm level. Level 5 is a constant two-tone alarm, giving it a distinct sound that is hard to ignore due to the lack of breaks.

Hopefully my changes are appropriate. If not, please modify them to your liking. I’ll soon be more setup to work on this project a little bit more, as I’m moving some of my stuff in pretty soon. Thanks for your patience and all the best with the remainder of the paper/code changes.

ForrestErickson, 2023-07-08:
@RobertLRead ,
@NULLbodyHERE

When you evaluate your work please make note on which hardware version you tested and which device serial number and any modifications.

ForrestErickson, 2023-07-08:
Regarding, " I resorted to the Wokwi simulated version. In any case, I’m grateful for your implementation!"

Can you share a link to the simulation here please?

NULLbodyHERE, 2023-07-10:
> Regarding, " I resorted to the Wokwi simulated version. In any case, I’m grateful for your implementation!"
>
> Can you share a link to the simulation here please?

https://wokwi.com/projects/369869124017584129

RobertLRead, 2023-07-10:
Dear @NULLbodyHERE ,
I did a pull today and listened to all of Seyi's "songs". I like them better than the one's that I created. I therefore consider this mission to be accomplished! Good job. I'm closing this. We are now ready to finish the HardwareX paper.

ForrestErickson, 2023-07-11:
@RobertLRead
What is the serial number of the GPAD on which you listened to the songs?

RobertLRead, 2023-07-11:
The case is black and has ears. Do you need me to open it up to find it on
the board?

On Mon, Jul 10, 2023 at 10:08 PM Forrest Lee Erickson <
***@***.***> wrote:

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

--
Robert L. Read, PhD
Twitter: @RobertLeeRead @pubinvention
Public Invention: https://www.pubinv.org
Join Our Mailing list: ***@***.***
YouTube: https://www.youtube.com/channel/UCJQg_dkDY3KTP1ybugYwReg
Medium: ***@***.***

ForrestErickson, 2023-07-11:
That GPAD is one of the five built into enclosures and therefor has the Buzzer and not the Piezo which is the important part for evaluation.  This reflects fully our Rev 2 design.

Hurray!

Closed 2023-07-10.

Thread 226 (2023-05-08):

Troubleshooting, GPAD SN:3

ForrestErickson, 2023-05-08:
#Report of failed display on this DUT.

Months before late April 2023 @RobertLRead  reported GPAD SN: 3 had no display.
During late April 2023 the DUT was delivered to Lee

## Troubleshooting
On 20230508 Lee began troubleshooting.
Applied power.
Current draw was about 76 to 80 mA and the device powered up
There was no display.
No back light.
No text display.

Connect the DUT to USB and it enumerated as COM9.
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

Connect RealTerminal to the DUT and press reset showed splash message.
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

Check I2C bus for activity shows the anticipated activity after pressing reset button.
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

With oscilloscope I found no signal on the base of Q301 which should turn on the LCD back light.
Checking for power on U301 found none.
Found R310 open.
The leads on RV301 had become shorted causing low impedance on the Vcc_LCD supply which caused R310 to open (as it is intended to do when a short or overload happens.)

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

Replace R301 with 1R resistor and normal operation is restored.

## Corrective Action
Lee has trimmed the leads on RV301 shorter so that they cannot be shored.
Note: Lee had not trimmed them very short because unnecessary lead trimming can introduce failures.
However these leads are long enough that a short can happen.
If there was an enclosure for SN:3 this would not have happened when in the "field".

## Conclusion
Leads on RV301 should be trimmed.
Do not deploy and operate the device with out an enclosure.

ForrestErickson, 2023-05-08:
Lee updated the manufacturing documentation as follows,

"Trim the excess leads on RV301 and the LEDs."

This should address the root cause.

Closed 2023-05-08.

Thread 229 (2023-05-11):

Capture Build Time GPAD Rev 2 Printed Wiring Assemblies

ForrestErickson, 2023-05-11:
# As Built in Maryville TN by Lee

Unless noted, this time does not include setup

## Soldering LCD Display Headers
**Nine displays took 26 minuets**

Assemble LCD to PCBs.
**Nine units took 65 minuets.**

## Assemble Components to PCB
Put Reset button, S101 into PCB from display side.
Put Mute button, S401 into PCB from display side.
Put Contrast pot, RV301 into PCB from display side. Bending leads may help retain.
**Nine units took 33 minuets.**

Put Buzzer, BZ601 into PCB from display side. Bending leads may help retain.
Solder on Assembly test fixture. Solder one lead and hole buzzer to the PCB while solder cools. Solder second lead.
**Nine units took 23 minuets.**

Put Red and white LEDs with spacers.
**Nine units took 66 minuets.**

## Electrical Test, Bootloader and Firmware loading

Partional progress
All electrical tests and bootloader burn.  Haveing to stop to reboot computer to try to regain control of COM port.
**Nine units took 100 minuets.**

Finish electrical test and firmware loading except for failure on DUT SN24.
**Nine units took 41 minuets.**

## Total Built time:
**Nine units took 354 minuets.**
This is just about 40 minuets per device.

ForrestErickson, 2023-06-20:
@RobertLRead This build time could be added for cost estimating some where in the report / article at HardwareX.

ForrestErickson, 2023-06-20:
Done so close.

Closed 2023-06-20.

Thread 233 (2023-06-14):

Zero Clearance Around SPI and I2C connector on PolyVent SPI Controller Faceplate, Version8

ForrestErickson, 2023-06-14:
Fabricated out of PLA, this faceplate had zero clearance around the connectors.
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

File:
https://github.com/PubInv/general-alarm-device/blob/main/Hardware/PolyVent_SPI_Controller/CAD_model/PolyVent_SPI_Controller-faceplate%20v8.stl

ForrestErickson, 2023-06-18:
Enlarged connector holes on the FreeCad 3D model.
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

ForrestErickson, 2023-06-19:
Updated file for larger connector holes. Fabricated on Prusa i3 MK3 using silver colored PLA.

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
Note that the screw hole is not round. The 3mm screw will not go through this hole. I had to ream with a 1/8" drill for the 3mm screw to go.
The 3mm nut fit into the pocket with no interference and in fact fell out during assembly.

The enlarged connector holes work.  I even made a cable with JST connector to test fit.
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

ForrestErickson, 2023-06-25:
Updated with version 9 native FreeCAD drawing. Add STEP and STL files to repository. Updated the README.md at https://github.com/PubInv/general-purpose-alarm-device/tree/main/Hardware/PolyVent_SPI_Controller/CAD_model

Closed 2023-06-25.

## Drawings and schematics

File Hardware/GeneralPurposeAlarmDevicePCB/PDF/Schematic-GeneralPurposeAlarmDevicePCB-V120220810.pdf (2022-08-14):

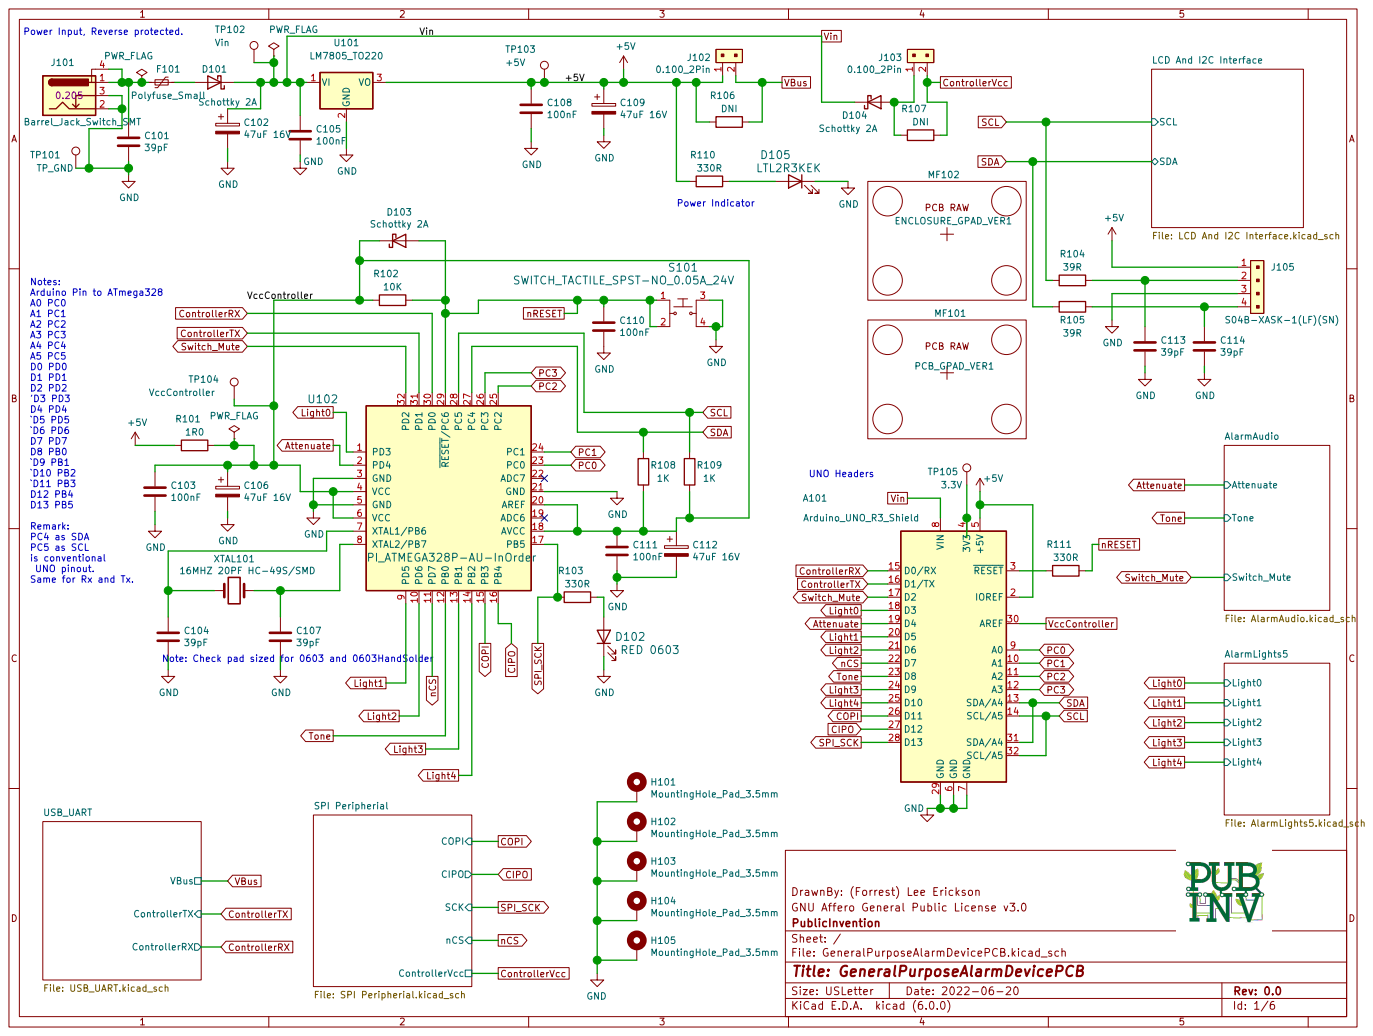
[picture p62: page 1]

LM7805_TO220 PWR_FLAG
Power Input, Reverse protected. Notes: Arduino Pin to ATmega328 A0 PC0 A1 PC1 A2 PC2 A3 PC3 A4 PC4 A5 PC5 D0 PD0 D1 PD1 D2 PD2

LCD And I2C Interface File: LCD And I2C Interface.kicad_sch COPI CIPO

J105 S04B-XASK-1(LF)(SN) GND

SWITCH_TACTILE_SPST-NO_0.05A_24V | 3

nCS ControllerVcc SPI Peripherial

File: GeneralPurposeAlarmDevicePCB.kicad_sch Sheet: / PublicInvention GNU Affero General Public License v3.0 DrawnBy: (Forrest) Lee Erickson ControllerRX ControllerTX

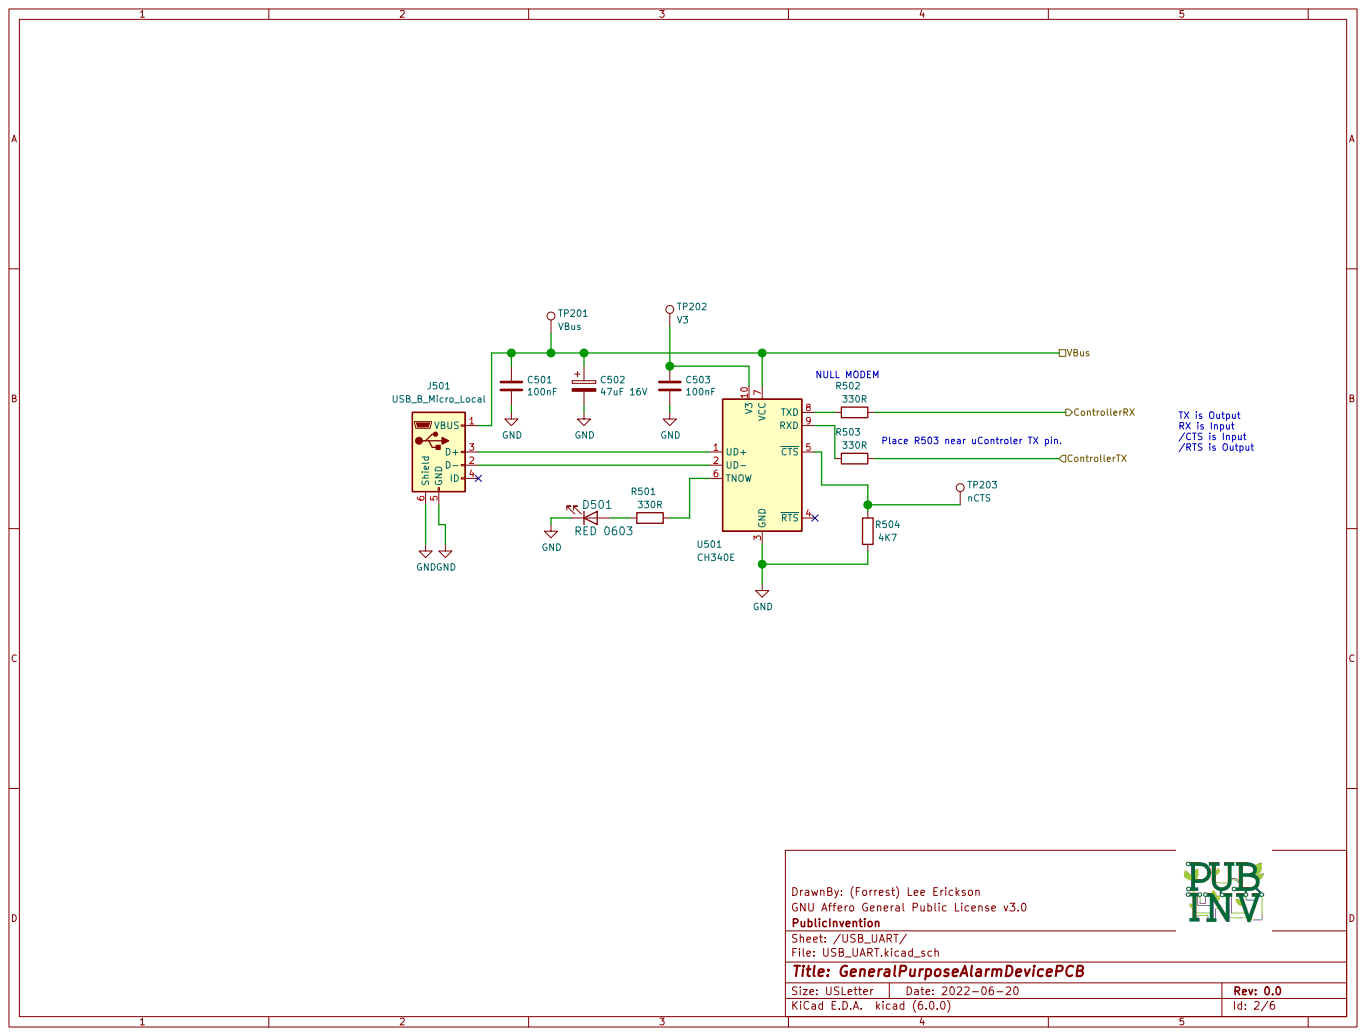
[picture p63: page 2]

3 ~{RTS} 4 ~{CTS} 5 TNOW 6 VCC

Place R503 near uControler TX pin.

Sheet: /USB_UART/ PublicInvention GNU Affero General Public License v3.0 DrawnBy: (Forrest) Lee Erickson R501

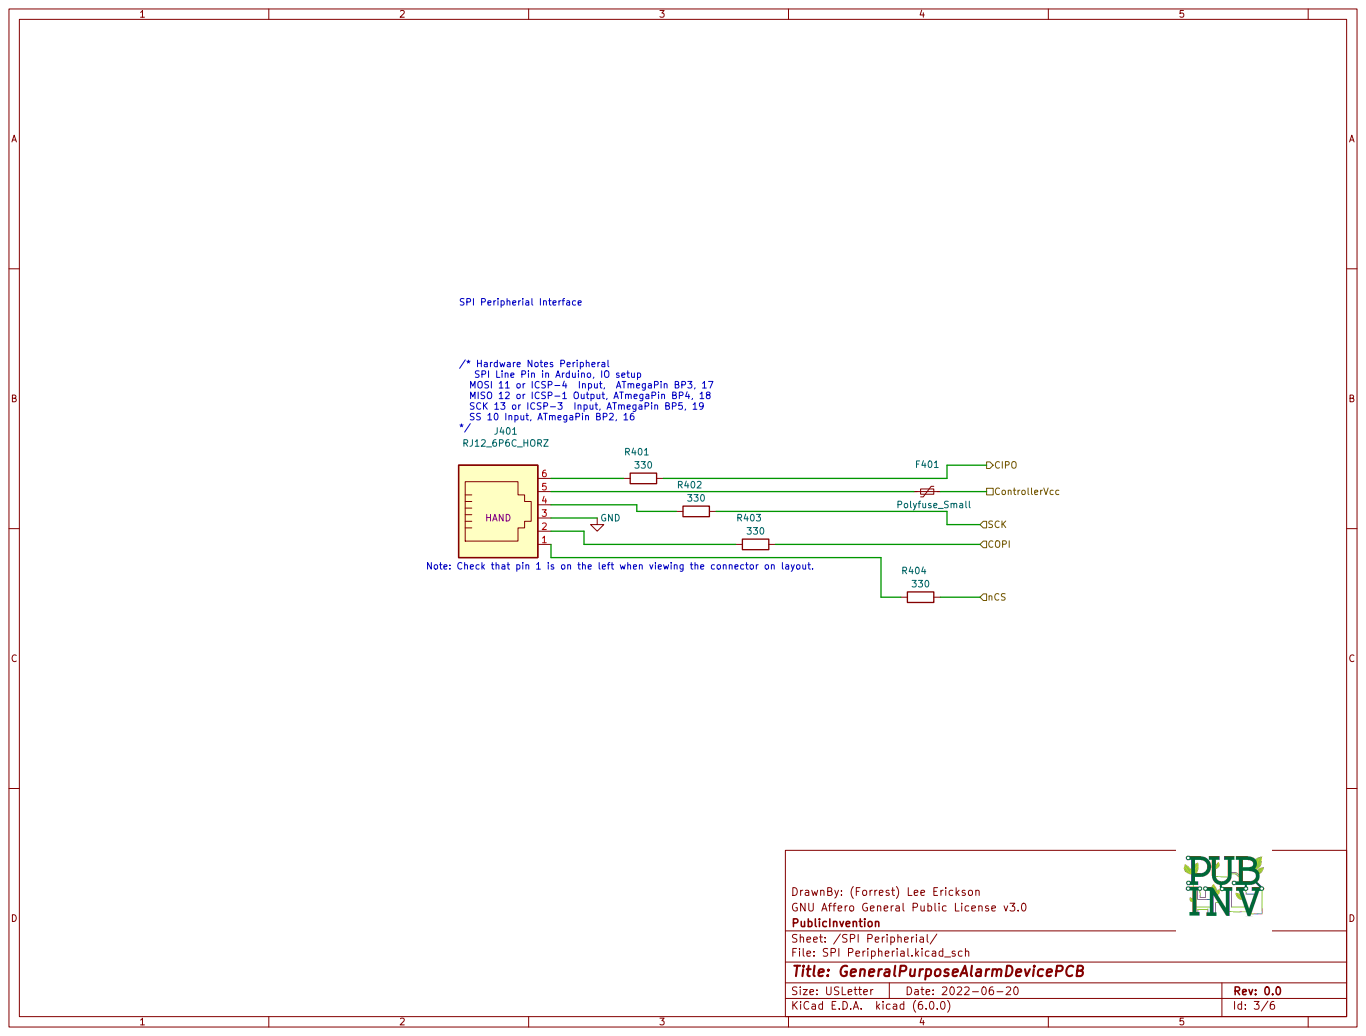
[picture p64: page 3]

/* Hardware Notes Peripheral
SPI Line Pin in Arduino, IO setup
MOSI 11 or ICSP-4 Input, ATmegaPin BP3, 17
MISO 12 or ICSP-1 Output, ATmegaPin BP4, 18
SCK 13 or ICSP-3 Input, ATmegaPin BP5, 19
SS 10 Input, ATmegaPin BP2, 16
J401 RJ12_6P6C_HORZ HAND

nCSControllerVcc Note: Check that pin 1 is on the left when viewing the connector on layout.

Sheet: /SPI Peripherial/ PublicInvention GNU Affero General Public License v3.0 DrawnBy: (Forrest) Lee Erickson

Rev: 0.0 | D Date: 2022-06-20 KiCad E.D.A. kicad (6.0.0) Size: USLetter

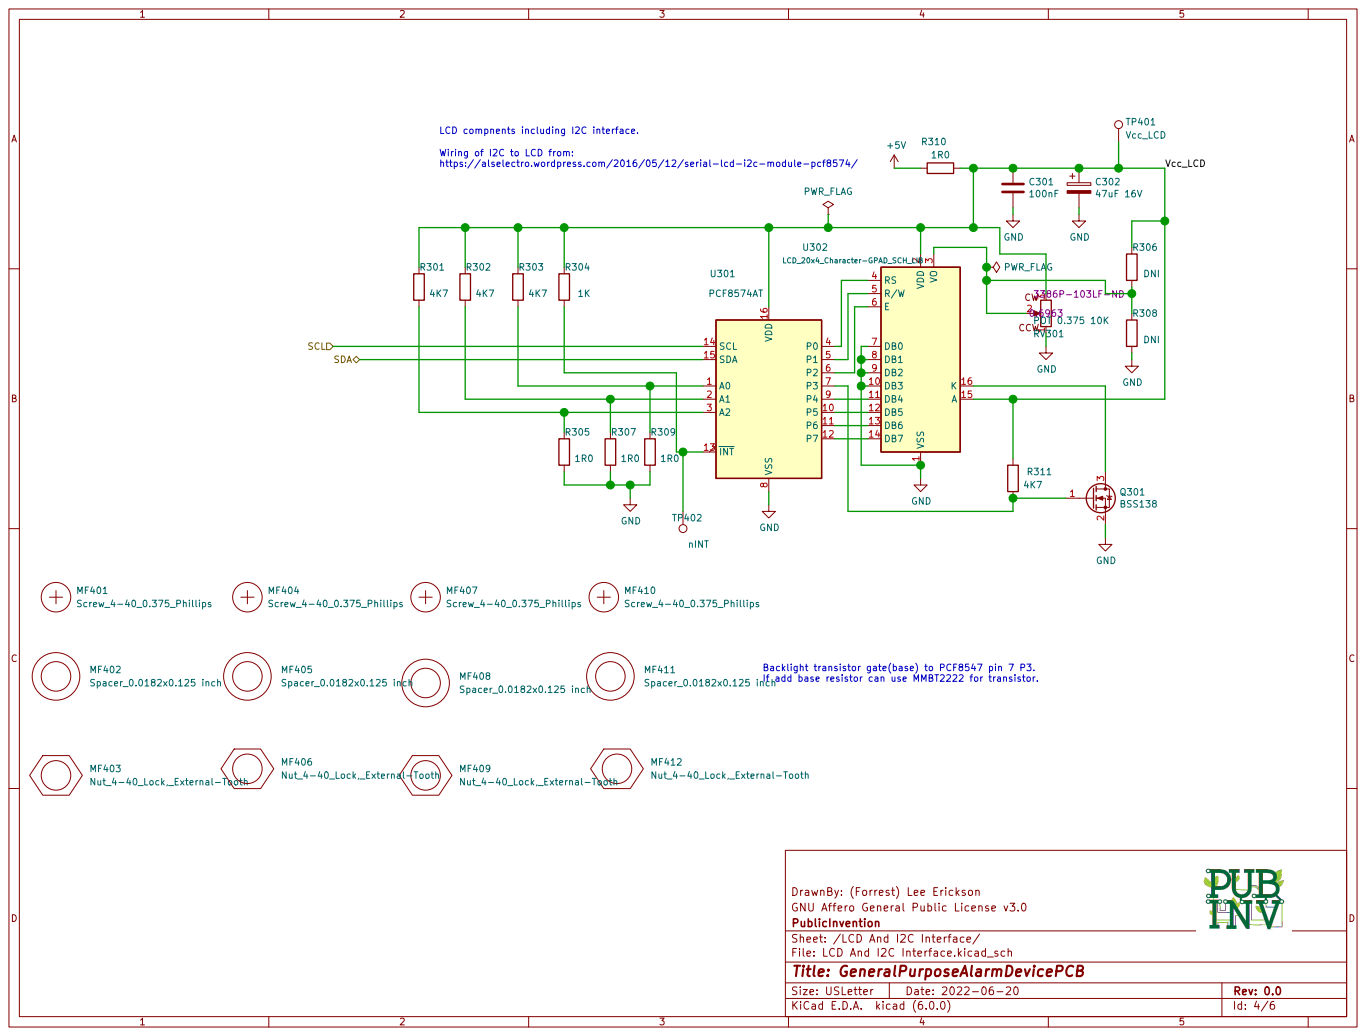
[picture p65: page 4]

LCD compnents including I2C interface.

Vcc_LCD Wiring of I2C to LCD from:
https://alselectro.wordpress.com/2016/05/12/serial-lcd-i2c-module-pcf8574/

Backlight transistor gate(base) to PCF8547 pin 7 P3.
If add base resistor can use MMBT2222 for transistor.

File: LCD And I2C Interface.kicad_sch Sheet: /LCD And I2C Interface/ PublicInvention GNU Affero General Public License v3.0 DrawnBy: (Forrest) Lee Erickson

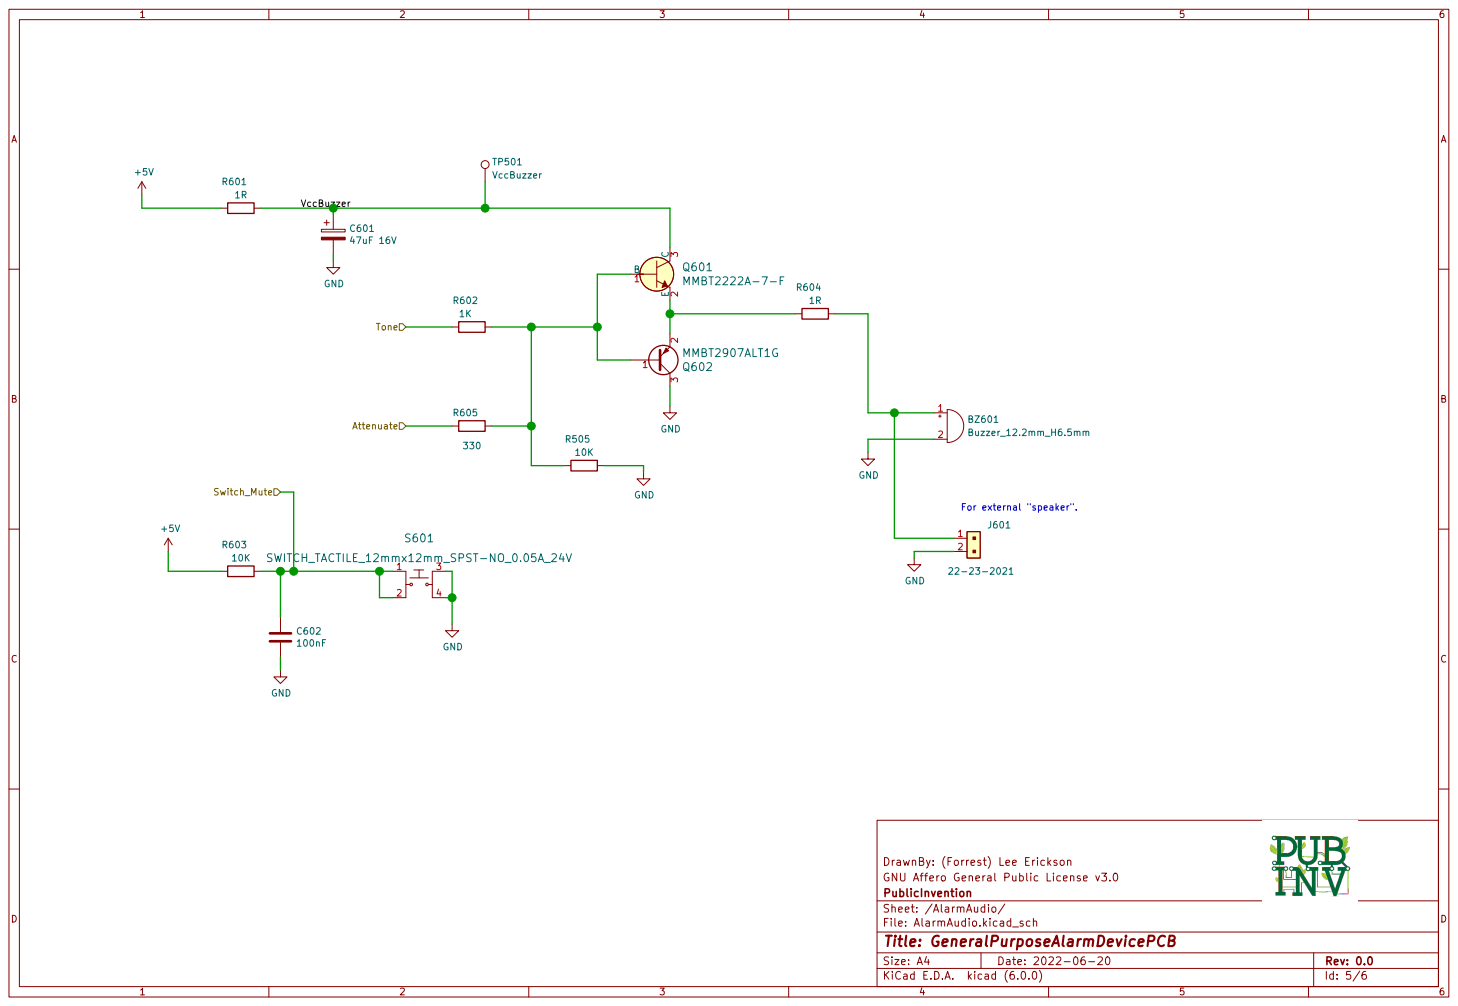
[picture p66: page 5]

File: AlarmAudio.kicad_sch Sheet: /AlarmAudio/ PublicInvention GNU Affero General Public License v3.0 DrawnBy: (Forrest) Lee Erickson GND

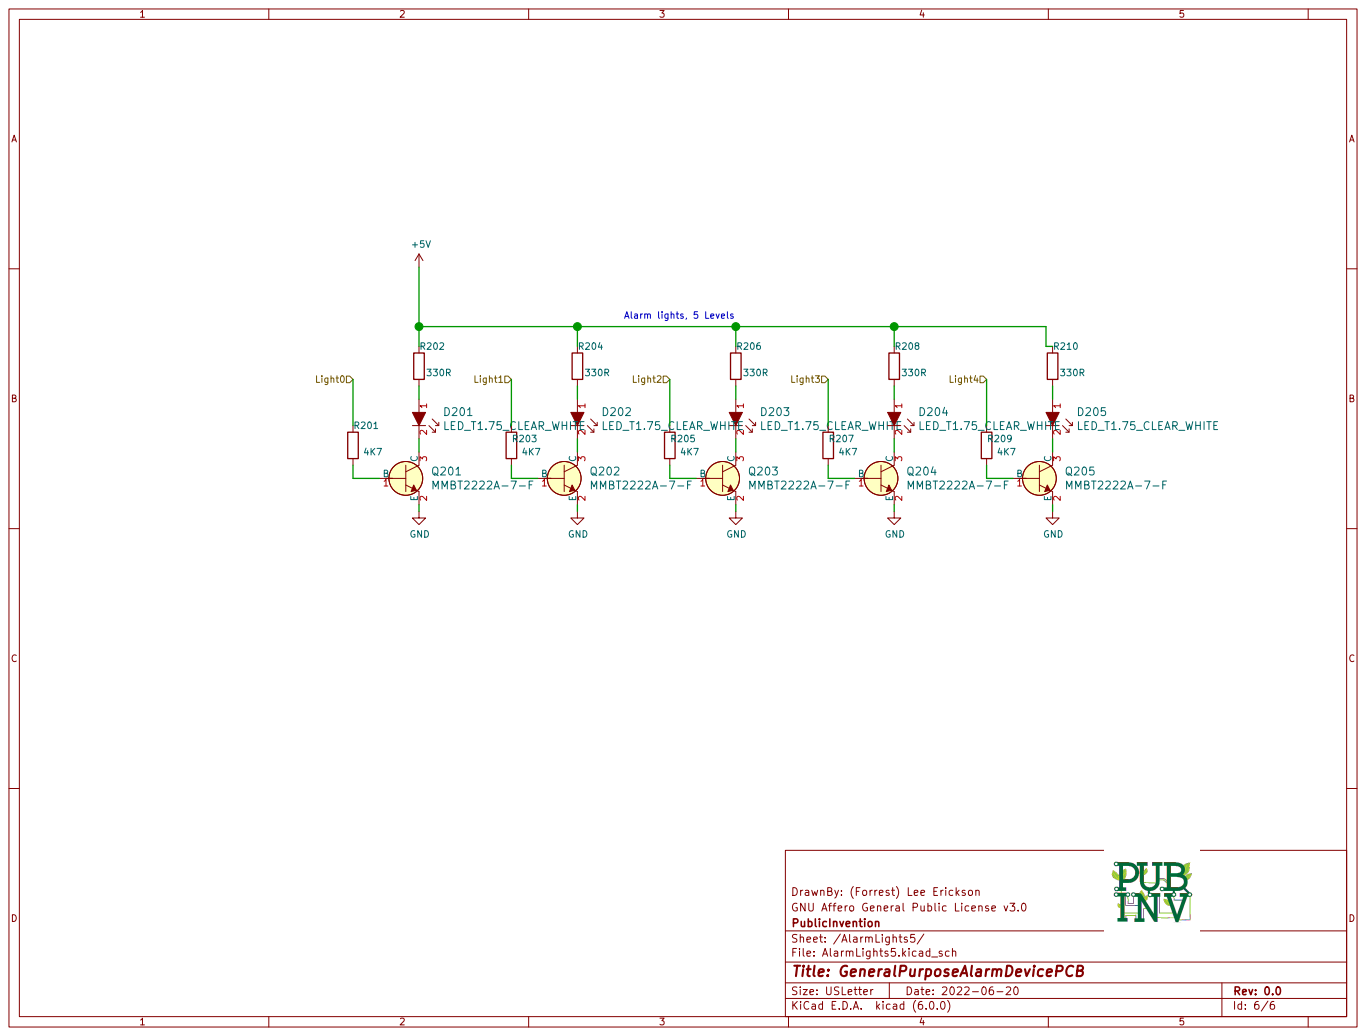
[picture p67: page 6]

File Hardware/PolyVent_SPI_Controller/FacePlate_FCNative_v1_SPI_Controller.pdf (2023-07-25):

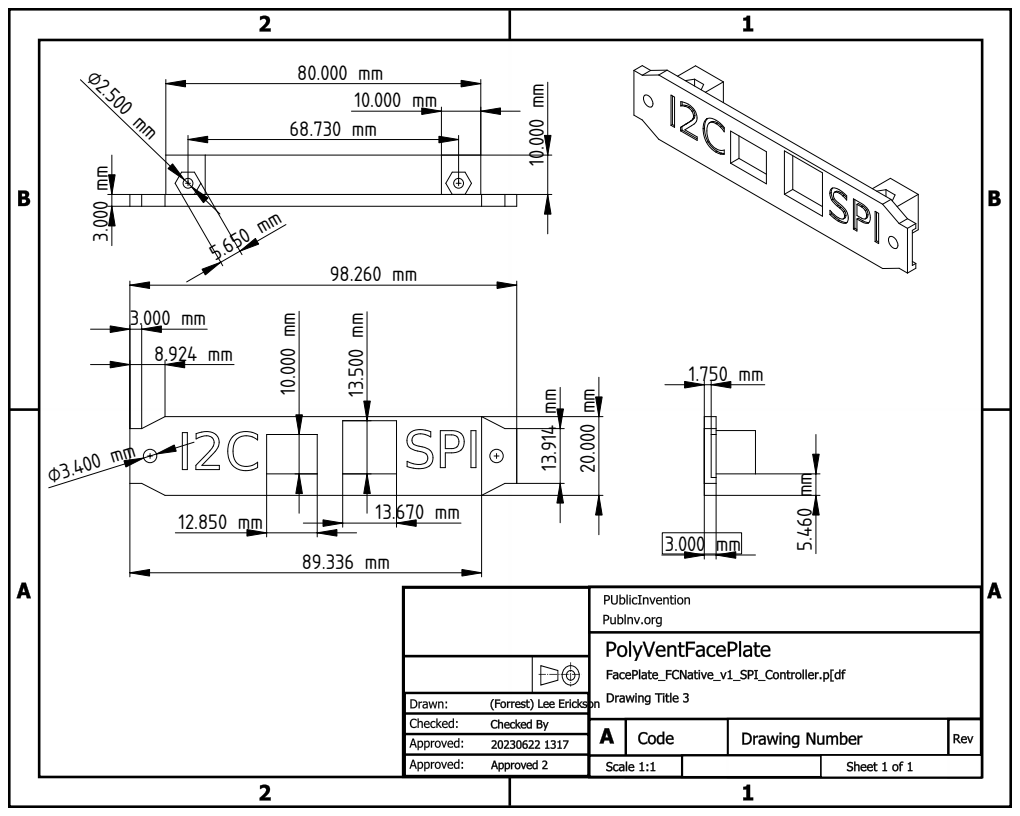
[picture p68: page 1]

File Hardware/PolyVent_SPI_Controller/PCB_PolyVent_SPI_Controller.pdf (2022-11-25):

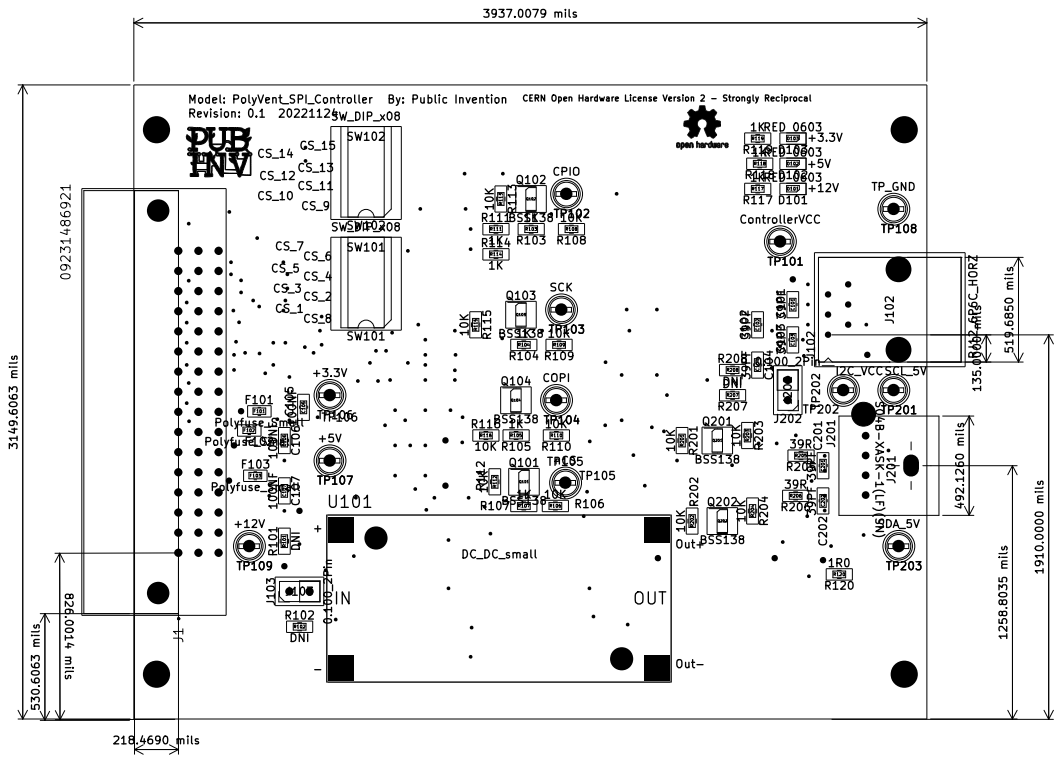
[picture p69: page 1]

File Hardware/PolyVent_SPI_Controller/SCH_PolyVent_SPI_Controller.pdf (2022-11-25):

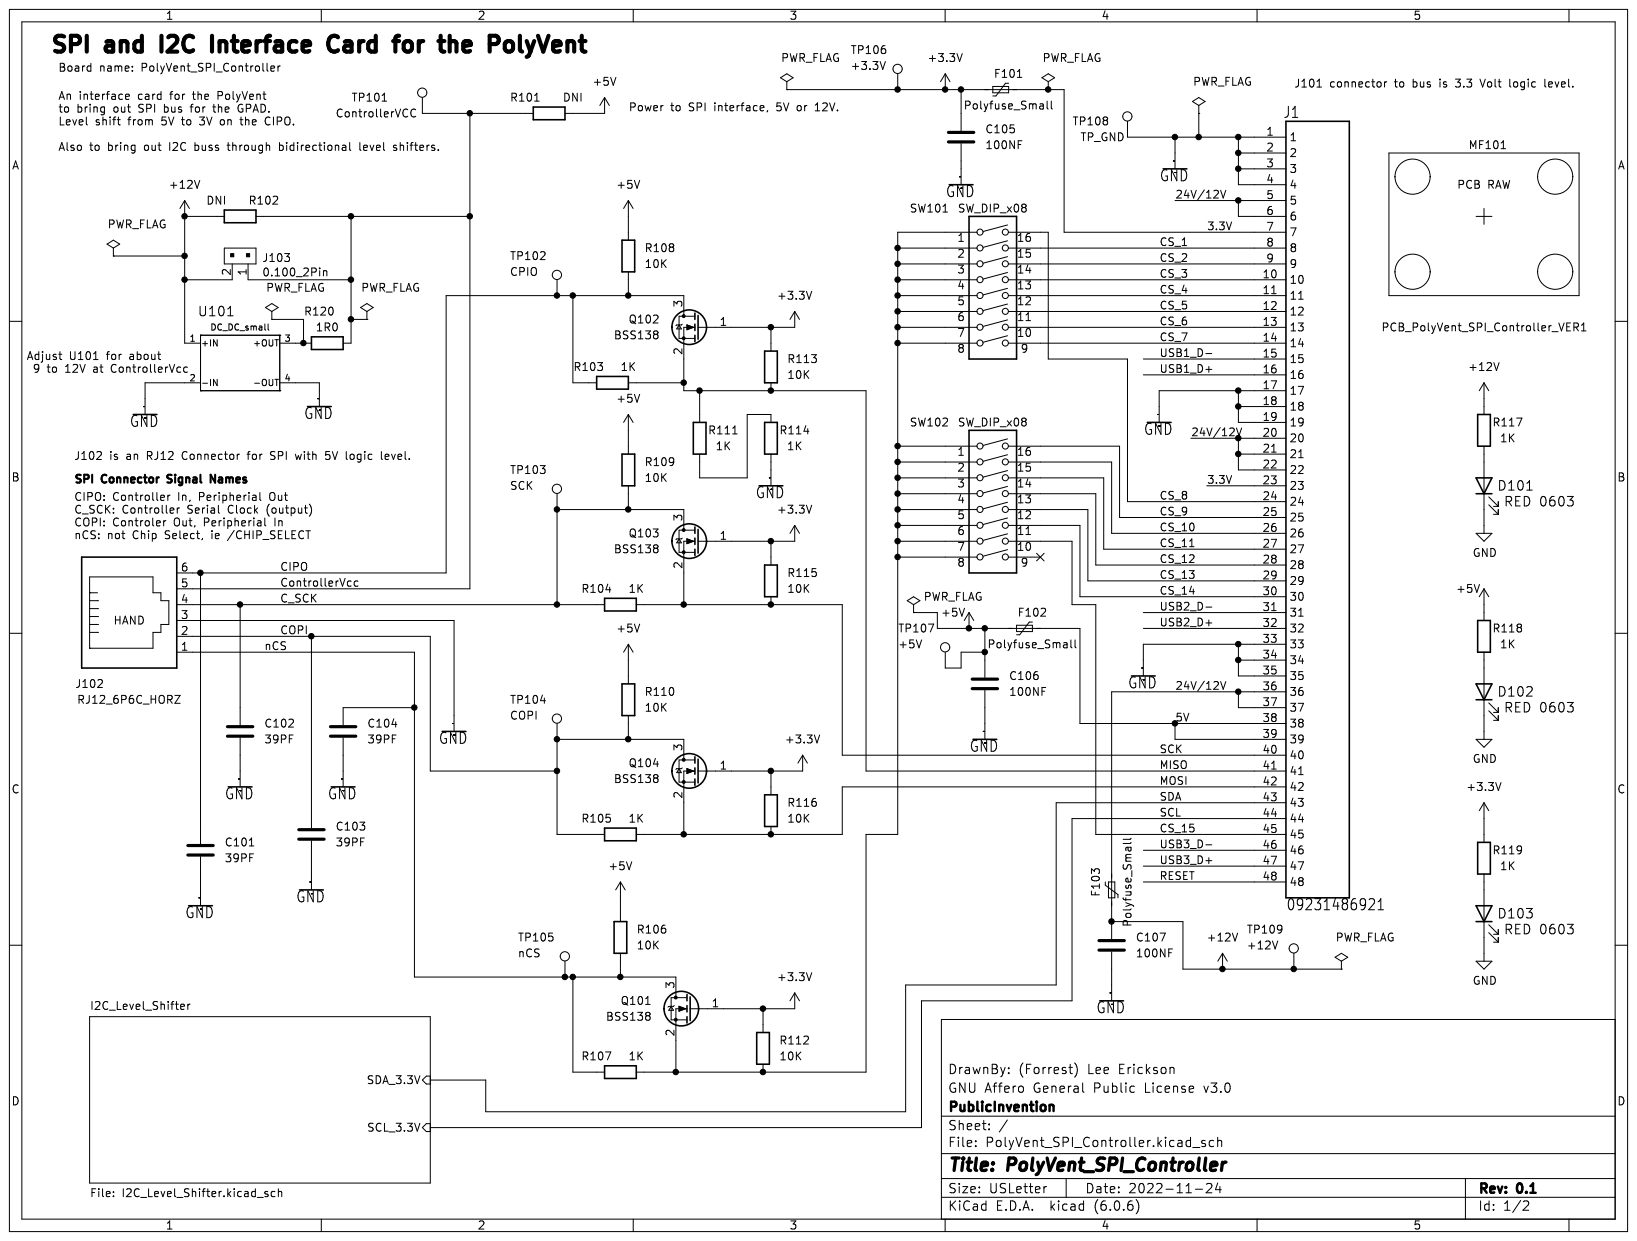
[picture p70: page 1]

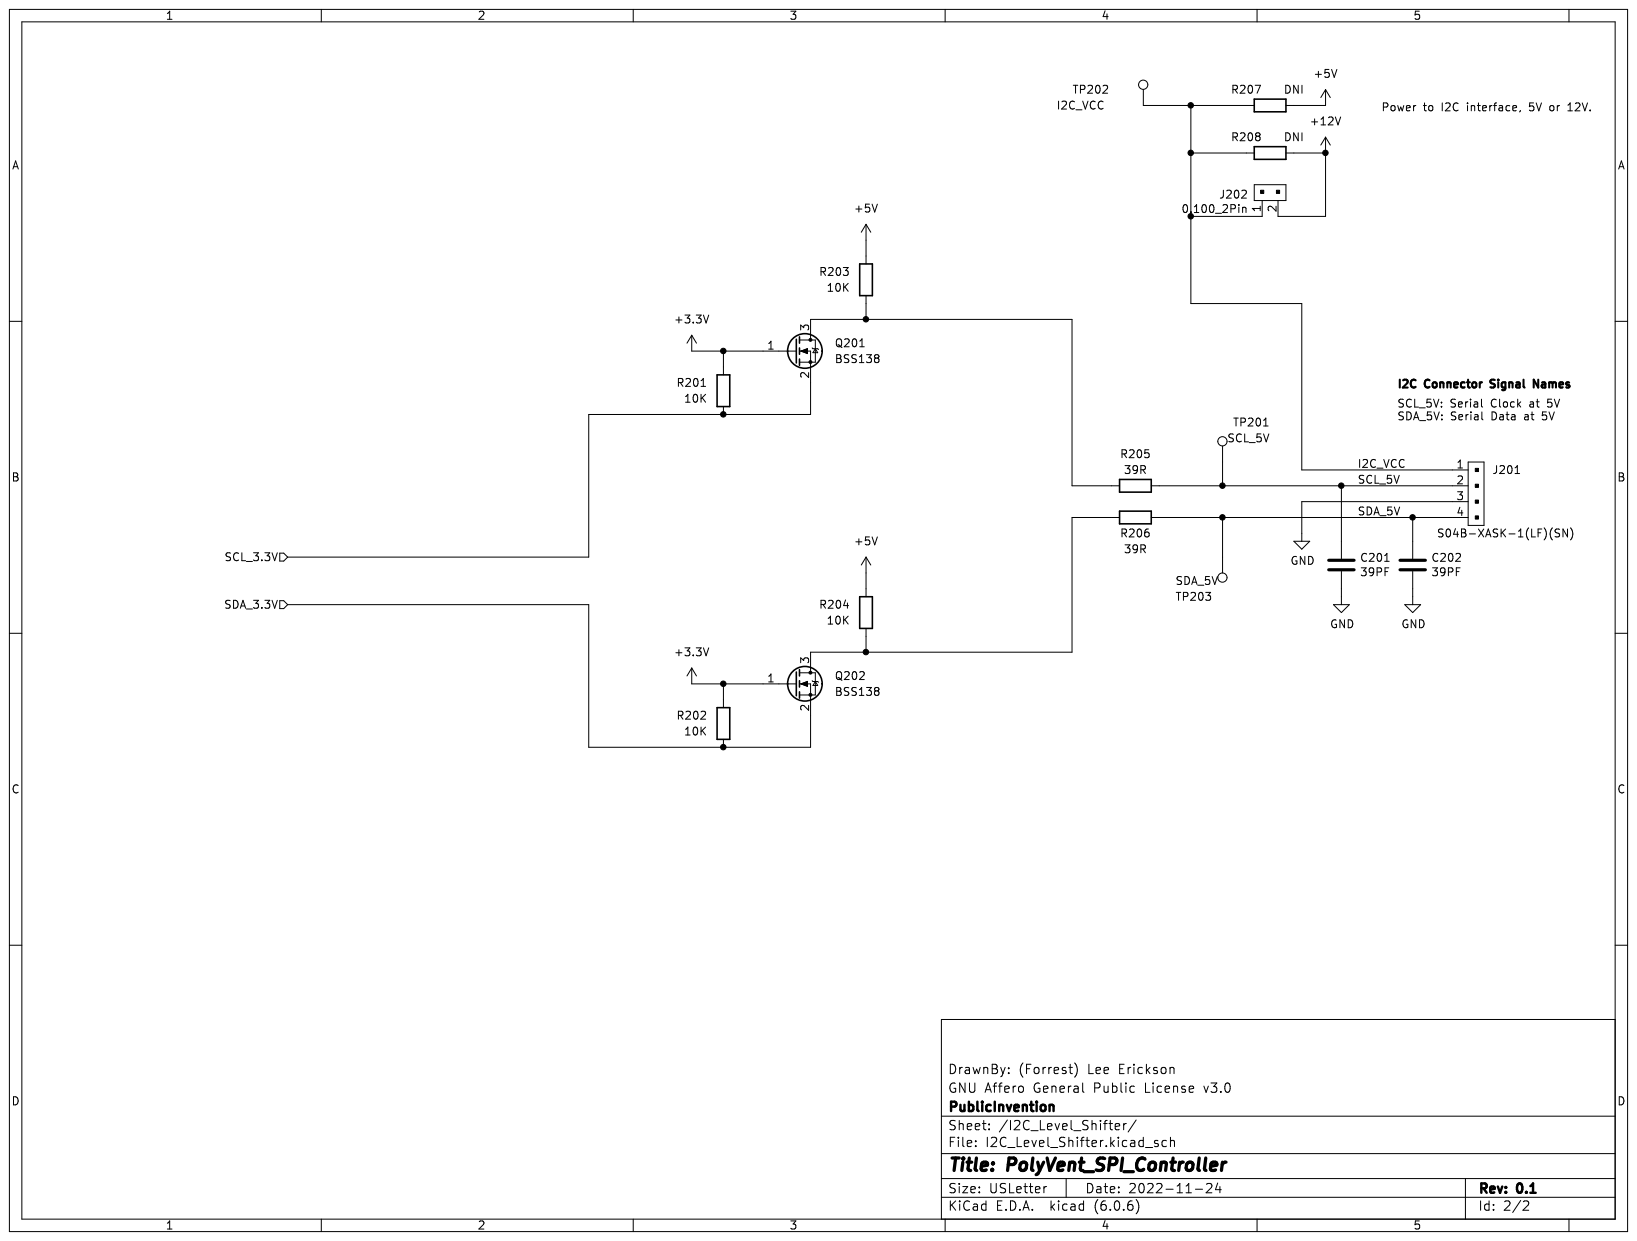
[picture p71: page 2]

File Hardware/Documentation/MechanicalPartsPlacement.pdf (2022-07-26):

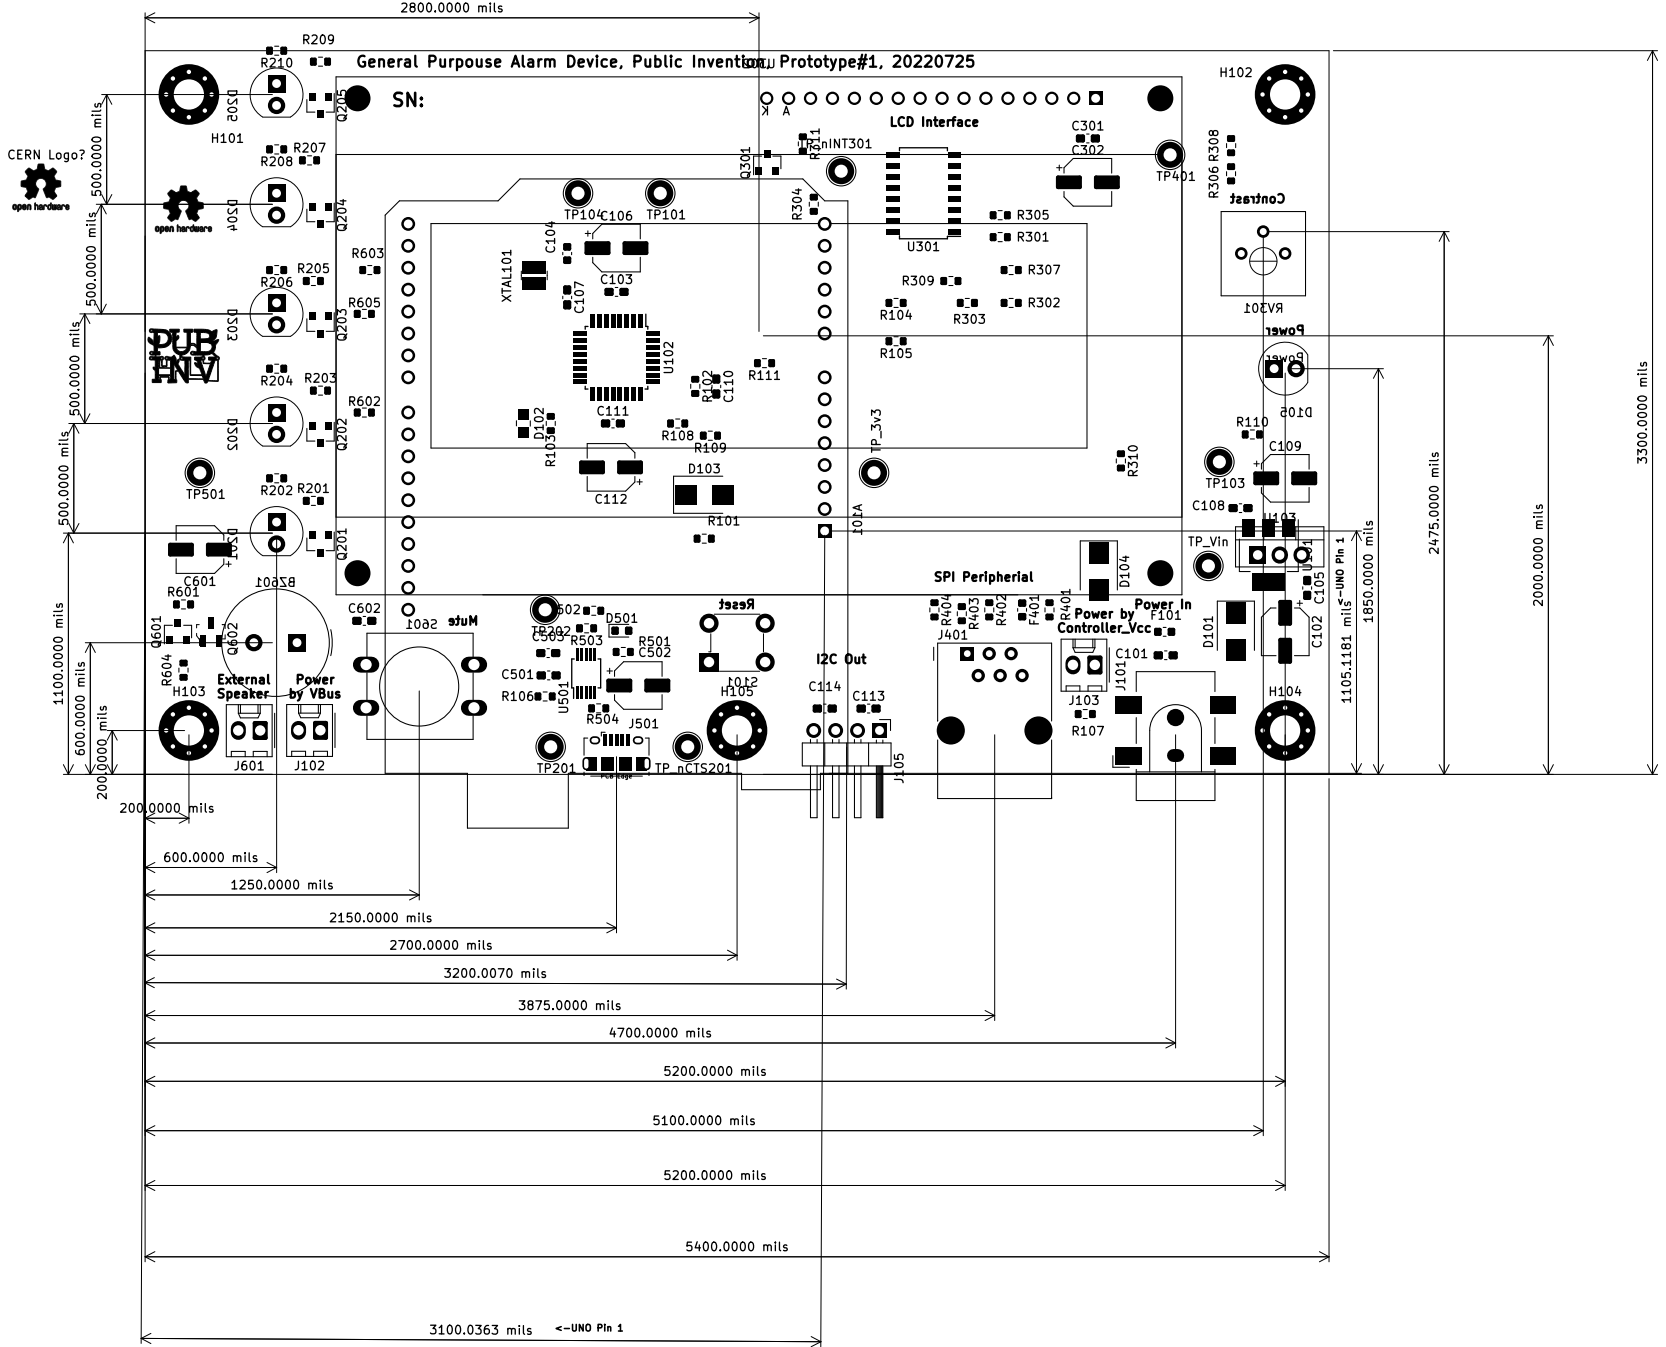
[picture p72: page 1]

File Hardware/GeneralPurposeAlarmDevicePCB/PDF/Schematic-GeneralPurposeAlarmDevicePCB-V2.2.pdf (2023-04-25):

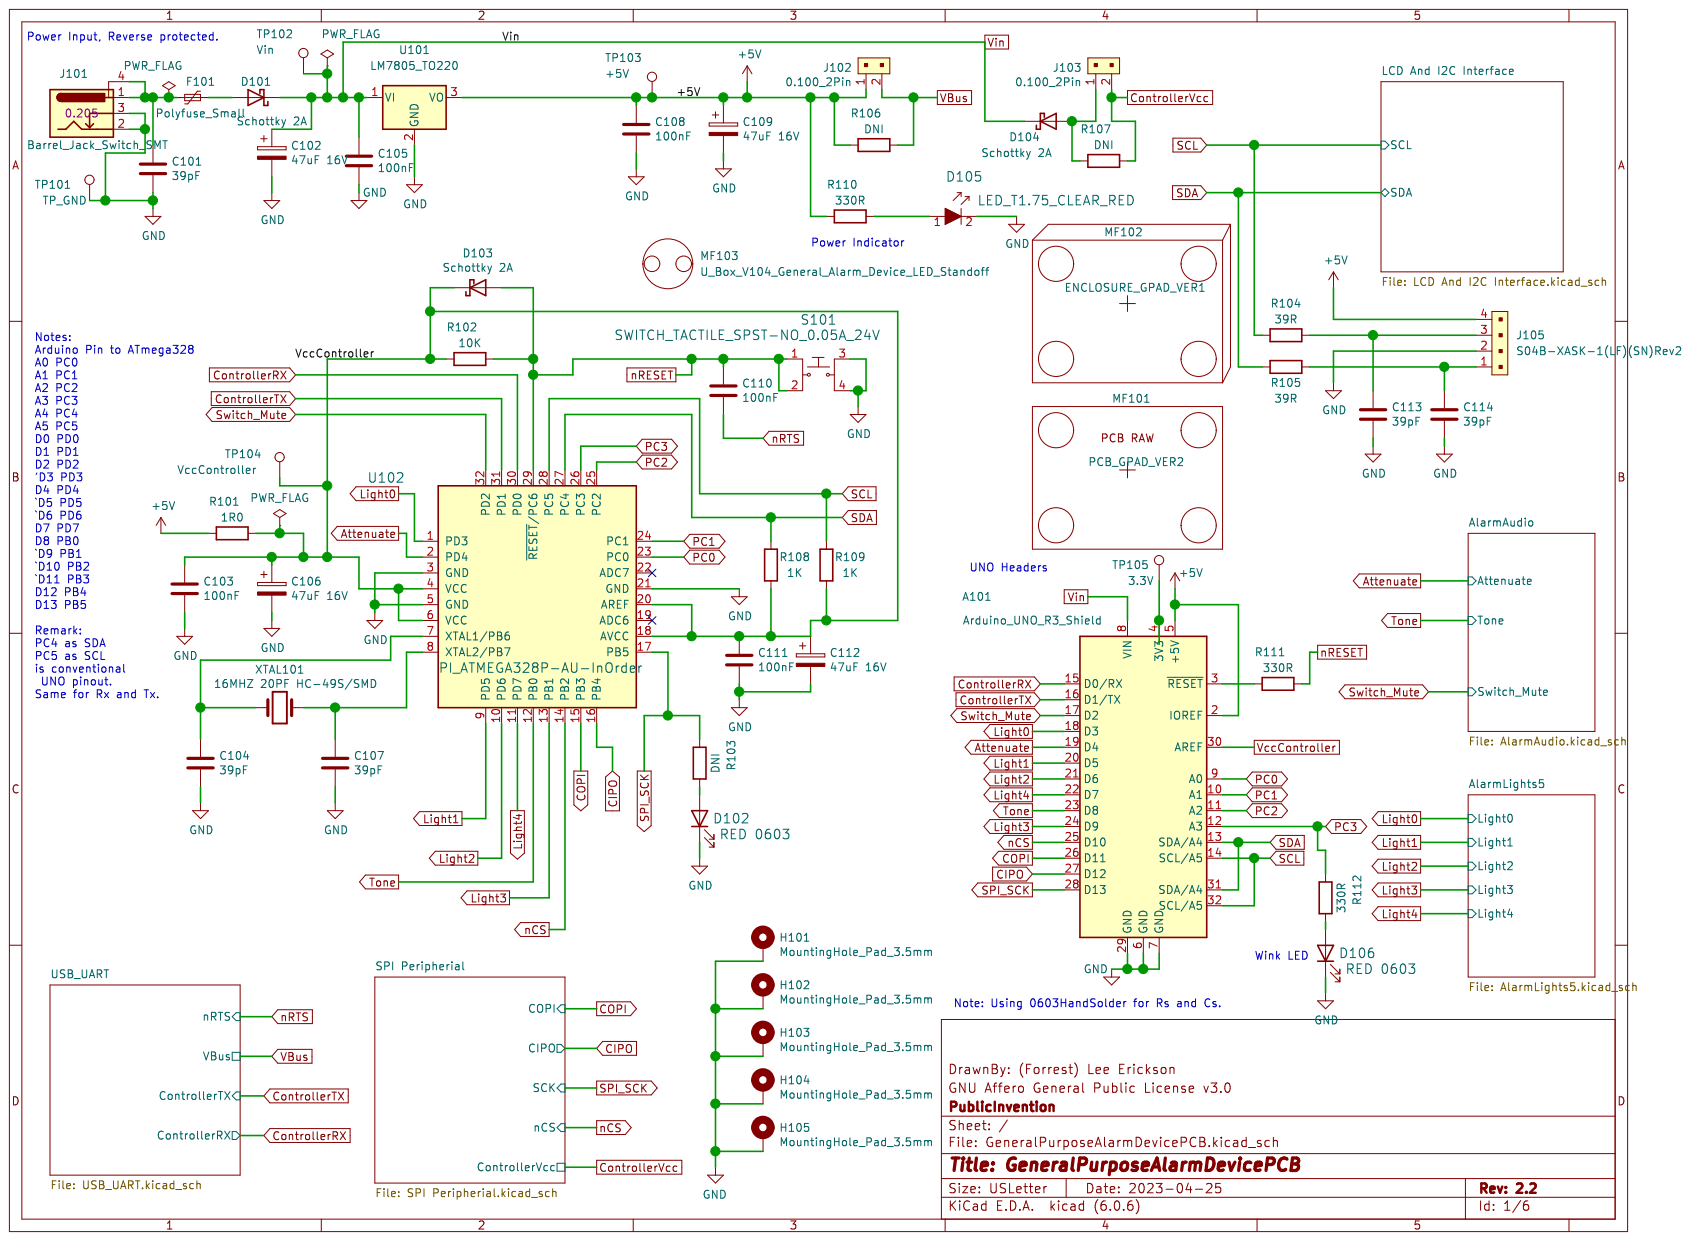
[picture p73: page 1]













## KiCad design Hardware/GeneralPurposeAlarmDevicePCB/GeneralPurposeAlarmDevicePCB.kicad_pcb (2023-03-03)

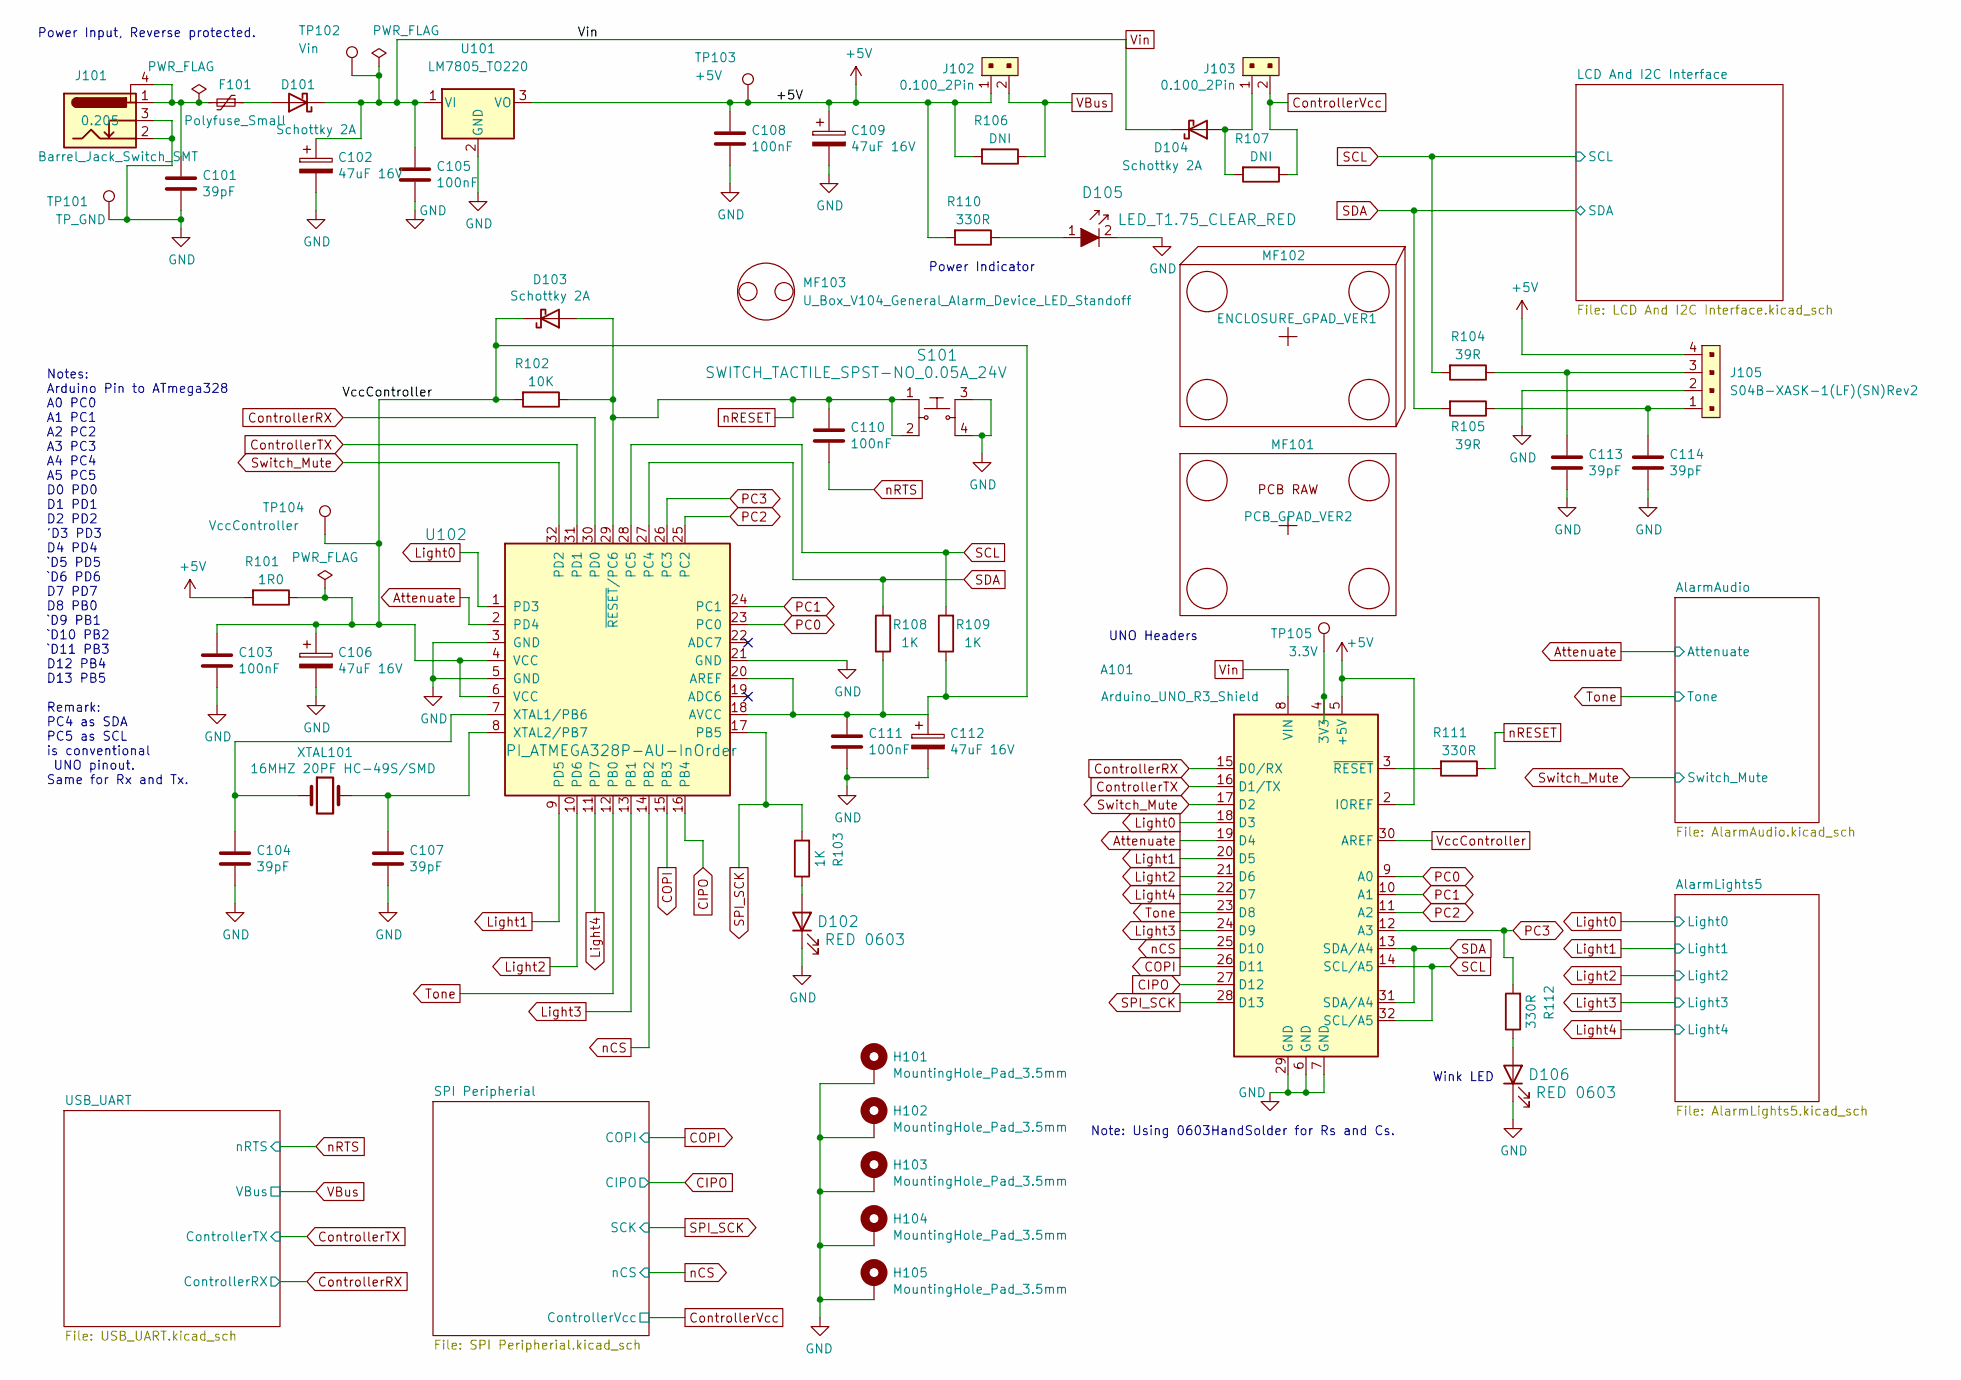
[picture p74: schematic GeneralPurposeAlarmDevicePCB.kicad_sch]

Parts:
A101: Arduino_UNO_R3_Shield; Arduino_UNO_R3_NoMountingHoles3D
C101, C104, C107, C113, C114: 39pF; C_0603_1608Metric_Pad1.08x0.95mm_HandSolder; MPN CC0603JRNPO9BN390
C102, C106, C109, C112: 47uF 16V; CP_Elec_5x5.4; MPN RVT47UF16V67RV0019
C103, C105, C108, C110, C111: 100nF; C_0603_1608Metric_Pad1.08x0.95mm_HandSolder; MPN CC0603KRX7R9BB104
D101, D103, D104: Schottky 2A; D_SMB; MPN SS210
D102, D106: RED 0603; LED_0603_1608Metric_Pad1.05x0.95mm_HandSolder; MPN LTST-C171KRKT; Digi-Key_PN 160-1427-1-ND
D105: LED_T1.75_CLEAR_RED; LED_5mm_Radial; Digi-Key_PN 160-1682-ND
F101: Polyfuse_Small; Fuse_0603_1608Metric; MPN 0603L100SLYR
H101, H102, H103, H104, H105: MountingHole_Pad_3.5mm; MountingHole_3.5mm_Pad_Via
J101: Barrel_Jack_Switch_SMT; BarrelJack_CLIFF_FC681465S_SMT_Horizontal; MPN DC-005-5A-2.0-SMT / 54-00164
J102, J103: 0.100_2Pin; PinHeader_1x02_P2.54mm_Vertical; MPN 68000-102HLF
J105: S04B-XASK-1(LF)(SN)Rev2; MPN S04B-XASK-1(LF)(SN); Digi-Key_PN 455-4090-ND
MF101: PCB_GPAD_VER2; NA; MPN PCB_GPAD_V1
MF102: ENCLOSURE_GPAD_VER1
MF103: U_Box_V104_General_Alarm_Device_LED_Standoff
R101: 1R0; R_0603_1608Metric_Pad0.98x0.95mm_HandSolder; MPN RMC060315%N
R102: 10K; R_0603_1608Metric_Pad0.98x0.95mm_HandSolder; MPN RMC 0603 10K F N
R103, R108, R109: 1K; R_0603_1608Metric_Pad0.98x0.95mm_HandSolder; MPN RMC06031K1%N
R104, R105: 39R; R_0603_1608Metric_Pad0.98x0.95mm_HandSolder; MPN RMC0603391%N
R106, R107: DNI; R_0603_1608Metric_Pad0.98x0.95mm_HandSolder; MPN DNI
R110, R111, R112: 330R; R_0603_1608Metric_Pad0.98x0.95mm_HandSolder; MPN RMC06033301%N
S101: SWITCH_TACTILE_SPST-NO_0.05A_24V; Switch_Tactile_THT_6x6mm; MPN TE Connectivity 1825910-7, Dongguan Gua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
TP101: TP_GND; TestPoint_Loop_D2.54mm_Drill1.5mm_Beaded
TP102: Vin; TestPoint_Loop_D2.54mm_Drill1.5mm_Beaded
TP103: +5V; TestPoint_Loop_D2.54mm_Drill1.5mm_Beaded
TP104: VccController; TestPoint_Loop_D2.54mm_Drill1.5mm_Beaded
TP105: 3.3V; TestPoint_Loop_D2.54mm_Drill1.5mm_Beaded
U101: LM7805_TO220; TO-220-3_Horizontal_TabDown; MPN LM7805CTG
U102: PI_ATMEGA328P-AU-InOrder; TQFP-32_7x7mm_P0.8mm; MPN ATMEGA328P-AU
XTAL101: 16MHZ 20PF HC-49S/SMD; Crystal_SMD_HC49-SD; MPN TAXM16M2GLFBET2T

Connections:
+5V: A101.2 (IOREF), A101.5 (+5V), C108.1, C109.1, J102.1, J105.4, R101.2, R106.2, R110.2, TP103.1, U101.3 (VO); also elsewhere on the board
Attenuate: A101.19 (D4), U102.2 (PD4); also elsewhere on the board
CIPO: A101.27 (D12), U102.16 (PB4); also elsewhere on the board
COPI: A101.26 (D11), U102.15 (PB3); also elsewhere on the board
ControllerRX: A101.15 (D0/RX), U102.30 (PD0); also elsewhere on the board
ControllerTX: A101.16 (D1/TX), U102.31 (PD1); also elsewhere on the board
ControllerVcc: J103.2, R107.1; also elsewhere on the board
GND: A101.6 (GND), A101.7 (GND), A101.29 (GND), C101.2, C102.2, C103.2, C104.2, C105.2, C106.2, C107.2, C108.2, C109.2, C111.2, C112.2, C113.2, C114.2, D102.1 (K), D105.2, D106.1 (K), H101.1, H102.1, H103.1, H104.1, H105.1, J101.2, J101.3, J105.2, S101.3, S101.4, TP101.1, U101.2 (GND), U102.3 (GND), U102.5 (GND), U102.21 (GND); also elsewhere on the board
Light0: A101.18 (D3), U102.1 (PD3); also elsewhere on the board
Light1: A101.20 (D5), U102.9 (PD5); also elsewhere on the board
Light2: A101.21 (D6), U102.10 (PD6); also elsewhere on the board
Light3: A101.24 (D9), U102.13 (PB1); also elsewhere on the board
Light4: A101.22 (D7), U102.11 (PD7); also elsewhere on the board
unnamed: A101.3 (~RESET), R111.2
unnamed: A101.4 (3V3), TP105.1
unnamed: C101.1, F101.2, J101.1, J101.4
unnamed: C104.1, U102.7 (XTAL1/PB6), XTAL101.1
unnamed: C107.1, U102.8 (XTAL2/PB7), XTAL101.2
unnamed: C113.1, J105.3, R104.1
unnamed: C114.1, J105.1, R105.1
unnamed: D101.2 (A), F101.1
unnamed: D102.2 (A), R103.1
unnamed: D104.2 (A), J103.1, R107.2
unnamed: D105.1, R110.1
unnamed: D106.2 (A), R112.1
PC0: A101.9 (A0), U102.23 (PC0)
PC1: A101.10 (A1), U102.24 (PC1)
PC2: A101.11 (A2), U102.25 (PC2)
PC3: A101.12 (A3), R112.2, U102.26 (PC3)
SCL: A101.14 (SCL/A5), A101.32 (SCL/A5), R104.2, R109.2, U102.28 (PC5); also elsewhere on the board
SDA: A101.13 (SDA/A4), A101.31 (SDA/A4), R105.2, R108.2, U102.27 (PC4); also elsewhere on the board
SPI_SCK: A101.28 (D13), R103.2, U102.17 (PB5); also elsewhere on the board
Switch_Mute: A101.17 (D2), U102.32 (PD2); also elsewhere on the board
Tone: A101.23 (D8), U102.12 (PB0); also elsewhere on the board
VBus: J102.2, R106.1; also elsewhere on the board
VccController: A101.30 (AREF), C103.1, C106.1, C111.1, C112.1, D103.1 (K), R101.1, R102.2, R108.1, R109.1, TP104.1, U102.4 (VCC), U102.6 (VCC), U102.18 (AVCC), U102.20 (AREF)
Vin: A101.8 (VIN), C102.1, C105.1, D101.1 (K), D104.1 (K), TP102.1, U101.1 (VI)
nCS: A101.25 (D10), U102.14 (PB2); also elsewhere on the board
nRESET: C110.1, D103.2 (A), R102.1, R111.1, S101.1, S101.2, U102.29 (~RESET/PC6)
nRTS: C110.2; also elsewhere on the board

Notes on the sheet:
Power Input, Reverse protected.
Power Indicator
Notes: Arduino Pin to ATmega328 A0 PC0 A1 PC1 A2 PC2 A3 PC3 A4 PC4 A5 PC5 D0 PD0 D1 PD1 D2 PD2 'D3 PD3 D4 PD4 `D5 PD5 `D6 PD6 D7 PD7 D8 PB0 `D9 PB1 `D10 PB2 `D11 PB3 D12 PB4 D13 PB5 Remark: PC4 as SDA PC5 as SCL is conventional UNO pinout. Same for Rx and Tx.
Wink LED
Note: Using 0603HandSolder for Rs and Cs.
UNO Headers

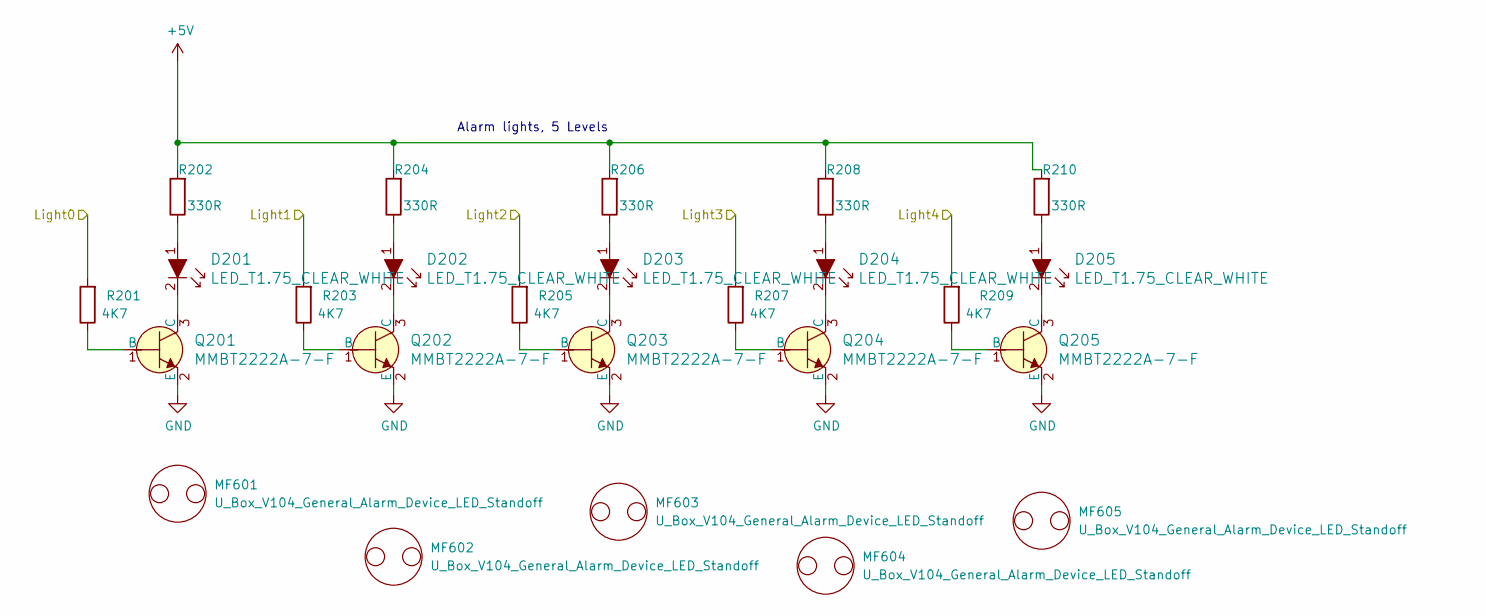
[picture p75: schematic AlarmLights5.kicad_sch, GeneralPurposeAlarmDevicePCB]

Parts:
D201, D202, D203, D204, D205: LED_T1.75_CLEAR_WHITE; LED_5mm_Radial; MPN LTW-2R3D7; Digi-Key_PN 160-1772-ND
MF601, MF602, MF603, MF604, MF605: U_Box_V104_General_Alarm_Device_LED_Standoff
Q201, Q202, Q203, Q204, Q205: MMBT2222A-7-F; SOT-23; MPN MMBT2222A-7-F; Digi-Key_PN MMBT2222A-FDICT-ND
R201, R203, R205, R207, R209: 4K7; R_0603_1608Metric_Pad0.98x0.95mm_HandSolder; MPN RMC 0603 4K7 F N
R202, R204, R206, R208, R210: 330R; R_0603_1608Metric_Pad0.98x0.95mm_HandSolder; MPN RMC06033301%N

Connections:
+5V: R202.2, R204.2, R206.2, R208.2, R210.2; also elsewhere on the board
GND: Q201.2 (E), Q202.2 (E), Q203.2 (E), Q204.2 (E), Q205.2 (E); also elsewhere on the board
Light0: R201.2; also elsewhere on the board
Light1: R203.2; also elsewhere on the board
Light2: R205.2; also elsewhere on the board
Light3: R207.2; also elsewhere on the board
Light4: R209.2; also elsewhere on the board
unnamed: D201.1, R202.1
unnamed: D201.2, Q201.3 (C)
unnamed: D202.1, R204.1
unnamed: D202.2, Q202.3 (C)
unnamed: D203.1, R206.1
unnamed: D203.2, Q203.3 (C)
unnamed: D204.1, R208.1
unnamed: D204.2, Q204.3 (C)
unnamed: D205.1, R210.1
unnamed: D205.2, Q205.3 (C)
unnamed: Q201.1 (B), R201.1
unnamed: Q202.1 (B), R203.1
unnamed: Q203.1 (B), R205.1
unnamed: Q204.1 (B), R207.1
unnamed: Q205.1 (B), R209.1

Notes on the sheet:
Alarm lights, 5 Levels

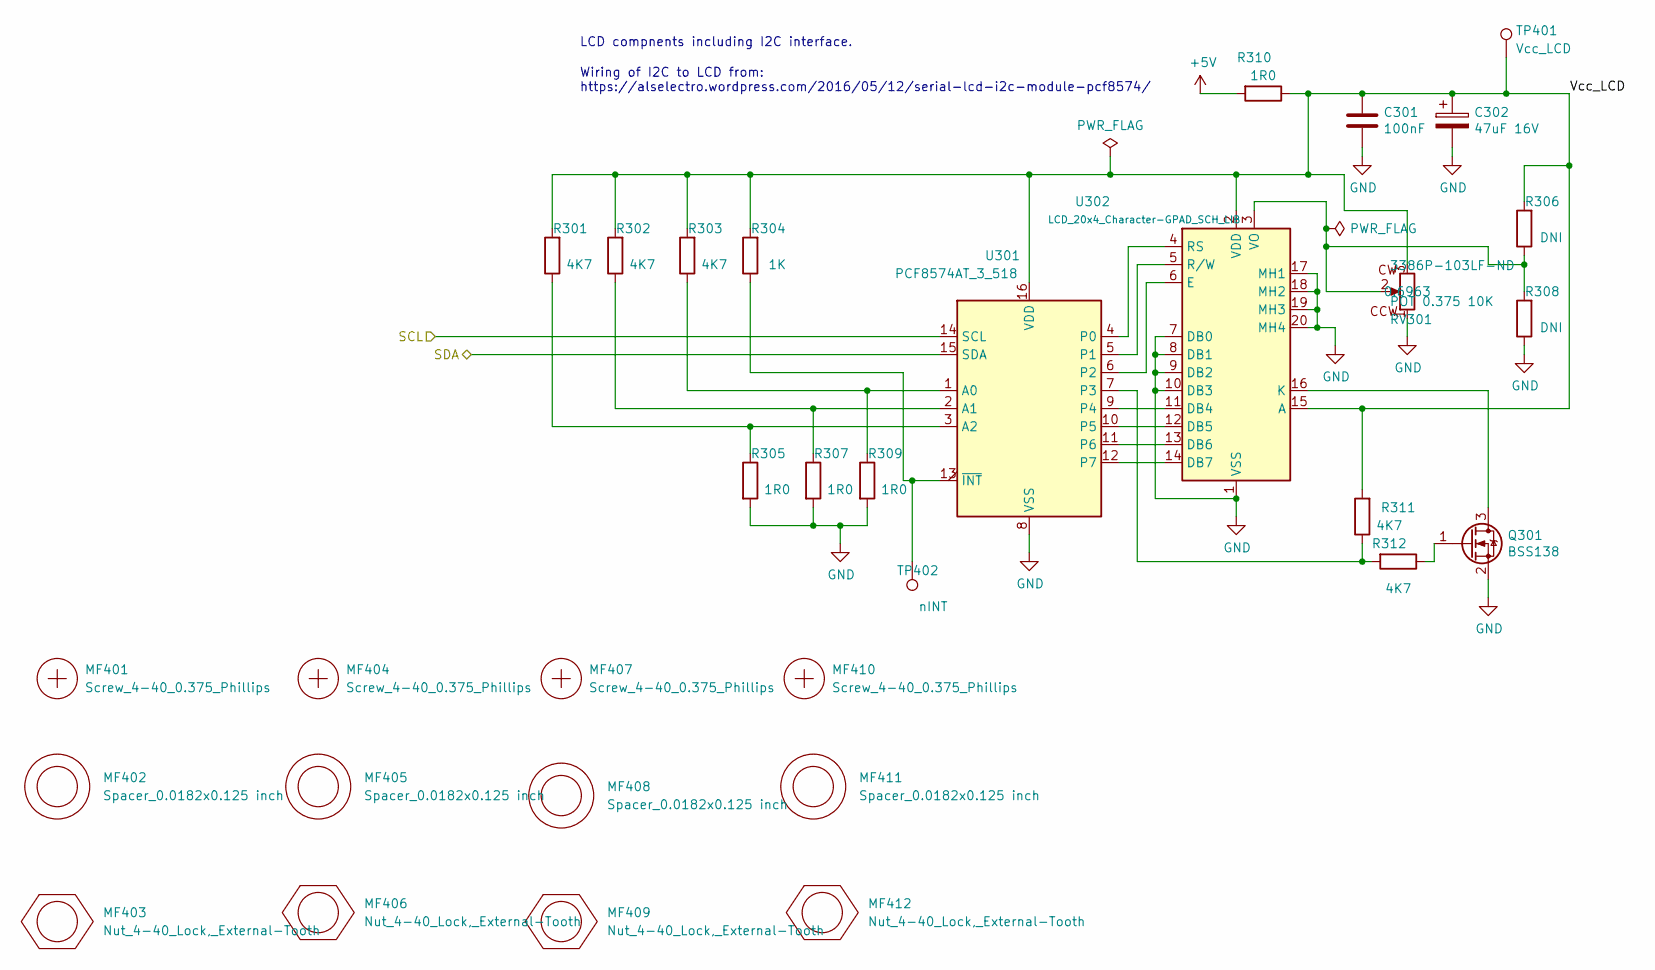
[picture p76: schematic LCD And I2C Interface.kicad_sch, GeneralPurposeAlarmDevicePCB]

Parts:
C301: 100nF; C_0603_1608Metric_Pad1.08x0.95mm_HandSolder; MPN CC0603KRX7R9BB104
C302: 47uF 16V; CP_Elec_5x5.4; MPN RVT47UF16V67RV0019
MF401, MF404, MF407, MF410: Screw_4-40_0.375_Phillips; NA
MF402, MF405, MF408, MF411: Spacer_0.0182x0.125 inch; NA
MF403, MF406, MF409, MF412: Nut_4-40_Lock,_External-Tooth; NA
Q301: BSS138; SOT-23; MPN BSS138
R301, R302, R303, R311, R312: 4K7; R_0603_1608Metric_Pad0.98x0.95mm_HandSolder; MPN RMC 0603 4K7 F N
R304: 1K; R_0603_1608Metric_Pad0.98x0.95mm_HandSolder; MPN RMC06031K1%N
R305, R307, R309, R310: 1R0; R_0603_1608Metric_Pad0.98x0.95mm_HandSolder; MPN RMC060315%N
R306, R308: DNI; R_0603_1608Metric_Pad0.98x0.95mm_HandSolder; MPN DNI
RV301: POT 0.375 10K; Potentiometer_Bourns_3386P_Vertical; MPN 3386P-1-103LF
TP401: Vcc_LCD; TestPoint_Loop_D2.54mm_Drill1.5mm_Beaded
TP402: nINT; TestPoint_Loop_D2.54mm_Drill1.5mm_Beaded
U301: PCF8574AT_3_518; SOIC-16W_7.5x10.3mm_P1.27mm; MPN PCF8574AT_3_518
U302: LCD_20x4_Character-GPAD_SCH_LIB; LCD_2004A

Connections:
+5V: R310.2; also elsewhere on the board
/LCD And I2C Interface/Vcc_LCD: C301.1, C302.1, R301.2, R302.2, R303.2, R304.2, R306.2, R310.1, R311.2, RV301.3, TP401.1, U301.16 (VDD), U302.2 (VDD), U302.15 (A)
GND: C301.2, C302.2, Q301.2 (S), R305.2, R307.2, R308.1, R309.2, RV301.1, U301.8 (VSS), U302.1 (VSS), U302.7 (DB0), U302.8 (DB1), U302.9 (DB2), U302.10 (DB3), U302.17 (MH1), U302.18 (MH2), U302.19 (MH3), U302.20 (MH4); also elsewhere on the board
unnamed: Q301.1 (G), R312.1
unnamed: Q301.3 (D), U302.16 (K)
unnamed: R301.1, R305.1, U301.3 (A2)
unnamed: R302.1, R307.1, U301.2 (A1)
unnamed: R303.1, R309.1, U301.1 (A0)
unnamed: R304.1, TP402.1, U301.13 (~INT)
unnamed: R306.1, R308.2, RV301.2, U302.3 (VO)
unnamed: R311.1, R312.2, U301.7 (P3)
unnamed: U301.4 (P0), U302.4 (RS)
unnamed: U301.5 (P1), U302.5 (R/W)
unnamed: U301.6 (P2), U302.6 (E)
unnamed: U301.9 (P4), U302.11 (DB4)
unnamed: U301.10 (P5), U302.12 (DB5)
unnamed: U301.11 (P6), U302.13 (DB6)
unnamed: U301.12 (P7), U302.14 (DB7)
SCL: U301.14 (SCL); also elsewhere on the board
SDA: U301.15 (SDA); also elsewhere on the board

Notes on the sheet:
Wiring of I2C to LCD from: https://alselectro.wordpress.com/2016/05/12/serial-lcd-i2c-module-pcf8574/
LCD compnents including I2C interface.

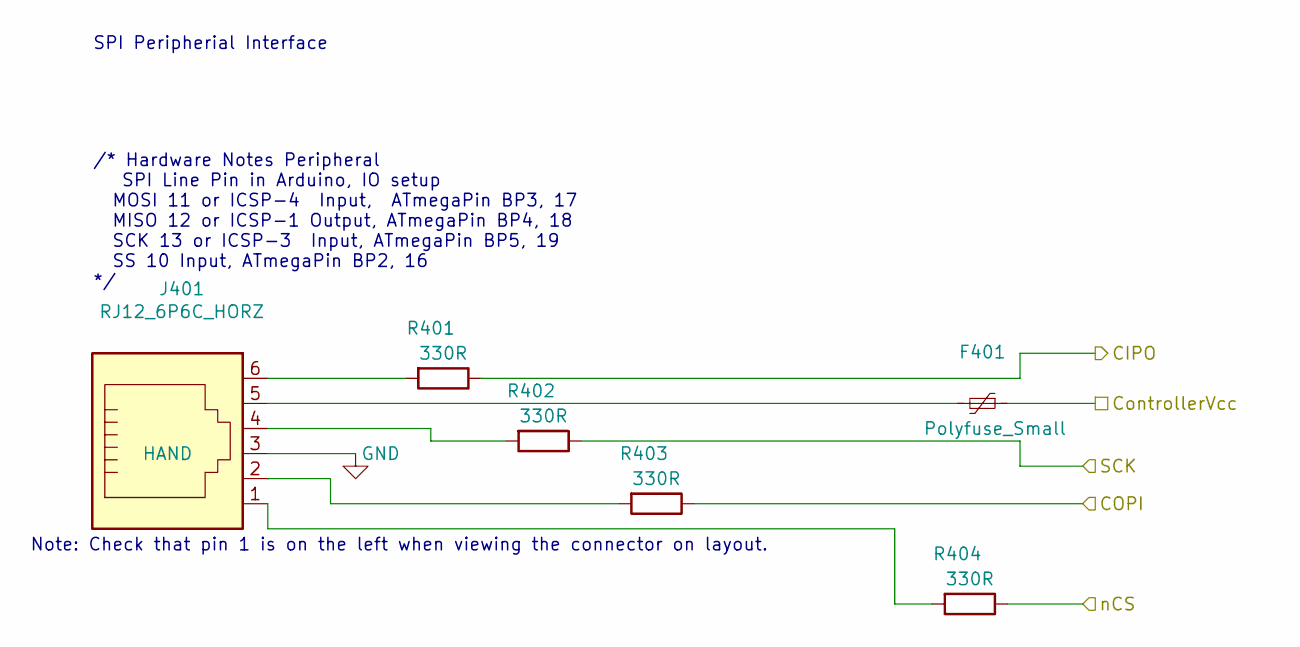
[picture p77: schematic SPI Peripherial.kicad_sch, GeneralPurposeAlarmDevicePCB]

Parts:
F401: Polyfuse_Small; Fuse_0603_1608Metric; MPN 0603L100SLYR
J401: RJ12_6P6C_HORZ; RJ12_Amphenol_54601; MPN 5555165-1
R401, R402, R403, R404: 330R; R_0603_1608Metric_Pad0.98x0.95mm_HandSolder; MPN RMC06033301%N

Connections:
CIPO: R401.1; also elsewhere on the board
COPI: R403.1; also elsewhere on the board
ControllerVcc: F401.1; also elsewhere on the board
GND: J401.3; also elsewhere on the board
unnamed: F401.2, J401.5
unnamed: J401.1, R404.2
unnamed: J401.2, R403.2
unnamed: J401.4, R402.2
unnamed: J401.6, R401.2
SPI_SCK: R402.1; also elsewhere on the board
nCS: R404.1; also elsewhere on the board

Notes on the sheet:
Note: Check that pin 1 is on the left when viewing the connector on layout.
/* Hardware Notes Peripheral SPI Line Pin in Arduino, IO setup MOSI 11 or ICSP-4 Input, ATmegaPin BP3, 17 MISO 12 or ICSP-1 Output, ATmegaPin BP4, 18 SCK 13 or ICSP-3 Input, ATmegaPin BP5, 19 SS 10 Input, ATmegaPin BP2, 16 */
SPI Peripherial Interface

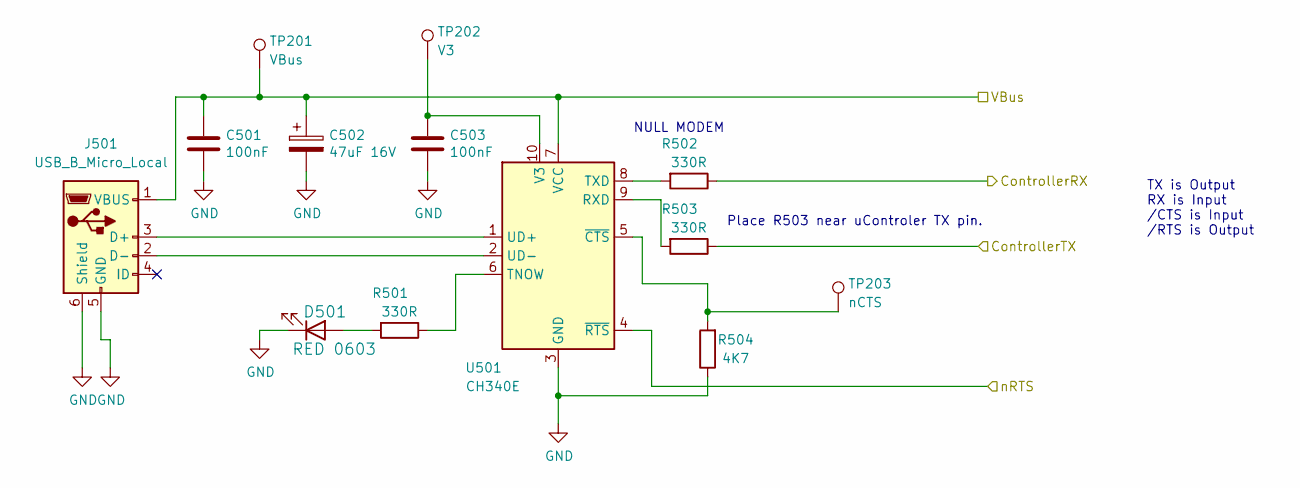
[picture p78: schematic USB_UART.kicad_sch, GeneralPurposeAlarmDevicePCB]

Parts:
C501, C503: 100nF; C_0603_1608Metric_Pad1.08x0.95mm_HandSolder; MPN CC0603KRX7R9BB104
C502: 47uF 16V; CP_Elec_5x5.4; MPN RVT47UF16V67RV0019
D501: RED 0603; LED_0603_1608Metric; MPN KT-0603R
J501: USB_B_Micro_Local; USB_Micro-B_Amphenol_10118194_Horizontal; MPN 10118194-0001LF ???Wuerth_629105150521 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
R501, R502, R503: 330R; R_0603_1608Metric_Pad0.98x0.95mm_HandSolder; MPN RMC06033301%N
R504: 4K7; R_0603_1608Metric_Pad0.98x0.95mm_HandSolder; MPN RMC 0603 4K7 F N
TP201: VBus; TestPoint_Loop_D2.54mm_Drill1.5mm_Beaded
TP202: V3; TestPoint_Loop_D2.54mm_Drill1.5mm_Beaded
TP203: nCTS; TestPoint_Loop_D2.54mm_Drill1.5mm_Beaded
U501: CH340E; MSOP-10_3x3mm_P0.5mm; MPN CH340E

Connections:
ControllerRX: R502.1; also elsewhere on the board
ControllerTX: R503.1; also elsewhere on the board
GND: C501.2, C502.2, C503.2, D501.1 (K), J501.5 (GND), J501.6 (Shield), R504.1, U501.3 (GND); also elsewhere on the board
unnamed: C503.1, TP202.1, U501.10 (V3)
unnamed: D501.2 (A), R501.2
unnamed: J501.2 (D-), U501.2 (UD-)
unnamed: J501.3 (D+), U501.1 (UD+)
unnamed: R501.1, U501.6 (TNOW)
unnamed: R502.2, U501.8 (TXD)
unnamed: R503.2, U501.9 (RXD)
unnamed: R504.2, TP203.1, U501.5 (~CTS)
VBus: C501.1, C502.1, J501.1 (VBUS), TP201.1, U501.7 (VCC); also elsewhere on the board
nRTS: U501.4 (~RTS); also elsewhere on the board

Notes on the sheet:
NULL MODEM
TX is Output RX is Input /CTS is Input /RTS is Output
Place R503 near uControler TX pin.

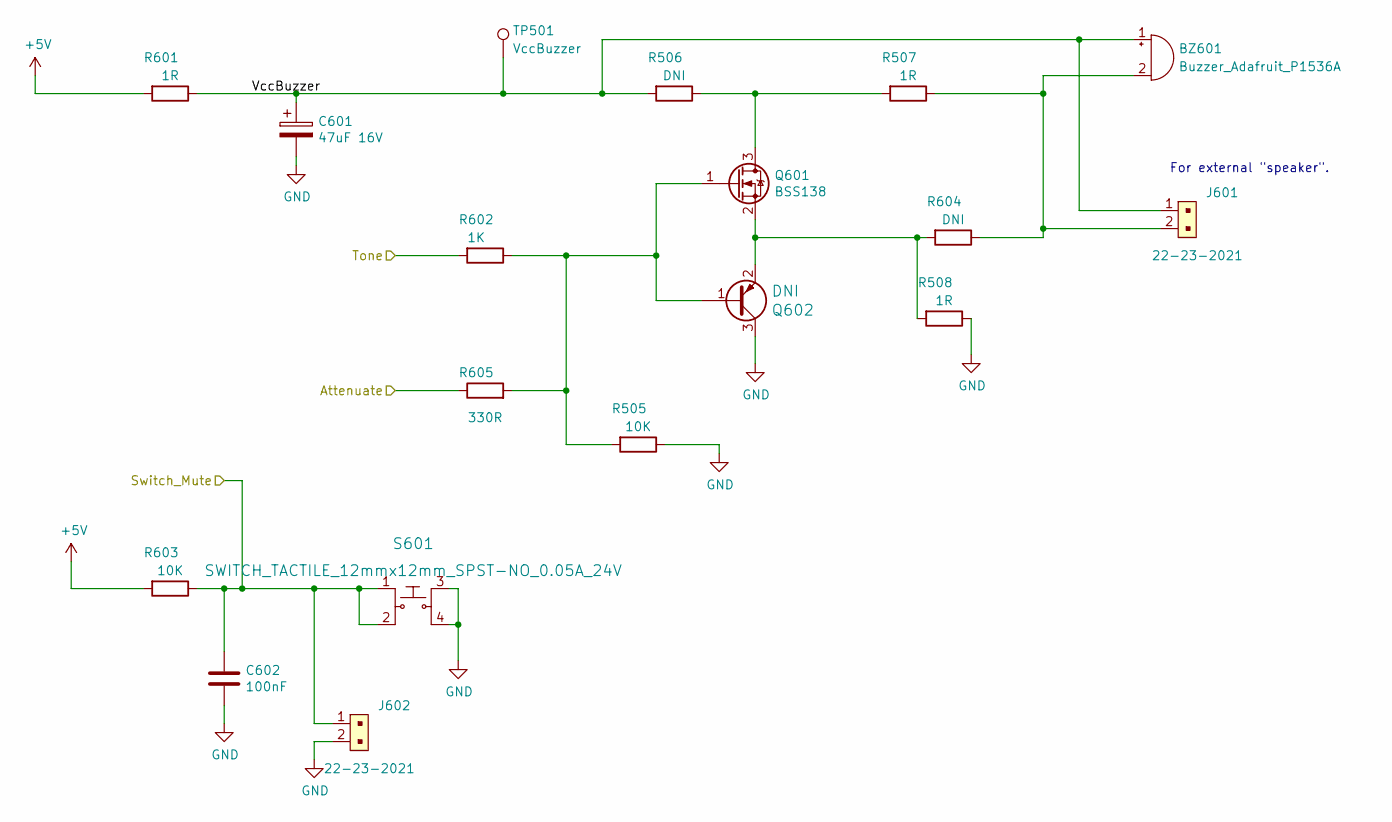
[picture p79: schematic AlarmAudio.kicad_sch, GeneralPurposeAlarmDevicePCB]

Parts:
BZ601: Buzzer_Adafruit_P1536A; Buzzer_12.2mm_9.7mm_7.62mm; MPN PS1240P02BT
C601: 47uF 16V; CP_Elec_5x5.4; MPN RVT47UF16V67RV0019
C602: 100nF; C_0603_1608Metric_Pad1.08x0.95mm_HandSolder; MPN CC0603KRX7R9BB104
J601, J602: 22-23-2021; Molex_KK-254_AE-6410-02A_1x02_P2.54mm_Vertical; MPN 22-23-2021; Digi-Key_PN WM4200-ND
Q601: BSS138; SOT-23; MPN BSS138
Q602: DNI; SOT-23-3; MPN MMBT2907ALT1G; Digi-Key_PN MMBT2907ALT1GOSCT-ND
R505, R603: 10K; R_0603_1608Metric_Pad0.98x0.95mm_HandSolder; MPN RMC 0603 10K F N
R506, R604: DNI; R_0603_1608Metric_Pad0.98x0.95mm_HandSolder; MPN RMC060315%N
R507, R508, R601: 1R; R_0603_1608Metric_Pad0.98x0.95mm_HandSolder; MPN RMC060315%N
R602: 1K; R_0603_1608Metric_Pad0.98x0.95mm_HandSolder; MPN RMC06031K1%N
R605: 330R; R_0603_1608Metric_Pad0.98x0.95mm_HandSolder; MPN RMC06033301%N
S601: SWITCH_TACTILE_12mmx12mm_SPST-NO_0.05A_24V; SW_PUSH-12mm_WithCap_Green; MPN B3F-4055
TP501: VccBuzzer; TestPoint_Loop_D2.54mm_Drill1.5mm_Beaded

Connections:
+5V: R601.2, R603.2; also elsewhere on the board
/AlarmAudio/VccBuzzer: BZ601.1 (-), C601.1, J601.1, R506.2, R601.1, TP501.1
Attenuate: R605.1; also elsewhere on the board
GND: C601.2, C602.2, J602.2, Q602.3 (C), R505.1, R508.1, S601.3, S601.4; also elsewhere on the board
unnamed: BZ601.2 (+), J601.2, R507.1, R604.1
unnamed: Q601.1 (G), Q602.1 (B), R505.2, R602.1, R605.2
unnamed: Q601.2 (S), Q602.2 (E), R508.2, R604.2
unnamed: Q601.3 (D), R506.1, R507.2
Switch_Mute: C602.1, J602.1, R603.1, S601.1, S601.2; also elsewhere on the board
Tone: R602.2; also elsewhere on the board

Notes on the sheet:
For external "speaker".

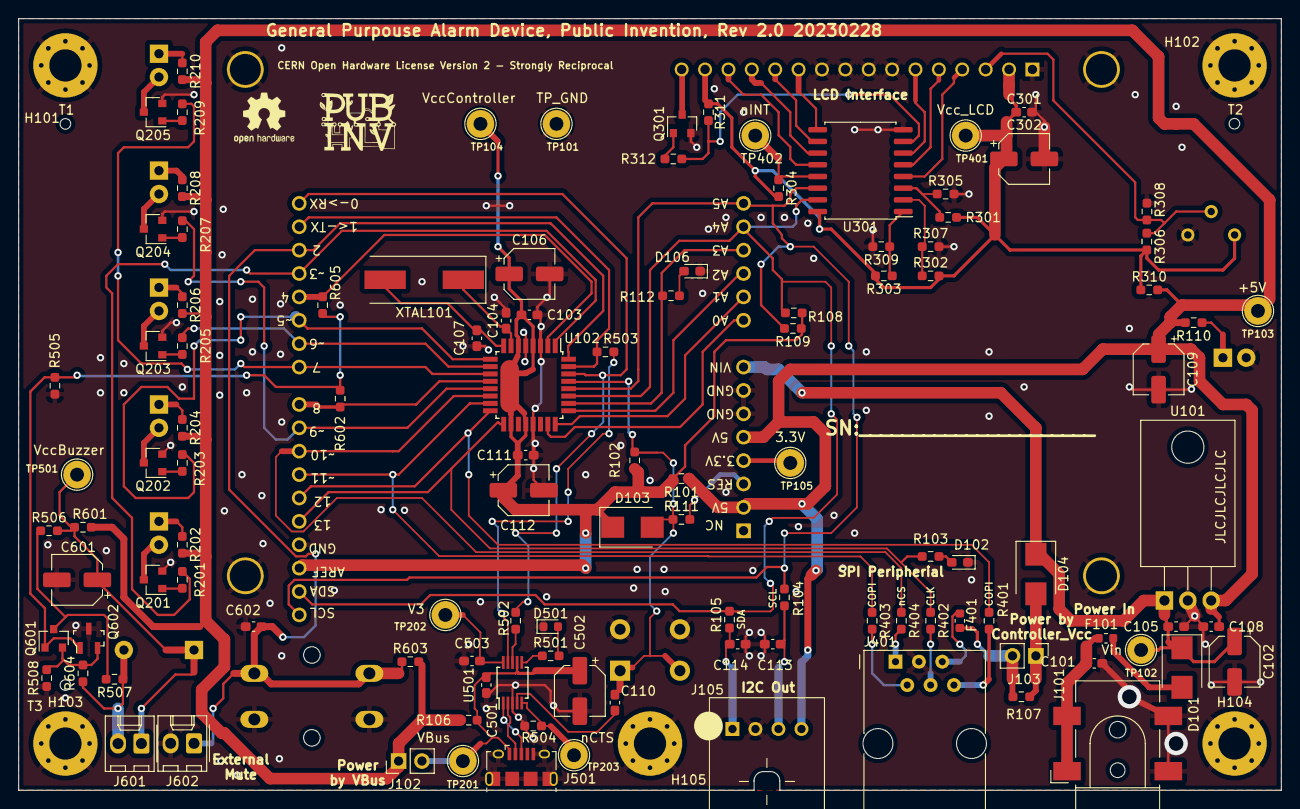
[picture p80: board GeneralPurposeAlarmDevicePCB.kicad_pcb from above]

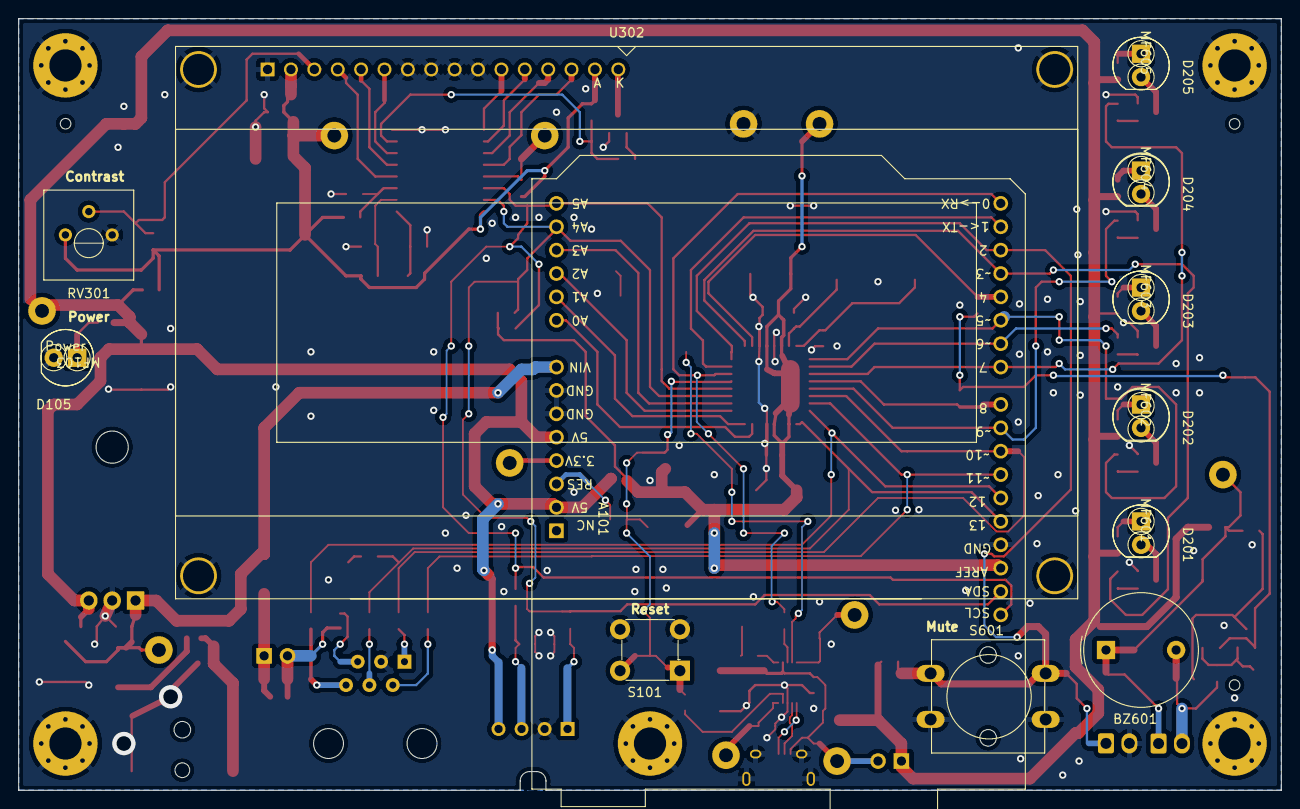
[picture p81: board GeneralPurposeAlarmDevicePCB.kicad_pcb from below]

Board: 2 copper layers, 137.2 x 83.8 mm, 138 parts (18 on the bottom side), 89 nets.

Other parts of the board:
T1, T2, T3: JLC_ToolingHole_0576mm

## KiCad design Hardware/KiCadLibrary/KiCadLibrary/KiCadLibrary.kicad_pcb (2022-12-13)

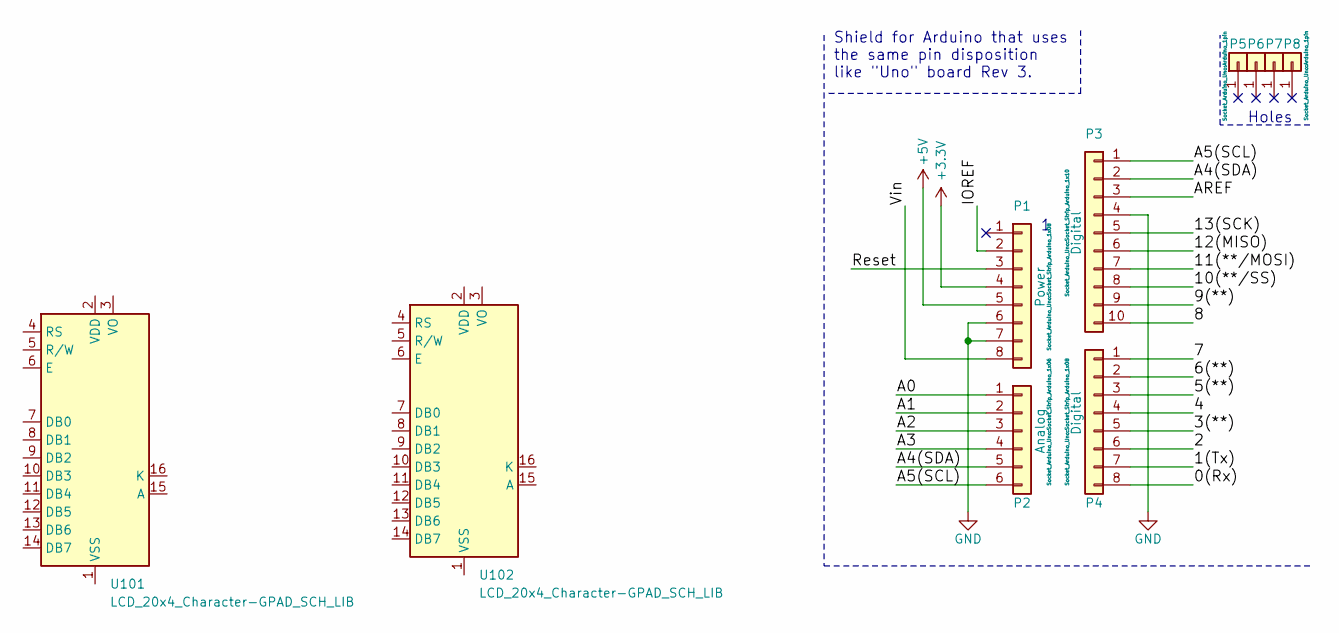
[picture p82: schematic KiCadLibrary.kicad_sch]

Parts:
P1: Power; Socket_Strip_Arduino_1x08
P2: Analog; Socket_Strip_Arduino_1x06
P3: Digital; Socket_Strip_Arduino_1x10
P4: Digital; Socket_Strip_Arduino_1x08
P5, P6, P7, P8: CONN_01X01; Arduino_1pin
U101, U102: LCD_20x4_Character-GPAD_SCH_LIB; LCD_2004A

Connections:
+3V3: P1.4
+5V: P1.5
/0(Rx): P4.8
/1(Tx): P4.7
/2: P4.6
/3(**): P4.5
/4: P4.4
/5(**): P4.3
/6(**): P4.2
/7: P4.1
/8: P3.10
/9(**): P3.9
/10(**/SS): P3.8
/11(**/MOSI): P3.7
/12(MISO): P3.6
/13(SCK): P3.5
/A0: P2.1
/A1: P2.2
/A2: P2.3
/A3: P2.4
/A4(SDA): P2.5, P3.2
/A5(SCL): P2.6, P3.1
/AREF: P3.3
/IOREF: P1.2
/Reset: P1.3
/Vin: P1.8
GND: P1.6, P1.7, P3.4

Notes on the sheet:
Holes
Shield for Arduino that uses the same pin disposition like "Uno" board Rev 3.

Board: 2 copper layers, 10 parts (0 on the bottom side), 3 nets, no tracks yet.

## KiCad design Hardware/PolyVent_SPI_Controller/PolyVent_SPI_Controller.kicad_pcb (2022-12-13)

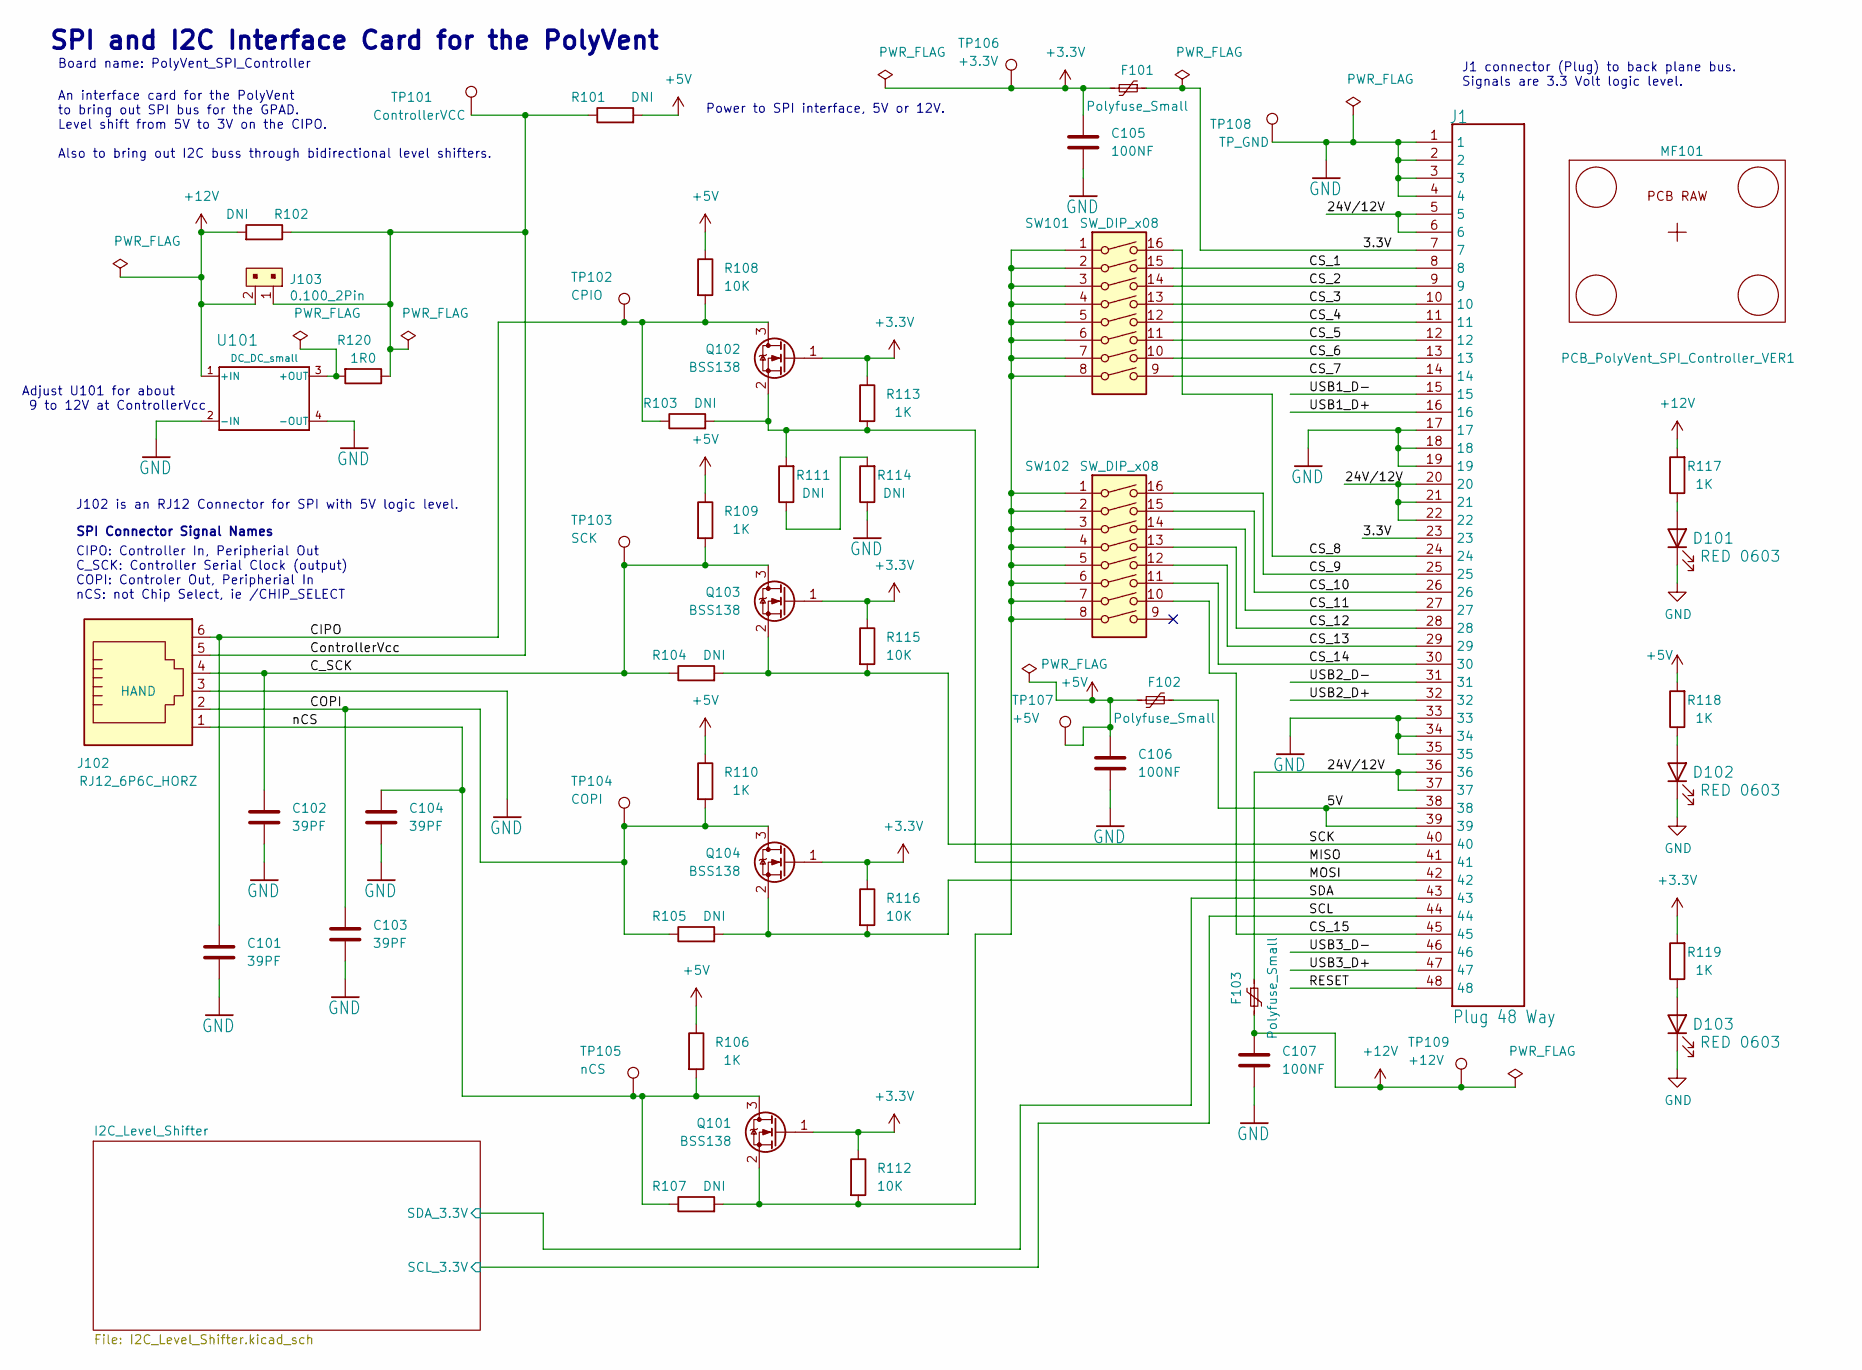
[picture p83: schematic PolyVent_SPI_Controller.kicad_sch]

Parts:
C101, C102, C103, C104: 39PF; C_0603_1608Metric_Pad1.08x0.95mm_HandSolder; MPN CC0603JRNPO9BN390
C105, C106, C107: 100NF; C_0603_1608Metric_Pad1.08x0.95mm_HandSolder; MPN CC0603KRX7R9BB104
D101, D102, D103: RED 0603; LED_0603_1608Metric_Pad1.05x0.95mm_HandSolder; MPN LTST-C171KRKT; Digi-Key_PN 160-1427-1-ND
F101, F102, F103: Polyfuse_Small; Fuse_0603_1608Metric; MPN 0603L100SLYR
J1: Plug 48 Way; HARTING_09231486921; MPN 09231486921
J102: RJ12_6P6C_HORZ; RJ12_Amphenol_54601; MPN 5555165-1
J103: 0.100_2Pin; PinHeader_1x02_P2.54mm_Vertical; MPN 68000-102HLF
MF101: PCB_PolyVent_SPI_Controller_VER1; NA; MPN PCB_PolyVent_SPI_Controller_VER1
Q101, Q102, Q103, Q104: BSS138; SOT-23; MPN BSS138
R101, R102: DNI; R_0603_1608Metric_Pad0.98x0.95mm_HandSolder
R103, R104, R105, R107, R111, R114: DNI; R_0603_1608Metric_Pad0.98x0.95mm_HandSolder; MPN RMC06031K1%N
R106, R109, R110, R113, R117, R118, R119: 1K; R_0603_1608Metric_Pad0.98x0.95mm_HandSolder; MPN RMC06031K1%N
R108, R112, R115, R116: 10K; R_0603_1608Metric_Pad0.98x0.95mm_HandSolder; MPN RMC 0603 10K F N
R120: 1R0; R_0603_1608Metric_Pad0.98x0.95mm_HandSolder; MPN RMC060315%N
SW101, SW102: SW_DIP_x08; SMDIP-16_L11.39_W6.7mm; MPN DHN-08-V-T/R
TP101: ControllerVCC; TestPoint_Loop_D2.54mm_Drill1.5mm_Beaded
TP102: CPIO; TestPoint_Loop_D2.54mm_Drill1.5mm_Beaded
TP103: SCK; TestPoint_Loop_D2.54mm_Drill1.5mm_Beaded
TP104: COPI; TestPoint_Loop_D2.54mm_Drill1.5mm_Beaded
TP105: nCS; TestPoint_Loop_D2.54mm_Drill1.5mm_Beaded
TP106: +3.3V; TestPoint_Loop_D2.54mm_Drill1.5mm_Beaded
TP107: +5V; TestPoint_Loop_D2.54mm_Drill1.5mm_Beaded
TP108: TP_GND; TestPoint_Loop_D2.54mm_Drill1.5mm_Beaded
TP109: +12V; TestPoint_Loop_D2.54mm_Drill1.5mm_Beaded
U101: DC_DC_small; DC_DC_LM2596_small1700x830; MPN LM2596 DC-DC Buck Converter Step Down M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

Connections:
+3.3V: C105.1, F101.2, Q101.1 (G), Q102.1 (G), Q103.1 (G), Q104.1 (G), R112.1, R113.1, R115.1, R116.1, R119.2, TP106.1; also elsewhere on the board
+5V: C106.1, F102.2, R101.2, R106.1, R108.1, R109.1, R110.1, R118.2, TP107.1; also elsewhere on the board
+12V: C107.1, F103.2, J103.2, R102.2, R117.2, TP109.1, U101.1 (+IN); also elsewhere on the board
/3.3V: F101.1, J1.7, J1.23
/5V: F102.1, J1.38, J1.39
/24V/12V: F103.1, J1.5, J1.6, J1.20, J1.21, J1.22, J1.36, J1.37
/CIPO: C101.1, J102.6, Q102.3 (D), R103.1, R108.2, TP102.1
/COPI: C103.1, J102.2, Q104.3 (D), R105.1, R110.2, TP104.1
/CS_1: J1.8, SW101.15
/CS_2: J1.9, SW101.14
/CS_3: J1.10, SW101.13
/CS_4: J1.11, SW101.12
/CS_5: J1.12, SW101.11
/CS_6: J1.13, SW101.10
/CS_7: J1.14, SW101.9
/CS_8: J1.24, SW101.16
/CS_9: J1.25, SW102.16
/CS_10: J1.26, SW102.15
/CS_11: J1.27, SW102.14
/CS_12: J1.28, SW102.13
/CS_13: J1.29, SW102.12
/CS_14: J1.30, SW102.11
/CS_15: J1.45, SW102.10
/C_SCK: C102.1, J102.4, Q103.3 (D), R104.1, R109.2, TP103.1
/ControllerVcc: J102.5, J103.1, R101.1, R102.1, R120.1, TP101.1
/MISO: J1.41, Q102.2 (S), R103.2, R111.2, R113.2
/MOSI: J1.42, Q104.2 (S), R105.2, R116.2
/RESET: J1.48
/SCK: J1.40, Q103.2 (S), R104.2, R115.2
/SCL: J1.44; also elsewhere on the board
/SDA: J1.43; also elsewhere on the board
/USB1_D+: J1.16
/USB1_D-: J1.15
/USB2_D+: J1.32
/USB2_D-: J1.31
/USB3_D+: J1.47
/USB3_D-: J1.46
/nCS: C104.1, J102.1, Q101.3 (D), R106.2, R107.1, TP105.1
GND: C101.2, C102.2, C103.2, C104.2, C105.2, C106.2, C107.2, D101.1 (K), D102.1 (K), D103.1 (K), J1.1, J1.2, J1.3, J1.4, J1.17, J1.18, J1.19, J1.33, J1.34, J1.35, J102.3, R114.1, TP108.1, U101.2 (-IN), U101.4 (-OUT); also elsewhere on the board
unnamed: D101.2 (A), R117.1
unnamed: D102.2 (A), R118.1
unnamed: D103.2 (A), R119.1
unnamed: Q101.2 (S), R107.2, R112.2, SW101.1, SW101.2, SW101.3, SW101.4, SW101.5, SW101.6, SW101.7, SW101.8, SW102.1, SW102.2, SW102.3, SW102.4, SW102.5, SW102.6, SW102.7, SW102.8
unnamed: R111.1, R114.2
unnamed: R120.2, U101.3 (+OUT)

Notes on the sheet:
SPI Connector Signal Names
J1 connector (Plug) to back plane bus. Signals are 3.3 Volt logic level.
Board name: PolyVent_SPI_Controller
Adjust U101 for about 9 to 12V at ControllerVcc
SPI and I2C Interface Card for the PolyVent
CIPO: Controller In, Peripherial Out C_SCK: Controller Serial Clock (output) COPI: Controler Out, Peripherial In nCS: not Chip Select, ie /CHIP_SELECT
Power to SPI interface, 5V or 12V.
J102 is an RJ12 Connector for SPI with 5V logic level.
An interface card for the PolyVent to bring out SPI bus for the GPAD. Level shift from 5V to 3V on the CIPO. Also to bring out I2C buss through bidirectional level shifters.

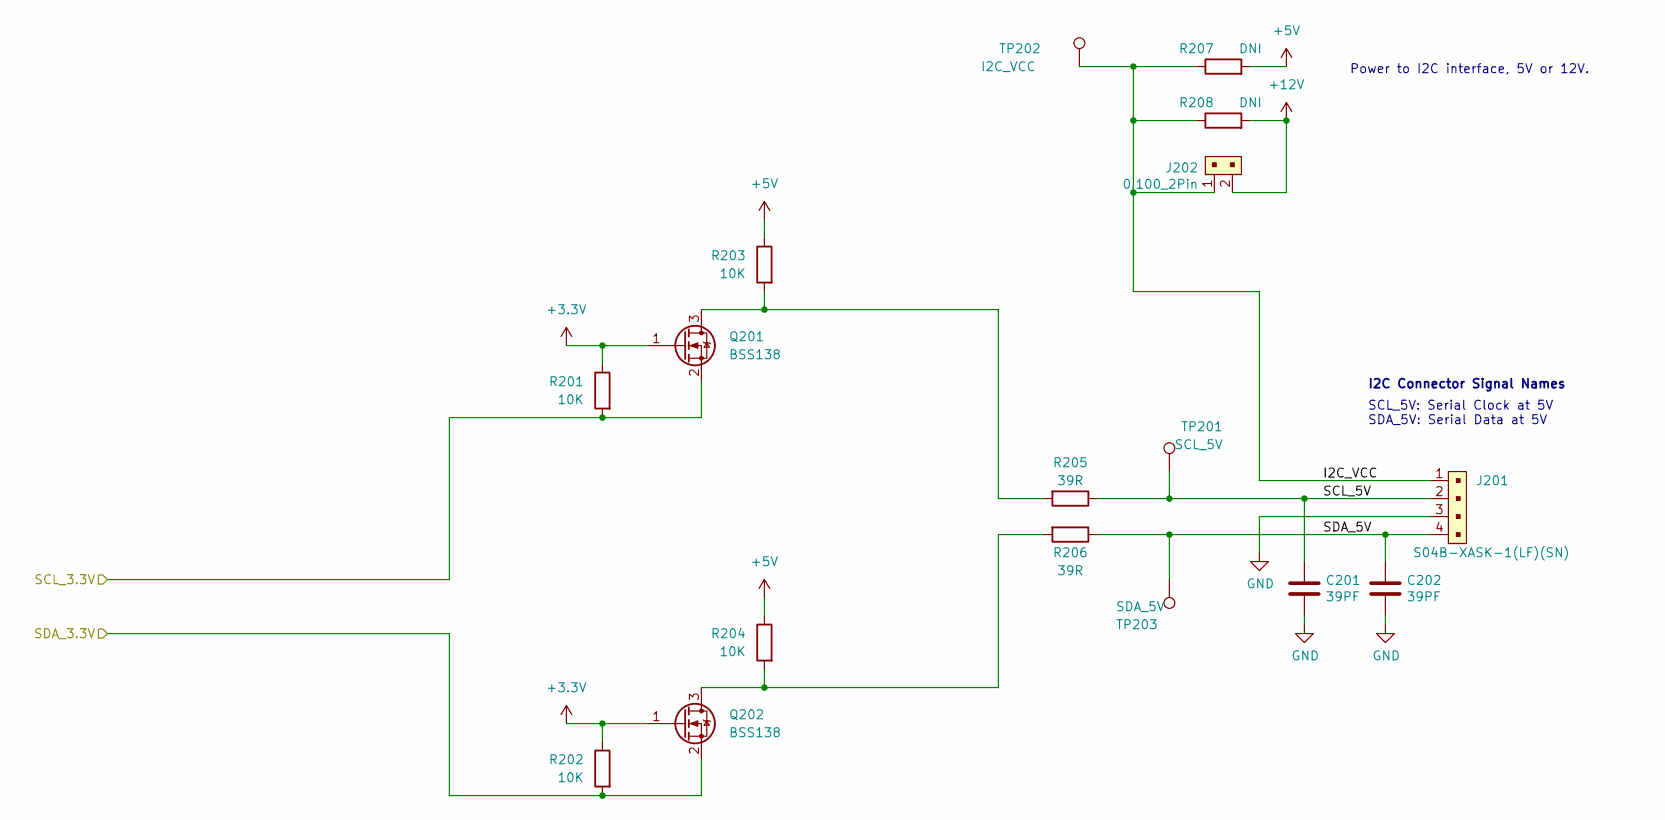
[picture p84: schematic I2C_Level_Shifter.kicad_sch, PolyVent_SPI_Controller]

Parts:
C201, C202: 39PF; C_0603_1608Metric_Pad1.08x0.95mm_HandSolder; MPN CC0603JRNPO9BN390
J201: S04B-XASK-1(LF)(SN); MPN S04B-XASK-1(LF)(SN); Digi-Key_PN 455-4090-ND
J202: 0.100_2Pin; PinHeader_1x02_P2.54mm_Vertical; MPN 68000-102HLF
Q201, Q202: BSS138; SOT-23; MPN BSS138
R201, R202, R203, R204: 10K; R_0603_1608Metric_Pad0.98x0.95mm_HandSolder; MPN RMC 0603 10K F N
R205, R206: 39R; R_0603_1608Metric_Pad0.98x0.95mm_HandSolder; MPN RMC0603391%N
R207, R208: DNI; R_0603_1608Metric_Pad0.98x0.95mm_HandSolder
TP201: SCL_5V; TestPoint_Loop_D2.54mm_Drill1.5mm_Beaded
TP202: I2C_VCC; TestPoint_Loop_D2.54mm_Drill1.5mm_Beaded
TP203: SDA_5V; TestPoint_Loop_D2.54mm_Drill1.5mm_Beaded

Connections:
+3.3V: Q201.1 (G), Q202.1 (G), R201.1, R202.1; also elsewhere on the board
+5V: R203.1, R204.1, R207.2; also elsewhere on the board
+12V: J202.2, R208.2; also elsewhere on the board
/I2C_Level_Shifter/I2C_VCC: J201.1, J202.1, R207.1, R208.1, TP202.1
/I2C_Level_Shifter/SCL_5V: C201.1, J201.2, R205.1, TP201.1
/I2C_Level_Shifter/SDA_5V: C202.1, J201.4, R206.1, TP203.1
/SCL: Q201.2 (S), R201.2; also elsewhere on the board
/SDA: Q202.2 (S), R202.2; also elsewhere on the board
GND: C201.2, C202.2, J201.3; also elsewhere on the board
unnamed: Q201.3 (D), R203.2, R205.2
unnamed: Q202.3 (D), R204.2, R206.2

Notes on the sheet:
I2C Connector Signal Names
Power to I2C interface, 5V or 12V.
SCL_5V: Serial Clock at 5V SDA_5V: Serial Data at 5V

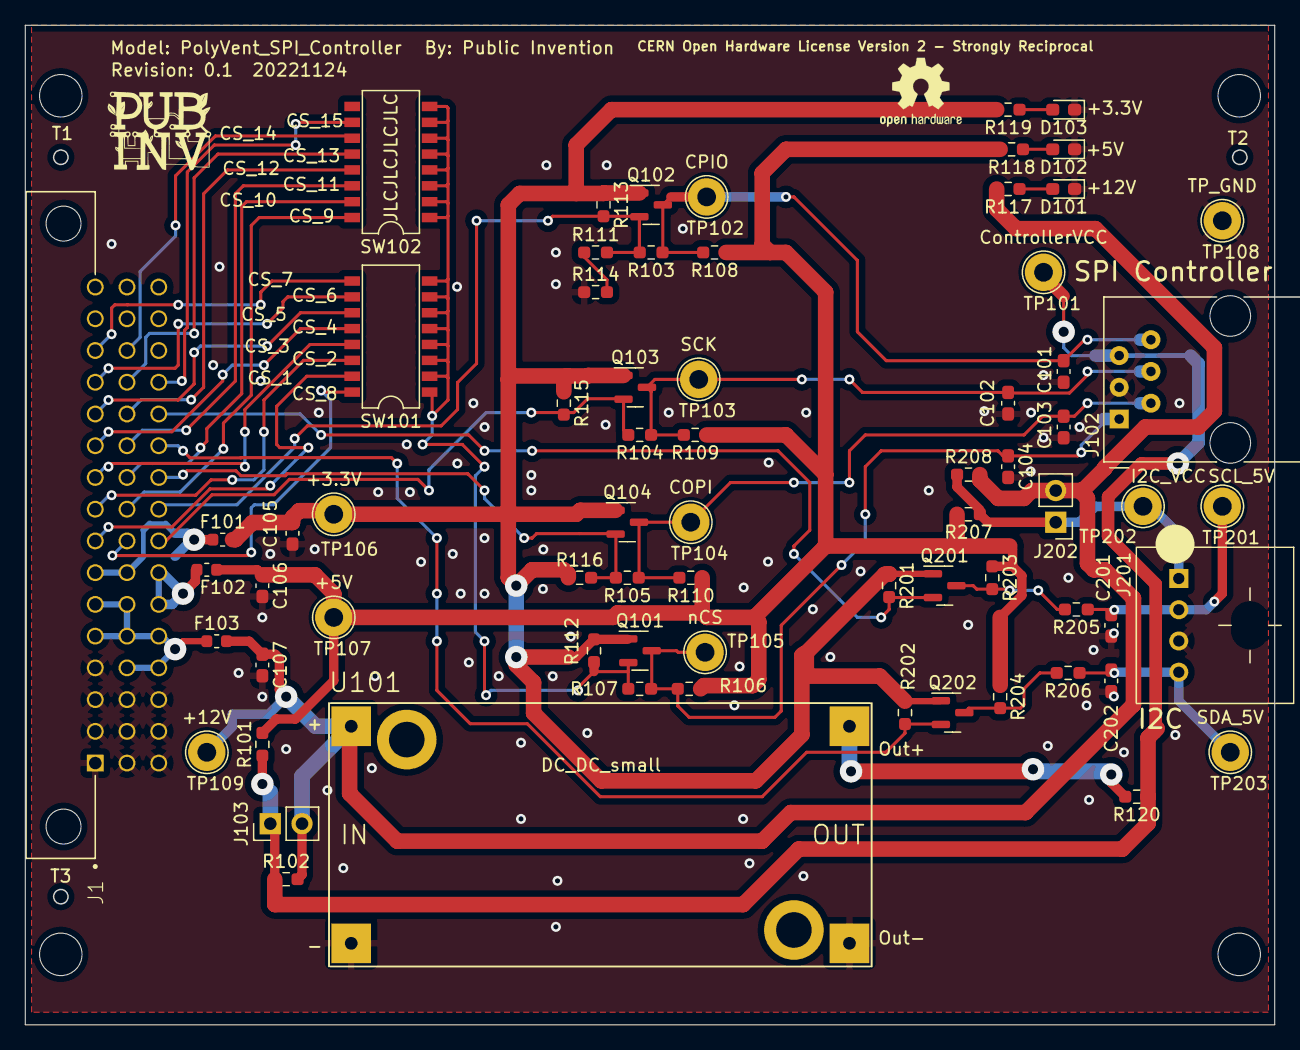
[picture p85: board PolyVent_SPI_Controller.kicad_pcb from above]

Board: 2 copper layers, 100.0 x 80.0 mm, 77 parts (0 on the bottom side), 43 nets.

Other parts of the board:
@HOLE0, @HOLE1, @HOLE2, @HOLE3: (no value)
Graphic1: OSHW-Logo2_7.3x6mm_SilkScreen
T1, T2, T3: JLC_ToolingHole_0576mm

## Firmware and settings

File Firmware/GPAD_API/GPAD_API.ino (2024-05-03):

 /* GPAD_API.ino
  The program implements the main API of the General Purpose Alarm Device.

  Copyright (C) 2022 Robert Read

  This program includes free software: you can redistribute it and/or modify
  it under the terms of the GNU Affero General Public License as
  published by the Free Software Foundation, either version 3 of the
  License, or (at your option) any later version.

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
  Change notes:
  20221024 Creation by Rob.
  20221028 Report Program Name in splash screen. Lee Erickson
*/

/* This is a work-in-progress but it has two purposes.
 * It essentially implements two APIs: An "abstract" API that is
 * intended to be unchanging and possibly implemented on a large
 * variety of hardware devices. That is, as the GPAD hardware
 * changes and evolves, it does not invalidate the use of this API.
 *
 * Secondly, it offers a fully robotic API; that is, it gives
 * complete access to all of the hardware currently on the board.
 * For example, the current hardware, labeled Prototype #1, offers
 * a simple "tone" buzzer. The abstract interface uses this as part
 * of an abstract command like "set alarm level to PANIC".
 * The robotic control allows you to specify the actual tone to be played.
 * The robotic inteface obviously changes as the hardware changes.
 *
 * Both APIs are useful in different situations. The abstract interface
 * is good for a medical device manufacturer that expects the alarming
 * device to change and evolve. The Robotic API is good for testing the
 * actual hardware, and for a hobbyist that wants to use the device for
 * more than simple alarms, such as for implementing a game.
 *
 * It is our intention that the API will be available both through the
 * serial port and through an SPI interface. Again, these two modes
 * serve different purposes. The SPI interface is good for tight
 * intergration with a safey critical devices. The serial port approach
 * is easier for testing and for a hobbyist to develop an approach,
 * whether they eventually intend to use the SPI interface or not.
 * -- rlr, Oct. 24, 2022
 */

#include "alarm_api.h"
#include "robot_api.h"
#include "gpad_utility.h"
#include "gpad_serial.h"

/* SPI_PERIPHERAL
   From: https://circuitdigest.com/microcontroller-projects/arduino-spi-communication-tutorial
   Modified by Forrest Lee Erickson 20220523
   Change to Controller/Peripheral termonology
   Change variable names for start with lowercase. Constants to upper case.
   Peripherial Arduino Code:
   License: Dedicated to the Public Domain
   Warrenty: This program is designed to kill and render the earth uninhabitable,
   however it is not guaranteed to do so.
   20220524 Get working with the SPI_CONTROLER sketch. Made function updateFromSPI().
   20220925 Changes for GPAD Version 1 PCB.  SS on pin 7 and LED_PIN on D3.
   20220927 Change back for GPAD nCS on Pin 10
*/

//SPI PERIPHERAL (ARDUINO UNO)
//SPI COMMUNICATION BETWEEN TWO ARDUINO UNOs
//CIRCUIT DIGEST

/* Hardware Notes Peripheral
   SPI Line Pin in Arduino, IO setup
  MOSI 11 or ICSP-4  Input
  MISO 12 or ICSP-1 Output
  SCK 13 or ICSP-3  Input
  SS 10 Input
*/

#define GPAD_VERSION1

#ifdef GPAD_VERSION1 //The Version 1 PCB.
//#define SS 7                                // nCS aka /SS Input on GPAD Version 1 PCB.
#define LED_PIN PD3                         // for GPAD LIGHT0
#define BUTTON_PIN PD2                      //GPAD Button to GND,  10K Resistor to +5V.

#else //The proof of concept wiring.
#define LED_PIN 7
#define BUTTON_PIN 2                          //Button to GND, 10K Resistor to +5V.


#endif

#define DEBUG_SPI 0
#define DEBUG 0

#include<SPI.h>

volatile boolean isReceived_SPI;
volatile byte peripheralReceived ;

volatile bool procNewPacket = false;
volatile byte indx = 0;
volatile boolean process;

byte received_signal_raw_bytes[MAX_BUFFER_SIZE];

unsigned long last_command_ms;

// We have currently defined our alam time to include 10-second "songs",
// So we will not process a new alarm condition until we have completed one song.
const unsigned long DELAY_BEFORE_NEW_COMMAND_ALLOWED = 10000;

void setup_spi()
{
  Serial.println(F("Starting SPI Peripheral."));
  Serial.print(F("Pin for SS: "));
  Serial.println(SS);

  pinMode(BUTTON_PIN, INPUT);              // Setting pin 2 as INPUT
  pinMode(LED_PIN, OUTPUT);                // Setting pin 7 as OUTPUT

  //  SPI.begin();    // IMPORTANT. Do not set SPI.begin for a peripherial device.
  pinMode(SS, INPUT_PULLUP); //Sets SS as input for peripherial
  // Why is this not input?
  pinMode(MOSI, INPUT);    //This works for Peripheral
  pinMode(MISO, OUTPUT);    //try this.
  pinMode(SCK, INPUT);                  //Sets clock as input
  SPCR |= _BV(SPE);                       //Turn on SPI in Peripheral Mode

  // turn on interrupts
  SPCR |= _BV(SPIE);
  isReceived_SPI = false;
  SPI.attachInterrupt();                  //Interuupt ON is set for SPI commnucation

}//end setup()

//ISRs
// This is the original...
// I plan to add an index to this to handle the full message that we intend to receive.
// However, I think this also needs a timeout to handle the problem of getting out of synch.
const int SPI_BYTE_TIMEOUT_MS = 200; // we don't get the next byte this fast, we reset.
volatile unsigned long last_byte_ms = 0;
ISR (SPI_STC_vect)                        //Inerrrput routine function
{
   receive_byte(SPDR);
}//end ISR


void receive_byte(byte c)
{
  last_byte_ms = millis();
  // byte c = SPDR; // read byte from SPI Data Register
  if (indx < sizeof received_signal_raw_bytes) {
    received_signal_raw_bytes[indx] = c; // save data in the next index in the array received_signal_raw_bytes
    indx++;
  }
  if (indx >= sizeof received_signal_raw_bytes) {
    process = true;
  }
}


void updateFromSPI()
{
   if (DEBUG > 0) {
    if (process) {
      Serial.println("process true!");
    }
  }
  if(process)
  {
   
    AlarmEvent event;
    event.lvl = (AlarmLevel) received_signal_raw_bytes[0];
    for(int i = 0; i < MAX_MSG_LEN; i++) {
      event.msg[i] = (char) received_signal_raw_bytes[1+i];
    }

    if (DEBUG > 1) {
      Serial.print(F("LVL: "));
      Serial.println(event.lvl);
      Serial.println(event.msg);
    }
    int prevLevel = alarm((AlarmLevel) event.lvl, event.msg,&Serial);
    if (prevLevel != event.lvl) {
      annunciateAlarmLevel(&Serial);
    } else {
      unchanged_anunicateAlarmLevel(&Serial);
    }
  
    indx = 0;
    process = false;

  }
}

// #define VERSION 0.02             //Version of this software
#define BAUDRATE 115200
// #define BAUDRATE 57600
// Let's have a 10 minute time out to allow people to compose strings by hand, but not
// to leave data our there forever
// #define SERIAL_TIMEOUT_MS 600000
#define SERIAL_TIMEOUT_MS 1000

//Set LED wink parameters
const int HIGH_TIME_LED_MS = 800;    //time in milliseconds
const int LOW_TIME_LED_MS = 200;
unsigned long lastLEDtime_ms = 0;
unsigned long nextLEDchangee_ms = 100; //time in ms.

// extern int LIGHT[];
// extern int NUM_LIGHTS;

// Functions

void updateWink(void) {
  //Wink the built in LED
  const unsigned long m = millis();
  if (((m - lastLEDtime_ms) > nextLEDchangee_ms) || (m < lastLEDtime_ms)) {
    if (digitalRead(LED_BUILTIN) == LOW) {
      digitalWrite(LED_BUILTIN, HIGH);   // turn the LED on (HIGH is the voltage level)
      nextLEDchangee_ms = HIGH_TIME_LED_MS;
    } else {
      digitalWrite(LED_BUILTIN, LOW);   // turn the LED on (HIGH is the voltage level)
      nextLEDchangee_ms = LOW_TIME_LED_MS;
    }
    lastLEDtime_ms = m;
  }//end of Wink
}


void setup() {
  //Lets make the LED high near the start of setup for visual clue
  pinMode(LED_BUILTIN, OUTPUT);      // set the LED pin mode
  digitalWrite(LED_BUILTIN, HIGH);   // turn the LED on (HIGH is the voltage level)

  //Serial setup
  delay(100);
  Serial.begin(BAUDRATE);
  delay(100);                         //Wait before sending the first data to terminal
  Serial.setTimeout(SERIAL_TIMEOUT_MS);
  Serial.println(VERSION);
  robot_api_setup(&Serial);

  setup_spi();
  digitalWrite(LED_BUILTIN, LOW);   // turn the LED off at end of setup
  Serial.println(F("Done With Setup!"));
}// end of setup()

unsigned long last_ms = 0;

void loop() {
  updateWink(); //The builtin LED


// because we are now using "songs", we need to call this periodically
  unchanged_anunicateAlarmLevel(&Serial);
  delay(20);
  robot_api_loop();

  processSerial(&Serial);

  // Now try to read from the SPI Port!
  updateFromSPI();

  if (DEBUG > 1) {
    unsigned long ms = millis();
    if ((ms - last_ms) > 3000) {
      Serial.println("INDX :");
      Serial.println(indx);
      last_ms = ms;
    }
  }
}

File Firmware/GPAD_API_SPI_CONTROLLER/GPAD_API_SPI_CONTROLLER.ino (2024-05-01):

/* GPAD_API_SPI_CONTROLLER.ino

  GPAD_API_SPI_CONTROLLER.ino - Controller code for using one GPAD to control another.

  Copyright (C) 2023 Forrest Lee Erickson, 2024 Robert L. Read

  This program includes free software: you can redistribute it and/or modify
  it under the terms of the GNU Affero General Public License as
  published by the Free Software Foundation, either version 3 of the
  License, or (at your option) any later version.

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
   From: https://circuitdigest.com/microcontroller-projects/arduino-spi-communication-tutorial
   Modified by Forrest Lee Erickson 20220523
   Change to Controller/Peripheral termonology
   Change variable names for start with lowercase. Constants to uper case.
   Controller Arduino Code:
   20220524 Get working with the SPI_PERIPHERAL sketch.
   20220525 The SCK period is about 250nS as set up.
   20220927 Change for button to have internal pull up.  Add Resistor and LED from pins 7 to 6.
*/

//SPI CONTROLLER (ARDUINO UNO)
//SPI COMMUNICATION BETWEEN TWO ARDUINO UNOs
//CIRCUIT DIGEST

#define PROG_NAME "SPI CONTROLLER" 
#define VERSION 0.1
#define BAUDRATE 115200

/* Hardware Notes, Controller
   SPI Line Pin in Arduino
  MOSI 11 or ICSP-4  Output
  MISO 12 or ICSP-1 Input
  SCK 13 or ICSP-3 Output
  SS 10  Output
  330 Ohm resistor and LED from pin 7 to pin 6.
  LED will be high untill the peripheral button is pressed.

*/

#include<SPI.h>                             //Library for SPI
#define LED_PIN 7                           //Add this LED + Resistor
#define LED_CATHODE 6                        //A pin to sink LED current
#define BUTTON_PIN 2                        //Button to GND, 10K Resistor to +5V.

#include "GPAD_Alarm_API_SPI.h"


/*
 * Note: The GPAD has an SPI interface which could be programmmed in any way,
 * But the obvious way to do this is to use a GPAD itself as an SPI Controller.
 * The GPAD is an "Arduion Duemilanove". 
 * However, we (Public Invention) also want to drive a GPAD from the PolyVent,
 * which uses an ESP32-based architecture, which uses a different output pin
 * for the "MOSI" (Master out, server in.) The upshot of all of this (which is 
 * perhaps obvious) is that wherever you run this code on any microcontroller,
 * you may to make sure the GPAD_CS pin is the one you REALLY are connecting to 
 * the GPAD.
 */
// #define USE_POLYVENT_ARCH 1


#ifdef USE_POLYVENT_ARCH
// If you aren't on the PolyVent team, you don't want to do this---we are keeping
// this confusing thing here for to facilitate our testing on mulitple architectures.
#define GPAD_CS_IDX (11-1)
const uint8_t ESP_CS_PINS[11] =  {4, 5, 13, 14, 15, 16, 17, 25, 26, 32, 33};
int GPAD_CS = ESP_CS_PINS[GPAD_CS_IDX];
#else
int GPAD_CS = SS;
#endif

// #define USE_LCD 1
// #define USE_LCD 0
#ifdef USE_LCD
//For LCD -- this is useful if you are using a GPAD as a controller, but 
#include <LiquidCrystal_I2C.h>
LiquidCrystal_I2C lcd(0x38, 20, 4); // set the LCD address to 0x27 for a 20 chars and 4 line display in Wokwi, and 0x38 for the physical GPAD board
#endif

#define SETTING_CHANGE_DELAY_MS 5000

/* Assumes LCD has been initilized
 * Turns off Back Light
 * Clears display
 * Turns on back light.
 */
void clearLCD(void) {  
#ifdef USE_LCD
  lcd.noBacklight();
  lcd.clear();
#endif
}

//Splash a message so we can tell the LCD is working
void splashLCD(void) {
#ifdef USE_LCD
  lcd.init();                      // initialize the lcd
  // Print a message to the LCD.
  lcd.backlight();
  lcd.setCursor(0, 0);
  lcd.print(PROG_NAME);
  lcd.setCursor(3, 1);
  lcd.print("GPAD Starting");
  lcd.setCursor(0, 2);
  lcd.print("by PubInv & SPEC");
  lcd.setCursor(0, 3);
  lcd.print("Version: ");
  lcd.print(VERSION);
#endif
}// end splashLCD



void local_setup(void) {

  // if you need it for debugging, you can slow the SPI clock down
  //For SPI clock rates, see https://www.arduino.cc/reference/en/language/functions/communication/spi/setclockdivider/
  // At this speed (2MHZ), we were missing bytes with a 12" cable.
  //SPI.setClockDivider(SPI_CLOCK_DIV8);    //Sets clock for SPI communication at 8 (16/8=2Mhz)
  // At this speed, with a 12" cable, I noticed no dropped bytes.
  // This is the one we recently used...
  // #if defined(ARDUINO_UNOWIFIR4)
  // #else
  //  SPI.setClockDivider(SPI_CLOCK_DIV16);
  // #endif
  //SPI clock at 16MHz/N (16/16=1Mhz) where N={2,4,8,16,32,64,128}
  //SPI.setClockDivider(SPI_CLOCK_DIV64);    //SPI clock at 16MHz/N (16/64=250Khz) where N={2,4,8,16,32,64,128}
  //SPI.setClockDivider(SPI_CLOCK_DIV128);    //SPI clock at 16MHz/N (16/128=125Khz) where N={2,4,8,16,32,64,128}

// Note: We believe the speed can be controlled by the SPISettings ojbection in
// GPAD_ALARM_API_SPI.cpp
  pinMode(GPAD_CS, OUTPUT);                    // Set nCS for output
  pinMode(MISO, INPUT);                   //Sets MISO as INPUT. Note MOSI must be set automaticaly
  SPI.begin();                            //Begins the SPI commnuication


#ifdef USE_LCD
  Wire.begin();
  lcd.init();
  Serial.println(F("Clear LCD"));
  clearLCD();
  delay(100);
  Serial.println(F("Start LCD splash"));
  splashLCD();
  Serial.println(F("EndLCD splash"));
#endif

  digitalWrite(GPAD_CS, HIGH);                 // Setting PeripheralSelect as HIGH (So controller doesnt connnect with peripheral)
  delay(100);
  Serial.println(F("SETUP DONE!"));

  Serial.println("MISO,MOSI,GPAD_CS,SCK");
  Serial.println(MISO);
  Serial.println(MOSI);
  Serial.println(GPAD_CS);
  Serial.println(SCK);
}
void setup (void)
{
  Serial.begin(BAUDRATE);                   //Starts Serial Communication at Baud Rate 115200
  delay(500);
  Serial.println(F("Starting SPI Controller."));

#ifndef USE_POLYVENT_ARCH
  pinMode(BUTTON_PIN, INPUT_PULLUP);               //Sets pin 2 as input
  pinMode(LED_PIN, OUTPUT);                   //Sets pin 7 as Output

  pinMode(LED_CATHODE, OUTPUT);               //Sets pin 6 as Output
  digitalWrite(LED_CATHODE, LOW);             //Sets pin 6 to sink LED current
#endif
  local_setup();
 
}// end setup()

int cnt = 2;
void desire_loop(void)
{
  AlarmEvent event;
  event.lvl = cnt++ % 6;
  strcpy(event.msg,"Be True; You need noBe True; You need noBe True; You need noBe True; You need no");
  
  alarm_event(event,Serial);
  Serial.println(F("Done with Datum Send!"));
  delay(3000);
}

// int cnt = 0;
unsigned long timer;
int toggle = 0;
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

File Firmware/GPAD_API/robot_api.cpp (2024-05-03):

/* robot_api.cpp
   the "robot" (low-level hardware) api

  Copyright (C) 2022 Robert Read

  This program includes free software: you can redistribute it and/or modify
  it under the terms of the GNU Affero General Public License as
  published by the Free Software Foundation, either version 3 of the
  License, or (at your option) any later version.

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
*/

#include <arduino.h>
#include "robot_api.h"
#include "alarm_api.h"
#include "gpad_utility.h"

#include <DailyStruggleButton.h>
DailyStruggleButton muteButton;

extern const char *AlarmNames[];
extern AlarmLevel currentLevel;
extern bool currentlyMuted;
extern char AlarmMessageBuffer[81];

//For LCD
#include <LiquidCrystal_I2C.h>
LiquidCrystal_I2C lcd(0x38, 20, 4); // set the LCD address to 0x27 for a 20 chars and 4 line display in Wokwi, and 0x38 for the physical GPAD board


//Setup for buzzer.
//const int BUZZER_TEST_FREQ = 130; // One below middle C3. About 67 db, 3" x 4.875" 8 Ohm speakers no cabinet at 1 Meter.
//const int BUZZER_TEST_FREQ = 260; // Middle C4. About ?? db, 3" x 4.875" 8 Ohm speakers no cabinet at 1 Meter.
//const int BUZZER_TEST_FREQ = 1000; //About 76 db, 3" x 4.875" 8 Ohm speakers no cabinet at 1 Meter.
const int BUZZER_TEST_FREQ = 4000; // Buzzers, 3 V 4kHz 60dB @ 3V, 10 cm.  The specified frequencey for the Version 1 buzzer.

const int BUZZER_LVL_FREQ_HZ[]= {0,128,256,512,1024,2048};

// This as an attempt to program recognizable "songs" for each alarm level that accomplish
// both informativeness and urgency mapping. The is is to use an index into the buzzer 
// level frequencies above, so we can use an unsigned char. We can break the whole
// sequence into 100ms chunks. A 0 will make a "rest" or a silence.a length of 60 will
// give us a 6-second repeat.

const unsigned int NUM_NOTES = 20;
const int SONGS[][NUM_NOTES] = { { 0,0,0,0,0,0,0,0,0,0,0,0,0,0,0,0,0,0,0,0},
 { 1,1,1,1,1,0,0,0,0,0,1,1,1,1,1,0,0,0,0,0},
 { 2,2,0,2,2,0,0,0,0,0,2,2,2,0,2,2,0,0,0,0},
 { 3,3,3,0,3,3,3,3,0,3,3,3,0,3,3,3,0,0,0,0},
 { 4,0,4,0,4,0,4,0,0,0,4,0,4,0,4,0,4,0,0,0},
 { 4,4,2,0,4,4,2,0,4,4,2,0,4,4,2,0,4,4,2,0}};

 const int LIGHT_LEVEL[][NUM_NOTES] = { { 0,0,0,0,0,0,0,0,0,0,0,0,0,0,0,0,0,0,0,0},
 { 1,1,1,1,1,0,0,0,0,0,1,1,1,1,1,0,0,0,0,0},
 { 2,2,0,2,2,0,0,0,0,0,2,2,2,0,2,2,0,0,0,0},
 { 3,3,3,0,3,3,3,3,0,3,3,3,0,3,3,3,0,0,0,0},
 { 4,4,4,0,4,4,4,0,0,0,4,4,4,0,4,4,4,0,0,0},
 { 0,5,0,5,0,5,0,5,0,5,0,5,0,5,0,5,0,5,0,5}};

const unsigned LEN_OF_NOTE_MS = 500;

unsigned long start_of_song = 0;
 


// in general, we want tones to last forever, although
// I may implement blinking later.
const unsigned long INF_DURATION = 4294967295;




//Allow indexing to LIGHT[] by symbolic name. So LIGHT0 is first and so on.
int LIGHT[] = {LIGHT0, LIGHT1, LIGHT2, LIGHT3, LIGHT4};
int NUM_LIGHTS = sizeof(LIGHT)/sizeof(LIGHT[0]);

Stream* local_ptr_to_serial;

// Have to get a serialport here
void myCallback(byte buttonEvent){
  switch (buttonEvent){
    case onPress:
      // Do something...
      local_ptr_to_serial->println(F("onPress"));
      currentlyMuted = !currentlyMuted;
      start_of_song = millis();
      annunciateAlarmLevel(local_ptr_to_serial);
      printAlarmState(local_ptr_to_serial);
      break;
  }
}


void robot_api_setup(Stream *serialport) {

  local_ptr_to_serial = serialport;
  Wire.begin();
  lcd.init();
  serialport->println(F("Clear LCD"));
  clearLCD();
  delay(100);
  serialport->println(F("Start LCD splash"));
  splashLCD();
  serialport->println(F("EndLCD splash"));

  serialport->println(F("Set up GPIO pins"));
  pinMode(SWITCH_MUTE, INPUT_PULLUP);
  for (int i = 0; i < NUM_LIGHTS; i++) {
    serialport->println(LIGHT[i]);
    pinMode(LIGHT[i], OUTPUT);
  }

  muteButton.set(SWITCH_MUTE, myCallback);
  serialport->println(F("end set up GPIO pins"));

  printInstructions(serialport);
  AlarmMessageBuffer[0] = '\0';

  digitalWrite(LED_BUILTIN, LOW);   // turn the LED off at end of setup
}



// This has to be called periodically, at a minimum to handle the mute_button
void robot_api_loop() {
    muteButton.poll();
}

/* Assumes LCD has been initilized
 * Turns off Back Light
 * Clears display
 * Turns on back light.
 */
void clearLCD(void) {
  lcd.noBacklight();
  lcd.clear();
}

//Splash a message so we can tell the LCD is working
void splashLCD(void) {
  lcd.init();                      // initialize the lcd
  // Print a message to the LCD.
  lcd.backlight();
  lcd.setCursor(0, 0);
  lcd.print(PROG_NAME);
  lcd.setCursor(3, 1);
  lcd.print("GPAD Starting");
  lcd.setCursor(0, 2);
  lcd.print("by PubInv & SPEC");
  lcd.setCursor(0, 3);
  lcd.print("Version: ");
  lcd.print(VERSION);
}
// TODO: We need to break the message up into strings to render properly
// on the display
void showStatusLCD(AlarmLevel level,bool muted,char *msg) {
  lcd.init();
  lcd.clear();
  // Possibly we don't need the backlight if the level is zero!
  if (level != 0) {
    lcd.backlight();
  } else {
    lcd.noBacklight();
  }

  lcd.print("LVL: ");
  lcd.print(level);
  lcd.print(" - ");
  lcd.print(AlarmNames[level]);

  int msgLineStart = 1;
  lcd.setCursor(0,msgLineStart);
  int len = strlen(AlarmMessageBuffer);
  if (len < 9) {
    if (muted) {
      lcd.print("MUTED! MSG:");
    } else {
      lcd.print("MSG:  ");
    }
    msgLineStart = 2;
  }
    if (strlen(AlarmMessageBuffer) == 0) {
      lcd.print("None.");
    } else {

    char buffer[21] = {0}; // note space for terminator

    size_t len = strlen(msg);      // doesn't count terminator
    size_t blen = sizeof(buffer)-1; // doesn't count terminator
    size_t i = 0;
    // the actual loop that enumerates your buffer
    for (i=0; i<(len/blen + 1) && i + msgLineStart < 4; ++i)
    {
      memcpy(buffer, msg + (i*blen), blen);
      local_ptr_to_serial->println(buffer);
      lcd.setCursor(0,i+msgLineStart);
      lcd.print(buffer);
    }
   }
}


// This operation is idempotent if there is no change in the abstract state.
void set_light_level(int lvl) {
  for(int i = 0; i < lvl; i++) {
    digitalWrite(LIGHT[i],HIGH);
  }
  for(int i = lvl; i < NUM_LIGHTS; i++) {
    digitalWrite(LIGHT[i],LOW);
  }
}
void unchanged_anunicateAlarmLevel(Stream* serialport) {
  unsigned long m = millis();
  unsigned long time_in_song = m - start_of_song;
  unsigned char note = time_in_song / (unsigned long) LEN_OF_NOTE_MS;
 //   serialport->print("note: ");
 //   serialport->println(note);
  if (note >= NUM_NOTES) {
    note = 0;
    start_of_song = m;
  }
  unsigned char light_lvl = LIGHT_LEVEL[currentLevel][note];
  set_light_level(light_lvl);
  if (!currentlyMuted) {
    unsigned char note_lvl = SONGS[currentLevel][note];
   
 //   serialport->print("note lvl");
 //   serialport->println(note_lvl);

    tone(TONE_PIN, BUZZER_LVL_FREQ_HZ[note_lvl],INF_DURATION);
  } else {
    noTone(TONE_PIN);
  }
}
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

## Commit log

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2022-06-23 Add more parts drawings, buzzer. Add additional schematic sheet for AlarmAudio.
    [AlarmAudio.sch, AlarmLights5.sch, GeneralPurposeAlarmDevicePCB.sch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]
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2022-06-25 Update LCD footprint for 2004A pcb and add STEP file found at Grabcad. Refresh PCB.
    [GeneralPurposeAlarmDevicePCB.kicad_pcb, LCD And I2C Interface.sch]
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2022-07-05 Add more parts including a place holder only for power jack 3D, USB micro is incomplete. Added I2C daisy chain connector.
    [GeneralPurposeAlarmDevicePCB.kicad_pcb, GeneralPurposeAlarmDevicePCB.sch, USB_UART.sch]
2022-07-08 Add current limit to CongtollerVcc, and Barrel Input. Add jumper resistors for headers selecting VBus and ControllerVcc.
    [AlarmAudio.sch, AlarmLights5.sch, GeneralPurposeAlarmDevicePCB.kicad_pcb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]
2022-07-08 Update schottky symbol and part number. Import to PCB. Only the Arduino UNO symbol remains to connect.
    [AlarmAudio.sch, GeneralPurposeAlarmDevicePCB.kicad_pcb, GeneralPurposeAlarmDevicePCB.sch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]
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2022-07-09 Add both UNO and NANO schematic and PCB foot print. Zero schematic errors reported. This incorporates all of the updates from the review except the DO NOT FIX.
    [AlarmAudio.sch, GeneralPurposeAlarmDevicePCB.kicad_pcb, GeneralPurposeAlarmDevicePCB.sch]
2022-07-09 Clean up a bunch of duplicate because of missspelled part field names. Still working on a few sch, pcb and 3D libraries.
    [AlarmAudio.sch, GeneralPurposeAlarmDevicePCB.kicad_pcb, GeneralPurposeAlarmDevicePCB.sch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]
2022-07-11 Still have to make a 3D for buzzer and for USB connector. Still have to make PubInv logo and other Open Source logos. Experimental PCB placement tightned up.
    [AlarmAudio.sch, GeneralPurposeAlarmDevicePCB.kicad_pcb]
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2022-07-12 Remove NANO sheild foot print. Other changes per issue #23 notes of 20220712.
    [AlarmLights5.sch, GeneralPurposeAlarmDevicePCB.kicad_pcb, GeneralPurposeAlarmDevicePCB.sch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]
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2022-07-15 updated buzzer footprint to a generic compatible one
    [AlarmAudio.kicad_sch, GeneralPurposeAlarmDevicePCB.kicad_sch]
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2022-07-18 Update buzzer foot print. Fully connect all parts. Fix numerous silkscreen conflicts. Mix of metric and imperial grid.
    [AlarmAudio.kicad_sch, GeneralPurposeAlarmDevicePCB.kicad_pcb, GeneralPurposeAlarmDevicePCB.kicad_sch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]
2022-07-24 Fix pot foot print, Add fifth mounting hole. Place all but UNO and test point.
    [AlarmAudio.kicad_sch, GeneralPurposeAlarmDevicePCB.kicad_pcb, GeneralPurposeAlarmDevicePCB.kicad_sch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]
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2022-07-24 Fixed library and schematic broken due to POT description including a "/" in symbol name.
    [GeneralPurposeAlarmDevicePCB.kicad_pcb, GeneralPurposeAlarmDevicePCB.kicad_sch, LCD And I2C Interface.kicad_sch]
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2022-07-25 Add an Arduino UNO footprint to the PDB and make a PCB footprint with same.
    [GeneralPurposeAlarmDevicePCB.kicad_pcb]
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2022-07-26 Add 7805 alternative for linear regulator, Add test points on power supply nets, add MechanicalPartsPlacement.pdf.
    [AlarmAudio.kicad_sch, GeneralPurposeAlarmDevicePCB.kicad_pcb, GeneralPurposeAlarmDevicePCB.kicad_sch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]
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2022-07-28 Fix incorrect Q602 emiter collector orientation.
    [AlarmAudio.kicad_sch]
2022-07-28 Make JST footprint for J105 in porject library. Change schematic for JST footprint. Import to PCB. Position at exactly 3200. Update User.Drawing.
    [GeneralPurposeAlarmDevicePCB.kicad_pcb, GeneralPurposeAlarmDevicePCB.kicad_sch]
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2022-07-28 Change TP to show value on F silk screen. Make REF DES smaller.
    [AlarmAudio.kicad_sch, GeneralPurposeAlarmDevicePCB.kicad_pcb, GeneralPurposeAlarmDevicePCB.kicad_sch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]
2022-07-28 Add cost LCD, Add screw, spacer and nut to symbol library. Add screw and nut to schematic.
    [GeneralPurposeAlarmDevicePCB.kicad_sch, LCD And I2C Interface.kicad_sch]
2022-07-28 Add again nuts and spacers to schematic. Fix cost in Symbol library.
    [GeneralPurposeAlarmDevicePCB.kicad_sch, LCD And I2C Interface.kicad_sch]
2022-07-28 Add to schematic, again nuts and spacers to schematic. Fix cost in Symbol library.
    [LCD And I2C Interface.kicad_sch]
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2022-07-29 Update a lot of cost and PNs from JLCPCB and some Digikey.
    [AlarmAudio.kicad_sch, AlarmLights5.kicad_sch, GeneralPurposeAlarmDevicePCB.kicad_sch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]
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2022-07-29 Route some power. Move transistors and resistors near LEDs for signall access.
    [GeneralPurposeAlarmDevicePCB.kicad_pcb, LCD And I2C Interface.kicad_sch, USB_UART.kicad_sch]
2022-07-29 Update crystal footprint for proper SMT. Position compoonents for routing. Add resistor to attenuate audio.
    [AlarmAudio.kicad_sch, GeneralPurposeAlarmDevicePCB.kicad_pcb, GeneralPurposeAlarmDevicePCB.kicad_sch]
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2022-07-30 PCB routed and no DRC errors not waved. One warning about the open hardware on the silk screen.
    [GeneralPurposeAlarmDevicePCB.kicad_pcb]
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2022-08-08 Fix formating for volunteers for readability. Add schematic capture.
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2022-08-10 moved some files around and created a specific directory for manufacturing and part placement
    [GeneralPurposeAlarmDevicePCB.xls]
2022-08-10 moved files around, added manufacturing bom and confirmed they will work with JLCPCB
    [GeneralAlarmDeviceV120220810-BOM_JLCSMT.xlsx, GeneralPurposeAlarmDevicePCB.xls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]
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2022-08-21 added latest openscad rendering, updated openscad case files. resolved issues with orientation and alignment
    [U_Box_V104_General_Alarm_Device.scad]
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2022-09-07 updated GPAD factory test firmware with correct i2c address added stl of case
    [GPAD_Factory_Test.ino]
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2022-09-22 Add version report on serial output and LCD. Change for BUZZER_TEST_FREQ - 4000 KHz
    [GPAD_Factory_Test.ino]
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2022-09-24 Update ManufacturingUnitTestTroubleshooting.md
    Add notes on audio testing at 4KHz on piezo buzzer and at 1KHz and 130 Hz on a moving coil speaker.
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2022-09-29 fixed alignment of lettering and floating pcb mounts
    [U_Box_V104_General_Alarm_Device.scad, U_Box_V104_General_Alarm_Device.stl, U_Box_V104_General_Alarm_Device_FrontPanel.stl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]
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2022-10-19 Update GPAD_Factory_Test.ino
    Fix NOVEL spelling.
    [GPAD_Factory_Test.ino]
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2022-10-27 Update README.md
    Fix display of images of SCH, PCB and 3D board.
    Add # Theory of Operation
    Some spelling check.
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2022-10-28 Add a serial event handeler. Still not working though.
    [ProcessClientCommands.pde, SerialEvent.pde, UserInput.pde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]
2022-10-29 Update to flush out most of the user interface and functionality. Mute and unmute may be inverted.;
    [LoggingToFile.pde, UserInput.pde, pseudoSerialVent.pde]
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2022-11-02 Update GPAD_API_Regression_Test_Plan.md
    Update to detail LED and Buzzer rest results.
2022-11-03 Add time duration for DUT response. Fix mute message polarity. Streamline Userinput testing and printing. Change background during command processing.
    [SerialEvent.pde, UserInput.pde, pseudoSerialVent.pde]
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2022-11-09 general-alarm-device README.md minor corrections
2022-11-10 optimised I2C scan error handling
    [GPAD_Factory_Test.ino]
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2022-11-11 Changing serial timeout, improving printing of short messages
    [GPAD_API.ino]
2022-11-12 refactored test functions for mute switch, LEDs, and buzzer
    [GPAD_Factory_Test.ino]
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2022-11-13 Add 3D model for JST connector. Model simple rectangle made in FreeCAD.
    [Cube.step, S04B-XASK-1.FCStd]
2022-11-13 Add the changed PCB and pretty files with the 3D model for JST connector.
    [GeneralPurposeAlarmDevicePCB.kicad_pcb]
2022-11-13 Fixing paths to library. The previous commit may have had a path to Lees local clone.
    [GeneralPurposeAlarmDevicePCB.kicad_pcb]
2022-11-13 Add a PDF of the updated schematic reflecting rework for D7 and D10 and the Reset to nRTS.
2022-11-13 Update schematic for rework of Version 1 PCB for D7 and D10 and Reset to nRTS.
    [AlarmAudio.kicad_sch, AlarmLights5.kicad_sch, GeneralPurposeAlarmDevicePCB.kicad_pcb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]
2022-11-13 Update README.md
    Fix URL to schematic PDF file.
2022-11-13 Update PCB for version 2. Update enclosure drawing to reflect the V1 enclosure assembly.
    [AlarmAudio.kicad_sch, AlarmLights5.kicad_sch, General Alarm Device Enclosure.FCStd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]
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2022-11-13 Put BUILTIN LED and resistor back on D13. Add new LED and resistor for Wink on A3.
    [GeneralPurposeAlarmDevicePCB.kicad_pcb, GeneralPurposeAlarmDevicePCB.kicad_sch]
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2022-11-17 revised testing of buzzer
    [GPAD_Factory_Test.ino]
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2022-11-25 Increase size on power traces and vias. Move and edit model number text.
    [PolyVent_SPI_Controller.kicad_pcb, PolyVent_SPI_Controller.kicad_sch]
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2022-11-25 Update the README.md for the project with current screen shots and add step file.
    [PolyVent_SPI_Controller.step]
2022-11-25 Update the Schematic and BOM for FET level shift. Make some parts DNI.
    [I2C_Level_Shifter.kicad_sch, PolyVent_SPI_Controller.kicad_pcb, PolyVent_SPI_Controller.kicad_sch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]
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2022-11-28 Add JLCPCB place holder text to GPAD and PV_SPI_Conteroller. Create spead sheet for managing JLCPCB pick and place requirements.
    [GeneralPurposeAlarmDevicePCB.kicad_pcb, PolyVent_SPI_Controller.kicad_pcb, PolyVent_SPI_Controller_PickNPlace.xls]
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2022-12-13 Make Faceplate for PolyVent_SPI_Controller. Add 3D models to PCB to improve the PCB 3D model especially for connectors.
    [KiCadLibrary.kicad_pcb, KiCadLibrary.kicad_sch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]
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2023-01-24 Update ManufacturingUnitTestTroubleshooting.md
    Update correct images for WINK_LED rework. The old images put the LED on the wrong net (SCL) causing the SPI bus to mal function.
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2023-02-21 Make new schematic symbol and PCB symbol to correct pin numbers on JST connector. Generate new gerbers and drills.
    [GeneralPurposeAlarmDevicePCB-B_Cu.gbr, GeneralPurposeAlarmDevicePCB-B_Fab.gbr, GeneralPurposeAlarmDevicePCB-B_Mask.gbr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]
2023-02-21 Change UNO placement, change silkscreen. Update Gerbers and drills and STEP models.
    [GeneralPurposeAlarmDevicePCB-B_Cu.gbr, GeneralPurposeAlarmDevicePCB-B_Fab.gbr, GeneralPurposeAlarmDevicePCB-B_Mask.gbr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]
2023-02-27 Initial commit of buzzerControl not yet working.
    [buzzerControl.ino]
2023-02-28 Schematic symbol and library part Adafruit buzzer. Change schematic buzzer circuit to switch Adafruit buzzer.
    [AlarmAudio.kicad_sch, GeneralPurposeAlarmDevicePCB.kicad_sch, LCD And I2C Interface.kicad_sch]
2023-02-28 PCB footrpint to library Adafruit buzzer.
2023-02-28 Add Adafruit buzzer to PCB. DRC no errors. Trivial warnings.
    [AlarmAudio.kicad_sch, GeneralPurposeAlarmDevicePCB.kicad_pcb, GeneralPurposeAlarmDevicePCB.kicad_sch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]
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2023-03-01 Update U301 for JLCPCB in stock, Break and then fix SCH library because of illigal character in sch symbol name.
    [AlarmAudio.kicad_sch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]
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2023-03-01 Update BOM and placement files after fixing U301.
    [BOM_JLCPCB_20230228.xls, GPAD_V2_BOM.xls, GeneralPurposeAlarmDevicePCB-Placement20230228.xls]
2023-03-02 Updated LED diameter to 5mm, added in standoff STL files for the LED's
    [U_Box_V104_General_Alarm_Device.scad, U_Box_V104_General_Alarm_Device_Backpanel.stl, U_Box_V104_General_Alarm_Device_FrontPanel.stl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]
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2023-03-03 Rename file U_Box_V104_GPAD_LED_Standoff_single.stl because JLCPCB required shorter file name.
    [U_Box_V104_GPAD_LED_Standoff_single.stl]
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2023-03-08 Update README.md
    Fix brackets to fix link in mark down.
2023-03-09 Found and fixed gap on BackPanel_Hanging_Compound. Made version 2.
    [BackPanel_Hanging-CompoundV2.stl, BackPanel_Hanging.FCStd]
2023-03-09 Update README.md
    Update to file: BackPanel_Hanging-CompoundV2.stl which fixes a very small gap that was in the previous file.
    See issue: Fix Gap Between Features on #207
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2023-04-25 Update README.md
    Fix URL to schematic Rev 2.
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2023-05-10 Update README.md
    Fix file name error. Change from: U_Box_V105_General_Alarm_Device_button.stl
    To:
    U_Box_V104_General_Alarm_Device_button.stl
2023-05-17 Update ManufacturingUnitTestTroubleshootingRev2.md
    Link to issue with Additional Measurements of current with in subcircuits
2023-05-17 Update schematic with note on additional vendor information on buzzer.
    [AlarmAudio.kicad_sch]
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2023-06-20 Update README.md
    fixed the link for
    https://github.com/PubInv/general-purpose-alarm-device/blob/main/Hardware/Documentation/ManufacturingUnitTestTroubleshootingRev2.md
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2023-06-20 Delete BackPanel_Hanging.stl
    File has error. Could not be fabricated.
    [BackPanel_Hanging.stl]
2023-06-20 Delete BackPanel_Hanging.step
    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
    [BackPanel_Hanging.step]
2023-06-20 Delete BackPanel_Hanging-HangingEars.stl
    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
    [BackPanel_Hanging-HangingEars.stl]
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2023-07-27 Update ManufacturingUnitTestTroubleshootingRev2.md
    Add:
    ### Rework per issue #213, Remove R103
    GPAD Rev 2.0 PCB, Remove the Resistor R103 (Loads the Peripheral Select), Update Factory Test for D601. #213
    **Problem:**
    The assemblies built per the BOM_JLCPCB_20230228Modified.xls have R103 fitted with a 1K resistor. This resistor with the LED D102 loads the SPI_CLK signal and is incompatible with proper opperation of the GPAD as an SPI Peripherial from a 3.3V SPI Controller using the level shifting method using the common gate MOSFET.
    ![image](https://github.com/PubInv/general-purpose-alarm-device/assets/5836181/49fd13c8-6389-4675-8db7-66171a67e4b2)
    **Solution:**
    Remove R103.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
2023-08-01 Fix bad hex nut due to "/" in part name.
2023-08-01 Fix schematic broken by the "/" in the hex nut.
    [GeneralPurposeAlarmDevicePCB.kicad_sch, LCD And I2C Interface.kicad_sch]
2023-10-22 Update the part number for the buzzer to a DigiKey part. This schematic is now saved in KiCAD 7.
    [AlarmAudio.kicad_sch, AlarmLights5.kicad_sch, GPAD_V2_BOM.xls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]
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2023-10-24 added reference to sources for the OpenSCAD enclosure project, per issue #245
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2023-10-31 Update ManufacturingUnitTestTroubleshootingRev2.md
    Add missing image of fixture with LCD, AssemblyFixtureView2.jpg
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2025-01-19 SpeakerBaffel150x90.FCStd Correct retainer magnet diameter.
    [SpeakerBaffel150x90.FCStd]
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
